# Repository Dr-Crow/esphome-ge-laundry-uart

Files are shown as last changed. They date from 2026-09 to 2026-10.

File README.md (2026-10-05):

# ESPHome GE Laundry UART

Local Home Assistant control and monitoring for compatible GE appliances through ESPHome and the appliance's GEA serial bus.

> [!WARNING]
> The appliance uses an 8P8C modular connector that looks like Ethernet, but it is **not Ethernet**. Do not connect it to network equipment.

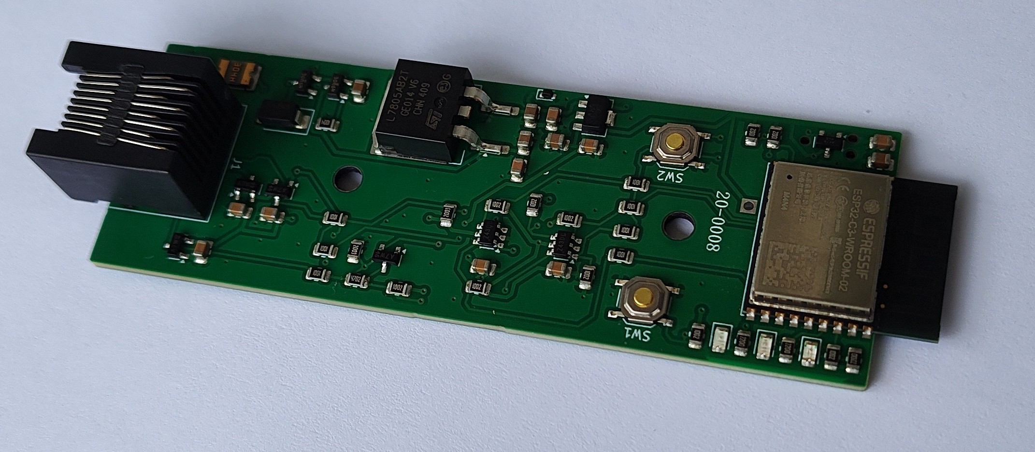
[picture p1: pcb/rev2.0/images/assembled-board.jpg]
Assembled Rev 2-era adapter


The project began as an effort to integrate a GE washer and dryer with Home Assistant. An ESP32 powered by the appliance communication port reports information such as remaining time and cycle completion through ESPHome. Early work involved researching the GEA2 and GEA3 protocols and the U+ Connect module; later, [GE Appliances](https://github.com/geappliances) and [FirstBuild](https://firstbuild.com/inventions/home-assistant-adapter/) published additional hardware and protocol information. The maintained ESPHome implementation now lives in [mguaylam/esphome-gea](https://github.com/mguaylam/esphome-gea), while this repository provides compatible hardware, reference configurations, manufacturing files, and enclosures.

## Getting started

### I already have a board

Follow the [firmware setup guide](firmware/README.md) to choose a GEA2 or GEA3 configuration, flash the board, connect it to Home Assistant, and check the status LEDs. The [Rev 2 enclosure](case/rev2/README.md) includes ready-to-print files.

### I want to review a new board

The selected development focus is the socketed C3/C6 Rev3C with both appliance inputs, automatic priority and rated protection. This integration includes all seven editable board revisions, eight firmware profiles, native validation and the [illustrated Rev3C ordering guide](pcb/rev3c/ORDERING.md). Start with the [current comparison and validation](docs/revision-comparison/README.md), [exact source handoff](docs/revision-comparison/HANDOFF.md) and [finish registry](docs/revision-comparison/FINISH-PLAN.md).

Fresh pinned KiCad 9.0.9 ERC/DRC and intended-rule checks pass for all seven revisions. The [Rev3C stencil correction](pcb/rev3c/STENCIL-REVIEW.md) removes unintended drill-marker openings. Native/CAM agreement is separate from supplier process, appliance power and physical qualification. The corrected Rev3C trio has refreshed October 5 quotes of $134.64 for five or $168.92 for ten assembled carriers, before shipping, tax and XIAO modules; Rev2.2's old $78.07 quote is historical.

Older boards and the complete change history are listed in the [PCB revision index](pcb/README.md). Hardware contributors should also read the [contribution guide](CONTRIBUTING.md).

For the proposed USB-C revisions, see the [board and enclosure comparison](docs/revision-comparison/README.md), including assembled-board estimates and views from several angles. The [project handoff](docs/revision-comparison/HANDOFF.md) records the development branches and remaining work.

## Related projects

- [GE Appliances organization](https://github.com/geappliances)
- [FirstBuild Home Assistant adapter](https://firstbuild.com/inventions/home-assistant-adapter/)
- [puddly/casserole](https://github.com/puddly/casserole)
- [GEMakers/green-bean](https://github.com/GEMakers/green-bean)
- [doitaljosh/gea-interface-board](https://github.com/doitaljosh/gea-interface-board)
- [doitaljosh/ge-appliances-re](https://github.com/doitaljosh/ge-appliances-re)
- [doitaljosh/geabus-documentation](https://github.com/doitaljosh/geabus-documentation)
- [simbaja/gehome](https://github.com/simbaja/gehome)
- [GE Appliances Home Assistant adapter](https://github.com/geappliances/home-assistant-adapter)
- [GE Appliances Home Assistant examples](https://github.com/geappliances/home-assistant-examples)
- [GE Appliances Home Assistant bridge](https://github.com/geappliances/home-assistant-bridge)

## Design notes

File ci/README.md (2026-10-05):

# Native validation and release gates

This integrated review covers all seven actual board folders (`rev1.0`, `rev2.0`,
`rev2.1`, `rev2.2`, `rev3a`, `rev3b`, `rev3c`) and all eight standalone firmware
profiles. It combines genuine final component histories in a new integration;
it does not reconstruct the omitted original integration commit or its ancestry.
The CI implementation builds on universal candidate
`0d3358af4e732a6e6f5e895d5942ebd1647c79e2`.

```sh
python3 -m unittest discover -s ci -p 'test_*.py'
python3 ci/validate.py inventory
python3 ci/validate.py inventory --revision firmware
python3 ci/validate.py hardware
python3 ci/validate.py manufacturing
python3 ci/validate.py rules
python3 ci/validate.py release
python3 ci/validate.py firmware
```

Use genuine KiCad **9.0.9**, its official pinned libraries and ESPHome
**2026.9.1**. CircleCI pins executable/container versions and registry manifest
digests. Reports and logs go to `ci-artifacts/` and remain available when checks
fail. No command flashes hardware, places orders or publishes a release.

## What each check establishes

- Inventory requires every actual revision directory in the manifest. It records
  native CAD, available factory-file hashes and the complete local source closure
  even when supplier assembly inputs are absent. Every declared firmware profile
  must exist, be unique and have a complete local YAML/include closure; private
  secrets are excluded. A regression also requires every standalone YAML profile
  to be declared; included package files are dependencies, not build targets.
- One canonical checkout-relative design identity includes native CAD/rules,
  project tables, child schematics, local symbol/footprint libraries and every
  referenced local STEP/WRL model. Native, CAM, placement and release checks bind
  to this same closure. Required dependencies must exist; edits or deletions
  invalidate previous evidence. Equal basenames in different folders remain
  distinct. Stock references and official library/model commits are pinned
  separately, without substituting arbitrary system files into source hashes.
- Hardware uses an isolated dependency copy so native project migration cannot
  rewrite committed source. ERC/DRC include all severities; DRC includes all-track
  errors and schematic parity. Every nonzero exit, including violation exit 5,
  fails. Missing tools/reports and infrastructure errors fail too. After both
  strict checks pass, the same isolated copy produces `review/schematic.pdf`
  (all sheets), `review/board-top.svg` (F.Cu, F.SilkS, Edge.Cuts) and
  `review/board-bottom-mirrored.svg` (B.Cu, B.SilkS, Edge.Cuts, mirrored).
  `review-exports.json` binds every fresh file's SHA-256 and byte count to the
  complete current source identity and the actual pinned native version. A
  nonzero export, missing/empty file, malformed SVG or wrong-kind/incomplete
  output fails as a review-export infrastructure/output problem even when
  ERC/DRC pass. Reruns remove older review outputs first. These are native 2D
  review views; they do not approve populated 3D geometry, mechanics or release.
  The flags follow the official [KiCad 9 CLI reference](https://docs.kicad.org/9.0/en/cli/cli.html).
- Manufacturing first requires the declared `fabrication_plot` policy to be
  exactly `{"drillshape": 0}` and the native board setting to be 0. Drill markers
  can create positive stencil apertures even when CAM perfectly matches source.
  The native regression regenerates source-matched Rev3C CAM with drillshape 1,
  confirms its unintended 0.35 mm circular paste apertures and successful parity,
  then requires the fabrication guard to reject it.
- Gerber/drill/job content must match native regeneration, removing only creation
  timestamps. CAM identity remains separate from missing supplier assembly data.
  BOM references, values, footprints and purchasing fields must match native
  schematic metadata. CPL coordinates, rotations and sides must match native
  placements or the specific committed, hash-matched centroid policy.
- Manufacturing also checks every supplier-BOM R/C/L reference against the
  independently reviewed primary catalog facts in `passive-catalog.json`.
  Nominal values, declared footprint package identities and available exact MPNs
  must agree; explicitly declared capacitor voltage/dielectric must match in both
  BOM fields/value text and native schematic fields/value text. Unknown passive
  codes fail and need an independently sourced catalog update. Regressions reject
  the legacy 220k/C17539 (200k) and 4K7/C17713 (47k) conflicts even when BOM and
  source agree. All five declared supplier BOMs are covered; the two legacy boards
  without current supplier BOMs retain their existing missing-input failures.
  The report binds the catalog hash. This check does not establish supplier stock,
  land-pattern compatibility, DC bias, transient or thermal qualification.
  Semiconductor and module identities remain outside this bounded passive check.
- The current centroid policies cover Rev2.1's legacy pad-bounds convention,
  Rev3A/Rev3B's typed manufacturer/module body datums and Rev3C's typed nominal
  J1 manufacturer body datum. Complete source closure, documentary hashes,
  native part/footprint identity, anchor, rotation, side and local/export geometry
  must match. Stale, missing, unknown or substituted evidence fails. Angles have
  no override. These are geometric conventions, not supplier process approval.
- Rules audit exactly the declared native net names, their explicit memberships
  and intended clearances. Exact sheet-leading slashes matter. Native KiCad 9
  patterns and Rev1's retained explicit legacy class `nets` are both supported;
  automatic/default class selection is not treated as explicit assignment.
  Rev3B/C's unused inherited USB patterns are retained in source; they are not
  claimed as live audited nets. Native DRC and this bounded audit remain separate.
- Firmware requires both `esphome config` and `esphome compile` for each profile,
  using synthetic credentials in a temporary copy. Results bind profile/include
  hashes. A compile requires a fresh binary; config-only, missing dependencies and
  network/tool failures stay red. The exact local ESPHome environment is
  unavailable. Hosted job 47 completed fresh config and compilation for all
  **eight profiles** at published source `2d5a42c`; the
  [hosted receipt](validation/hosted-2d5a42c/REVIEW.json) binds all 22 declared
  input hashes and records 24 factory/OTA/ELF outputs. Test credentials were
  synthetic; no device was flashed or functionally qualified.
- Release requires separate power, source and physical qualification evidence
  for every board: **all 21 gates remain explicitly blocked**. Passed evidence
  must be committed at HEAD, hash-matched, bound to the complete current source
  closure and match external pins. A native/CAM/firmware pass cannot waive gates.

## Explicit unresolved inputs and qualification

Rev1.0 and Rev2.0 now have restored editable historical CAD and current review CAM.
Their original archives remain separately declared as `historical_archive`.
Rev1's original supplier BOM/CPL are absent; Rev2's historical supplier tables and
rotations do not establish a current qualified assembly package. Their inventory
and assembly checks remain red while independently source-matched CAM can pass.
No purchasing data, original archive/source pairing or supplier orientation
approval is invented.

Legacy supply/protection/supervisor and exact module/buck/regulator identities,
supplier library pose/rotation, purchasing identities and physical qualification
remain open. Current Rev2.1/Rev2.2 source and factory files are the reviewed cleaned
packages; historical copies remain separate. Corrected native source does not
close the known Rev2.1 supervisor risk or establish appliance compatibility.

Rev3A/B/C retain the reviewed rated-switch circuits and current source packages.
Exact RJ45 suffix and other purchasing identities, whole-chain transient and
thermal behavior, loaded startup, source capacity, supplier process, antenna/RF,
assembly and enclosure qualification remain open. Rev3C has no default shared
C3/C6 case CAD and no completed physical qualification.

## Verification boundaries

The prior [validator/workflow receipt](validation/VALIDATOR-WORKFLOW-REVIEW.json)
is frozen evidence for the universal four-board/two-profile candidate's bytes and
its October 4 CircleCI schema validation. It does not certify this extended driver,
manifest or its fresh hosted execution. The integrated local review is recorded
separately after the exact final files are checked. CircleCI accepted the current
configuration through its schema validator on October 4; the
[schema receipt](validation/INTEGRATED-CIRCLECI-SCHEMA.json) binds the CLI and
configuration hashes. Hosted native, intended-rule, validator-test and firmware jobs succeeded on
`2d5a42c`. Inventory/manufacturing correctly fail on the two legacy supplier
packages, and all 21 release gates remain blocked. The
[hosted receipt](validation/hosted-2d5a42c/REVIEW.json) separates these results
from physical qualification and the earlier local review.

Do not turn failures green by ignoring native exit codes, lowering rules,
omitting intended coverage, inventing assembly data or removing gates. Add a real
source dependency or tool version deliberately and regenerate affected evidence.
Official references: [KiCad containers](https://www.kicad.org/download/docker/)
and [CircleCI CLI](https://circleci.com/docs/guides/toolkit/circleci-cli/).

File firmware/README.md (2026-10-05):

# Firmware profiles and board service

Choose the profile family for the actual board. [Shared profiles](shared-rev3c/README.md) cover socketed Rev3C C3/C6 and the compatible soldered Rev3B C3 interface; [classic Rev1 profiles](rev1-classic/README.md) cover its distinct ESP32 wiring. The two root reference configurations cover Rev2.x and the compatible Rev3A C3 interface. The [per-board coverage review](BOARD-COVERAGE.md) proves these mappings separately from compilation. All eight profiles compiled in hosted jobs [69 at11826a7](https://circleci.com/gh/Dr-Crow/esphome-ge-laundry-uart/69) and [81 at8744a29](https://circleci.com/gh/Dr-Crow/esphome-ge-laundry-uart/81). The committed detailed binary-hash receipt remains bound to earlier2d5a42c; it is not relabeled as a later build. Runtime/appliance behavior remains untested.

## Rev2.x reference setup

These examples use the maintained [ESPHome GEA component](https://github.com/mguaylam/esphome-gea) and are software references for the historical Rev 2.x interface. They do not establish board power or appliance qualification.

[Back to the project overview](../README.md) · [PCB Rev 2.2 reference](../pcb/rev2.2/README.md) · [Revision history](../pcb/README.md)

## Choose a configuration

| Configuration | Connection | Typical use |
| --- | --- | --- |
| [`gea2.yaml`](gea2.yaml) | GPIO5 TX and GPIO10 RX, inverted, 19,200 baud | Rev 2.x reference for GEA2 appliances. |
| [`gea3.yaml`](gea3.yaml) | GPIO21 TX and GPIO20 RX, non-inverted, 230,400 baud | Rev 2.x reference for GEA3 appliances. |

The appliance model determines whether it uses GEA2 or GEA3. Establish that protocol and its electrical interface for the exact appliance before selecting a profile. Do not connect an unqualified board to an appliance to try configurations.

## Prepare ESPHome

If ESPHome is not installed yet, start with the official [ESPHome installation guide](https://esphome.io/install/) and [getting-started guide](https://esphome.io/install/getting-started/).

1. Copy the matching YAML file into your ESPHome configuration directory.
2. Change the `name` and `upper_name` substitutions near the top of the file.
3. Add these values to the `secrets.yaml` file in the same directory:

```yaml
wifi_ssid: "..."
wifi_password: "..."
esp_home_ota_pw: "..."
```

You can use the ESPHome Device Builder or the command line. The examples are starting points, so appliance-specific entities may need to be added or changed.

## Reproduce the reference build

The reference profiles pin ESP-IDF **5.5.5** and the GEA component to commit
`283ff2b0dfe90a6d14a5417a23176d433be8a5b3`. CI uses ESPHome **2026.9.1** and
runs actual compilation for both profiles. To run those checks locally with the
same ESPHome version, use `python3 ci/validate.py firmware` from the repository
root. The driver uses temporary dummy credentials and never flashes a device.

These build checks establish software compilation only. Match the board and
appliance configuration and complete physical qualification before use.

## First flash

Rev 2.x boards do not have USB. Programming uses a **3.3 V logic** USB-to-UART adapter connected to the unpopulated J2 holes or J3 Tag-Connect pads. Keep the UART adapter's VCC/power lead disconnected; do not apply 5 V logic to RX/TX or the control pins.

J2 pin 1 and J3 pin 2 are the board's **+3V3 rail on the regulator output**, not approved programming-power inputs. Do not feed either contact from the UART adapter or an external 3.3 V supply. Driving a regulator output while its input is absent can reverse-feed the regulator and other board rails.

| J2 pin | Board signal | Connect to |
| --- | --- | --- |
| 1, square pad | +3V3 regulator output rail | Leave disconnected; UART adapter VCC stays disconnected |
| 2 | Ground | Adapter ground, once a reviewed board-power arrangement exists |
| 3 | Boot | Ground only while entering the bootloader |
| 4 | Board RX / GPIO20 | Adapter TX, 3.3 V logic |
| 5 | Board TX / GPIO21 | Adapter RX, 3.3 V logic |
| 6 | Enable | Optional reset control |

TX/RX in this table means the adapter/ESP perspective: the native Rev 2.x netlist places J2.4 on U2 IO20/RXD and J2.5 on U2 IO21/TXD. Historical net names and printed labels can use a different perspective; confirm the exact schematic and revision before wiring.

Use only a **single reviewed board-input supply and power/reset procedure** matched to that exact schematic, revision and fitted regulator/protection parts. No approved supply voltage range, source, current limit or bench procedure is established by this guide. Do not combine appliance power with a programmer supply, and do not connect to an appliance before electrical and physical qualification.

This corrects the output-rail power advice in the historical guide at public-main commit `bc0d524` and the original Rev 2-era instructions. It changes documentation only; the circuit and its open qualification gates remain unchanged.

After that power arrangement and the serial logic/interface have been reviewed:

1. Connect J2 Boot to Ground.
2. With Boot held low, follow the reviewed board-input power/reset procedure for this exact revision to enter the serial bootloader. Keep UART adapter VCC disconnected and leave the +3V3 service contacts disconnected from external power.
3. In ESPHome Device Builder, choose **Install** and select the serial adapter. With the command line, run:

   ```console
   esphome run your-config.yaml --device /dev/cu.your-usb-serial-device
   ```

4. When the upload finishes, disconnect Boot from Ground and restart using the same reviewed power/reset procedure.

Later updates can be installed over Wi-Fi from ESPHome Device Builder. From the command line, run the same `esphome run` command and choose the network device when prompted.

## Before connecting to an appliance

Complete electrical/source, startup/current, regulator/protection/thermal, serial-level and connector/enclosure qualification for the exact board and appliance first. The native checks and firmware builds do not supply that evidence. After qualification, disconnect the programming adapter before connecting the board to the appliance service port. This connector is not Ethernet.

With the supplied configurations, the green LED follows Wi-Fi connection and the yellow LED follows the GEA component's `is_bus_connected()` state, checked once per second. Yellow is a connected-state indicator, not a per-message activity indicator. The red LED is initialized off at boot and has no ongoing status assignment in these examples.

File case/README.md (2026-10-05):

# Enclosures

Enclosure files are grouped by the PCB family they were designed to fit.

[Back to the project overview](../README.md)

| Enclosure | Intended hardware | Status |
| --- | --- | --- |
| [Rev 2 enclosure](rev2/README.md) | Rev 2.x board outline | Existing printable design; Rev 2.2 fit still requires a physical check. |
| [Shared Rev3C review prototype](rev3c/README.md) | Socketed C3/C6 Rev3C | Editable all-printed source recovered; current component envelopes, actuator calibration, printing and physical fit remain unqualified. |

The editable CAD source, printable files, and documentation images are kept separately. The final check is printing the enclosure and test-fitting an assembled board.

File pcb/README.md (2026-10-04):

# PCB revisions

This directory keeps every board revision in a separate package so source files, manufacturing files, and review files do not get mixed between revisions.

[Back to the project overview](../README.md) · [PCB ordering guide](ORDERING.md)

> [!IMPORTANT]
> Every revision needs its own source, electrical, assembly and physical qualification before a new build. Rev2.2 retains unresolved regulator/current and protection limits; it is not a released fallback. Older packages remain for review and project history.

## What the folders mean

- `design/` contains the editable KiCad project. A `.pretty` directory under `footprints/` is a KiCad footprint library: it defines the exact copper pads, drill holes, silkscreen, and component outline used on the board. A project `fp-lib-table` maps the library name used by the board to that local directory so footprints resolve from a clean clone. A `models/` directory, when present, contains optional 3D component shapes.
- `manufacturing/` contains files sent to a PCB assembler. Gerbers describe copper, holes, solder mask, and silkscreen; the BOM lists components; the CPL lists component positions and rotations.
- `validation/` contains files used to review the design, such as schematic PDFs, board views, drill maps, and ERC/DRC reports.
- `images/` contains photographs and explanatory renders used by documentation. Images are not manufacturing inputs.

## Revision index

| Revision | Status | Available material |
| --- | --- | --- |
| [Rev 3C](rev3c/README.md) | Selected socketed C3/C6 prototype; qualification open | Rated dual-input source, four firmware profiles, corrected stencils, factory trio, partial component previews and illustrated ordering guide. |
| [Rev 3B](rev3b/README.md) | Rated soldered-C3 alternative; qualification open | Native source, matched factory package, typed placement evidence and partial C3 previews; exact module stock remains a gate. |
| [Rev 3A](rev3a/README.md) | Rated integrated-C3 alternative; qualification open | Native source, matched factory package, reviewed USB shell slots/lands and placement evidence; assembler solder/retention review remains open. |
| [Rev 2.2](rev2.2/README.md) | Historical candidate; qualification open | Corrected KiCad source, matched factory package, and validation exports. |
| [Rev 2.1](rev2.1/README.md) | Historical; superseded; qualification open | Corrected KiCad source, source-bound supplier files, drill maps and explicit placement conventions. |
| [Rev 2.0](rev2.0/README.md) | Historical; qualification open | Restored editable source, regenerated current CAM and preserved original PCBA archive; current supplier BOM/CPL and rotations remain unqualified. |
| [Rev 1.0](rev1.0/README.md) | Historical; qualification open | Restored editable source, regenerated current CAM and preserved original Gerber archive; original purchasing/module/buck identity remains missing. |

> [!IMPORTANT]
> Historical RX/TX labels use an endpoint perspective; verify the exact ESP GPIO-to-adapter direction rather than inferring a hardware swap. The U1 supervisor has reported boot-loop issues on Rev2.1. Historical manufacturing packages are not qualified corrected sources.

Rev 2.2 addresses those known board-file problems but is not proven until assembled boards pass electrical, appliance, and enclosure testing. Keep the three matched files together for review; qualification and exact supplier process approval are still required before ordering.

All seven revisions have fresh full-severity native ERC/DRC and intended-rule checks with no findings. Source/CAM parity passes for all seven; complete source-bound BOM/CPL checks pass Rev2.1/2.2/3A/3B/3C. Rev1/Rev2's missing current supplier inputs remain explicit CI failures. All release gates remain open. See [validation](../docs/revision-comparison/VALIDATION.md) and the [finish plan](../docs/revision-comparison/FINISH-PLAN.md).

## Historical revisions

- Rev 0.1 had unconnected grounds discovered after ordering.
- Rev 0.2 corrected the grounds but needed a diode orientation bodge and resistor changes.
- Rev 0.3 added test points, an LED, a push button, and protection diodes; three boards were tested.
- Rev 1.0 added configurable resistors for inverted GEA2 serial signaling.
- Rev 2.0 introduced an assembly-oriented ESP32-C3 design.
- Rev 2.1 updated that design and migrated its source to KiCad 9.

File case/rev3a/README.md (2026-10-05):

# Rev3A enclosure review

The editable Rev3A enclosure and optional captive-button source remain preserved at [original source a5a9fac](https://github.com/Dr-Crow/esphome-ge-laundry-uart/tree/a5a9fac87cbcb59d337a1fb8d3084ad18867a3e6/case/rev3a). Their physical geometry is unchanged. The [current A/B source review](review/REV3AB-ENCLOSURE-SOURCE-REVIEW.md) binds their interfaces to rated-board checkpoint bf5c231, with exact recovery and geometry receipts. This companion is a review prototype, not a physically qualified case.

## Correct USB opening dimensions

J4 is at carrier (72, 36.325), opening toward +Y. The source cutter spans **X64.5–79.5, Y39–46 and Z2–6.4 mm**. Its outward-facing X/Z opening is **15 mm wide × 4.4 mm high**; **7 mm is the cutter depth through Y**. The closed lid does not enlarge that opening. The original guide's “15 × 7 mm cable window” conflated these axes; use the corrected facing dimensions here.

The selected connector is SHOU HAN TYPE-C 16PIN 2MD(073)/C2765186. Exact mating-axis Z above the assembled 1.6 mm PCB, shell seating and the chosen seated plug remain unresolved. The retained locally named STEP internally identifies a six-pin model, so its height is not exact sixteen-pin mating evidence. The [documentation-only source patch](review/rev3a-usb-documentation-only.patch) records the correction; no opening resize is adopted from that generic model.

## Current applicability and limits

The carrier is **88.7 × 40 × 1.6 mm**. Mounting holes, J1/J2/J4, WROOM, switches and LEDs retain the source-case anchors. Default base/lid STEP/STL readback passes under the recorded pinned CAD environment. Current STPS140Z, TPS1H200A and fuse package screens clear the roofs at nominal seating; those are dimensional screens, not thermal or complete populated-assembly approval.

J1's exact full suffix, body-seat/tail datum, solder protrusion and cable/latch sweep remain to be authenticated. A conditional 0.15 mm tail/floor conflict depends on the retained 3 mm tail datum being measured from PCB top; live drawing retrieval did not reverify that assumption, so no pocket resize is adopted. J4 solder delivery/inspection/retention, switch make/force/overtravel, printing/fatigue, light visibility and RF/thermal behavior remain open.

J2 uses a programmer with 3.3 V logic; **leave UART VCC disconnected** and use one reviewed input supply. The enclosure does not qualify simultaneous USB/appliance power. Match the actual populated board and all qualified dimensions before choosing or printing a production case. Orders and powered testing require their separate review.

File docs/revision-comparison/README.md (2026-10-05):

# Board and enclosure comparison

Latest October 5 pre-order analysis and committed fixes: [all-revision review](preorder-2026-10-05/README.md). The current Rev3 refinement uses STPS140Z input OR diodes across A/B/C and maximum-body socket/case screens. Fresh current-ST C quotes are $135.81/five or $171.20/ten; the older tables and galleries below retain their historical source boundaries.

[Project overview](../../README.md) · [Current validation](VALIDATION.md) · [Pricing](PRICING.md) · [Finish plan](FINISH-PLAN.md) · [Source handoff](HANDOFF.md) · [C3/C6 and Matter](C6-MATTER.md)

Updated October 4, 2026 after source restoration and fresh seven-revision native/CAM checks. The user selected the shared Rev3C design with two **40 V-rated TPS1H200A switches**, both GE power inputs and automatic PIN1 priority. Current selected source is `b87d3e8`, adding the reviewed stencil correction to restored `5542734`; its BOM/CPL remain placement-corrected `b53cfca`, while its Gerber ZIP is regenerated. The original electrical protection source is `7bb455f`. Selection does not establish a 40 V carrier rating, appliance compatibility or manufacturing readiness.

C3 is the first target, with C6 interface and firmware flexibility retained. Rev3A/B backports are digitally reviewed at 97/85 fitted references; Rev3A rated protection, exact connector lands and zero-warning schematic normalization are independently reviewed and staged; all seven revisions now have zero native findings. Current-main-based per-revision candidates are staged locally. Older revisions retain their distinct architectures and review gates. No revision has physical qualification, and older boards are not established safe fallbacks.

## Architecture and current role

| Revision | Processor and service | Power architecture | Current role |
| --- | --- | --- | --- |
| Rev1.0 | Generic 38-pin classic ESP32 interface; original nodemcu-32s target | PIN1 only; external buck through J1 | Restored historical CAD and two new classic profiles; exact purchased module and external supply unknown |
| Rev2.0 | ESP32-C3-WROOM-02; UART programmer | Manual dual-input selector, linear 5 V and 3V3 regulators | Restored source; legacy protection, regulator and physical gates remain |
| Rev2.1 / Rev2.2 | ESP32-C3-WROOM-02; UART programmer | Manual dual-input selector, linear regulators | Native cleanup passes; 60 / 59 fitted references; source-specific placement review remains |
| Rev3A | Integrated C3 and built-in antenna; carrier USB-C/recovery controls | Automatic dual input and buck; separate USB/appliance paths | Rated backport and zero-finding native checks complete;97 refs, exact current quote; source/process/physical gates open |
| Rev3B | Soldered XIAO C3; module USB-C/external antenna | Automatic dual input and buck | Rated protection passes native/manufacturing/intended-rule checks ; 85 fitted refs; soldered C3 sourcing/install and physical gates open |
| Selected Rev3C | Socketed pre-headered XIAO C3/C6; module USB/BOOT/RESET | Both GE inputs, automatic PIN1 priority, rated switches and buck | Selected development source; 83 fitted carrier references; four shared C3/C6 firmware builds |

Rev3B/C require one physical power source at a time because the module's side-header VBUS connects to USB VBUS. Disconnect appliance power before powered USB. Rev3A's separate isolation paths still require bench verification. UART programmer VCC remains disconnected. Selection of C6 does not remove these power-path limits.

## Historical pre-ST quote comparison

USD, complete PCB plus Economic top-side assembly, with all carriers assembled. The selected quote refreshed October 5 at 02:47 UTC uses the current stencil-corrected trio from integration `2d5a42c`, including the selected exact parts, RJ45 and female sockets. All 83 references/34 parts matched without shortages or substitutions; placement and stencil/process review remain open. Shipping, tax, separately purchased XIAO modules/headers, installation, programming, tests and cases are excluded.

| Matched Rev3C source | Fitted references | Five carriers | Ten carriers |
| --- | ---: | ---: | ---: |
| Historical pre-ST corrected trio, integration `2d5a42c` | 83 | **$134.64** | **$168.92** |
| Historical clamp-sourced baseline `ca1fdb1` | 80 | $130.39 | $160.37 |
| Difference from historical baseline | +3 | **$4.25** | **$8.55** |

The premium is about $0.85 per carrier. These are quote observations, not an order or delivered cost. Older architecture prices and module snapshots are clearly separated in [PRICING.md](PRICING.md). Current A includes its processor at $178.90/5 or $227.86/10; B remains stock-blocked. The selected source contains the illustrated `pcb/rev3c/ORDERING.md` and matching relative assets; use that guide only with its exact three-file package.

## Current source-bound C3/C6 package previews

These October 4 previews accompany source `5542734`; the later plot-only correction `b87d3e8` preserves their board/component geometry. Official Seeed C3 v1.3/C6 v1.0 PCB geometry and licensed generic packages replace the earlier module block. The bare C3/C6 SoC packages are dimension-checked5 ×5 ×0.85 mm nominal with reviewed pin 1 orientation. Complete manufacturer assembly CAD, button/regulator exact heights, header seating and physical case fit remain unverified. The earlier galleries below are retained historical views.

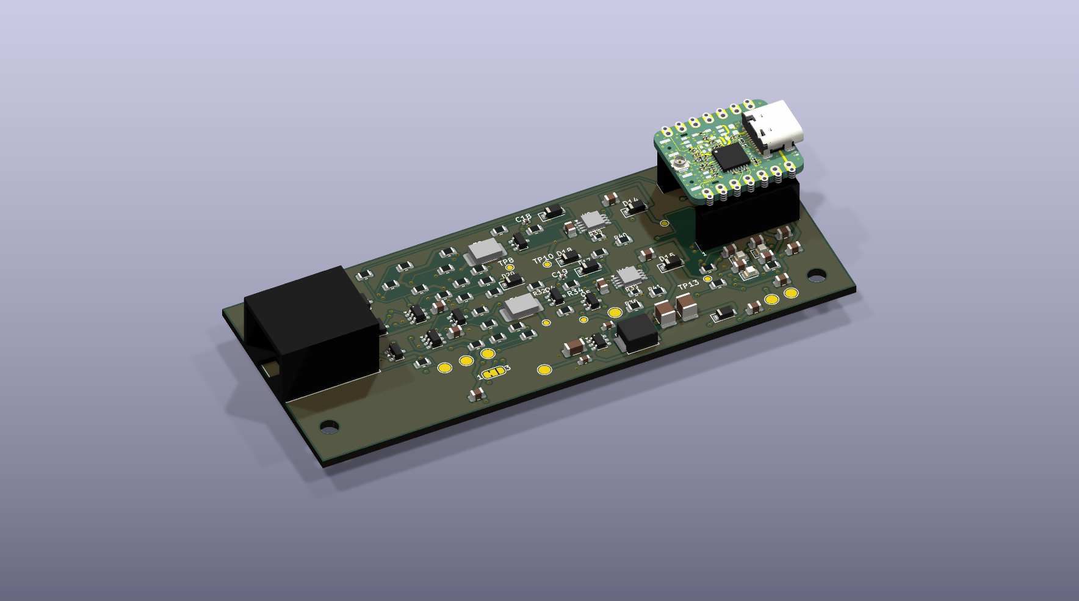
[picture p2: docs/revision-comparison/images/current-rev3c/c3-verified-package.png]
Current C3 partial package preview


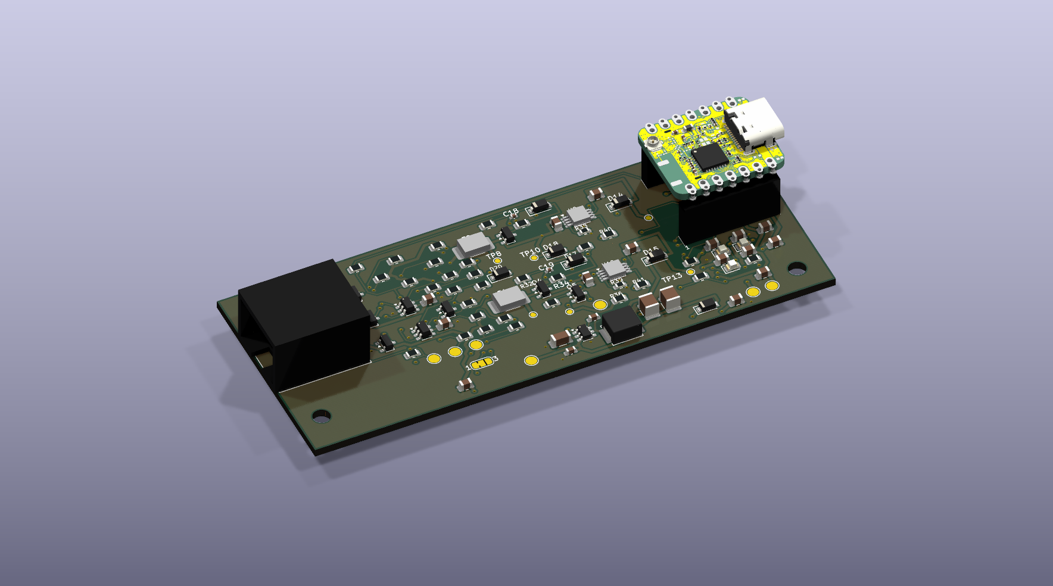
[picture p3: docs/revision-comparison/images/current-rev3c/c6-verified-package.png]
Current C6 partial package preview


The carrier PCB/schematic/manufacturing/firmware bytes are unchanged by these visual additions. Model source/provenance and its exact-source preservation receipts live in the selected candidate's `pcb/rev3c/MODEL-ACCURACY.md` and `validation/`. Module antenna/pigtail, exact buttons and mating geometry are not qualified by these views.

### Current alternative board previews

These are source-bound CAD previews of the reviewed alternatives, not manufactured boards. A preserves its integrated C3 architecture; B uses the partial native-registered C3 v1.3 model with unmeasured solder seating. Actual package/process/case/RF/thermal fit remains unqualified.

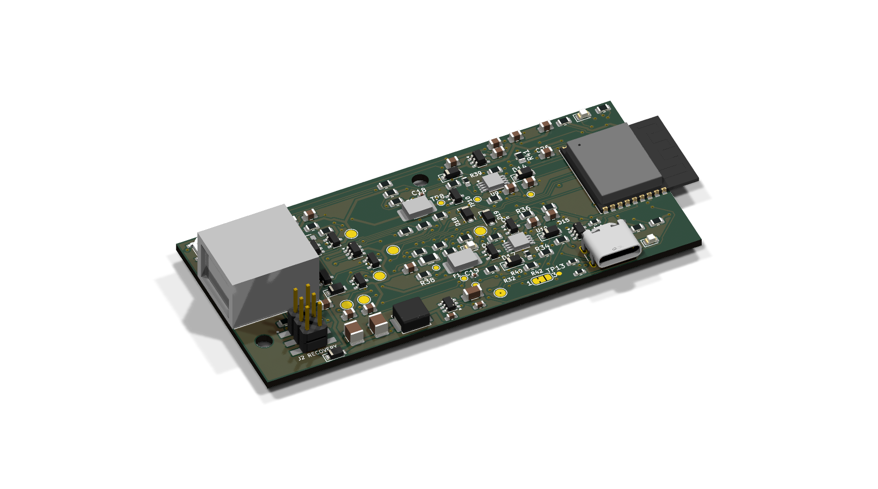
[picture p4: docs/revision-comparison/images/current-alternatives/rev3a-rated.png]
Current rated Rev3A preview


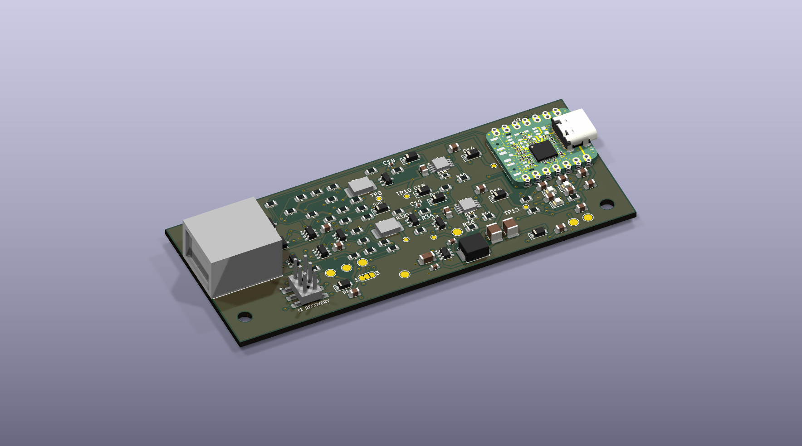
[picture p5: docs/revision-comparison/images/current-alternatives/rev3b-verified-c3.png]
Current rated Rev3B partial C3 preview


## How to read the historical images

These are historical CAD previews, not photographs of manufactured boards or views of the selected source. They show
the populated-board layout and case geometry from several angles. Common
parts use KiCad package models; the RJ45 body and XIAO module use simplified
clearance models. The XIAO shield outline is approximate, and the antenna
cable and flat antenna are omitted. Rev2.2's fuse bodies use an 1812-package
stand-in whose exact height is unverified. Colors are illustrative.

These galleries are the published October 2 source views. New cleanup packages
carry their own matched exports; do not pair old galleries with changed factory
files. The images help compare layouts but do not establish connector fit, socket
retention, thermal performance or RF reception. Rev2.2 and Rev3A show base
and lid separately. Rev3B/C include assembly previews and exploded views;
the exploded lid offset is for presentation.

### Rev2.2 and the existing Rev2 case

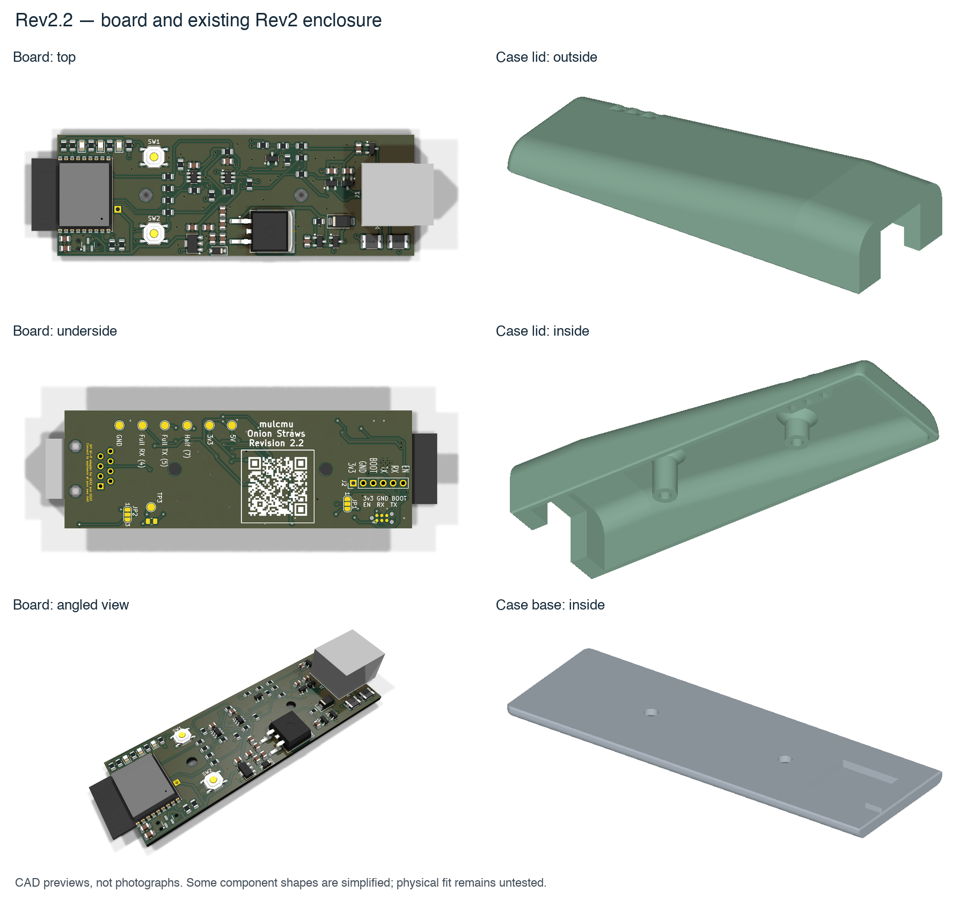
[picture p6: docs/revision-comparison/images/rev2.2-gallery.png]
Rev2.2 board and Rev2 case, multiple views


Board: [top](images/rev2.2/board-top.png) · [bottom](images/rev2.2/board-bottom.png) · [angled](images/rev2.2/board-oblique.png) · [side](images/rev2.2/board-side.png).

Case: [base inside](images/rev2.2/case-base-inside.png) · [base side](images/rev2.2/case-base-side.png) · [lid outside](images/rev2.2/case-lid-outside.png) · [lid inside](images/rev2.2/case-lid-inside.png).

Source: [Rev2.2 PCB](https://github.com/Dr-Crow/esphome-ge-laundry-uart/tree/bc0d52495bd97ed1504bd0ca0775e47feb01a648/pcb/rev2.2) · [Rev2 case](https://github.com/Dr-Crow/esphome-ge-laundry-uart/tree/bc0d52495bd97ed1504bd0ca0775e47feb01a648/case/rev2).

### Rev3A

Built-in antenna, separate USB-C connector, BOOT/RESET buttons and recovery
header. The gallery shows the standard tool-access lid; a separate optional
finger-button lid is available in the source branch.

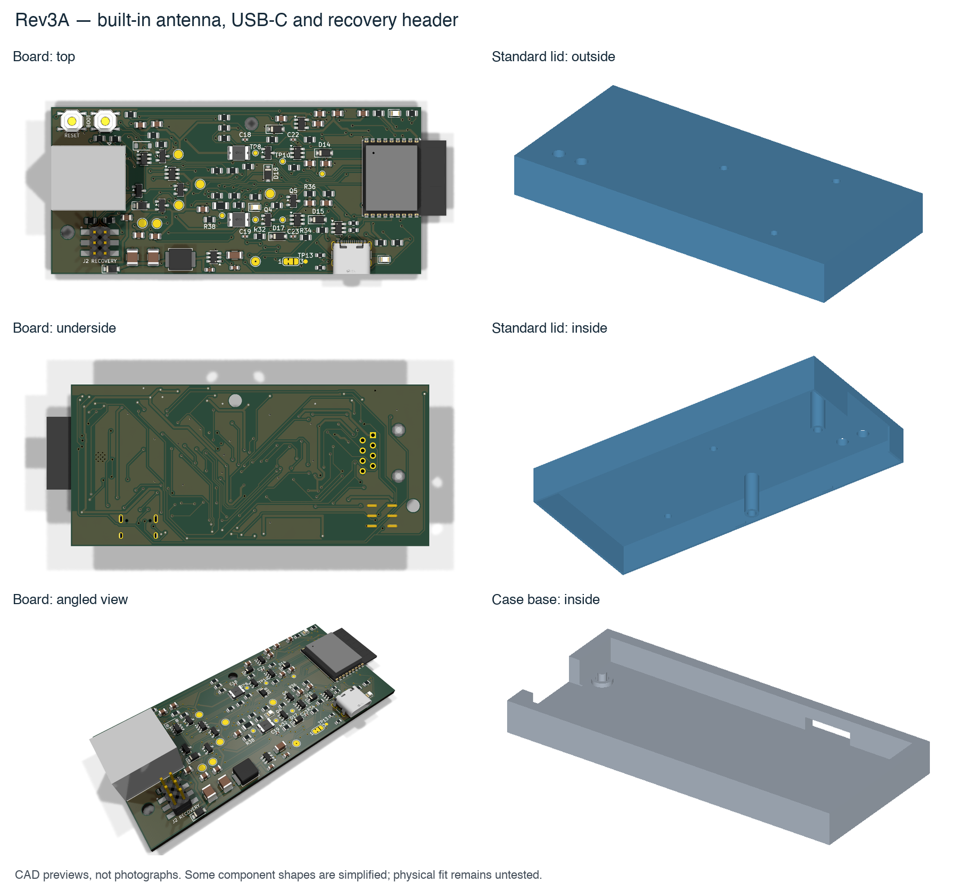
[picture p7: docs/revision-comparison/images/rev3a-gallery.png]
Rev3A board and standard case, multiple views


Board: [top](images/rev3a/board-top.png) · [bottom](images/rev3a/board-bottom.png) · [angled](images/rev3a/board-oblique.png) · [side](images/rev3a/board-side.png).

Case: [base inside](images/rev3a/case-base-inside.png) · [base side](images/rev3a/case-base-side.png) · [lid outside](images/rev3a/case-lid-outside.png) · [lid inside](images/rev3a/case-lid-inside.png).

Source: [Rev3A PCB](https://github.com/Dr-Crow/esphome-ge-laundry-uart/tree/a5a9fac87cbcb59d337a1fb8d3084ad18867a3e6/pcb/rev3a) · [Rev3A case and optional button lid](https://github.com/Dr-Crow/esphome-ge-laundry-uart/tree/a5a9fac87cbcb59d337a1fb8d3084ad18867a3e6/case/rev3a).

### Rev3B

XIAO soldered to the carrier. Its module is lower than Rev3C's removable
version. BOOT and RESET are on the XIAO itself; J2 remains inside the case.

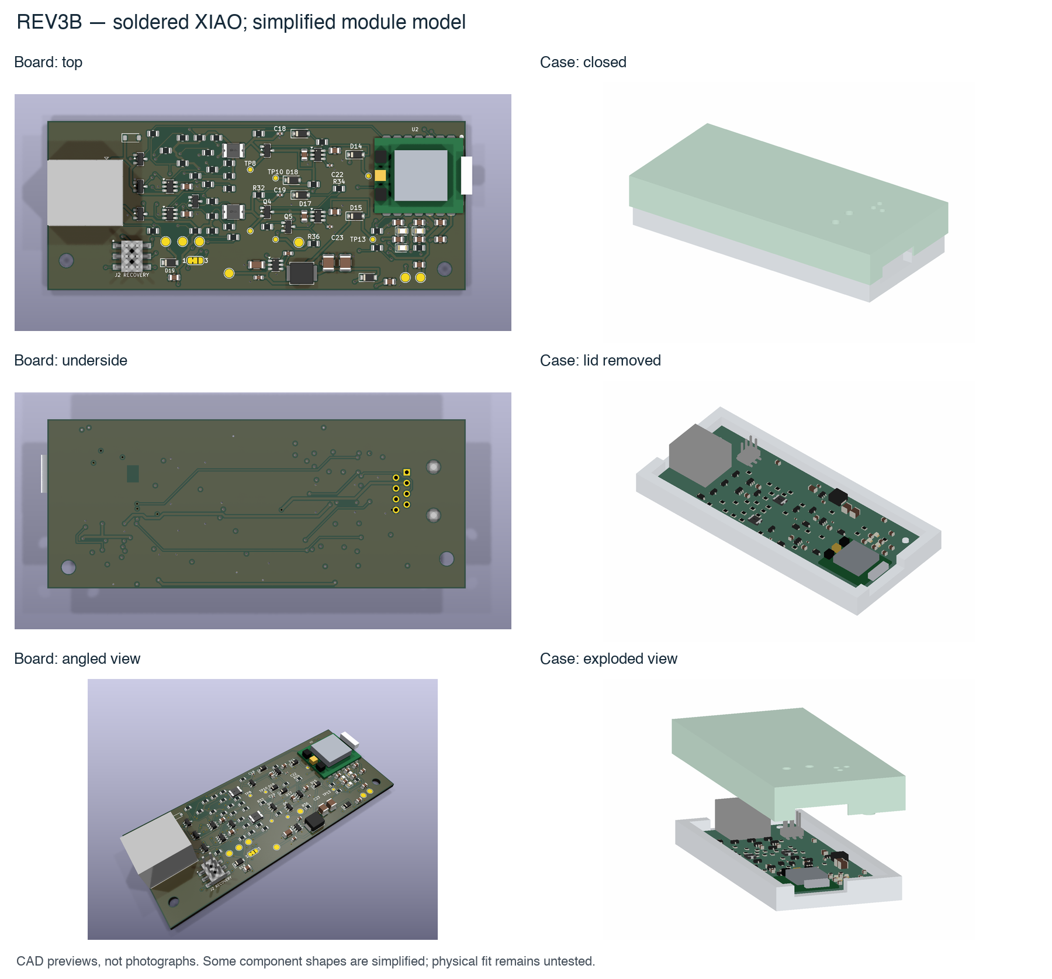
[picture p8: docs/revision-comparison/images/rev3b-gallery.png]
Rev3B board and case, multiple views


Board: [top](images/rev3b/board-top.png) · [bottom](images/rev3b/board-bottom.png) · [angled](images/rev3b/board-oblique.png) · [side](images/rev3b/board-side.png).

Case: [closed](images/rev3b/case-closed.png) · [side](images/rev3b/case-side.png) · [lid removed](images/rev3b/case-open.png) · [exploded](images/rev3b/case-exploded.png).

Source: [Rev3B PCB](https://github.com/Dr-Crow/esphome-ge-laundry-uart/tree/c5db989810663caa18226a091bfb105ad26fb00e/pcb/rev3b) · [Rev3B case](https://github.com/Dr-Crow/esphome-ge-laundry-uart/tree/c5db989810663caa18226a091bfb105ad26fb00e/case/rev3b).

### Public C3-only Rev3C baseline and legacy case

The pre-headered XIAO plugs into factory-installed female sockets. This
requires a taller case but permits replacing the module without soldering.
The case shown below is **C3-only legacy**, not a default shared C3/C6 enclosure.
The separately explored five-piece common enclosure remains an unqualified concept;
its exact final CAD is unavailable and must be restored before source and fit review. C6 buttons, antenna access,
module retention and physical fit require their own checks.

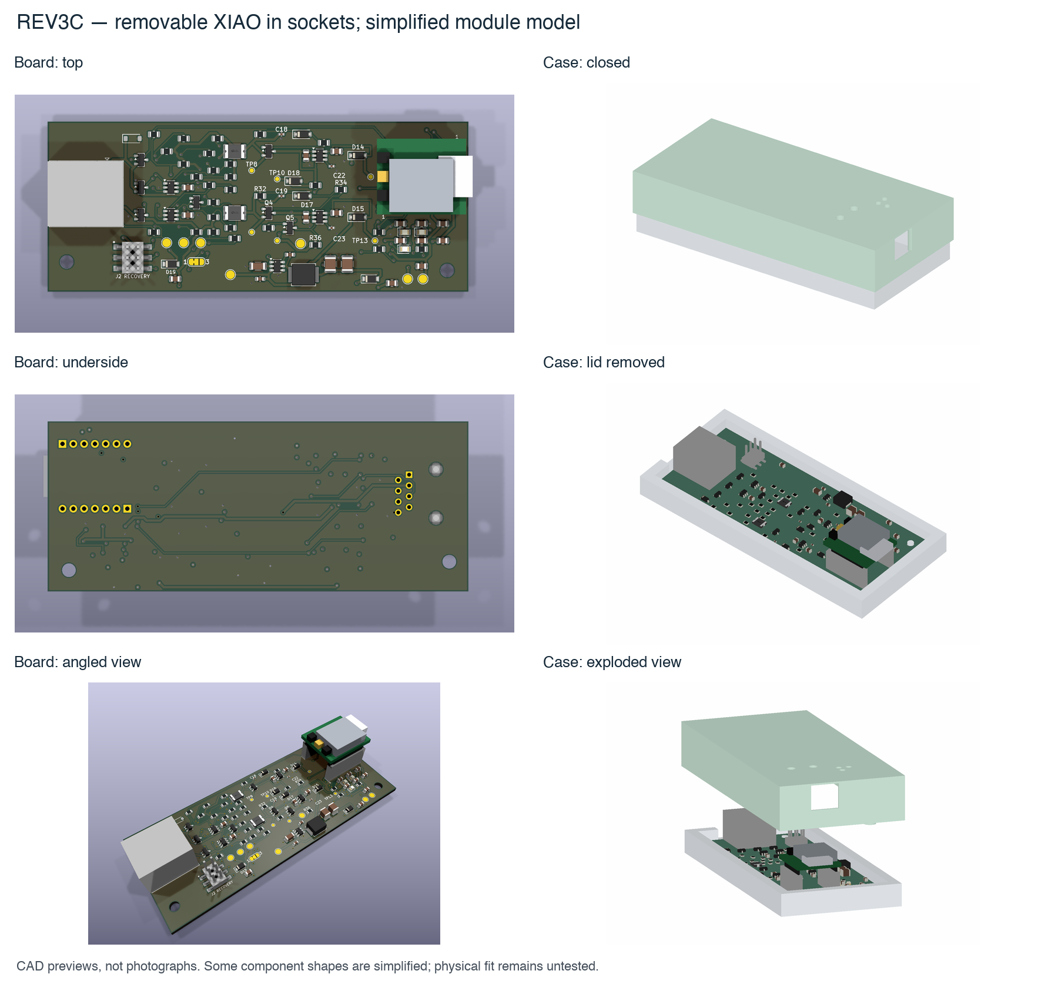
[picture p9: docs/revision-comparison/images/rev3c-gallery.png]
Rev3C board and case, multiple views


Board: [top](images/rev3c/board-top.png) · [bottom](images/rev3c/board-bottom.png) · [angled](images/rev3c/board-oblique.png) · [side](images/rev3c/board-side.png).

Case: [closed](images/rev3c/case-closed.png) · [side](images/rev3c/case-side.png) · [lid removed](images/rev3c/case-open.png) · [exploded](images/rev3c/case-exploded.png).

Source: [Rev3C PCB](https://github.com/Dr-Crow/esphome-ge-laundry-uart/tree/38d94d3dc7c41692e3c41710ec33b9f6e0c38b3e/pcb/rev3c) · [Rev3C case](https://github.com/Dr-Crow/esphome-ge-laundry-uart/tree/38d94d3dc7c41692e3c41710ec33b9f6e0c38b3e/case/rev3c).

## Package scope

This branch updates comparison and finish-plan documentation only. Its historical galleries are retained with their original public-source links. Current native results and exact unpublished heads are in [VALIDATION.md](VALIDATION.md) and [HANDOFF.md](HANDOFF.md); the remaining work is tracked in [FINISH-PLAN.md](FINISH-PLAN.md).

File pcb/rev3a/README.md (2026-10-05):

# Revision 3A PCB

D14/D15 now use the reviewed 1 A STPS140Z input OR diode; numbered nets and board routing are retained. [Current part-repair evidence](validation/INPUT-DIODE-REPAIR.md) distinguishes this new source from earlier validation and quote snapshots. Exact new-source checks and supplier matching remain required.

The current branch backports the selected rated protection circuit and adds the
recommended CHIP_EN capacitor to the integrated Rev3A architecture. See
[RATED-PROTECTION.md](RATED-PROTECTION.md) and
[POWER-QUALIFICATION.md](POWER-QUALIFICATION.md). **Native source checks and refreshed exports are paired in the
[current source manifest](validation/rated-protection-manifest.json); electrical,
supplier/process and physical qualification gates remain open.**

Revision 3A is an unqualified prototype ESP32-C3 adapter for the low-voltage
GEA serial bus used by compatible GE appliances. Its J1 8P8C connector is not
Ethernet. It retains the ESP32-C3-WROOM-02 from Revision 2.x and adds native
USB-C, automatic appliance-power selection, a switching 5 V supply, a stronger
3.3 V rail, separate RESET and BOOT controls, and a permanent recovery header.

> [!WARNING]
> No assembled Rev3A board has completed electrical or appliance testing. Do
> not connect an unqualified board to an appliance. Follow the complete
> [bench bring-up procedure](#prototype-bring-up) and [release gates](#release-and-appliance-connection-gates).

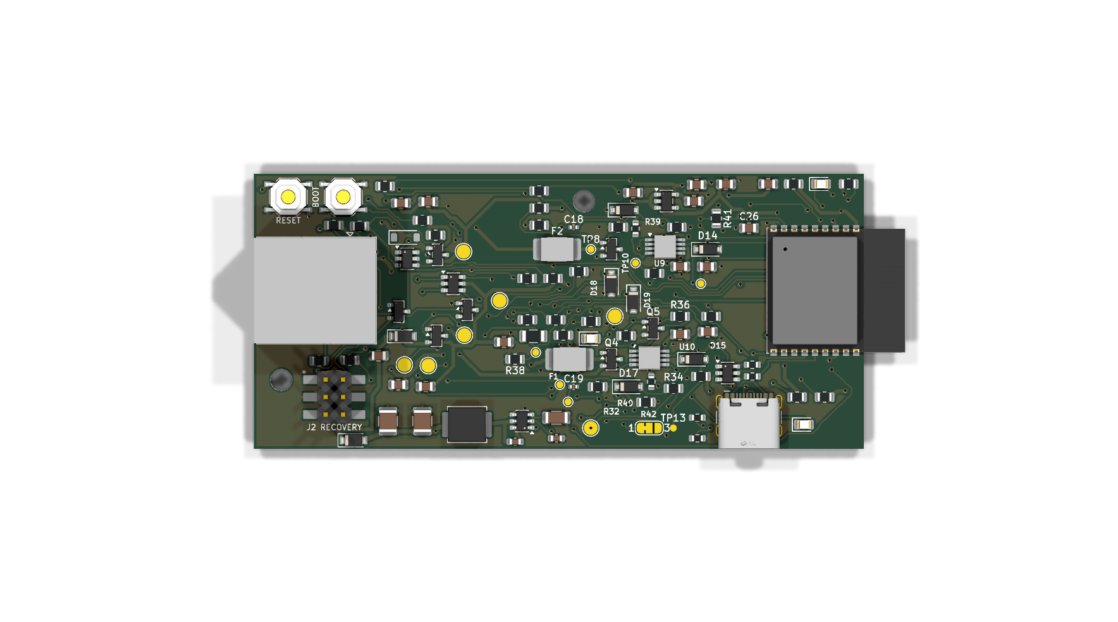
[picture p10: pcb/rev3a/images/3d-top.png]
Revision 3A populated-board render


## Navigation

- [What changed](#what-changed-from-revision-22)
- [Board map and normal use](#board-map-and-normal-use)
- [Power architecture and design rationale](#power-architecture-and-design-rationale)
- [Engineering and manufacturing status](#engineering-and-manufacturing-status)
- [Prototype bring-up](#prototype-bring-up)
- [Release and appliance-connection gates](#release-and-appliance-connection-gates)
- [Package map](#package-map)

## What changed from Revision 2.2

| Area | Revision 2.2 | Revision 3A |
| --- | --- | --- |
| ESP32 | ESP32-C3-WROOM-02 | Same module and built-in antenna |
| Programming | External programming connection | USB-C native USB plus J2 recovery header |
| Appliance power | Manual JP2 selection of pin 1 / pin 3 | Automatic pin 1 / pin 3 selection with pin-1 priority |
| 5 V supply | L7805 linear regulator | AP63205 switching regulator |
| 3.3 V supply | AP2205, 200 mA | AP2112K, up to 600 mA |
| USB and appliance power | Not intended for simultaneous use | Diode-isolated paths, pending prototype verification |
| Board | 88.7 x 30.1 mm, two layers | 88.7 x 40.0 mm, four layers |

## Board map and normal use

The appliance connector is on the left, USB-C is along the lower edge, and the
ESP32 antenna overhangs the right edge. Keep at least 15 mm beyond that edge
clear of metal, wiring, fasteners, and enclosure ribs.

| Marking | Function | Normal use |
| --- | --- | --- |
| `J1` | Appliance 8P8C connector | Power and GEA serial bus only after qualification |
| `J4` | USB-C | Normal flashing, logging, and bench power |
| `J2 RECOVERY` | 2-by-3 recovery header | Backup UART flashing with 3.3 V logic and enclosure open |
| `SW1 RESET` | Reset button | Restart the ESP32-C3 |
| `SW2 BOOT` | Boot-mode button | Hold during reset for ROM downloader |
| `D4` green | Wi-Fi status | Firmware-controlled Wi-Fi-connected indication |
| `D5` red | Diagnostic | User-controlled diagnostic indication |
| `D6` yellow | GEA status | Firmware-controlled appliance-bus indication |

### Normal flashing

Leave J1 disconnected for initial bench work. Connect J4 with a USB-C data
cable and flash over native USB. If automatic download mode does not start,
hold `SW2 BOOT`, tap and release `SW1 RESET`, then release BOOT after the
downloader starts.

### Recovery flashing

J2 is a backup for an unavailable USB data path. Use only a 3.3 V logic
USB-to-UART adapter and female Dupont leads: never use RS-232 or 5 V logic.
Leave adapter VCC and J2 pin 1 disconnected; never inject the regulator-output
`+3V3` rail. Power the board from one reviewed input after its qualification
procedure.
The matching enclosure keeps J2 inside the case; remove the lid before attaching
leads and disconnect them before closing the enclosure or connecting J1.

## Power architecture and design rationale

No user jumper is required. Each appliance input has its own resettable fuse,
CJ3407 PMOS reverse-current blocking stage, and TPS1H200A controlled high-side switch.
The switched outputs feed `V_INPUT` through Schottky diodes, while a transistor
network gives pin 1 priority when both inputs are present. USB-C VBUS is fused
and diode-isolated before joining the 5 V rail:

```text
J1 pin 1 -> fuse -> reverse-current block -> load switch -> diode --+
                                                                    +-> V_INPUT
J1 pin 3 -> fuse -> reverse-current block -> load switch -> diode --+
```

`V_INPUT` then feeds the buck regulator, and USB joins the same `+5V` rail
through its own diode:

```text
V_INPUT -> AP63205 -> BUCK_5V -> D11 --+
                                       +-> +5V
USB-C VBUS -> fuse -> D10 -------------+
```

`+5V` is a nominal name, not a guaranteed level. Whichever source is active,
the rail sits below that source by the forward drop of its isolation diode
(`D11` for the appliance/AP63205 path, `D10` for USB), and that drop depends on
load current and temperature. No specific voltage range is claimed here; it
has not been measured.

Q3/Q4 and the CJ3407 stages are intended to limit reverse current and source-
to-source backfeed. They are not claimed to protect against a physically
reversed connector supply. All source combinations and handoffs require
current-limited bench supplies and an independently checked J1 breakout.

The FirstBuild schematic labels its downstream `V_INPUT` rail as 4.3–15 V.
That is neither a measured Rev3A appliance-input range nor a design guarantee;
the AP63205 cannot regulate 5 V from a 4.3 V input. Minimum appliance voltage,
path drop, regulator headroom, and transient environment must be measured.

### Transient protection

D18 and D19 are populated unidirectional SUNMATE SMF16A TVS parts (`C399290`)
from `PIN1_PROTECTED` and `PIN3_PROTECTED` to ground. Both are upstream of the
switch current limits. The reviewed protection backport uses 33 V Littelfuse
PPTCs, corrected PMOS source/drain connections, source-referenced nominal 12 V
MCC gate clamps, and 40 V TPS1H200A switches. It retains the original source
priority and all downstream regulators.

The SMF16A 26 V clamp is specified for one stated pulse/current/temperature
condition. It does not establish an appliance transient envelope or a 40 V
rating for the carrier. PMOS differential voltage, low-current/hot gate stress,
PPTC fault voltage, converter limits and transient energy remain separate gates.
Validate both protected nodes under reviewed fixtures and conditions; no
physical transient tests have run. See the complete
[protection limits](RATED-PROTECTION.md#source-referenced-gate-and-whole-chain-bounds).

### USB, regulators, and layout rationale

The AP63205 replaces the Rev2 linear 5 V stage to reduce heat and improve
efficiency. AP2112K-3.3 replaces the 200 mA AP2205 for more Wi-Fi peak-current
headroom. Regulator temperature, startup, and rail stability remain hardware
tests.

USB-C uses the ESP32-C3 native USB interface with USBLC6-2SC6 ESD protection.
R38 (220 kohm to ground) discharges `USB_VBUS`; no controlled-impedance claim
is made. The four-layer stack was chosen because a two-layer trial fragmented
the ground return and left USB without a defensible continuous reference:

| Layer | Function |
| --- | --- |
| `F.Cu` | Components, local power, and signal routing |
| `In1.Cu` | Ground reference with documented retry-control slot and via antipads |
| `In2.Cu` | Ground plane with local power/control routing |
| `B.Cu` | Signal routing and short USB/feedback transitions |

The D18 branch uses two standard through-vias and a short `In2.Cu` trace.
Native USB retains its original signal routing. Actual reference-plane refill and
return-path changes are documented in the current protection review and require
physical qualification. All fitted components are top-side; new routed vias use
0.30/0.40 mm drills and the ESP32 thermal pad uses a
0.30 mm minimum plated drill. There are no blind/buried or filled vias,
controlled-depth drilling, via-in-pad requirements, or bottom-side placements.

## Engineering and manufacturing status

- The current schematic has zero KiCad 9.0.9 ERC errors or warnings. The
  [schematic-only ERC cleanup](validation/erc-normalization/README.md) moves eight
  USB symbols and attached markers onto the unchanged 25 mil connection grid,
  and explicitly wires the unchanged U4 VCC pins to +5V. All 301 current pin
  memberships remain identical. The earlier namespace recovery removed 44
  symbol-mismatch warnings. Existing rated-protection reports/manifests and
  package schematic PDF still describe the pre-cleanup snapshot pending refresh.
- Full native all-severity/all-track/parity DRC has zero errors, warnings and
  unconnected items. Exact frozen embedded footprint recovery clears five library
  mismatch warnings without pad, model, graphic, placement or attribute changes.
- Matched native BOM has 97 fitted references, 49 exact-value/full-footprint rows
  and 42 purchasing tuples. The supplier CPL applies explicit J1/U2 body-centroid
  transforms; actual supplier zero, rotation and assembly-process acceptance remain open.
- Original global rules, Power 0.25 mm and Switching 0.30 mm remain. The TI
  0.20 mm exception applies only to adjacent pads within the same U9 or U10
  footprint. All tracks and vias retain their normal rules.
- The earlier [clearance repair](validation/CLEARANCE-REPAIR.md) describes the
  frozen `d1769b25` base. Its 53 ERC/five DRC warning counts and 93-part package
  are historical evidence, not current backport counts or exports.

Native checks establish digital source consistency. Loaded nominal 5 V margin,
current/inrush/retry, integrated LDO temperature, EN/reset-adapter behavior,
source/transient coordination, manufacturing process, physical fit and appliance
qualification remain open. The new source does not inherit the September quote
or a manufacturing approval.

## Prototype bring-up

This is a bench test plan, not permission to connect untested hardware. Do not
connect a GE appliance until the unpowered checks, USB checks, all eight
steady-state source combinations, and both dynamic handoff directions pass with
current-limited bench sources.

### Equipment and record

Use one current-limited supply or two isolated channels, a multimeter, an
oscilloscope, a USB-C data cable and ESPHome/`esptool`, magnification, and an
independently checked J1 breakout fixture. Use insulated probes and remove power
before changing connections. Never inject a surge or reversed supply without a
reviewed fixture and test plan.

Record board identifier, PCB revision, assembly supplier/lot, verified J1
fixture pin map, supply channels/current limits, target appliance, firmware
image/commit, inspector, and date.

### Visual and unpowered checks

1. Compare connector orientation, polarized markings, and DNP items with the
   schematic and assembly drawing.
2. Confirm D18/D19 are SMF16A in the documented orientations, R38 is 220 kohm, and no
   part was silently substituted.
3. Inspect for bridges, tombstones, bent connector pins, and antenna debris.
4. With every source disconnected, measure resistance from `+3V3`, `+5V`,
   `V_INPUT`, `USB_VBUS`, `PIN1_PROTECTED`, and `PIN3_PROTECTED` to ground.
5. Stop for a hard short or a result materially different from other boards.

### USB-only test

With J1 disconnected, measure `USB_VBUS`, `+5V`, and `+3V3`; confirm no USB
voltage/current reaches J1 pins 1 or 3. Confirm enumeration, flashing, reset,
and at least ten repeated reconnect/download cycles. Run sustained logging with
Wi-Fi traffic and record disconnects, resets, host warnings, current, and rail
voltage. After USB removal, verify `USB_VBUS` falls below 0.8 V within one
second. This is the prototype R38 acceptance target, not a USB certification.

### Recovery flashing through J2

Viewed from the top with `J2 RECOVERY` below the header:

| Pin | Position | Signal | Connection |
| ---: | --- | --- | --- |
| 1 | Upper left | `+3V3` | Regulator-output rail: leave disconnected; do not inject power |
| 2 | Middle left | `GND` | Adapter ground |
| 3 | Upper right | GPIO9 / `BOOT` | Hold low during download reset |
| 4 | Lower right | GPIO20 / UART0 RXD | Adapter TX |
| 5 | Middle right | GPIO21 / UART0 TXD | Adapter RX |
| 6 | Lower left | `EN` | Pull low briefly to reset |

Connect ground and crossed 3.3 V logic UART signals. Leave adapter VCC/J2 pin 1
disconnected and never inject `+3V3`. Power from one reviewed input after its
qualified power procedure. Hold BOOT low, pull EN low long enough for C26 to
discharge and satisfy the reset-low timing, then release EN. Keep BOOT held
through the delayed EN rise until the downloader starts. Actual adapter
pulse/sink behavior must pass the [reset qualification](POWER-QUALIFICATION.md).
Disconnect all leads before closing the enclosure or connecting J1.

### Appliance-input tests and eight-state matrix

Use the measured target-appliance voltage, start with a low current limit, and
increase only while observing current, rails, and temperature. Apply power
through J1 so the resettable fuse remains in circuit. Test pin 1 only and pin 3
only, recording `PIN*_FUSED`, `PIN*_PROTECTED`, `PIN*_SW_OUT`, `V_INPUT`, `+5V`,
and `+3V3`; the inactive path must remain unpowered.

With two isolated channels and common fixture ground, start pin 3 then apply pin
1: pin 1 must take priority without pin-3 reverse-current spike. Remove pin 1:
pin 3 must take over without unsafe rail excursion, reset, or reverse current.
Repeat each transition at least ten times while monitoring both source currents.
Do not deliberately reverse or over-voltage an input during first bring-up.

| Test | Pin 1 | Pin 3 | USB | Expected behavior |
| --- | --- | --- | --- | --- |
| 1 | absent | absent | absent | Board remains off |
| 2 | present | absent | absent | Pin 1 powers `V_INPUT` |
| 3 | absent | present | absent | Pin 3 powers `V_INPUT` |
| 4 | present | present | absent | Pin 1 priority; pin 3 isolated |
| 5 | absent | absent | present | USB powers only the board |
| 6 | present | absent | present | Pin 1 and USB coexist without backfeed |
| 7 | absent | present | present | Pin 3 and USB coexist without backfeed |
| 8 | present | present | present | Pin 1 priority; pin 3 and USB isolated |

For rows 6–8, monitor `USB_VBUS` and host current. Remove USB with appliance
power present and verify VBUS decay below 0.8 V in one second; reconnect without
host-directed excursion. Remove appliance power with USB present and confirm
stability.

### D18, stop conditions, and results

Verify D18 stand-off exceeds every valid steady-state condition. Capture
`PIN1_PROTECTED` and `V_INPUT` at application, removal, and handoff; record peak,
pulse duration, ringing, and D18 temperature. Stop if peaks approach stand-off
or clamp regions or the part warms during valid operation.

Remove power immediately for unexpected current limiting, collapsed or excessive
rails, inactive-input drive, appliance voltage on USB VBUS, USB over-current,
repeated resets, rapid heating, discoloration, smoke, or smell. Record results
for unpowered checks, USB/recovery, each source state and handoff, VBUS decay,
D18 transients, rail/temperature stability, enclosed Wi-Fi, appliance-only,
and appliance-plus-USB tests. A second person must review the recorded
measurements before the board is connected to an appliance.

| Item | Measurement or observation | Reviewed | Notes |
| --- | --- | --- | --- |
| Unpowered checks |  |  |  |
| USB-only power and repeated flashing |  |  |  |
| J2 recovery flashing |  |  |  |
| Pin 1 only |  |  |  |
| Pin 3 only |  |  |  |
| Pin 3 to pin 1 handoff |  |  |  |
| Pin 1 removal / pin 3 takeover |  |  |  |
| USB plus appliance sources |  |  |  |
| USB VBUS decay and no-backfeed |  |  |  |
| D18 transient observations |  |  |  |
| Rail stability and temperature |  |  |  |
| Enclosed Wi-Fi performance |  |  |  |
| Appliance-only test |  |  |  |
| Appliance plus USB test |  |  |  |

## Release and appliance-connection gates

Before ordering more than a small prototype batch or connecting an appliance:

1. Complete independent schematic, layout, BOM, and mechanical reviews.
2. Review fabricator board, drill, part-selection, and placement previews.
3. Measure actual appliance supply range and AP63205 headroom.
4. Pass all eight matrix states and both dynamic handoffs without dropout,
   cross-feed, or unsafe heating on at least two boards.
5. Pass USB VBUS decay and appliance-to-USB no-backfeed tests.
6. Qualify both SMF16A paths, source-referenced CJ3407 gate clamps, PPTC/TPS/converter
   coordination, current/inrush/retry, both loaded nominal 5 V paths, integrated
   AP2112K thermal behavior and EN/reset programming against measured conditions.
   See [the architecture-specific gates](POWER-QUALIFICATION.md).
7. Retain the repaired intended clearances, review the TP12/process margin and
   finished via annuli with the fabricator, and recheck the matched exports after
   any further source change.
8. Pass USB enumeration/flashing, sustained logging, Wi-Fi load, enclosure fit,
   connector access, and antenna-performance tests on at least two boards.

Keep USB disconnected for the first appliance-only test; test appliance plus USB
only after appliance-only operation passes. Until every physical gate passes,
Rev3A remains prototype hardware.

## Package map

- [`design/`](design/) — editable KiCad source, local footprints, and 3D models
- [`manufacturing/`](manufacturing/) — matched Gerber, BOM, and placement files
- [`validation/`](validation/) — review artifacts, checks, and qualification gates
- [`images/`](images/) — moved layer views and populated-board renders
- [Historical Rev3A enclosure guide](https://github.com/Dr-Crow/esphome-ge-laundry-uart/blob/a5a9fac87cbcb59d337a1fb8d3084ad18867a3e6/case/rev3a/README.md) — pinned historical source; enclosure CAD is outside this upstream board package. Revised protection parts, approximate models and component heights require separate fit review.

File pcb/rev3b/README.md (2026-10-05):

# PCB Rev 3B review candidate

D14/D15 now use the reviewed 1 A STPS140Z input OR diode; numbered nets and board routing are retained. [Current part-repair evidence](validation/INPUT-DIODE-REPAIR.md) distinguishes this new source from earlier validation and quote snapshots. Exact new-source checks and supplier matching remain required.

Rev 3B is a routed design under review with a bounded rated-protection backport. It passes KiCad 9's PCB and schematic checks, and manufacturing files are available for review and quoting. It is not ready to order. The [PCB revision index](../README.md) distinguishes this prototype from the retained historical designs; none is an appliance-qualified fallback.

[Back to the PCB revision index](../README.md) · [Historical ordering guide](../ORDERING.md)

## What Rev 3B is

Rev 3B uses a Seeed XIAO ESP32-C3 module with built-in USB-C, BOOT/RESET buttons, and an external antenna. It follows the approach of the [FirstBuild GE appliance adapter](https://github.com/geappliances/home-assistant-adapter). Rev 3A instead uses an ESP32-C3-WROOM-02 module and a separate USB connector on the carrier.

The antenna comes with the XIAO module; factory installation still needs confirmation. The carrier footprint follows Seeed's official 22-pad drawing.

The [KiCad 9 project](design/GEA-Adapter-Rev3B.kicad_pro), [schematic source](design/GEA-Adapter-Rev3B.kicad_sch), and [PCB source](design/GEA-Adapter-Rev3B.kicad_pcb) are available for design review. The provisional PCB uses four copper layers and measures 99 x 40 mm, with USB-C extending about 1 mm beyond the edge. This is 10.3 mm longer than Rev 3A's PCB; the extra space accommodates the XIAO, a deliberate functional-block layout, and mounting supports at opposite board ends.

The current rated-protection KiCad 9.0.9 audit reports zero configured PCB errors, warnings, excluded findings, unconnected items or schematic-to-board mismatches with all severities and all track errors requested. The schematic check also reports zero errors, warnings and excluded findings. The [rated-protection review](RATED-PROTECTION.md), [gate-clamp review](GATE-PROTECTION.md), [B-specific loaded-power gates](POWER-QUALIFICATION.md) and [frozen implementation proof](validation/rated-protection-proof.json) and [current metadata proof](validation/delay-pin-type-proof.json) record the exact backport and refreshed exports. The [earlier source audit](validation/SOURCE-REVIEW.md) describes frozen pre-backport B. The board uses ordinary 0.8 mm vias with 0.4 mm drills, keeps vias off surface-mount solder pads, and reserves the first inner layer for ground. Passing these checks does not establish electrical, thermal or appliance compatibility on assembled hardware.

The J2 model now matches the supplier drawing's pin arrangement and seating orientation. The XIAO preview now uses the licensed official C3 v1.3 PCB-derived partial model with a dimension-checked nominal SoC; the RJ45 remains a clearance envelope. [Model accuracy and datum notes](MODEL-ACCURACY.md) record the unchanged soldered-carrier placement, unmeasured nominal seating height and omitted geometry. Physical seating, enclosure fit, power-input limits and prototype testing remain to be checked. These files are not a fabrication release.

## Board views

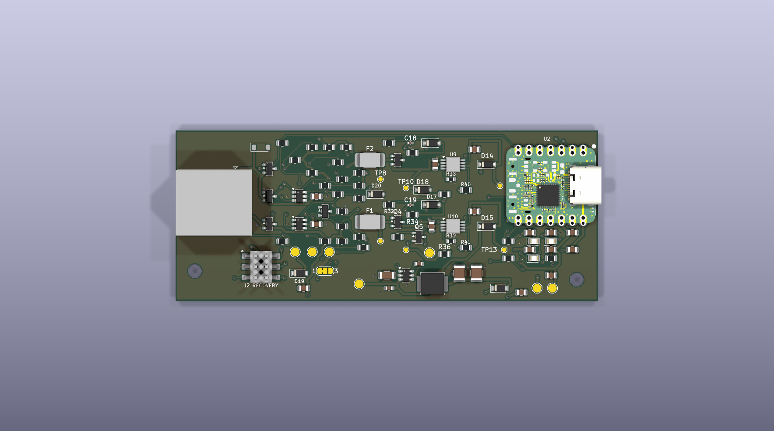
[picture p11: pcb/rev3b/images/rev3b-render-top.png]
Rev 3B routed board, top view


[Top](images/rev3b-render-top.png) · [Bottom](images/rev3b-render-bottom.png) · [Angled view](images/rev3b-render-oblique.png)

Copper layers: [top](images/rev3b-copper-f-cu.svg) · [inner ground](images/rev3b-copper-in1-cu.svg) · [inner routing](images/rev3b-copper-in2-cu.svg) · [bottom](images/rev3b-copper-b-cu.svg). All copper plots use the top-side viewing direction so layers can be compared; the bottom 3D view looks from underneath.

## One power source at a time

Rev 3B is not appliance-qualified. The supported appliance voltage range, startup and transient behavior, and loaded module power rails still need verification on a controlled bench prototype. Do not connect this unqualified board to an appliance.

Rev 3B retains a candidate circuit intended to automatically select between GE appliance pin 1 and pin 3 power without a solder-selector change. Correct operation, polarity protection, transient coordination and loaded startup from either wiring remain unverified; the [source review](validation/SOURCE-REVIEW.md#electrical-release-gates) explains the separate gates. Both original appliance inputs and the automatic selection circuitry remain present. The current candidate uses exact TPS1H200A switches, source-referenced MCC clamps, 33 V Littelfuse PPTCs and a matching PIN3 TVS. These component choices do not create a 40 V appliance rating; both loaded nominal-5 V paths remain unqualified. Only one external supply may be physically connected to the board at a time: USB, appliance power, or a regulated 5 V supply on `J2`. There is no simultaneous-source protection circuit, and appliance power energizes the same rail as USB VBUS — connecting both at once can back-feed a computer through the USB cable. Rev 3B also does not support battery operation.

## Module power pins

On the XIAO ESP32-C3 module:

- Pad 14 (`5V`) is an input/output pin.
- Pad 12 (`3V3`) is output only from the module's onboard regulator. Never drive or inject power into it.
- Pad 21 (`VBAT`) is unused on this board.

## Connection and recovery

| Interface | Purpose | Appliance | USB | Notes |
| --- | --- | --- | --- | --- |
| USB-C | Native flashing and USB logging | Unplugged | Connected | Hold BOOT while connecting, release when the bootloader port appears. |
| Appliance service port | Normal operation and Wi-Fi diagnostics | Connected | Unplugged | Use the GPIO mapping below and a revision-matched firmware configuration. Loaded startup remains a qualification gate. |
| `J2` | Backup programming when USB access is impractical | Unplugged | Unplugged | Candidate auxiliary-power input; use only a reviewed bench procedure, as described below. |

`J2` is a permanent, factory-populated, SMD 2x3 header. Its design-candidate pinout, not yet confirmed on assembled hardware:

| J2 pin | Signal |
| --- | --- |
| 1 | Regulated 5 V in, through an isolation diode |
| 2 | Ground |
| 3 | Boot (GPIO9) |
| 4 | Module RX (GPIO20) |
| 5 | Module TX (GPIO21) |
| 6 | Enable |

Use a **3.3 V logic** USB-to-UART adapter with **VCC disconnected**: adapter TX connects to J2 pin 4, adapter RX to pin 5, and adapter GND to pin 2. J2 pin 1 is this revision's auxiliary 5 V input through D19; this source identification is not approval to inject power or an established operating range. It differs from the regulator-output pin on Rev 2.1/2.2. Never inject 3.3 V into the XIAO's output rail. A reviewed bench procedure must identify one suitably rated external supply, with appliance RJ45 and powered USB disconnected. Hold BOOT low while asserting and releasing EN, then release BOOT to enter UART download mode; timing and adapter behavior require bench verification. J2 cannot recover a damaged processor or regulator.

The board also has two mounting points and three status LEDs on GPIO2, GPIO3, and GPIO4, alongside the module's onboard BOOT and RESET buttons.

## GE bus connections

| Bus | TX | RX |
| --- | --- | --- |
| GEA2 | GPIO5 | GPIO10 |
| GEA3 | GPIO21 | GPIO20 |

Use the existing shared [C3 GEA2](../../firmware/shared-rev3c/c3-gea2.yaml) or [C3 GEA3](../../firmware/shared-rev3c/c3-gea3.yaml) profile with `seeed_xiao_esp32c3`, default JP1 1–2 and a device-specific name. Their UART and LED maps match this soldered C3 source independently of Rev3C. [The coverage review](../../firmware/BOARD-COVERAGE.md) records that proof; compilation does not establish Rev3B runtime qualification. No C6 profile is supported by this soldered-C3 carrier.

## Case and ordering status

Enclosure CAD is a separate companion review and is omitted from this focused hardware candidate. Historical B case designs require verification against the new protection-component heights and the actual soldered C3 module. Shared C3/C6 Rev3C cases do not establish Rev3B fit. Antenna placement, cable access, button access, magnet retention and physical fit remain untested.

Rev 3B is not orderable. Earlier revisions retain their own electrical and assembly gates and do not establish a safe fallback. The historical ordering guide describes supplier workflow; use only this revision's matched files for a review quote, and do not infer its settings or price from Rev3C.

The following files are available for design review and assembler quotes, not as a ready-to-order release:

- [Gerber and drill ZIP](manufacturing/GERBER-GEA-Adapter-Rev3B.zip)
- [Bill of materials](manufacturing/BOM-GEA-Adapter-Rev3B.csv): 85 populated parts, including the RJ45 connector, recovery header and XIAO module.
- [Component positions](manufacturing/CPL-GEA-Adapter-Rev3B.csv): JLCPCB Designator/Mid X/Mid Y/Rotation/Layer columns for the same 85 parts, all on the top side; rotations reproduce native KiCad9.0.9 positions; J1/U2 use explicit reviewed nominal body datums, as documented in the [placement review](validation/PLACEMENT-DATUM-REVIEW.md).
- [Schematic PDF](validation/schematic.pdf)

The assembled-board quote and module availability are still pending. No per-board price has been established.

## Sources

- [Seeed XIAO ESP32-C3 getting started guide](https://wiki.seeedstudio.com/XIAO_ESP32C3_Getting_Started/)
- [GE Appliances home-assistant-adapter getting-started guide](https://github.com/geappliances/home-assistant-adapter/blob/main/doc/getting-started.md)
- [XIAO module footprint source](design/footprints/SOURCE.md) and [3D clearance model notes](design/models/README.md)

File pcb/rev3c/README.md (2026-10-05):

# Selected Rev3C prototype: shared XIAO C3/C6 carrier

D14/D15 now use the reviewed 1 A STPS140Z input OR diode; numbered nets and board routing are retained. [Current part-repair evidence](validation/INPUT-DIODE-REPAIR.md) distinguishes this new source from earlier validation and quote snapshots. Exact new-source checks and supplier matching remain required.

The selected development design uses two **TPS1H200A 40 V-rated switches**, 33 V resettable input fuses, and coordinated review of both GE power branches. It preserves PIN1 and PIN3 inputs, automatic PIN1 priority, the AP63205 buck and all C3/C6 side-header functions. C3 is the first implementation focus; C6 firmware and mechanical flexibility remain. Selection does not qualify the appliance supply, surge energy, loaded startup, thermal behavior or enclosure.

The switch change adds voltage margin against the conditional 26 V SMF16A clamp example that exceeds the former TPS22810’s 20 V absolute input limit. It does not give the entire carrier a 40 V rating or prove that a GE appliance produces that pulse. Read the [rated-input review](RATED-SWITCH-OPTION.md) and [qualification gates](POWER-QUALIFICATION.md).

[PCB revision index](../README.md) · [Gate repair](GATE-PROTECTION.md) · [Power qualification](POWER-QUALIFICATION.md) · [Antenna review](ANTENNA-REVIEW.md) · [Shared firmware](../../firmware/shared-rev3c/README.md)

## Preserved hardware

- Original 99 × 40 mm outline, four copper layers and 1.6 mm board thickness
- Mounting datums at (4.5, 33) and (94, 35) mm
- Factory-populated `J5`/`J6` HCTL PM254-1-07-Z-8.5 female 1×7 sockets and all 14 side-header functions
- GEA2/GEA3 interfaces, LEDs, pull-ups and `JP1`'s default 1–2 bridge
- Both original input branches, corrected reverse-FET/gate networks, selected rated load switches, diode isolation, common AP63205 buck and automatic PIN1 priority

The shared-source omissions are `J2` and `D19`; neither GE power input is removed. The local C6 antenna change adds an all-layer copper exclusion at x77.0–80.9, y11.8–19.2 mm and minimal reroutes of `GEA2_RX`, `GEA2_MCU_TX` and `BOOT_SEL`. The selected rated-switch design preserves the original selection and conversion topology. See the [antenna review](ANTENNA-REVIEW.md) for geometry and limits.

The [KiCad project](design/GEA-Adapter-Rev3C.kicad_pro), [schematic](design/GEA-Adapter-Rev3C.kicad_sch) and [PCB](design/GEA-Adapter-Rev3C.kicad_pcb) are editable review sources. Restoration starts from public Rev3C commit `38d94d3dc7c41692e3c41710ec33b9f6e0c38b3e` and recovered shared schematic blob `2799d9e3f023144f684d708297805eed4f355355`.

## Module and firmware selection

The side-header functions match the [XIAO ESP32-C3](https://wiki.seeedstudio.com/XIAO_ESP32C3_Getting_Started/) and [XIAO ESP32-C6](https://wiki.seeedstudio.com/xiao_esp32c6_getting_started/) references. The module is supplied separately from the assembled carrier. Use a module with all 14 header pins installed, and verify its actual revision, header mating depth and retention before use. This interface review does not establish compatibility with other XIAO models.

The [four shared firmware profiles](../../firmware/shared-rev3c/README.md) cover C3/C6 and GEA2/GEA3. Their GPIO numbers differ by module; the recovered eight YAML sources are unchanged. Keep `JP1` at 1–2 for these GEA2 profiles. The alternate 2–3 position changes TX and reaches C3 BOOT; the corresponding C6 D9 pin is GPIO20, not C6 BOOT.

Insert or remove the module only with all power disconnected. Seat all 14 pins without reversal or row offset; the sockets are unkeyed. Match the module USB connector to the carrier's right edge and orientation mark. Recovery uses the module's own BOOT/RESET buttons and native USB. There is no populated carrier recovery header or auxiliary 5 V recovery input.

## Power and qualification

PIN1 and PIN3 from one appliance are two internally selected input branches. Disconnect the appliance cable before attaching powered USB, and remove USB before appliance use. Both reviewed modules connect side-header VBUS directly to USB receptacle VBUS; carrier diodes do not isolate a connected USB host. Keep UART VCC disconnected. Use module 3V3 only as its output. Do not attach a battery within the reviewed load budget.

The corrected reverse-FET/source-referenced gate networks remain. The rated switches address the old switch/clamp rating mismatch in a bounded positive-pulse comparison, and PIN3 gains its matching TVS. Whole-chain transient/energy/differential limits, source current, current-limit/retry effects, thermal behavior and both modules' nominal5 V loaded startup remain open in [POWER-QUALIFICATION.md](POWER-QUALIFICATION.md). Automatic priority detects PIN1 presence rather than useful output power. No universal appliance compatibility is established.

## Review package and cost

Native KiCad 9.0.9 full-severity [ERC](validation/native-kicad-9.0.9-erc.json) and all-track/[parity DRC](validation/native-kicad-9.0.9-drc.json) report 0 violations,0 unconnected items and0 parity differences. The current [rated-switch proof](validation/rated-switch-proof.json) verifies 100 schematic/PCB items,233 pin nets,205 unchanged nonreplacement pin nets, original core functions/outline/mounts/sockets/firmware and0.0 mm² filled copper in the antenna exclusion on all four layers. The historical restoration/gate proofs describe their frozen checkpoints, not the current rated design's full delta.

The regenerated [BOM](manufacturing/BOM-GEA-Adapter-Rev3C.csv) and [CPL](manufacturing/CPL-GEA-Adapter-Rev3C.csv) each contain 83 matching fitted references,80−C22/C23+R38/R39/R40/R41/D20. The module is supplied separately; DNI D8 stays excluded. The native [Gerber/drill ZIP](manufacturing/GERBER-GEA-Adapter-Rev3C.zip) contains 14 members. The [stencil review](STENCIL-REVIEW.md) removes unintended drill-marker openings while preserving existing SMT apertures; D8's two remaining paste apertures need assembler review. [Schematic](validation/schematic.pdf), [PTH](validation/pth-drill-map.pdf) and [NPTH](validation/npth-drill-map.pdf) review PDFs are refreshed.

Current copper views: [front](images/rev3c-copper-f-cu.svg), [inner ground](images/rev3c-copper-in1-cu.svg), [inner routing](images/rev3c-copper-in2-cu.svg), [bottom](images/rev3c-copper-b-cu.svg). Current native partial previews: [C3 top](images/rev3c-render-top.png), [bottom](images/rev3c-render-bottom.png), [C3 oblique](images/rev3c-render-oblique.png), [C6 alternative](images/rev3c-render-c6-oblique.png). The [component model accuracy checkpoint](MODEL-ACCURACY.md) explains the revision-specific official PCB-derived C3/C6 geometry, generic USB/package substitutions, omitted module parts, drawing-based RJ45/socket detail and provisional installed height. Complete manufacturer assembly CAD was not verified; shield/buttons/antenna/male headers are omitted; a separately registered nominal U.FL reference is included and switch/PPTC maximum envelopes remain. Actual pixels were inspected. The [electrical preservation receipt](validation/component-model-electrical-preservation.json) proves that this model lane leaves all electrical source, manufacturing files and firmware unchanged.

Complete exact-part JLCPCB quotes refreshed on October 5, 2026 against the current stencil-corrected trio are **$134.64 for five assembled carriers** and **$168.92 for ten**, before shipping, tax and separately supplied XIAO modules. The source-corrected 80-part baseline was $130.39/$160.37 under the same settings, making the selected design about **$0.85 more per carrier**. All 83 references, including RJ45 and sockets, matched; these are price/availability checks rather than placement or manufacturing approval.

Use the illustrated [JLCPCB quote and ordering guide](ORDERING.md) for the matching Gerber/BOM/CPL trio, exact file hashes, observed settings and review steps. Never mix the selected 83-reference files with the historical baseline. D16/D17 use reviewed MCC BZT52C12-TP/C668891; R40/R41 use the exact 100 kΩ resistor under stocked C149504. The [clamp comparison](RATED-SWITCH-OPTION.md#reviewed-gate-clamp-sourcing-correction) retains MCC’s impedance, temperature and transient limits. BOM/CPL bytes remain the reviewed files; the current Gerber ZIP has the stencil correction and its fresh [supplier quote receipt](validation/JLCPCB-QUOTE-2026-10-05.json) binds all three hashes. Supplier placement/stencil/process approval remains open.

The selected switches add approximately 86 mV of illustrative path loss at 364 mA and change startup/current-fault behavior. Neither the quote nor a native pass closes the loaded 5 V, current, thermal or transient gates. No order or physical test has been performed.

## Enclosure

The [editable shared enclosure review prototype](../../case/rev3c/README.md) is recovered, with one common base and separate C3/C6 lids. It is not a qualified default: its historical electronic proxies need the current component envelopes, and actual socket height, actuator calibration, printing, retention, USB/RJ45 access, antenna cables and RF remain untested. The original C3-specific case does not qualify C6 fit. Follow the [prototype qualification plan](PROTOTYPE-QUALIFICATION.md) before assembly or powered testing.

The [placement-datum review](validation/PLACEMENT-DATUM-REVIEW.md) corrects J1’s CPL body centre without changing CAD, BOM or rotation. Earlier quote hashes remain historical; actual supplier-library pose/process approval is still required.

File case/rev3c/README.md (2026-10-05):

# Shared Rev3C enclosure review prototype

The editable all-printed enclosure source has been recovered. It has one common base, separate C3 and C6 lids, integral printed BOOT/RESET mechanisms, three light guides, and internal or external antenna variants. **It is a review prototype, not a qualified default enclosure for the selected carrier.**

[Enclosure index](../README.md) · [Selected carrier](../../pcb/rev3c/README.md) · [Prototype qualification plan](../../pcb/rev3c/PROTOTYPE-QUALIFICATION.md)

The [independent mechanical finding matrix](review/recovered-enclosure-review.md) and [compact check receipt](review/provenance-counts.json) record actual source/STEP/STL inspection, current-board datums and unresolved fit assumptions. [Detailed export checks](review/inspection-receipt.json) and the [current datum comparison](review/current-datum-comparison.json) preserve the individual measurements and hashes.

## Current analytical derivative

[Parametric review source](analytical/README.md) now registers current component screens and samples installed stacks from11.0 to11.65 mm. It offers separately reviewed longer-leaf and local guide-relief candidates, with explicit per-button controls and five-piece review exports. Correct-lid nominal screens pass; original fixed reaches and wrong-lid prevention fail their stated checks. Actual switch, plug, print, optical, thermal and RF qualification stays open.

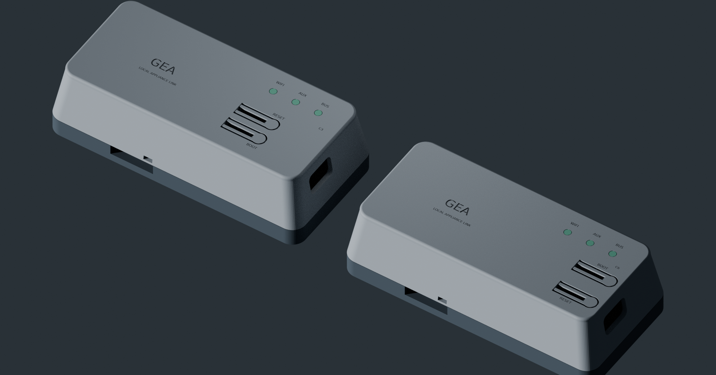
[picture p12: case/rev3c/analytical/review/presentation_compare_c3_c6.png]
Actual C3/C6 prototype geometry


These are fresh source-derived presentation renders, with recorded geometry/tool hashes and illustrative materials. The following original-recovery evidence remains historical; its uncorrected proxy and regeneration limitations are preserved rather than relabeled as a current result.

## Recovered source

The [build123d source](prototype/enclosure.py), [interface datums](prototype/interface_baseline.py), [electronic proxies](prototype/component_envelopes.py), [pinned dependencies](prototype/requirements.txt) and [license](prototype/LICENSE) are copied without changes from `GE-enclosure-CAD-and-review.zip`. [Source provenance](prototype/SOURCE-PROVENANCE.json) records the archive and individual file hashes. STEP and STL exports are geometry outputs; the Python files are the editable parametric source.

The separate `GE-tapered-enclosure-review-2026-10-02.zip` contains the older spring/cassette design. It is preserved as historical material and is not the recommended starting point. The existing [Rev2 Fusion archive](../rev2/README.md) belongs to another board family. Historical C3-only cases do not establish shared C3/C6 fit.

The recovered source was reviewed against carrier commit `11826a7f6ba1ed19131ddba46e4d62b06196a8c6`. Its original mounting, socket, LED and module XY datums remain useful. Its electronic proxies still include removed J2 and omit the selected rated-switch/fuse/PIN3-TVS changes. They must be reconciled with the current populated board before new collision results can be used. Module/header seating and button height remain provisional.

There is also a concrete difference between the provisional height models: the case uses 8.65 mm maximum socket height plus 3.0 mm male spacer, while the current board preview assumes 8.5 + 2.5 mm. Comparing those assumptions increases the nominal released actuator gap from 0.25 to 0.90 mm, beyond the C3/C6 stop travels of 0.40/0.36 mm. This is a source-assumption mismatch, not a measured physical failure; actual seated dimensions must determine the reaches.

The C3 lid must not be installed over C6. One C3 contact is approximately 0.19 mm from the C6 U.FL datum and the other falls inside its ceramic antenna projection. Module swaps require the correct labeled lid and antenna configuration.

## What must be checked next

- Measure each actual module, installed header/socket stack, USB shell and plug, BOOT/RESET switches and safe actuator travel. The C6 fixed-height mechanism can under-travel or over-travel across its conditional switch-height tolerance; do not press it against an installed module before calibration.
- Register current component bodies and solder tails, check base/support clearances and cable access, then generate and inspect source-matched meshes and slicer previews. The original archive's nominal collision counts do not qualify the selected 40 V-switch board.
- Print the button and closure coupons without electronics. Verify release, return, accessible latch release, repeated-use wear and creep in the chosen printer/material/profile before an enclosure assembly trial.
- Verify light-guide fit, retention, brightness and leakage. `WIFI` means green D4 Wi-Fi connected; `AUX` means red D5 manually controlled and off at startup; `BUS` means yellow D6 GEA bus connected, not packet activity or a power-good indicator.
- Check the C3 FPC and both U.FL cable routes, C6 ceramic-antenna clearance, external bulkhead nut/strain relief and remote-antenna cable slack. Actual RF and metal-appliance proximity need separate qualification.

Both appliance power inputs enter through the same J1 8P8C connector; no second power opening is needed. Leave room to unplug that cable before powered USB recovery. Keep the two module-specific lids visibly identified, and preserve BOOT-held/RESET-pressed recovery access.

## Regeneration boundary

The original source pins build123d 0.11.1 and trimesh 5.1.0. `enclosure.py` writes its own adjacent `exports` folder and uses the DejaVu Sans font path declared in the source. Run it only in a working copy after installing the pinned tools and reviewing the parameters. The recovered STEP/STL validation helpers and historical exports remain in the original archive. The delivered printed-case archive omits `exports/summary.json`, and its rendering manifests reference additional electronics, cutaway and supplier meshes; regenerate or legitimately obtain those inputs before claiming a reproducible complete render.

A fresh read-only inspection found all 15 delivered printed-case STEP/STL pairs valid, closed and positive-volume, with close volume agreement; that is export integrity, not source regeneration or current-board fit. Installed build123d 0.10.0 differs from the pinned version and trimesh is absent. Neither regeneration nor physical printing is claimed by this recovery.

Disconnect all power before inserting/removing the module or assessing mechanical fit. Disconnect the appliance cable before powered USB; UART VCC stays disconnected. The complete proposed review sequence is in [PROTOTYPE-QUALIFICATION.md](../../pcb/rev3c/PROTOTYPE-QUALIFICATION.md).

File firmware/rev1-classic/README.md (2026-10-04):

# Rev1 classic ESP32 firmware candidates

These two isolated profiles follow the recovered Rev1 UART wiring and the original `nodemcu-32s` target. They preserve the existing Rev2.x and shared Rev3C profiles. Compilation is a software check; these remain unqualified hardware/profile candidates.

| Profile | UART TX / RX from ESP perspective | Electrical encoding |
| --- | --- | --- |
| [GEA2](gea2.yaml) | GPIO18 / GPIO19, U3 pads 30 / 31 | Inverted, 19,200 baud |
| [GEA3](gea3.yaml) | GPIO17 / GPIO16, U3 pads 28 / 27 | Non-inverted, 230,400 baud |

The profiles pin ESP-IDF 5.5.5 and the GEA component at commit `283ff2b0dfe90a6d14a5417a23176d433be8a5b3`, with ESPHome minimum 2026.9.1. Their common services and protocol behavior derive from the modern shared Rev3C packages. Appliance entities/address examples still require appliance-specific review.

## Exact source identity and GPIO limits

Recovered Rev1 hardware source is commit `87984047ee029efb83bf9947dc21818fd18e39b3`. U3 is custom symbol `onionStraws:ESP32`, value ESP32, footprint `Library:DIP-38_900_ELL`, symbol UUID `4b8c3e21-2d12-4f69-bdf2-b8db31da1d87`. This establishes a generic 38-pin classic ESP32 development-board interface; the exact purchased module, silicon, flash size and physical pin compatibility are unknown. `nodemcu-32s` is the original firmware build target, not identification of an installed device.

Native netlist and board pin-membership review establishes one carrier LED: U3.15/GPIO13 → R19 220 Ω → D6 anode, with D6 cathode at GND. It is active high. The generic D6 LED source does not establish its color. This candidate uses that single LED as a Wi-Fi indicator with 4% maximum PWM duty and an off startup state. GPIO14 is SW1's input and is left unconfigured. No C3 red/green/yellow LED pins or module-specific LEDs are assumed.

These GPIO mappings do not match the C3/C6 revisions. Current legacy C3 profiles use GEA2 TX5/RX10 and GEA3 TX21/RX20; they do not match Rev1. Do not treat these classic ESP32 candidates as replacements for those profiles.

## Power and physical gates

Rev1 takes GE power only on RJ45 J2.1 through F1 and Q1/Q2, then needs an external buck through J1. The source does not establish the actual buck module, source envelope/current allowance, protection coordination, loaded startup, thermal behavior, purchased development-board power path, or physical/case compatibility. The module's 3V3 output supplies carrier logic. Check those independently before any device/appliance use.

Use one reviewed supply. Keep any UART programmer VCC disconnected; do not inject carrier/module 3V3 or combine appliance/buck power with USB/programmer power. The actual development-board USB/5VIN relationship needs review. This change includes no flashing, device connection or approved physical commissioning procedure.

## Validation

Validation uses ESPHome 2026.9.1 `config` and real `compile` commands for both profiles with ESP-IDF 5.5.5. A separate temporary source receives only synthetic `secrets.yaml` values; no real credentials are read. Full results, exact source hashes and actual binary hashes are recorded in [BUILD-REPORT.md](validation/BUILD-REPORT.md) and [build evidence](validation/build-evidence.json). Local generated binaries are under the ignored `validation/artifacts` directory. A config-only result or dependency failure is not reported as a compile pass.

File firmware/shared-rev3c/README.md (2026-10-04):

# Shared Rev3C firmware

These unchanged recovered profiles support the common XIAO ESP32-C3/C6 side-header functions on the restored dual appliance-input Rev3C review candidate. Restoring PIN1/PIN3 and automatic PIN1 priority does not qualify power circuitry or an appliance model. Read [power qualification](../../pcb/rev3c/POWER-QUALIFICATION.md) before connecting hardware.

| Profile | Module | Protocol | Module TX / RX GPIO |
| --- | --- | --- | --- |
| [c3-gea2.yaml](c3-gea2.yaml) | XIAO ESP32-C3 | GEA2, inverted, 19,200 baud | 5 / 10 |
| [c3-gea3.yaml](c3-gea3.yaml) | XIAO ESP32-C3 | GEA3, non-inverted, 230,400 baud | 21 / 20 |
| [c6-gea2.yaml](c6-gea2.yaml) | XIAO ESP32-C6 | GEA2, inverted, 19,200 baud | 21 / 18 |
| [c6-gea3.yaml](c6-gea3.yaml) | XIAO ESP32-C6 | GEA3, non-inverted, 230,400 baud | 16 / 17 |

## Pinned sources and build evidence

Use ESPHome **2026.9.1** with ESP-IDF **5.5.5**. GEA is pinned to commit `283ff2b0dfe90a6d14a5417a23176d433be8a5b3`. The four profiles and four package YAML files remain unchanged during dual-input restoration. All four configurations and real factory/OTA/ELF builds were already checked with these pinned tools, using dummy secrets and no network or appliance connection; this restoration does not require rebuilding unchanged sources.

Copy a profile and its `packages` directory together, then supply `wifi_ssid`, `wifi_password` and `esp_home_ota_pw` in your own ignored `secrets.yaml`. Build success verifies firmware generation, not GPIO electrical behavior, power headroom, bus acceptance or hardware qualification.

Choose protocol, destinations and ERDs for the exact appliance. GEA2 destination `0x24` and Door/Cycle Complete entities are examples, not a verified refrigerator profile. GEA3 uses destination `0xC0`. These are ESPHome Wi-Fi profiles; Matter/Thread is not implemented.

## Carrier mapping and JP1

GEA2 TX/RX use D3/D10; keep `JP1`'s default 1–2 bridge for these profiles. Alternate 2–3 changes TX and reaches C3 BOOT. C6 D9 is GPIO20, not C6 BOOT. GEA3 TX/RX use D6/D7. Shared schematic names refer to appliance direction: `GEA3_RX` is module TX, while `GEA3_TX` is module RX.

- **D4 green:** Wi-Fi connected, C3 GPIO3 / C6 GPIO1
- **D5 red:** manual light, off at startup, C3 GPIO2 / C6 GPIO0
- **D6 yellow:** GEA component bus-connected state, C3 GPIO4 / C6 GPIO2

Yellow indicates connection rather than blinking for each packet. C3 GPIO2 is a strapping pin; its carrier pull-up matters before application startup. Existing pulls and all 14 socket functions remain part of the recovered interface.

## RF selection and service

C6 GPIO3 low enables RF. GPIO14 low selects ceramic/internal; `c6_external_antenna: true` selects external. Attach the correct external antenna before enabling that option. The [local antenna exclusion](../../pcb/rev3c/ANTENNA-REVIEW.md) addresses copper overlap; RF with the socketed module, antenna and final case remains unqualified.

Use each module's BOOT/RESET buttons and native USB for recovery. The shared carrier omits J2/D19. C3/C6 buttons and U.FL connectors require different case geometry; the historical C3-specific case is not a default shared enclosure. Mating height, retention, USB/button access and RF need physical checks.

Disconnect the appliance cable before powered USB, and remove USB before appliance use. Both reviewed modules tie side-header VBUS directly to USB VBUS; carrier diodes do not isolate a USB host. Use module 3V3 only as its output. Do not attach a battery or drive underside power pads within the reviewed budget. PIN1/PIN3 from one appliance are internally selected inputs, not permission for simultaneous appliance/USB sources.

`logger.baud_rate: 0` suppresses application UART logs. Both chips can still emit ROM boot messages on D6 before application setup, reaching existing GEA3 TX even with a GEA2 profile selected. No appliance corruption or field failure is established by this finding. Hardware TX containment is a separately reviewed option and is not implemented here; these sources do not promise silence during reset, download or brownout.

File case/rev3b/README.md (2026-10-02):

# Rev3B printable enclosure candidate

Editable `build123d` source and generated base/lid files for the current
Rev3B carrier PCB (99 x 40 x 1.6 mm, four layers). This is a simple,
nonmagnetic default candidate; it is not a physical-fit, electrical, thermal,
or RF qualification.

## Files and variants

* `enclosure.py` — parametric source.
* `check_geometry.py` — STL/STEP, manifold, dimensional, component-envelope,
  LED-aperture, support, magnet-pocket, and external-bulkhead checks.
* Default: [`base STL`](exports/rev3b_base.stl), [`base STEP`](exports/rev3b_base.step),
  [`lid STL`](exports/rev3b_lid.stl), [`lid STEP`](exports/rev3b_lid.step).
* Internal antenna: [`base STL`](exports/rev3b_base_ant-internal.stl),
  [`lid STL`](exports/rev3b_lid_ant-internal.stl), with matching `.step` files.
* External bulkhead: [`base STL`](exports/rev3b_base_ant-external.stl),
  [`lid STL`](exports/rev3b_lid_ant-external.stl), with matching `.step` files.
* Captive magnets: [`base STL`](exports/rev3b_base_magnets.stl),
  [`lid STL`](exports/rev3b_lid_magnets.stl), with matching `.step` files.
* [`images/rev3b-cad-preview.png`](images/rev3b-cad-preview.png) — native STL
  geometry preview; transparency is for inspection only.

Generate with a build123d 0.11.1 environment:

```sh
python enclosure.py
python enclosure.py --antenna internal
python enclosure.py --antenna external
python enclosure.py --magnets
python check_geometry.py
```

The checked-in exports were generated and `check_geometry.py` completed with
`All checks passed.` The external variant is optional and does not change the
default/internal case.

## Mechanical candidate

The frozen-board transforms are taken from the current Rev3B PCB. H1=(4.5,33.0) and
H2=(94.0,35.0) have one locating support each. The board sits 1.25 mm above
the 2.4 mm floor. Annular lid retainers overlap the board surface around H1/H2
to provide hold-down, while the posts locate through the 3.2 mm drills. J1 and USB-C have generous service windows at opposite ends;
J2 is internal and requires lid removal. Three 2.5 mm LED apertures are at
the extracted D4/D5/D6 positions. Two conservative lid tool apertures are
centered on the BOOT0/RST0 centers from the official Seeed v1.3 project; tool
fit, actuator force, and return must still be checked on hardware.

The lid has two 3.5 mm tool holes above the module's BOOT and RESET buttons.
Their alignment follows Seeed's module layout; the geometry checks include
these positions to catch accidental movement of either opening.

The conservative J1 and XIAO model envelopes are project clearance solids,
not manufacturer CAD. The base includes a conservative 3.0 mm under-board
RJ45-tail relief with a 0.6 mm floor skin because the local evidence does not
specify assembled tail length. Cable plug/latch sweep, USB strain relief,
RJ45 mating, lid retention, and populated-board seating remain physical checks.

## Antenna options

### Internal FPC (`--antenna internal`)

Adds a shallow 40 x 20 mm placement ring on the lid underside, away from the
three LED apertures. It is sized from the candidate Seeed FPC drawing
(M01-0601770R0A), but the identity of the antenna bundled with SKU 113991054
is not confirmed. The ring supplies guidance only; adhesive supplies
retention. FPC bend, metal clearance, coax routing, and closed-case RF
performance are untested.

### External bulkhead (`--antenna external`)

This option is deliberately tied to the named **TE/Linx
CSB-RGFB-102-UFFR** cable assembly, not to an arbitrary SMA/RP-SMA part. Its
primary drawing is the [Toradex-hosted TE/Linx datasheet](https://docs.toradex.com/114003-datasheet-pigtail-antenna-cable-ufl-to-rp-sma-100-mm.pdf),
page 3. The case provides:

* a Ø6.5 mm bulkhead opening;
* a local reinforced seat held to the drawing's 1.5 mm maximum panel
  thickness;
* the drawing's 6.0 mm flat/key datum recorded as a part-specific datum, but
  not guessed as a keyed PCB-oriented cutout;
* a mechanical wall load path for the RP-SMA nut, separate from the U.FL.

The part is an RP-SMA **jack with male pin** to U.FL/MHF1-type female socket,
on 102 mm RG-178 cable, with a 10 mm minimum inside bend radius. Verify the
actual purchased part, nut/washer stack, panel seating, cable bend, and
antenna clearance before printing a production case. No RF or physical-fit
guarantee is made.

## Optional captive magnets (`--magnets`)

The default is nonmagnetic. The optional case widens the perimeter and adds
two fully enclosed pockets for placeholder 4 x 2 mm disc magnets. Pockets are
isolated from the PCB cavity by asserted solid clearances and have printed
skins above and below. Pause **before the first layer that closes the pocket
roof**, at the source constant `MAGNET_PAUSE_Z` (currently 5.2 mm); adapt it to
the slicer's actual layer boundary and printer pause behavior. Magnet material,
polarity, holding force,
RF interaction, and appliance-temperature behavior were not tested.

## Prototype gate and safety

Print base and lid separately and test on an unpowered, populated board.
Check RJ45/USB insertion and latch/strain-relief clearance, BOOT/RESET reach
and release, LED visibility, J2 lead access with the lid removed, board seating,
antenna bend/retention/RF behavior, and magnet captivity if selected. Do not
connect USB, appliance power, and J2 5 V at the same time; the case provides
no electrical interlock.

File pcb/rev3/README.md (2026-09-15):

# Revision 3A PCB

New to the board? Start with the illustrated [Revision 3A board guide](BOARD_GUIDE.md).
Reviewers should use the self-contained [review package](review/README.md) and its
[release-readiness checklist](review/REVIEW_CHECKLIST.md).

## Automatic power front end

Revision 3A is a no-jumper design. The proposed front end gives each appliance input an independent fuse, reverse-protection stage, and controlled switch:

```text
J1 pin 1 (VDC)  -> F2 -> CJ3407 reverse-protection PMOS -> TPS22810DBVR ->+
J1 pin 3 (ALT)  -> F1 -> CJ3407 reverse-protection PMOS -> TPS22810DBVR ->+-> V_INPUT
                                                                            |
                                                                            +-> AP63205 input
```

Each TPS22810 uses CT = 0.022 uF, a local 1 uF input capacitor, a 0.1 uF output
capacitor, and a small 100 pF/5.1 k/51 ohm PMOS gate network derived from the
published FirstBuild design. An MMBT3904 transistor and two resistors give pin 1
priority when both inputs are present. MBR0540 diodes are intended to combine the two switched
outputs without feeding one appliance pin from the other. USB power remains on its
separate F3/D10 path, and the existing buck-side D11 isolation is retained. There is
no JP2 or user-selectable power control.

Pin-1 priority, reverse protection, and source isolation are design objectives, not
qualified safety properties. Verify them with current-limited supplies in all eight
source combinations before connecting an appliance.

The AP63205 remains the prototype regulator. A measured 4.3 V source cannot produce a
regulated 5 V output; source headroom and the reverse-protection/load-switch drops are
physical release gates, not software assumptions.

### Eight-state design expectation — unverified until bring-up

| VDC (pin 1) | ALT_PWR (pin 3) | USB VBUS | Selected appliance path | V_INPUT / board behavior |
| --- | --- | --- | --- | --- |
| absent | absent | absent | none | unpowered |
| present | absent | absent | pin 1 | V_INPUT from pin 1 |
| absent | present | absent | pin 3 | V_INPUT from pin 3 |
| present | present | absent | pin 1 priority | pin 3 isolated |
| absent | absent | present | USB | USB path only |
| present | absent | present | pin 1 + USB isolation | no appliance-to-USB backfeed |
| absent | present | present | pin 3 + USB isolation | no appliance-to-USB backfeed |
| present | present | present | pin 1 priority + USB isolation | both isolated; test current sharing |

The schematic includes diagnostic pads at the fused, reverse-protected, and switched
output of each appliance input, plus V_INPUT, USB VBUS, +5V and +3V3. J2 is a
permanently populated top-side 2-by-3, 2.54 mm recovery header carrying +3V3, GND,
BOOT, ESP UART TX/RX, and EN. It provides a simple backup flashing path with an
ordinary 3.3 V USB-to-UART adapter and female Dupont leads if the USB connector or
USB data path is unavailable. J3 remains in the schematic only as a DNP alternate
for a future Tag-Connect variant; it is not placed or populated on Rev3A.
SW1 is connected to `EN` and labelled `RESET`; SW2 is connected to GPIO9 and labelled
`BOOT`. Hold BOOT, tap RESET, release RESET, then release BOOT to enter the ESP32-C3
ROM downloader. J2 uses a surface-mount male header so it keeps the board underside
flat and avoids a case-floor relief. It is less mechanically rugged than a
through-hole header, so connect and remove leads with the board supported.
JP1 is unrelated to power:
it is the inherited signal-mapping solder selector. Its manufactured copper defaults
to pads 1-2 for FirstBuild-compatible mapping; changing it is an engineering rework
that requires cutting that bridge and joining pads 2-3. Validate all eight power states
with current-limited supplies before any appliance connection.

### Buttons and indicators

- `SW1 RESET` resets the ESP32-C3. `SW2 BOOT` is only needed to force the ROM
  downloader when automatic USB flashing cannot start. Before the reset/boot cleanup,
  both switches acted on boot-strapping pins and the board had no dedicated reset
  button.
- The green LED is the Wi-Fi-connected indicator.
- The yellow LED is the GEA-bus-connected indicator.
- The red LED is currently exposed to ESPHome/Home Assistant as a user-controlled
  diagnostic light. It is reserved for a future fault pattern rather than adding a
  fourth LED or silently changing an existing entity's behavior.

USB-C is the normal programming and logging interface. J2 is the backup interface;
its installed 0.1-inch pins accept common female Dupont leads, so no pogo fixture or
Tag-Connect cable is required. Open the enclosure before using it. Use 3.3 V UART
logic only, cross adapter TX/RX, and never drive J2 power while the board is already
powered from USB or the appliance. See
[BRINGUP.md](BRINGUP.md#recovery-flashing-when-usb-is-unavailable) for the exact pin
map and sequence.

Status: digitally complete for review and quoting, but not electrically qualified. Do not order or connect this board to an appliance until the vendor previews and prototype gates below pass.

Revision 3A keeps the ESP32-C3-WROOM-02 module used by Revision 2. The module includes its Wi-Fi antenna. The board adds easier USB-C programming and replaces the older power regulators with parts better suited to appliance power and Wi-Fi current peaks.

## What changes from Revision 2.2

| Area | Revision 2.2 | Revision 3A |
| --- | --- | --- |
| ESP32 | ESP32-C3-WROOM-02 | Same module and built-in antenna |
| Programming | External programming connection | USB-C using the ESP32-C3's built-in USB interface |
| Appliance-to-5 V power | L7805 linear regulator | AP63205 switching regulator for less heat and a wider input range |
| 3.3 V power | AP2205, rated for 200 mA | AP2112K, rated for up to 600 mA |
| USB/appliance power sharing | Not supported | Each source passes through a blocking diode before the 5 V rails join |
| Reset monitor | U1 footprint left empty | Removed from the design |
| Board | 88.7 mm by 30.1 mm, two layers | 88.7 mm by 40.0 mm, four layers |

The blocking diodes are one-way valves for electricity. They let either the appliance or USB power the board while preventing appliance power from being pushed back into the computer's USB port. That behavior still needs to be measured on prototypes in every source combination.
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

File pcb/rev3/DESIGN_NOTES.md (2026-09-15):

# Revision 3A design notes

This file records the decisions that materially affect safety, cost, or whether the board can be assembled. Candidate part numbers are not approvals to order.

## Power path

### Rev3A automatic front end

The proposed Rev3A power architecture removes the manual JP2 selector and the shared
Q1/Q2/D12/D13 gate network. F1 and F2 remain independent per-input fuses. Each fused
input uses a FirstBuild-derived P-channel reverse-protection stage followed by its own
TPS22810DBVR load switch. Rev 3A uses the currently available CJ3407 instead of the
scarce DMP3030SN reference part. Each channel has a 0.022 uF timing capacitor, 1 uF
input capacitor, 0.1 uF output capacitor, and a 100 pF/5.1 k/51 ohm PMOS gate network.
An MMBT3904 with external 10 k resistors makes J1 pin 1 the priority source when both
appliance inputs are valid. This replaces the inconsistent and end-of-life pre-biased
transistor choices found in the reference files with common parts whose values are
explicit in the schematic. MBR0540 output isolation is intended to keep the secondary
source from back-powering the selected path. The common isolated V_INPUT feeds the existing
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

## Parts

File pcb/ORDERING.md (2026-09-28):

# Order a Rev 3A board

You do not need KiCad to order the board. This guide uses JLCPCB, but another PCB assembly company can use the same files.

[Back to the project overview](../README.md) · [PCB revision index](README.md)

> [!NOTE]
> Rev 3A has not yet been tested as an assembled board. Order the minimum quantity
> first. If you want to wait for tested hardware, check the
> [Rev 3A status](rev3a/README.md) before ordering.

## Download these three files

- [Gerber ZIP](rev3a/manufacturing/GERBER-GEA-Adapter-Rev3A.zip): the board itself
- [BOM](rev3a/manufacturing/BOM-GEA-Adapter-Rev3A.csv): the parts list
- [CPL](rev3a/manufacturing/CPL-GEA-Adapter-Rev3A.csv): where the parts go

Keep these three Rev 3A files together. Do not use a BOM or CPL from another revision.

## Place the order

1. Open the JLCPCB PCB quote page and upload the Gerber ZIP.
2. The site should detect a 4-layer board about 88.7 mm by 40.0 mm. Use the standard 1.6 mm board thickness.
3. Choose five PCBs and enable PCB assembly for all five boards.
4. Select economic, top-side assembly.
5. Upload the Rev 3A BOM and CPL when prompted.
6. Review the board and component-placement previews. Resolve any missing, unselected, or obviously misplaced parts before continuing.

## Current price estimate

A JLCPCB quote checked on September 19, 2026 was **$149.96 before shipping and
tax for five fully assembled boards**, or about **$29.99 per board**. Treat this
as a dated estimate because component stock, assembly classifications, and pricing
change.

## Before paying

Before continuing, check that:

- The board is about 88.7 mm by 40.0 mm and has four layers.
- Assembly is enabled for all five boards on the top side.
- The component-placement preview looks aligned with the board.
- The parts list has no unresolved or unselected items.

The [Rev 3A manufacturing page](rev3a/manufacturing/README.md) describes the
expected package and current quote if you need to compare them with the order
screen.

## When the boards arrive

1. Check for bent connectors, loose parts, or visible solder bridges.
2. Complete the [Rev 3A bring-up procedure](rev3a/README.md#prototype-bring-up)
   using current-limited bench power.
3. Follow the [firmware setup guide](../firmware/README.md) to flash the board
   through USB-C.
4. Do not connect it to a real appliance until the unpowered, USB-only, recovery,
   and current-limited source/isolation checks in the bring-up procedure pass.
   Then perform the controlled appliance-only qualification before testing with
   USB connected.

If you do not have the tools to perform the power and backfeed checks, wait until
the first Rev 3A batch has been tested and the results are posted.

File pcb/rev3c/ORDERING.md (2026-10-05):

# Rev3C JLCPCB quote and ordering guide

## Start with a quote and review

**Current matched source:** `bf5c2318b4c9ee775c19f7b9327cd1a8fea02d27` selects STPS140Z (`C155662`) for D14/D15 and the maximum-body socket courtyards. Fresh complete five/ten quotes below match its exact three manufacturing files. Copper, drills, outline and CPL are retained; exact-source native KiCad 9.0.9, intended rules, 38 validator tests and eight firmware builds pass. Supplier new-part pose, joint/process and all electrical/physical release gates remain open. See the [bounded repair](validation/INPUT-DIODE-REPAIR.md), [courtyard proof](validation/SOCKET-COURTYARD-REVIEW.md) and [current quote receipt](validation/JLCPCB-ST-QUOTE-2026-10-05.json).

The selected 83-reference Rev3C prototype has complete JLCPCB quotes of **$135.81 for 5 assembled carriers** and **$171.20 for 10**, refreshed October 5, 2026 at 17:53/17:55 UTC. All 83 references and 34 unique codes matched exactly, with no shortage warnings, omissions or substitutions. Shipping, taxes, separately purchased factory-preheadered XIAO modules, programming, functional testing and a case are excluded. Stock is not reserved. This design remains **unqualified for manufacture or appliance connection** until the release gates below are closed.

Both GE power inputs, automatic PIN1 priority, the buck and C3/C6 interfaces remain. No extra USB circuitry was added. Disconnect the appliance before powered USB.

The current Gerber ZIP includes the October 4 [stencil correction](STENCIL-REVIEW.md): drill-center graphics are disabled so they cannot create unintended paste openings at drilled holes. The CPL and copper/drill geometry are unchanged. The fresh ST-parts quote used this corrected ZIP and current BOM/CPL; every byte count and SHA-256 below was verified before upload. Actual stencil/process approval remains open. Earlier settings/placement illustrations remain historical examples.

The earlier pre-ST, 83-reference quote was $134.64/five and $168.92/ten. The ST diode repair adds **$1.17/five or $2.28/ten**, about **$0.23 per carrier**, under the same observed settings. For historical architecture comparison, the 80-reference `ca1fdb1` baseline was $130.39/five and $160.37/ten with original switches/fuses retained. That October 3 snapshot is preserved below; it is not a new simultaneous quote or the selected design.

## Keep the selected three files together

Download [Gerber ZIP](manufacturing/GERBER-GEA-Adapter-Rev3C.zip), [BOM](manufacturing/BOM-GEA-Adapter-Rev3C.csv) and [CPL](manufacturing/CPL-GEA-Adapter-Rev3C.csv) from this same revision. These relative links select the 83-reference package described below.

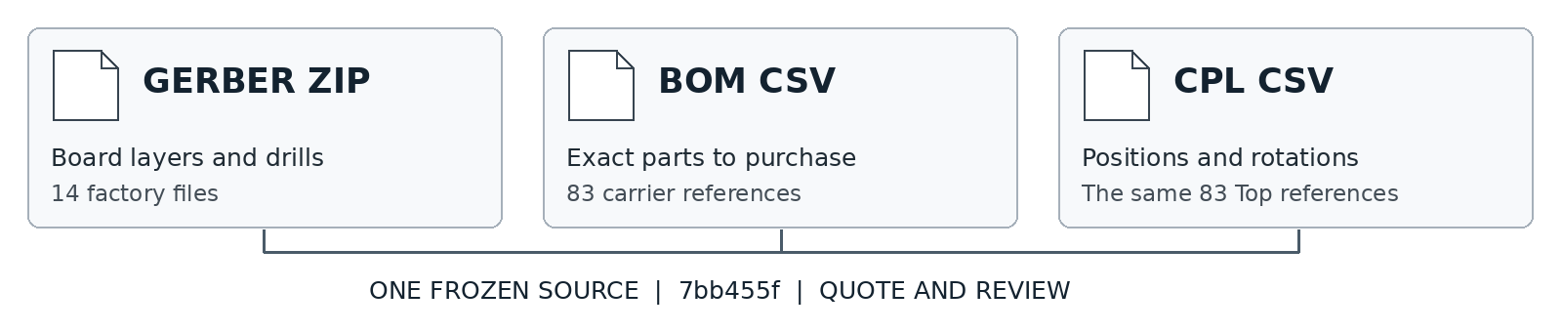
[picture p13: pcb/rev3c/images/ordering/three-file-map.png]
Three files from one frozen source


The download links above select the current paired review files, matched in the fresh quote at **bf5c231**. The earlier integration **2d5a42c** and stencil **b87d3e8** remain provenance. J1's CPL X/Y use a documented nominal body datum, with native rotation retained. See the [placement review](validation/PLACEMENT-DATUM-REVIEW.md). Familiar filenames alone do not identify the version.

The October3 quote/screenshot snapshot was source **7bb455fbc85c748f3125ed091a54375de69fbbcc**, frozen package `rev3c-rated-option-7bb455f`, with its older pin-1-anchor CPL. Its frozen CPL was 3157 bytes, SHA256 `aedf3c96a88d4ced3028111d3d5cf2d13d135eaa57dc472c9e84bd6f84a9221b`. The corrected `b53cfca` package was uploaded and re-quoted at 04:16 UTC on October 4: all 83 codes matched/stocked for 5/10, totals unchanged at $134.64/$168.91. Actual 2D/3D library alignment remained unverified because the supplier preview still showed generic placeholders. Refresh stock and approve real placement/process before ordering.

| File | What JLCPCB uses it for | Bytes | SHA-256 |
| --- | --- | ---: | --- |
| GERBER-GEA-Adapter-Rev3C.zip | Copper, solder mask, silkscreen, outline and drills; 14-member native factory package | 215452 | 73d319df01ec65f1b8ba60b49da10fd3a226887d75be6d6e6170832a2cdf3c13 |
| BOM-GEA-Adapter-Rev3C.csv | 83 carrier reference designators and their exact selected parts | 4766 | 371f9a2f167241fb0967e6645af5c34ef91c2314a433388caf1102c7699cc97c |
| CPL-GEA-Adapter-Rev3C.csv |83 refs; J1 nominal body datum, native angles and Top layer | 3156 | a1f17d5e6018b582694428e374c18ecc110410482ab69022347bd8cf62ea37b2 |

The 80-part baseline uses a different matched trio from source **ca1fdb1261af8b32a1bf353d37f40439ead5c3b0**, package `rev3c-dual-input-ca1fdb1`. Use its own 80-reference BOM and CPL together with its own Gerber ZIP. Do not mix the packages.

| Baseline file | Bytes | SHA-256 |
| --- | ---: | --- |
| GERBER-GEA-Adapter-Rev3C.zip | 202906 | b6e92d609202072d2e2e1e891b856ad3f1f08da8147d9e17ffe5fa91d5bebcd0 |
| BOM-GEA-Adapter-Rev3C.csv | 4536 | c2f91bfdc9b2297b04b02ac2eb1e700dd9519a01de9157bca032e91208f62bf8 |
| CPL-GEA-Adapter-Rev3C.csv | 3039 | bf1676c4ed4d19dc245e8b2ab7b3205ea761c75928785bf963c37041701db1e2 |

## Quote steps

1. Open the official [JLCPCB quote page](https://cart.jlcpcb.com/quote). Choose Standard PCB/PCBA and upload only the matching Gerber ZIP with **Add gerber file**. Check the parsed board in Gerber Viewer: 4 layers and 99 × 40 mm. A displayed 40 × 99 mm detection is the same rectangle; verify outline, layer order and drills against native plots.

2. Reproduce the observed comparison settings: **FR-4 TG135, 4 layers, Single PCB, one design, 1.6 mm, green solder mask, white silkscreen, LeadFree HASL, 1 oz outer and 1 oz inner copper**. Choose PCB quantity **5 or 10**. The native export job reports 35 µm on all layers; that metadata has not established a mandatory electrical stackup. The supplier's 0.5 oz inner default was explicitly changed to 1 oz. If comparing 0.5 oz inner copper, label it as a separate option pending an evaluated design variant. LeadFree HASL is the observed quote assumption; the CAD source did not specify a finish. [Official copper guidance](https://jlcpcb.com/help/article/jlcpcb-copper-weight)

   Other observed settings: plugged vias, unspecified via-plating method, minimum via hole/diameter selection 0.3 mm/(0.4/0.45 mm), regular ±0.2 mm outline tolerance, Remove Mark and Flying Probe Fully Test. No gold fingers, castellations, press-fit, edge plating, blind slots, UL marking, backdrill or humidity card. Layer sequence and stackup were not custom-specified. [Actual PCB settings screenshot](images/ordering/five-board-pcb-settings.jpg)

3. Enable **PCB Assembly**, then choose **Economic, Top Side**, with assembled quantity equal to PCB quantity. Use **By Customer (Self-Service)** part selection. The successful quote includes J1 RJ45 and J5/J6 female module sockets. XIAO C3/C6 modules and their male headers are separate purchases. [Actual assembly settings screenshot](images/ordering/five-board-assembly-settings.jpg), [published assembly capabilities](https://jlcpcb.com/capabilities/pcb-assembly-capabilities)

4. Continue to Bill of Materials. Upload the matching **BOM** and **CPL**, verify both filenames, then click **Process BOM & CPL**. Check every reference, exact JLC part code/MPN, package, value/rating and stock. The end state must be **83 detected / 83 confirmed for the current selected package**, or **80 detected / 80 confirmed for baseline ca1fdb1**. Both quantities were independently checked against each source's frozen BOM. Duplicate-match advisories can leave matching rows initially unchecked; confirm exact matches before selecting them. Resolve any shortage explicitly. Do not silently substitute or choose **Do not place** to make the quote appear complete. [BOM format](https://jlcpcb.com/help/article/bill-of-materials-for-pcb-assembly), [CPL format](https://jlcpcb.com/help/article/pick-place-file-for-pcb-assembly)

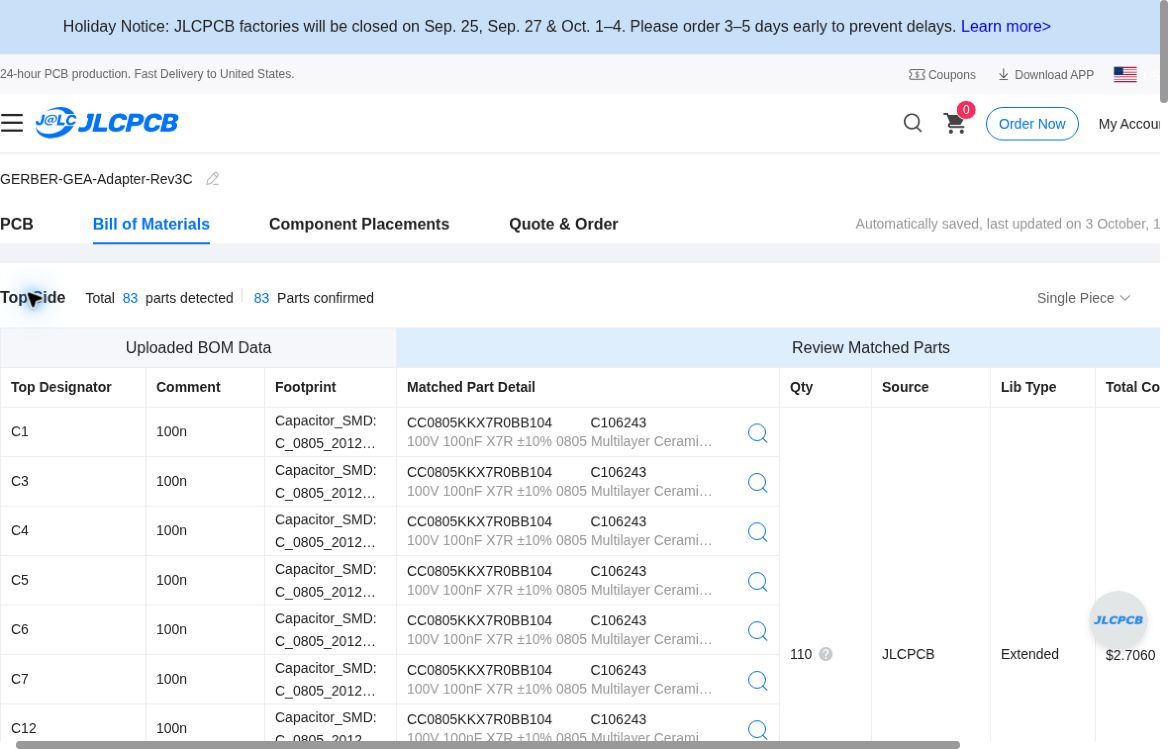
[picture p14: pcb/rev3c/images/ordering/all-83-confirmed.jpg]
Actual supplier state with all 83 references confirmed


5. Review **Component Placements** against native plots, CPL and package datasheets. Check board orientation, X/Y origin and units, Top layer, rotations, pin 1, diode/zener polarity, IC orientation, RJ45 and socket through-hole placement, and the TI exposed-pad/stencil requirements. The observed cloud preview remained “Generating PCB...” with reference placeholders; it did not provide usable 3D models. Passing to the pricing tab is not placement approval. Supplier graphics/placeholders do not establish physical fit. Native plot/CPL parity and physical assembly approval are separate checks. [Observed placement preview](images/ordering/placement-preview.jpg), [assembly review responsibilities](https://jlcpcb.com/help/article/terms-and-conditions-of-jlcpcb-assembly-service)

   Genuine KiCad 9.0.9 native ERC/DRC report zero findings; CAD/CAM parity has passed; the separately typed body-datum export requires current validation and actual supplier-library pose review. Those results do not establish electrical, functional or thermal qualification.

6. Open **Quote & Order** and record the complete PCB + PCBA total. Stop here for quote review. The supplier counts **34 unique component groups for the current selected package**, versus **33 for baseline ca1fdb1**. The placed reference counts remain **83 and 80 per board**, respectively. These quotes include exact parts with no omissions or substitutions.

## Current complete quote totals - October 5, 2026

| USD | 5 assembled carriers | 10 assembled carriers |
| --- | ---: | ---: |
| PCB | 29.81 | 36.07 |
| Economic PCBA | 106.00 | 135.13 |
| PCB + PCBA total | **135.81** | **171.20** |
| Per carrier, rounded | 27.16 | 17.12 |
| Components, included in PCBA | 35.36 | 61.00 |
| Extended-part fee, included in PCBA | 52.53 | 52.53 |

| Historical October 3 matched-source comparison, USD | 5 assembled carriers | 10 assembled carriers |
| --- | ---: | ---: |
| 80-reference baseline ca1fdb1 | **130.39** | **160.37** |
| 83-reference selected 7bb455f | **134.64** | **168.91** |
| Higher-rated option batch premium | **4.25** | **8.54** |

The baseline PCB subtotals are the same $29.81 / $36.07; its Economic PCBA subtotals are $100.58 / $124.30. All 80 exact reference/code matches were independently verified at both quantities. Original baseline and selected input-protection qualification limits remain open.

Extended-part fees are separate from component purchase cost. PCBA also includes setup, stencil, SMT assembly, hand-soldering, manual assembly and nitrogen reflow. No fixture fee/warning appeared in the final quote; engineering review may still add process charges. Prices and stock can change.

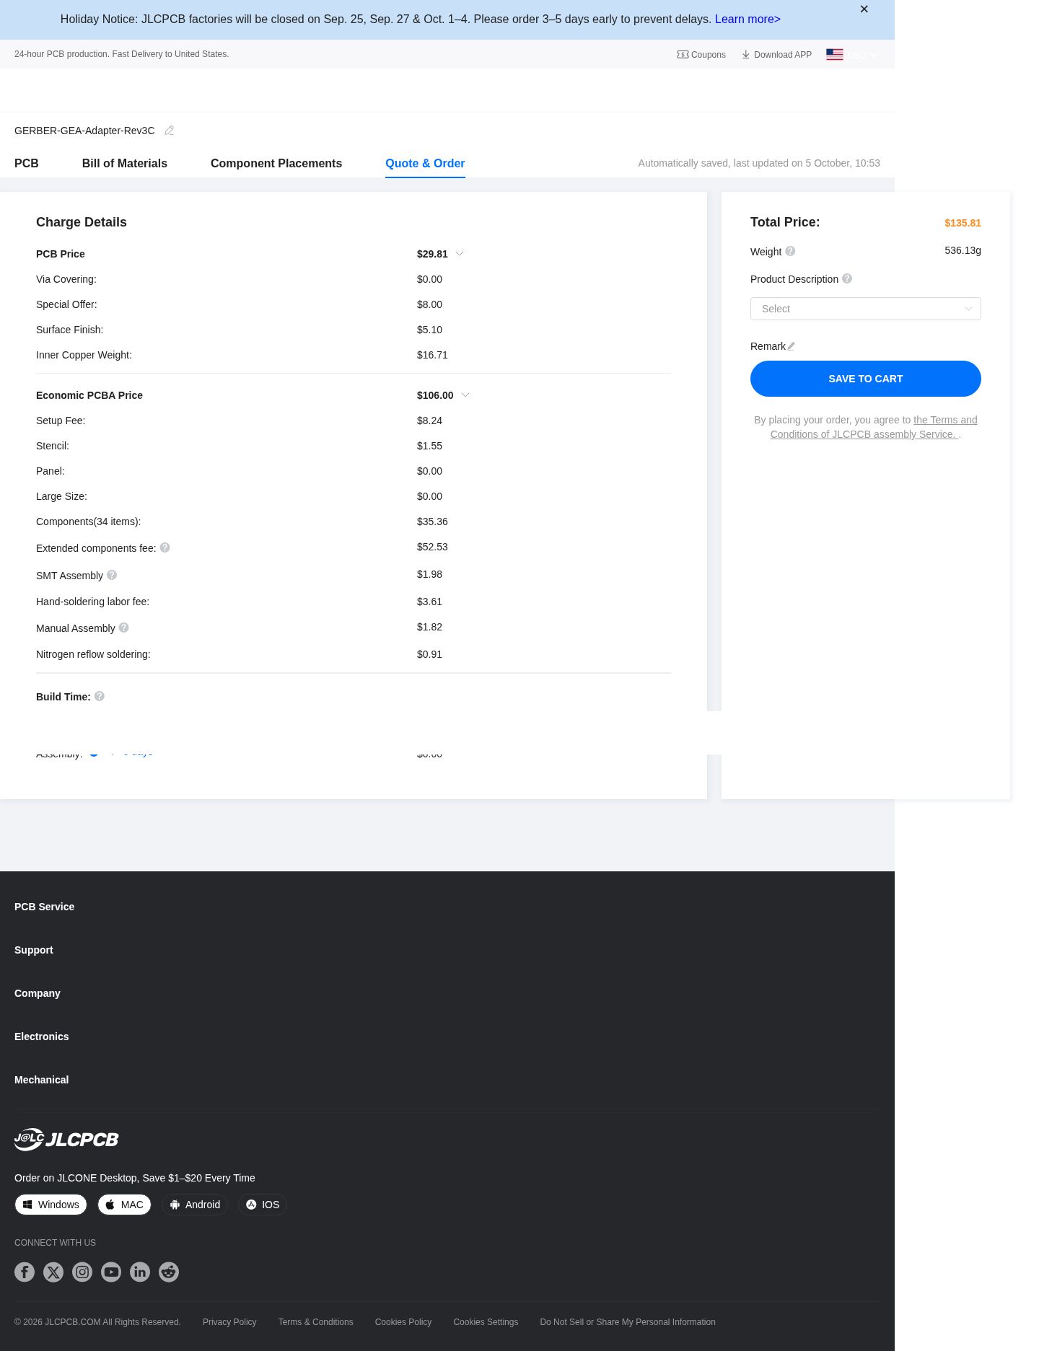
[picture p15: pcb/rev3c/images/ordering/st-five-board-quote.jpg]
Fresh complete five-carrier STPS140Z quote


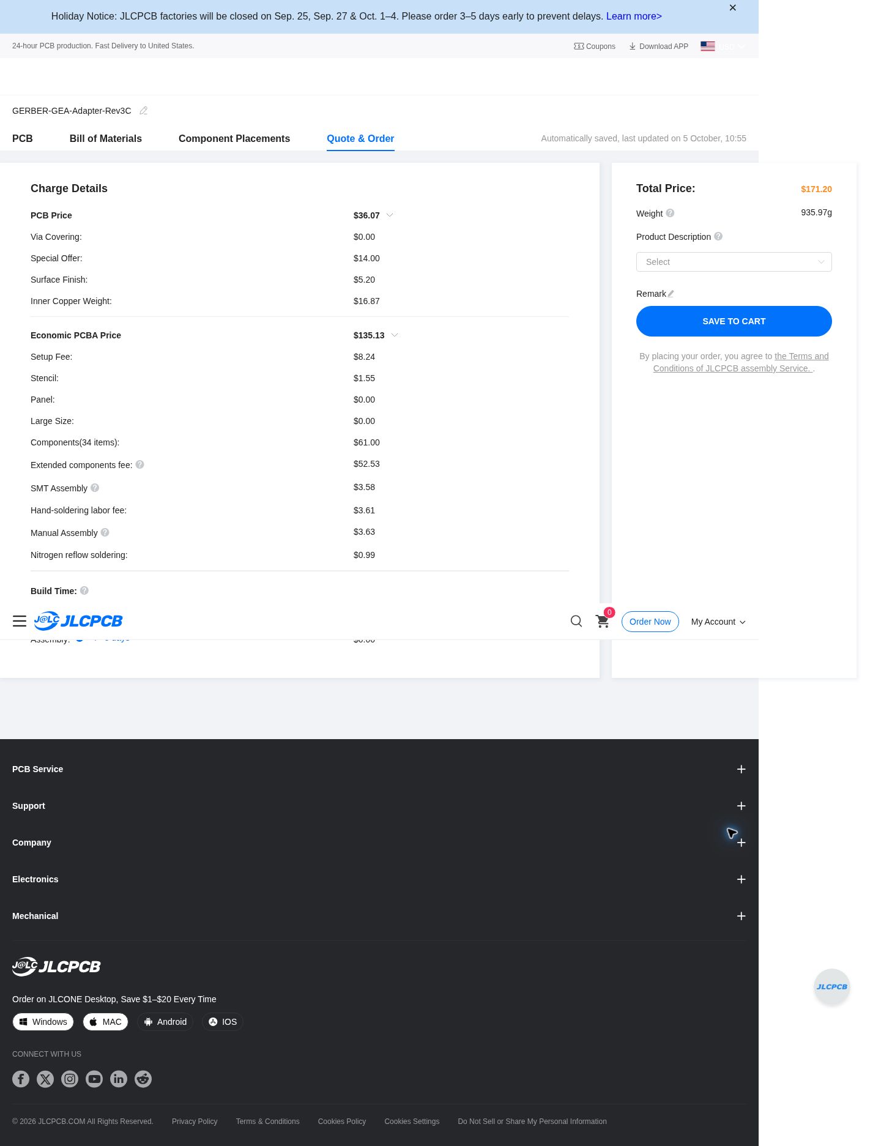
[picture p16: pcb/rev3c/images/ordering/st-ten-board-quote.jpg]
Fresh complete ten-carrier STPS140Z quote


### Historical pre-ST and baseline screenshots

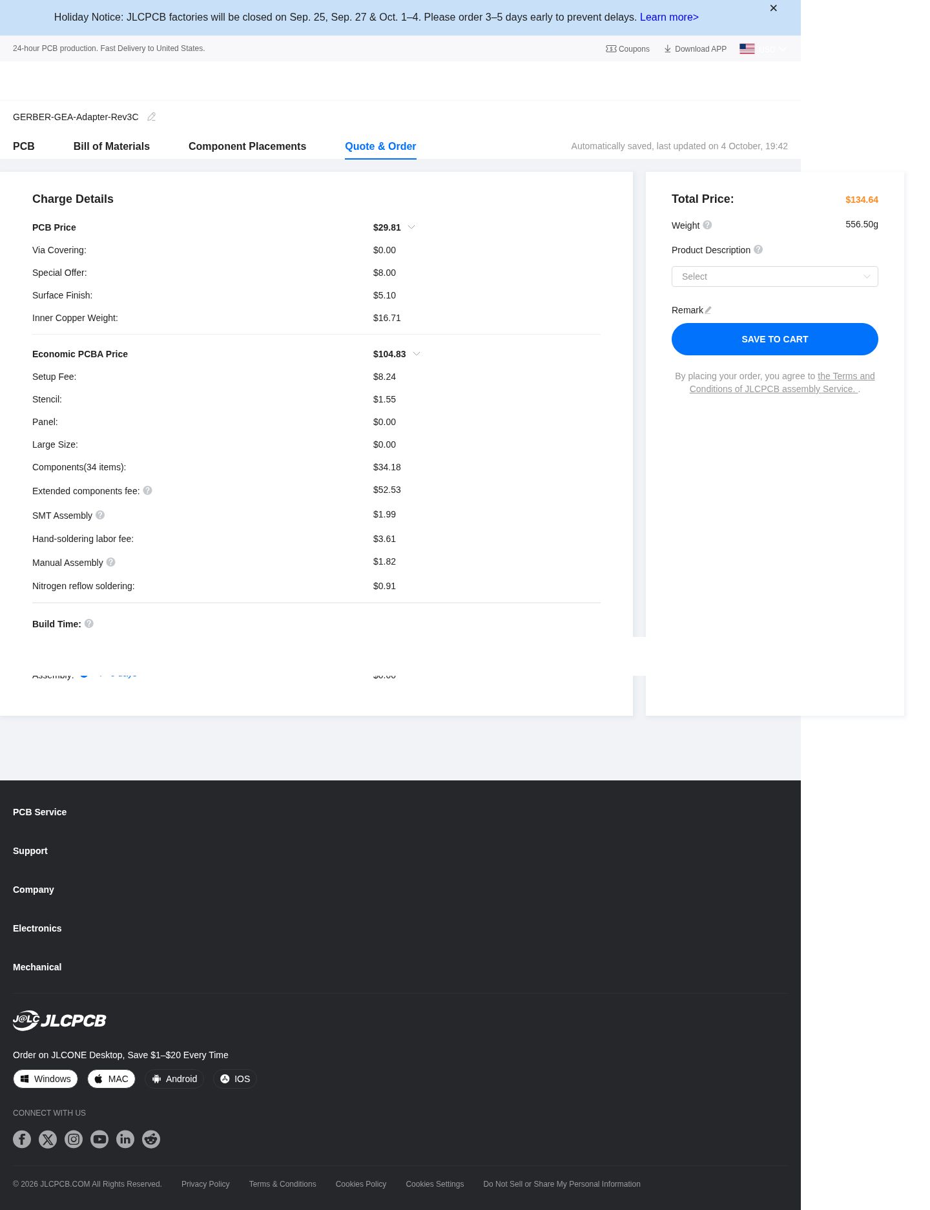
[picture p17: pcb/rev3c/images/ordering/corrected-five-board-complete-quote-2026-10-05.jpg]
Historical pre-ST complete five-carrier quote


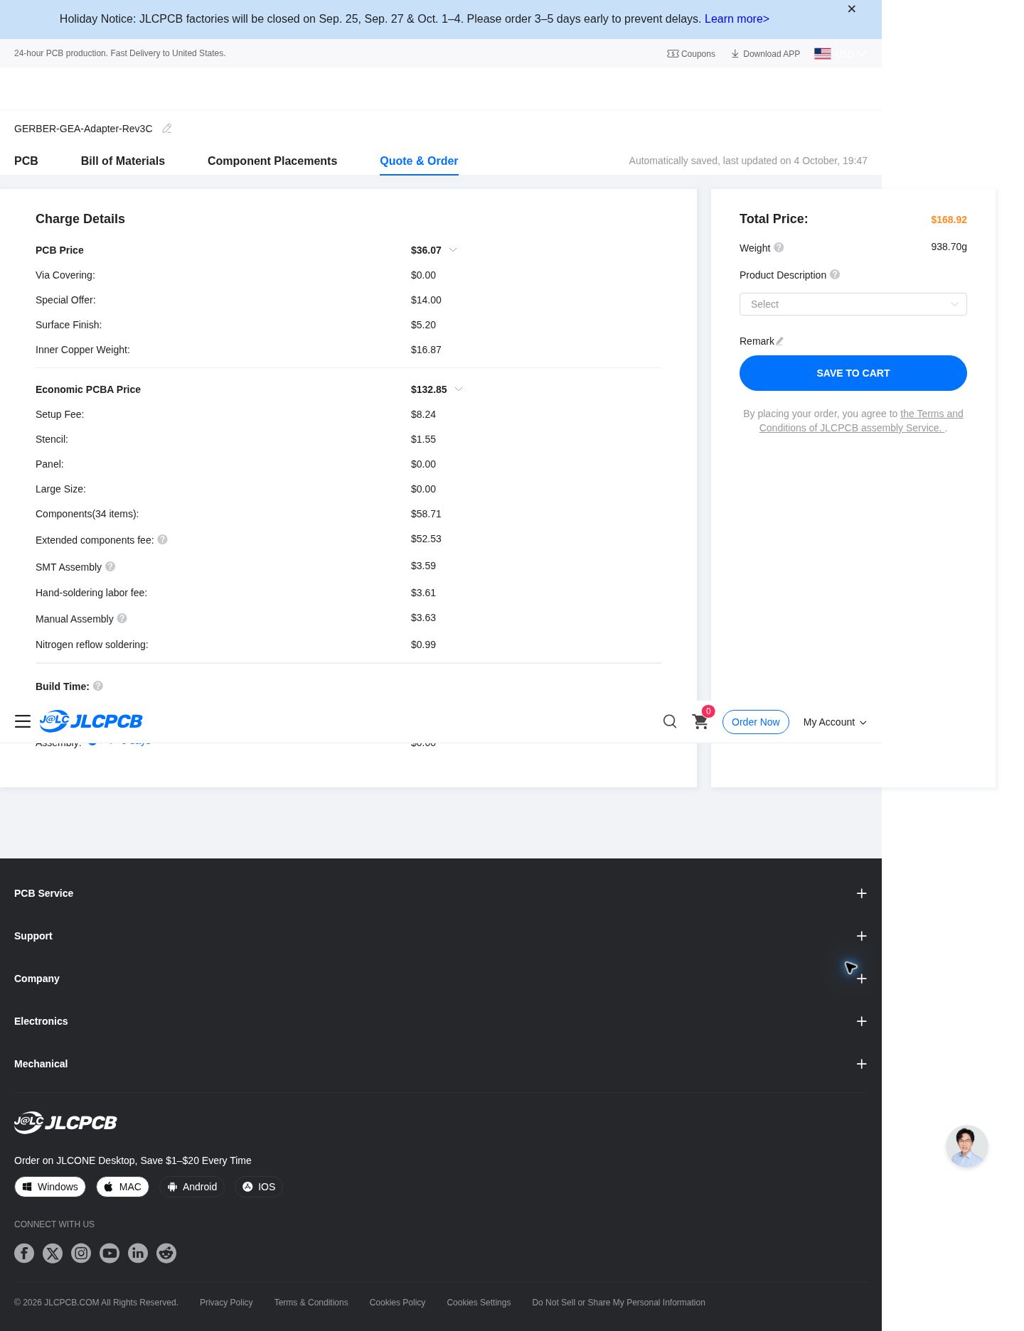
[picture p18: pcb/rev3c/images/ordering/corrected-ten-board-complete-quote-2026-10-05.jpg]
Historical pre-ST complete ten-carrier quote


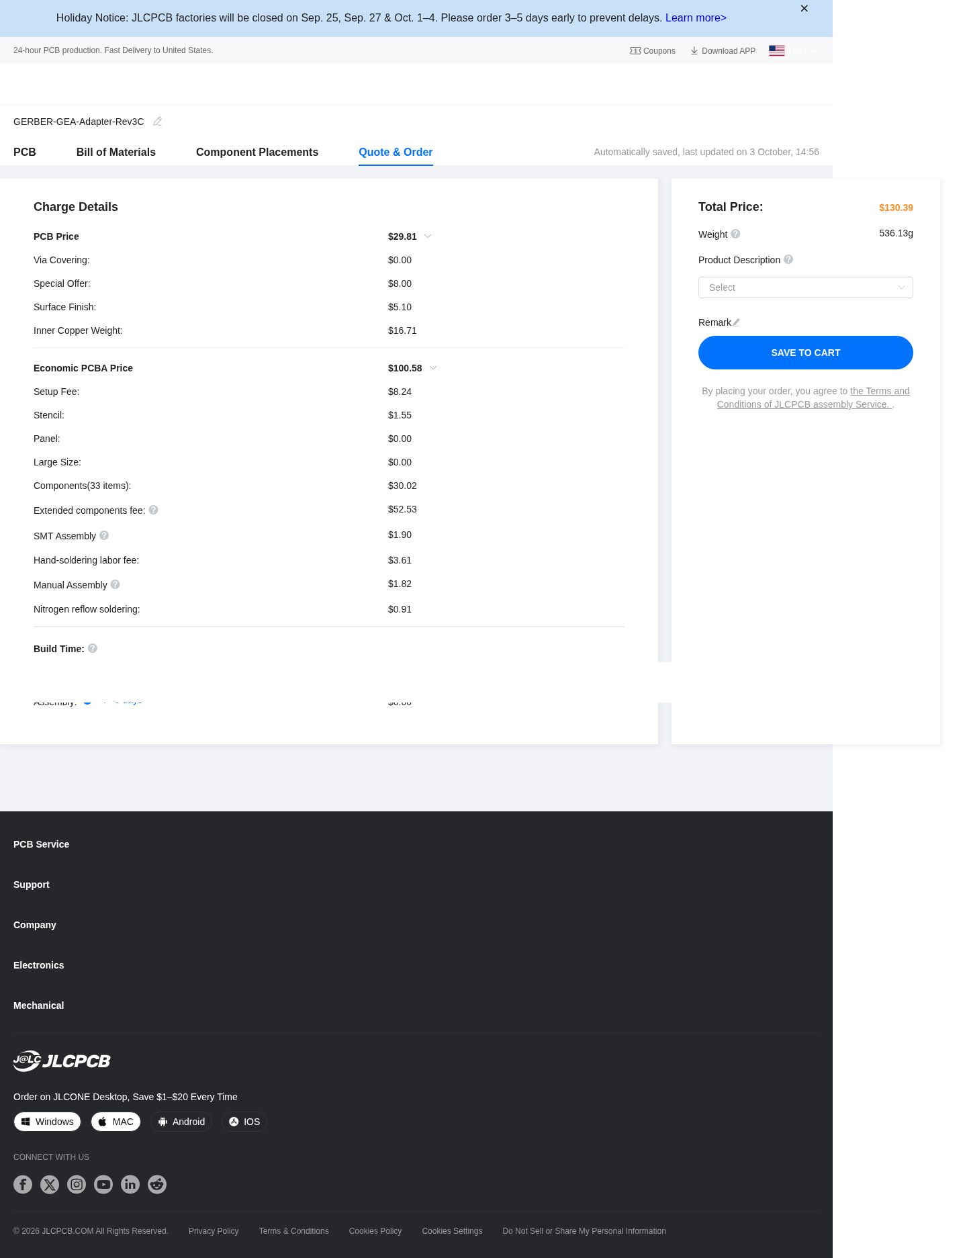
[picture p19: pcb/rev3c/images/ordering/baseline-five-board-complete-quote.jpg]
Actual complete five-carrier baseline quote


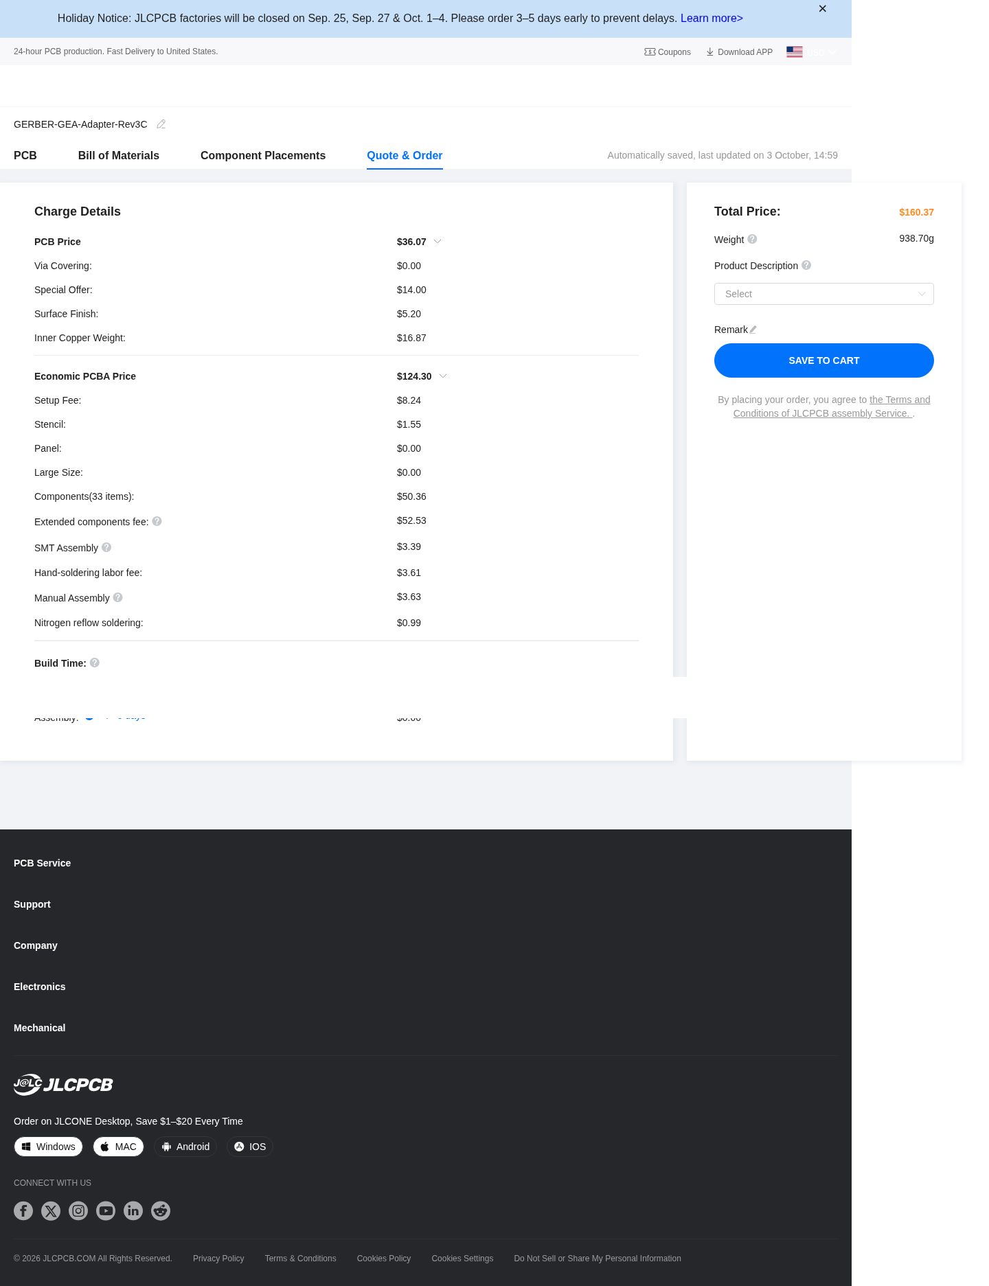
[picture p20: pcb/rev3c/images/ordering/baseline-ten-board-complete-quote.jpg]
Actual complete ten-carrier baseline quote


## Release before ordering

The observed quote defaults had **Confirm Production file = No** and **Confirm Parts Placement = No**. They are quote defaults, not recommended production sign-offs. Flying-probe PCB testing is not an assembled-board power-on or functional test. Review any required production/placement confirmation, stencil/process changes and added fees before approval.

Before ordering, close the engineering gates: actual appliance source/current/transient envelope; both input paths and priority/startup/retry behavior; voltage loss and thermal/energy bounds; PMOS differential and gate-clamp behavior; TI package/stencil process; actual module seating, USB/button access, enclosure and RF qualification. A successful quote or 40 V switch rating does not establish appliance compatibility or a 40 V board rating.

After source qualification, complete exact-part and supplier production/placement review. Refresh stock and prices, verify the final quantity and total including shipping and tax, delivery method, payment and visible cancellation/refund terms. The later **Save to Cart → item review → Secure Checkout → shipping/payment** flow was not exercised for this source. [Official PCBA ordering guide](https://jlcpcb.com/help/article/how-do-i-place-a-pcba-order)

Screenshots are unchanged captures of the official JLCPCB cloud quote sessions, inspected for account/address/payment details. They contain no entered address or payment data. The current ST-parts cost screenshots and receipt are from October 5 at 17:53/17:55 UTC and match bf5c231. The prior 02:47 screenshots are clearly historical pre-ST snapshots. Earlier settings/placement illustrations and baseline quotes remain historical October 3 captures. Stock was not reserved. The quoted build estimates are PCB 3 days plus assembly 4–5 days for five carriers, and PCB 3–4 days plus assembly 4–5 days for ten. The displayed build estimates are not delivery promises; the observed banner listed an October 1–4 factory closure. No landed shipping total has been verified.

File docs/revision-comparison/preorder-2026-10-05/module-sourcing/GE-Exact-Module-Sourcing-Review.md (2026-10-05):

# GE module sourcing and compatibility review

Reviewed **5 October 2026, 12:58–13:18 UTC**, against checkout **11826a7f6ba1ed19131ddba46e4d62b06196a8c6**. This is a public sourcing and source-CAD review. No purchasing, reservation, consignment, supplier-session change, BOM substitution, redesign or physical test was performed.

**Rev3B has an external exact-SKU sourcing route:** Seeed and DigiKey list bare XIAO ESP32C3 **113991054**. This does not clear JLCPCB's module shortage, confirm the supplied PCB revision, or qualify the soldered assembly. The distinct **101991467 tape/reel** SKU is a promising review candidate. Preheadered C3, C6 and S3 modules are not proven replacements for Rev3B's soldered 22-pad module.

## Source identity by revision

| GE revision | Actual module interface | Exact sourcing identity | Qualification boundary |
|---|---|---|---|
| Rev1.0 | U3, generic classic ESP32 development board; 38 PTH positions, two 19-pin rows at **2.54 mm pitch / 22.86 mm row spacing** | No manufacturer, MPN or purchased module revision established | Keep identity unresolved. A classic ESP32 firmware target does not identify a physical devboard. |
| Rev2.0 / 2.1 / 2.2 / 3 A | U2, ESP32-C3-WROOM-02; **18 edge contacts + ground pad 19**; carrier includes ground-pad vias and separate paste apertures | **ESP32-C3-WROOM-02-N4 / C2934560**; Rev2.0 purchasing code is also preserved in Description | Exact N4 procurement is preferable to changing chip/module family. |
| Rev3B | U2, **XIAO ESP32-C3 v1.3**, custom **22-contact SMD** land pattern; EN and ground underneath are wired | **Seeed113991054 / C18212168** | Require bare, header-free module, correct revision/contact layout and approved assembly process. |
| Rev3C | J5/J6, two HCTL PM254-1-07-Z-8.5 female sockets; **all 14 side pins** | Separately installed XIAO C3 **113991054** or C6 **113991254** | Modules and male headers are excluded from carrier quotes. Installed height, header engagement, USB/buttons and RF remain physical checks. |

All numbered carrier contacts, coordinates, functions and nets are in [carrier-module-pads.csv](carrier-module-pads.csv). The WROOM footprint contains 40 KiCad pad primitives because ground-pad vias and nine unnumbered paste apertures share the physical package; it has 19 numbered electrical contacts, not 40 module pins.

## Public availability, separated by inventory owner

Prices are USD per unit unless specified. These are inspected public observations, not allocation or fulfillment commitments. Crawl age is preserved because opening a page does not guarantee fresh inventory.

| Part / inventory owner | Public observation | Evidence age | Source |
|---|---|---|---|
| C3 **113991054**, Seeed | In stock, **$4.90**, count not exposed | Today | [Manufacturer](https://www.seeedstudio.com/Seeed-XIAO-ESP32C3-p-5431.html) |
| C3 **113991054**, DigiKey US | **9,888**, **$5.25**; headers not installed; U.FL antenna included | Today | [Exact manufacturer number](https://www.digikey.com/en/products/detail/seeed-technology-co-ltd/113991054/16652880) |
| C3 **C18212168**, LCSC | **Out of Stock** on canonical page; older 42–64-unit views conflict | Today; conflicting views 2–4 weeks old | [LCSC](https://www.lcsc.com/product-detail/C18212168.html) |
| C3 **C18212168**, JLCPCB | Exact Extended/SMT catalog listing; present orderable quantity unverified in public text | Last month | [JLC catalog](https://jlcpcb.com/partdetail/SEEED_DEVELOPMENTLTD-113991054/C18212168) |
| C3 **101991467**, Seeed tape/reel | In stock, **$4.49**, **10+ $4.20**, count not exposed | Today | [Manufacturer](https://www.seeedstudio.com/Seeed-Studio-XIAO-ESP32C3-Tape-Reel-p-6471.html) |
| C3 **102010633**, Seeed pre-soldered | In stock, **$5.90**, count not exposed | Today | [Manufacturer](https://www.seeedstudio.com/Seeed-Studio-XIAO-ESP32C3-Pre-Soldered-p-6331.html) |
| WROOM **N4**, Espressif | Exact manufacturer listing and distributor links; manufacturer stock not published | Today | [Manufacturer](https://www.espressif.com/en/products/modules/esp32-c3) |
| WROOM **C2934560**, LCSC | **4,369**, **$3.3224**;10-unit tier **$2.9217** | Today | [LCSC](https://www.lcsc.com/product-detail/C2934560.html) |
| WROOM **N4**, DigiKey US / Mouser US | **5,185 / 8,238**, **$3.38 / $3.64** |3 / 4 days old | [DigiKey](https://www.digikey.com/en/products/detail/espressif-systems/ESP32-C3-WROOM-02-N4/14553036), [Mouser](https://www.mouser.com/en/ProductDetail/Espressif-Systems/ESP32-C3-WROOM-02-N4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) |
| WROOM **C2934560**, JLCPCB | Exact listing; current public quantity unverified. Cached 6,055 stock / 5,167 available is historical | Yesterday listing; counts 3 weeks old | [JLC catalog](https://jlcpcb.com/partdetail/ESP32-C3-WROOM-02-N4/C2934560) |
| C6 **113991254**, Seeed / DigiKey US | Seeed In stock **$5.20**; DigiKey **229 at $5.38**, headers not installed; external antenna not included | Today | [Seeed](https://www.seeedstudio.com/Seeed-Studio-XIAO-ESP32C6-p-5884.html), [DigiKey](https://www.digikey.com/en/products/detail/seeed-technology-co-ltd/113991254/24613066) |

Seeed itself [names DigiKey, Mouser and Arrow as distributors](https://www.seeedstudio.com/blog/distribution-service/). Espressif's module page provides DigiKey/Mouser purchasing links. Loose-board inventory cannot be transferred into a JLC assembly quote by assumption. Complete A/C quote evidence and B's previous shortage remain separate supplier observations. This pass did not refresh an authenticated quote.

Full stock/cache conflicts, packaging and price limits: [availability evidence](public-stock/module-availability-2026-10-05.json). **113991355 is unidentified**; it must not be treated as a verified C3 preheader SKU. Seeed's [packaging PCN](https://files.seeedstudio.com/wiki/Seeeduino-XIAO/res/PCN-XIAO_Series_Packaging_Upgrade.pdf) independently identifies preheadered C3 as 102010633 and C6 as 102010636.

## Screened alternatives

“Exact sourcing” means the same manufacturer identity from another seller, with lot/assembly checks still required. “Proven drop-in” would require the complete electrical, physical and firmware replacement case. No different module SKU is assigned that full classification here.

| Candidate | Target | Classification | Evidence and remaining difference |
|---|---|---|---|
| Bare **113991054** from Seeed/DigiKey | Rev3B | **Exact sourcing**, conditional on v1.3 lot | Same SKU; current official C3 SMD library matches all 22 carrier-library pads. Store SKU alone does not specify supplied hardware revision, reflow history or shipment format. |
| **101991467**, C3 tape/reel | Rev3B | **Review candidate** | Manufacturer's [20 September2026 datasheet](https://files.seeedstudio.com/Bazaar/product_pdf/101991467.pdf) describes a single-sided SMD C3 with no through-hole headers. Different SKU: verify all 22 contacts/lot revision, antenna bundle, feeder/reflow data and assembly-library eligibility. |
| **102010633**, C3 preheadered | Rev3B / Rev3C | **Redesign or different assembly approach for B; header-fit review for C** | Installed pins prevent the intended flat soldered22-pad seating. C's two sockets are the appropriate interface concept, but pin length/section, mating depth and installed height need measurement/drawings. |
| Earlier C3 v1.0/1.1/1.2 under base SKU | Rev3B | **Review candidate** | Current vendor revision history records charger, SoC and crystal/component changes. v1.2 mechanical drawing supports nominal side/header and underside locations; it does not certify every earlier revision or actual supplied lot. |
| **113991254**, XIAO C6 | Rev3B / Rev3C | **Redesign/requalification for B; as-designed module option for C** |24 SMD contacts; different hidden battery/BOOT pads and side GPIOs. C already has separate C6 firmware and consumes only14 side contacts. Its module buttons/USB provide the download controls. |
| **113991114**, XIAO S3; Sense/Plus variants | Rev3B / Rev3C | **Redesign/requalification** | S3 has25 SMD contacts, different GPIOs/boot pin, memory, power and firmware target. Sense/Plus add contacts/components; no reviewed GE S3 profile. Shared XIAO outline is insufficient. |
| **ESP32-C3-WROOM-02-H4** | Rev2.x /3 A | **Review candidate; package/pin compatibility established** | Same 19-pin definition, 18×20×3.2 mm package and 4 MB flash in manufacturer's common datasheet; ambient rating changes 85→105 °C. No complete assembled-system substitution test performed. |
| **ESP32-C3-WROOM-02-N8** | Rev2.x /3 A | **Review candidate; package/pin compatibility established** | Same package/pins; 4→8 MB flash requires firmware/partition and sourcing review. |
| **ESP32-C3-WROOM-02U-N4** | Rev2.x /3 A | **Review candidate with RF/mechanical changes** | Same pin functions but18×14.3×3.2 mm body; U.FL-compatible external antenna connector replaces PCB antenna. Cable, antenna/connector clearance and appropriate land-pattern placement need review. Antenna is not supplied by default. |
| **ESP32-C3-MINI-1-N4X / MINI-1U-N4X**, bare C3 SoC, generic C3 devboard | Any current interface | **Redesign** | Different lands/pin numbering and body. MINI-1 uses 53 numbered lands and 13.2×16.6×2.4 mm body; the U version is shorter. No XIAO regulator, USB connector or buttons on bare radio modules. |
| Official **ESP32-DevKitC V4**, WROOM version | Rev1 | **Redesign / incompatible physical rows** | [Official drawing](https://dl.espressif.com/dl/schematics/esp32_devkitc_v4_dimensions.pdf) gives25.40 mm header rows versus source 22.86 mm. WROVER versions also reserve GPIO16/17 used by Rev1. No exact Rev1 devboard replacement established. |

WROOM variant facts come from the [Espressif common datasheet v1.7](https://www.espressif.com/sites/default/files/documentation/esp32-c3-wroom-02_datasheet_en.pdf), §§1.2,3,10,11. MINI facts: [manufacturer datasheet](https://documentation.espressif.com/esp32-c3-mini-1_datasheet_en.html). DevKitC variants: [official guide](https://docs.espressif.com/projects/esp-dev-kits/en/latest/esp32/esp32-devkitc/user_guide.html).

## All XIAO side pins and hidden contacts

Numbers below are **module SMD-library pad numbers**, not MCU package pins. Source: Seeed's [official footprint/symbol collection](https://github.com/Seeed-Studio/OSHW-XIAO-Series/tree/main/Seeed%20Studio%20XIAO%20Series%20Library), plus current [C3](https://files.seeedstudio.com/wiki/XIAO_WiFi/Resources/XIAO_ESP32C3_v1.3_SCH_260116.pdf), [C6](https://files.seeedstudio.com/wiki/SeeedStudio-XIAO-ESP32C6/XIAO_ESP32_C6_v1.0_SCH_260114.pdf) and [S3](https://wiki.seeedstudio.com/xiao_esp32s3_getting_started/) manufacturer documentation. Underneath-pad numbering is variant-specific.

| Pad / label | C3 GPIO | C6 GPIO | S3 GPIO | GE side-interface function |
|---|---:|---:|---:|---|
|1 D0|2|0|1|Red/debug LED|
|2 D1|3|1|2|Green LED|
|3 D2|4|2|3|Yellow LED|
|4 D3|5|21|4|GEA2 MCU TX|
|5 D4|6|22|5|Unused side pin|
|6 D5|7|23|6|Unused side pin|
|7 D6|21|16|43|GEA3 MCU TX, carrier net GEA3_RX|
|8 D7|20|17|44|GEA3 MCU RX, carrier net GEA3_TX|
|9 D8|8|19|7|Carrier BOOT_SEL|
|10 D9|9 /BOOT|20|8|Carrier BOOT; actual BOOT only on C3|
|11 D10|10|18|9|GEA2 MCU RX|
|12 3V3_OUT|Regulator output|Regulator output|Regulator output|Carrier3.3 V rail|
|13 GND|Ground|Ground|Ground|Ground|
|14 VBUS|USB VBUS /5 V|USB VBUS /5 V|USB VBUS /5 V|Carrier5 V rail|

| Hidden pad number | C3 22-pad | C6 24-pad | S3 25-pad |
|---|---|---|---|
|15|D3/GPIO5/MTDI|GPIO5/MTDI|GPIO41/MTDI|
|16|D5/GPIO7/MTDO|GPIO7/MTDO|GPIO40/MTDO|
|17|EN|EN|EN|
|18|GND|GND|GND|
|19|D2/GPIO4/MTMS|GPIO4/MTMS|GPIO42/MTMS|
|20|D4/GPIO6/MTCK|GPIO6/MTCK|GPIO39/MTCK|
|21|VBAT|GPIO9/BOOT|USB DN|
|22|GND|3V3_OUT|USB DP|
|23|Absent|VBAT|VBAT|
|24|Absent|GND|GND|
|25|Absent|Absent|PAD; electrical meaning must be checked against exact source/variant|

Rev3B wires underside pad 17 to EN and pads 18/22 to GND; underside pads 15/16/19/20/21 are unconnected carrier lands. **Pad numbers do not establish geometric overlap:** C6's battery lands 23/24 are at different positions from C3's 21/22. Same-number comparison found 14 exact C6 pad geometries, 8 different and 2 extra; S3 found 20 same, 2 different and 3 extra. This is geometry evidence, not proof of compatible net function.

Rev3B's local C3 library and the current vendor C3 library match **all 22** normalized number/type/shape/position/size/layer definitions. Side SMD land centers span16.165 mm with 2.54 mm pitch. The actual module's male-header holes use 15.24 mm row spacing; Rev3C sockets are also 15.24 mm apart. These are different mating interfaces. The [v1.2 underside drawing](https://files.seeedstudio.com/wiki/Seeed-Studio-XIAO-ESP32/XIAO_ESP32C3_v1.2_Dimensioning.zip) also shows unnumbered 2.794 mm ground/thermal copper. It is not an invented 23rd contact in Rev3B's official 22-pad footprint; inspect the actual underside and process clearances.

Detailed coordinate/size differences: [land-pattern-comparison.json](land-pattern-comparison.json). Manufacturer module contacts and carrier placement: [module-pad-evidence.json](module-pad-evidence.json).

## WROOM contacts, physical features and firmware

WROOM-02 N4, H4 and N8 share these pin functions: **1=3V3,2=EN,3=IO4,4=IO5,5=IO6,6=IO7,7=IO8,8=IO9,9=GND,10=IO10,11=IO20/RXD,12=IO21/TXD,13=IO18/USB DN,14=IO19/USB DP,15=IO3,16=IO2,17=IO1,18=IO0,19=GND exposed pad**. There is no onboard USB socket, regulator, charger, header or pushbutton; the carrier supplies these functions. Supply is 3.0–3.6 V, not 5 V. The 19-pad interface differs completely from a XIAO module, despite the shared C3 processor.

| Feature | XIAO C3 v1.3 | XIAO C6 v1.0 | XIAO S3 base | WROOM-02-N4 |
|---|---|---|---|---|
|Nominal body|21×17.8 mm|21×17.8 mm|21×17.8 mm|18×20×3.2 mm|
|Flash / PSRAM|4 MB / none|4 MB / none|8 MB / 8 MB|4 MB / none|
|USB /buttons|Onboard USB-C, native Serial/JTAG; EN andGPIO9 boot|Onboard USB-C, native Serial/JTAG; EN andGPIO9 boot|Onboard USB-C; EN andGPIO0 boot|Chip USB pins only; external EN/boot controls|
|RF /U.FL|External antenna required; module U.FL, retail antenna included|Onboard ceramic antenna or U.FL; RF switch GPIO3 low enables, GPIO14 selects antenna|External U.FL antenna; Sense adds camera/mic/SD, Plus differs further|PCB antenna;02U instead uses external connector|
|Power conversion|5 V VBUS input, TLV75733 LDO; underside battery/charger circuitry|5 V VBUS input, SGM6029 buck; distinct battery/charger circuitry|5 V VBUS / battery circuitry; load and regulator differ|Carrier-regulated3.3 V input|
|Headers|Base SKU bare;102010633 installed;101991467 tape/reel|Base113991254 bare;102010636 installed|Base113991114 bare;102010634 installed|No14-pin XIAO headers|

Both reviewed XIAO C3/C6 tie side VBUS to USB VBUS; using a different purchase package does not add isolation. The module 3V3 pin is treated as an output in the reviewed GE design. Module-store sleep-current figures do not qualify appliance startup or Wi-Fi burst current.

Firmware evidence was inspected rather than rebuilt in this sourcing pass. Rev2.x reference configurations target C3 and use GEA2 GPIO5/10 and GEA3 GPIO21/20. Rev3C has distinct C3 and C6 profiles: C6 uses GEA2 GPIO21/18 and GEA3 GPIO16/17, plus GPIO3/GPIO14 RF-switch control. These profiles demonstrate deliberate GPIO/target differences; they do not authorize loading a C6 image onto a soldered C3 carrier. Rev1 uses its separate classic ESP32 profile family. There is no reviewed S3 profile. Fresh integration build status belongs to the separate firmware audit; stored build receipts are historical evidence.

## Decision and remaining checks

1. Preserve **113991054/C18212168** for Rev3B; investigate bare exact-SKU availability and supplier acceptance without silently changing the BOM. Require actual v1.3 lot identity, underside/photo or drawing confirmation, moisture/reflow handling, packaging/orientation and accepted 22-pad process before production.
2. **101991467 tape/reel** is the best screened alternate SKU for an assembly review. It has manufacturer identity and header-free SMD packaging evidence, but not a proven lot-specific substitution or JLC part-code match.
3. Preserve **ESP32-C3-WROOM-02-N4/C2934560** for Rev2.x/3 A. H4/N8/02U are review options with explicit differences, not emergency purchasing substitutions.
4. For Rev3C, purchase the chosen C3/C6 separately and verify all 14 male pins against both sockets, engagement, installed Z, button/USB access and antenna/enclosure clearance. Carrier quotes exclude this cost and labor.
5. Keep **Rev1 devboard identity open**. The named official DevKitC V4 fails the source row spacing check. A generic38-pin seller listing or classic firmware build cannot close it.

These checks supplement the existing board/appliance electrical, thermal and RF qualification gates; none is closed by public stock or native CAD checks.

## Verification record

- [input-hashes.json](input-hashes.json):54 byte-hashed source/BOM/firmware/reference files, bound to 11826a7.
- [primary-source download manifest](primary-sources/download-manifest.json): public URLs, exact byte counts, SHA-256 and UTC retrieval times. Current C3 archive hash **477bc61cec652eaeefa887cb1f97abb1514e8a61ea9659240b88be7213c3b6ff**; current C6 archive hash **cea2ed66da575e4a1dd6c7a9acd60583ed4a9adbf6b1d2952851c1e4199c05fc**.
- `extract_module_evidence.py` (original analytical helper; recorded data/formulas below): reproducible read-only extraction. Parsed all seven carrier revisions, official C3/C6 boards and three manufacturer SMD patterns; checked all 22 C3 land definitions.
- Official DevKitC dimensions, C3 package drawing and v1.2 DXF were rendered and visually inspected. The 25.40 mm versus 22.86 mm Rev1 mismatch is a drawing/CAD measurement, not a guessed retail-board size.
- Web evidence records inspection and reported crawl age separately. No stock was reserved and no current authenticated JLC quantities, landed prices or assembly acceptance were claimed.

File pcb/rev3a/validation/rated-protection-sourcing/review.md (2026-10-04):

# Rev3A rated-protection sourcing review

Generated 2026-10-04T01:54:29.310021+00:00; live public-page observations 2026-10-04 01:43–01:49 UTC. USD.

All eight exact current selections are publicly in stock in JLC. This is a selected-part sourcing check, not a complete supplier quote. The frozen A baseline has 93 fitted parts; the final source has97 fitted references,49 exact-value/full-footprint BOM groups and42 purchasing tuples. The dated observations below retain their original phase/hash; final paired BOM/CPL validation is recorded in the current manifest.

| Exact part | Current references / quantity | Original exact-code quantity + newly added sites | Package / current CAD land | JLC class; stock / orderable; MOQ | JLC USD each at 1+ | LCSC stock; MOQ / multiple; first-tier USD |
|---|---|---|---|---|---|---|
| Texas Instruments TPS1H200AQDGNRQ1 / **C2653785** | U10, U9 / 2 | 0 original + 0 added; 2 replaced sites | EMSOP-8-EP (TI DGN/HVSSOP-8 with exposed pad); OnionStraws:TPS1H200A_DGN0008K_TI_RevE | [Extended](https://jlcpcb.com/partdetail/TexasInstruments-TPS1H200AQDGNRQ1/C2653785); 12,171 / 11,985; 1 | $0.8243 | [12,171](https://www.lcsc.com/product-detail/C2653785.html); 1 / 1; $0.8335 at 1+ |
| Littelfuse 1812L075/33DR / **C151170** | F1, F2 / 2 | 0 original + 0 added; 2 replaced sites | 1812; OnionStraws:Fuse_Littelfuse_1812L_Recommended | [Extended](https://jlcpcb.com/partdetail/Littelfuse-1812L07533DR/C151170); 8,862 / 8,678; 1 | $0.1873 | [8,860](https://www.lcsc.com/product-detail/C151170.html); 5 / 5; $0.1892 at 5+ |
| MCC BZT52C12-TP / **C668891** | D16, D17 / 2 | 0 original + 0 added; 2 replaced sites | SOD-123; nominal 12 V zener; Diode_SMD:D_SOD-123 | [Extended](https://jlcpcb.com/partdetail/698950-BZT52C12TP/C668891); 48,100 / 46,946; 1 | $0.0277 | [45,980](https://www.lcsc.com/product-detail/C668891.html); 20 / 20; $0.0280 at 20+ |
| UNI-ROYAL 0603WAF3301T5E / **C22978** | R39, R40 / 2 | 0 original + 0 added; 2 replaced sites | 0603; 3.3 kΩ ±1%, 100 mW, 75 V; Resistor_SMD:R_0603_1608Metric | [Basic](https://jlcpcb.com/partdetail/23705-0603WAF3301T5E/C22978); 5,690,740 / 5,225,644; 1 | $0.0026 | [3,942,500](https://www.lcsc.com/product-detail/C22978.html); 100 / 100; $0.0026 at 100+ |
| UNI-ROYAL 0805W8F1003T5E / **C149504** | R41, R42 / 2 | 0 original + 2 added; 0 replaced sites | 0805; 100 kΩ ±1%, 125 mW, 150 V; Resistor_SMD:R_0805_2012Metric | [Basic](https://jlcpcb.com/partdetail/160838-0805W8F1003T5E/C149504); 4,203,263 / 3,812,618; 1 | $0.0059 | [2,762,200](https://www.lcsc.com/product-detail/C149504.html); 100 / 100; $0.0060 at 100+ |
| SUNMATE Elec SMF16A / **C399290** | D18, D19 / 2 | 1 original + 1 added; 0 replaced sites | SOD-123FL; 16 V standoff, 26 V clamp TVS; Diode_SMD:D_SOD-123F | [Extended](https://jlcpcb.com/partdetail/SUNMATEElec-SMF16A/C399290); 4,831 / 4,831; 1 | $0.0363 | [4,820](https://www.lcsc.com/product-detail/TVS_SUNMATE-Elec-SMF16A_C399290.html); 20 / 20; $0.0345 at 20+ |
| YAGEO CC0805KKX7R9BB105 / **C91185** | C2, C20, C21, C26 / 4 | 3 original + 1 added; 0 replaced sites | 0805; 1 µF ±10%, 50 V, X7R; Capacitor_SMD:C_0805_2012Metric | [Extended](https://jlcpcb.com/partdetail/YAGEO-CC0805KKX7R9BB105/C91185); 839,350 / 812,481; 1 | $0.0327 | [789,120](https://www.lcsc.com/product-detail/C91185.html); 20 / 20; $0.0330 at 20+ |
| UNI-ROYAL 0805W8F510JT5E / **C17738** | R33, R34 / 2 | 2 original + 0 added; 0 replaced sites | 0805; 51 Ω ±1%, 125 mW, 150 V; Resistor_SMD:R_0805_2012Metric | [Basic](https://jlcpcb.com/partdetail/18426-0805W8F510JT5E/C17738); 855,155 / 742,352; 1 | $0.0030 | [433,000](https://www.lcsc.com/product-detail/C17738.html); 100 / 100; $0.0030 at 100+ |

Against frozen A commit `d1769b25c206fe86f60e37c415d4a60da7bb8334`: U9/U10 replace TPS22810DBVR/C205990; F1/F2 replace MF-MSMF075/24-2/C208467; D16/D17 replace MBR0540-TP/C78744 (D14/D15 retain it); R39/R40 replace removed C22/C23 22 nF CT capacitors. Those replacements do not increase fitted count. R41/R42, D19 and C26 add four fitted parts. D18 already used C399290; C2/C20/C21 already used C91185; R33/R34 remain C17738.

The twelve new or changed placements total **$2.1646 per board** using the displayed JLC 1+ component prices. All eighteen placements covered by these eight codes total **$2.3050 per board** by the same arithmetic. The twelve-placement amount excludes 85 other fitted placements; the eighteen-placement amount excludes 79. Both omit order quantity breaks/attrition, assembly/setup/extended-part fees, PCB, stencil/process, shipping and tax. Neither is a purchase or assembly quote.

[Nexperia BZT52-C12X/C550251](https://www.lcsc.com/product-detail/Zener-Diodes_Nexperia-BZT52-C12X_C550251.html) still displays “Out of Stock.” It was the superseded reviewed Rev3C zener candidate, not a fitted frozen-A original or gate series resistor. No backport part retains it. The explicitly reviewed MCC C668891 choice addresses that old stock blocker.

The SMF16A supplier package label is SOD-123FL; CAD uses Diode_SMD:D_SOD-123F. This naming distinction is preserved and does not establish pad equivalence by itself. TI’s EMSOP-8-EP catalog name corresponds to its DGN/HVSSOP exposed-pad part; A uses the specific reviewed manufacturer land. Supplier footprint labels do not approve solder coverage, stencil, polarity/orientation or thermal geometry.

JLC stock and “Available Order Qty” are distinct and recorded separately. Public JLC MOQ is 1 for every reviewed code; purchase multiples were not displayed. LCSC minimums/multiples are separate distributor constraints. The LCSC SMF16A price includes the displayed 5% promotion ($0.0345 at 20+, crossed-out $0.0363). Full price tiers, timestamps, exact source quantities and draft schematic SHA-256 are in [part-review.json](part-review.json). Stock/prices fluctuate and are unreserved. No login, quote/order, supplier substitution or repository edit was performed.

A complete supplier quote must cover the final paired 97-placement A exports, all remaining part availability, assembly group/fee handling and final process/shipping/tax. This review makes no assembled-board-total, electrical qualification or physical-test claim.

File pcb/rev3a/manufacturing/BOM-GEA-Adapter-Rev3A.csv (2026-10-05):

Comment | Designator | Footprint | LCSC Part # | Manufacturer | MPN | Voltage | Tolerance | Dielectric | Rated Current | Hold Current | Forward Current | Reverse Voltage | Saturation Current | Input Range | Output Current | Quantity
1u | C2 | Capacitor_SMD:C_0805_2012Metric | C91185 | Yageo | CC0805KKX7R9BB105 |  |  |  |  |  |  |  |  |  |  | 1
100n | C5 | LegacyBoard:C5_C_0805_2012Metric | C106243 | Yageo | CC0805KKX7R0BB104 |  |  |  |  |  |  |  |  |  |  | 1
10u 50V X7R | C9 | Capacitor_SMD:C_1206_3216Metric | C303950 | FH | 1206B106K500NT | 50V |  | X7R |  |  |  |  |  |  |  | 1
100n 50V X7R | C10 | Capacitor_SMD:C_0603_1608Metric | C286510 | FH | 0603B104M500NT | 50V |  | X7R |  |  |  |  |  |  |  | 1
100n 50V X8L | C15 | Capacitor_SMD:C_0603_1608Metric | C161181 | Murata | GCM188L81H104KA57D | 50V |  | X8L |  |  |  |  |  |  |  | 1
100n | C1 | Capacitor_SMD:C_0805_2012Metric | C106243 | Yageo | CC0805KKX7R0BB104 |  |  |  |  |  |  |  |  |  |  | 1
100n | C3 | Capacitor_SMD:C_0805_2012Metric | C106243 | Yageo | CC0805KKX7R0BB104 |  |  |  |  |  |  |  |  |  |  | 1
100n | C4 | Capacitor_SMD:C_0805_2012Metric | C106243 | Yageo | CC0805KKX7R0BB104 |  |  |  |  |  |  |  |  |  |  | 1
100n | C6 | Capacitor_SMD:C_0805_2012Metric | C106243 | Yageo | CC0805KKX7R0BB104 |  |  |  |  |  |  |  |  |  |  | 1
100n | C7 | Capacitor_SMD:C_0805_2012Metric | C106243 | Yageo | CC0805KKX7R0BB104 |  |  |  |  |  |  |  |  |  |  | 1
100n | C12 | Capacitor_SMD:C_0805_2012Metric | C106243 | Yageo | CC0805KKX7R0BB104 |  |  |  |  |  |  |  |  |  |  | 1
100n | C14 | Capacitor_SMD:C_0805_2012Metric | C106243 | Yageo | CC0805KKX7R0BB104 |  |  |  |  |  |  |  |  |  |  | 1
10u 25V X5R | C11 | Capacitor_SMD:C_0805_2012Metric | C15850 | Samsung | CL21A106KAYNNNE |  |  |  |  |  |  |  |  |  |  | 1
10u 25V X5R | C13 | Capacitor_SMD:C_0805_2012Metric | C15850 | Samsung | CL21A106KAYNNNE |  |  |  |  |  |  |  |  |  |  | 1
22u 25V X7R | C16 | Capacitor_SMD:C_1210_3225Metric | C309062 | Samsung Electro-Mechanics | CL32B226KAJNNNE | 25V | 10% | X7R |  |  |  |  |  |  |  | 1
22u 25V X7R | C17 | Capacitor_SMD:C_1210_3225Metric | C309062 | Samsung Electro-Mechanics | CL32B226KAJNNNE | 25V | 10% | X7R |  |  |  |  |  |  |  | 1
100pF | C18 | Capacitor_SMD:C_0402_1005Metric | C1546 | FH | 0402CG101J500NT |  |  |  |  |  |  |  |  |  |  | 1
100pF | C19 | Capacitor_SMD:C_0402_1005Metric | C1546 | FH | 0402CG101J500NT |  |  |  |  |  |  |  |  |  |  | 1
1u 50V X7R | C20 | Capacitor_SMD:C_0805_2012Metric | C91185 | Yageo | CC0805KKX7R9BB105 |  |  |  |  |  |  |  |  |  |  | 1
1u 50V X7R | C21 | Capacitor_SMD:C_0805_2012Metric | C91185 | Yageo | CC0805KKX7R9BB105 |  |  |  |  |  |  |  |  |  |  | 1
1u 50V X7R | C26 | Capacitor_SMD:C_0805_2012Metric | C91185 | Yageo | CC0805KKX7R9BB105 |  |  |  |  |  |  |  |  |  |  | 1
100nF | C24 | Capacitor_SMD:C_0805_2012Metric | C106243 | Yageo | CC0805KKX7R0BB104 |  |  |  |  |  |  |  |  |  |  | 1
100nF | C25 | Capacitor_SMD:C_0805_2012Metric | C106243 | Yageo | CC0805KKX7R0BB104 |  |  |  |  |  |  |  |  |  |  | 1
BAV99 | D2 | LegacyBoard:D2_SOT-23 | C2500 | Nexperia | BAV99,215 |  |  |  |  |  |  |  |  |  |  | 1
GRN | D4 | LED_SMD:LED_0805_2012Metric | C2297 | Hubei KENTO Elec | KT-0805G |  |  |  |  |  |  |  |  |  |  | 1
RED | D5 | LED_SMD:LED_0805_2012Metric | C84256 | Foshan NationStar Optoelectronics | NCD0805R1 |  |  |  |  |  |  |  |  |  |  | 1
YLW | D6 | LED_SMD:LED_0805_2012Metric | C2296 | Hubei KENTO Elec | KT-0805Y |  |  |  |  |  |  |  |  |  |  | 1
BAV99 | D1 | Package_TO_SOT_SMD:SOT-23 | C2500 | Nexperia | BAV99,215 |  |  |  |  |  |  |  |  |  |  | 1
BAV99 | D3 | Package_TO_SOT_SMD:SOT-23 | C2500 | Nexperia | BAV99,215 |  |  |  |  |  |  |  |  |  |  | 1
BAV99 | D9 | Package_TO_SOT_SMD:SOT-23 | C2500 | Nexperia | BAV99,215 |  |  |  |  |  |  |  |  |  |  | 1
PMEG2010ER | D10 | Diode_SMD:Nexperia_CFP3_SOD-123W | C82288 | Nexperia | PMEG2010ER,115 |  |  |  |  |  | 1A | 20V |  |  |  | 1
PMEG2010ER | D11 | Diode_SMD:Nexperia_CFP3_SOD-123W | C82288 | Nexperia | PMEG2010ER,115 |  |  |  |  |  | 1A | 20V |  |  |  | 1
STPS140Z | D14 | Diode_SMD:D_SOD-123 | C155662 | STMicroelectronics | STPS140Z |  |  |  |  |  |  |  |  |  |  | 1
STPS140Z | D15 | Diode_SMD:D_SOD-123 | C155662 | STMicroelectronics | STPS140Z |  |  |  |  |  |  |  |  |  |  | 1
BZT52C12-TP | D16 | Diode_SMD:D_SOD-123 | C668891 | MCC | BZT52C12-TP |  |  |  |  |  |  |  |  |  |  | 1
BZT52C12-TP | D17 | Diode_SMD:D_SOD-123 | C668891 | MCC | BZT52C12-TP |  |  |  |  |  |  |  |  |  |  | 1
SMF16A | D18 | Diode_SMD:D_SOD-123F | C399290 | SUNMATE Elec | SMF16A |  |  |  |  |  |  |  |  |  |  | 1
SMF16A | D19 | Diode_SMD:D_SOD-123F | C399290 | SUNMATE Elec | SMF16A |  |  |  |  |  |  |  |  |  |  | 1
500mA | F3 | Fuse:Fuse_1206_3216Metric | C163512 | Littelfuse | 1206L050YR |  |  |  |  | 500mA |  |  |  |  |  | 1
1812L075/33DR | F1 | OnionStraws:Fuse_Littelfuse_1812L_Recommended | C151170 | Littelfuse | 1812L075/33DR |  |  |  |  |  |  |  |  |  |  | 1
1812L075/33DR | F2 | OnionStraws:Fuse_Littelfuse_1812L_Recommended | C151170 | Littelfuse | 1812L075/33DR |  |  |  |  |  |  |  |  |  |  | 1
8P8C | J1 | OnionStraws:RJ45_EVERCOM_5301-8P8C_Horizontal | C3097717 | EVERCOM | 5301-8P8C |  |  |  |  |  |  |  |  |  |  | 1
RECOVERY | J2 | OnionStraws:Recovery_Header_2x3_P2.54mm_Vertical | C42391552 | hanxia | HX PZ-2.54-02-03-S-PB3.2 |  |  |  |  |  |  |  |  |  |  | 1
USB_C_Receptacle_USB2.0_16P | J4 | OnionStraws:USB_C_SHOU_HAN_TYPE_C_16PIN_2MD_073_Reviewed | C2765186 | SHOU HAN | TYPE-C 16PIN 2MD(073) |  |  |  |  |  |  |  |  |  |  | 1
4.7uH | L1 | Inductor_SMD:L_Panasonic_PCC-M0530M | C412309 | Panasonic Industry | ETQP3M4R7KVP |  |  |  | 3.4A |  |  |  | 6.7A |  |  | 1
MMBT3904 | Q5 | Package_TO_SOT_SMD:SOT-23 | C20526 | Jiangsu Changjing | MMBT3904 |  |  |  |  |  |  |  |  |  |  | 1
CJ3407 | Q3 | Package_TO_SOT_SMD:SOT-23 | C15903 | Jiangsu Changjing | CJ3407 |  |  |  |  |  |  |  |  |  |  | 1
CJ3407 | Q4 | Package_TO_SOT_SMD:SOT-23 | C15903 | Jiangsu Changjing | CJ3407 |  |  |  |  |  |  |  |  |  |  | 1
4K7 | R22 | Resistor_SMD:R_0805_2012Metric | C17673 | UNI-ROYAL | 0805W8F4701T5E |  |  |  |  |  |  |  |  |  |  | 1
10K | R1 | Resistor_SMD:R_0805_2012Metric | C17414 | UNI-ROYAL | 0805W8F1002T5E |  |  |  |  |  |  |  |  |  |  | 1
10K | R2 | Resistor_SMD:R_0805_2012Metric | C17414 | UNI-ROYAL | 0805W8F1002T5E |  |  |  |  |  |  |  |  |  |  | 1
10K | R3 | Resistor_SMD:R_0805_2012Metric | C17414 | UNI-ROYAL | 0805W8F1002T5E |  |  |  |  |  |  |  |  |  |  | 1
10K | R5 | Resistor_SMD:R_0805_2012Metric | C17414 | UNI-ROYAL | 0805W8F1002T5E |  |  |  |  |  |  |  |  |  |  | 1
10K | R14 | Resistor_SMD:R_0805_2012Metric | C17414 | UNI-ROYAL | 0805W8F1002T5E |  |  |  |  |  |  |  |  |  |  | 1
10K | R15 | Resistor_SMD:R_0805_2012Metric | C17414 | UNI-ROYAL | 0805W8F1002T5E |  |  |  |  |  |  |  |  |  |  | 1
10K | R16 | Resistor_SMD:R_0805_2012Metric | C17414 | UNI-ROYAL | 0805W8F1002T5E |  |  |  |  |  |  |  |  |  |  | 1
10K | R17 | Resistor_SMD:R_0805_2012Metric | C17414 | UNI-ROYAL | 0805W8F1002T5E |  |  |  |  |  |  |  |  |  |  | 1
10K | R19 | Resistor_SMD:R_0805_2012Metric | C17414 | UNI-ROYAL | 0805W8F1002T5E |  |  |  |  |  |  |  |  |  |  | 1
10K | R20 | Resistor_SMD:R_0805_2012Metric | C17414 | UNI-ROYAL | 0805W8F1002T5E |  |  |  |  |  |  |  |  |  |  | 1
1K | R10 | Resistor_SMD:R_0805_2012Metric | C17513 | UNI-ROYAL | 0805W8F1001T5E |  |  |  |  |  |  |  |  |  |  | 1
1K | R11 | Resistor_SMD:R_0805_2012Metric | C17513 | UNI-ROYAL | 0805W8F1001T5E |  |  |  |  |  |  |  |  |  |  | 1
1K | R12 | Resistor_SMD:R_0805_2012Metric | C17513 | UNI-ROYAL | 0805W8F1001T5E |  |  |  |  |  |  |  |  |  |  | 1
1K | R13 | Resistor_SMD:R_0805_2012Metric | C17513 | UNI-ROYAL | 0805W8F1001T5E |  |  |  |  |  |  |  |  |  |  | 1
1K | R23 | Resistor_SMD:R_0805_2012Metric | C17513 | UNI-ROYAL | 0805W8F1001T5E |  |  |  |  |  |  |  |  |  |  | 1
1K | R24 | Resistor_SMD:R_0805_2012Metric | C17513 | UNI-ROYAL | 0805W8F1001T5E |  |  |  |  |  |  |  |  |  |  | 1
1K | R25 | Resistor_SMD:R_0805_2012Metric | C17513 | UNI-ROYAL | 0805W8F1001T5E |  |  |  |  |  |  |  |  |  |  | 1
220k | R18 | Resistor_SMD:R_0805_2012Metric | C104108 | RALEC | RTT052203FTP |  |  |  |  |  |  |  |  |  |  | 1
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

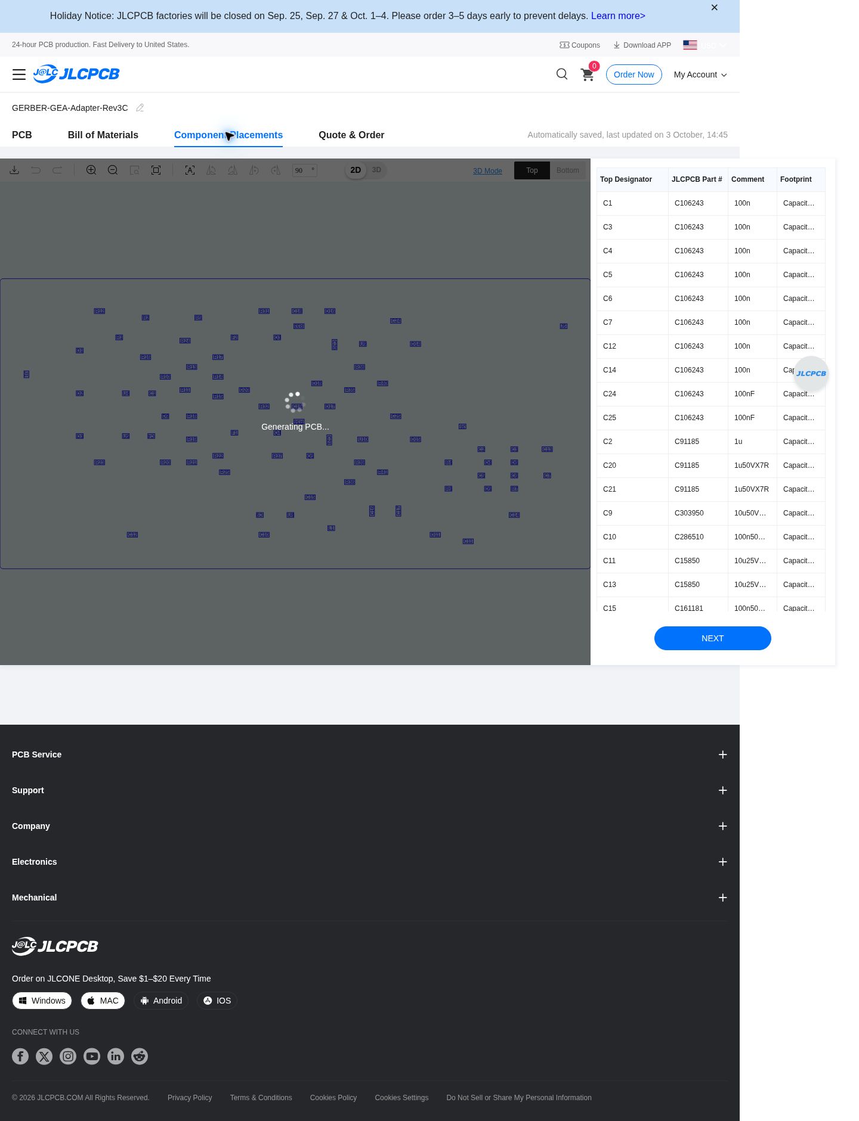
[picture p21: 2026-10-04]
pcb/rev3c/images/ordering/placement-preview.jpg

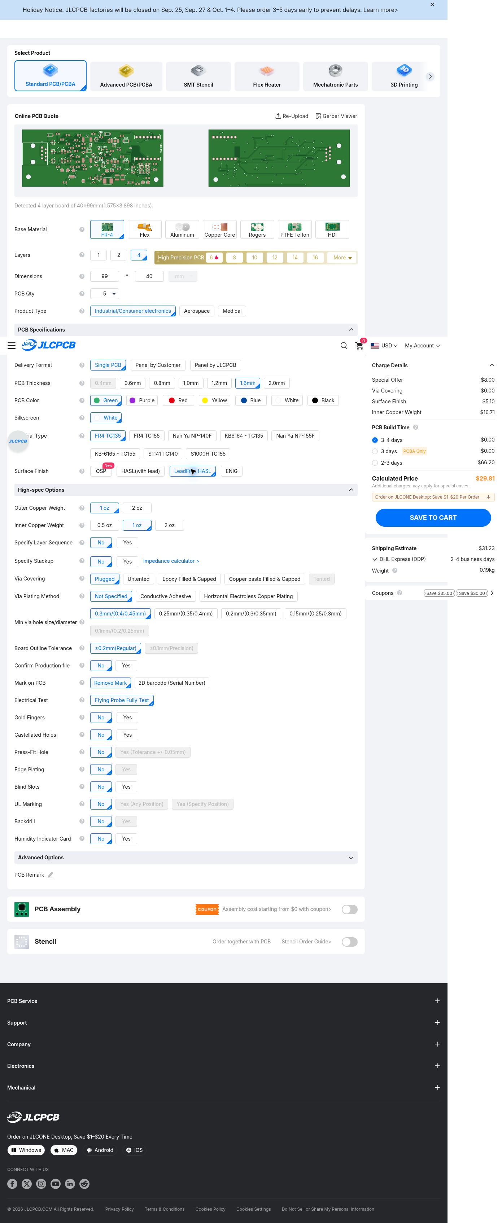
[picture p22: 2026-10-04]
pcb/rev3c/images/ordering/five-board-pcb-settings.jpg

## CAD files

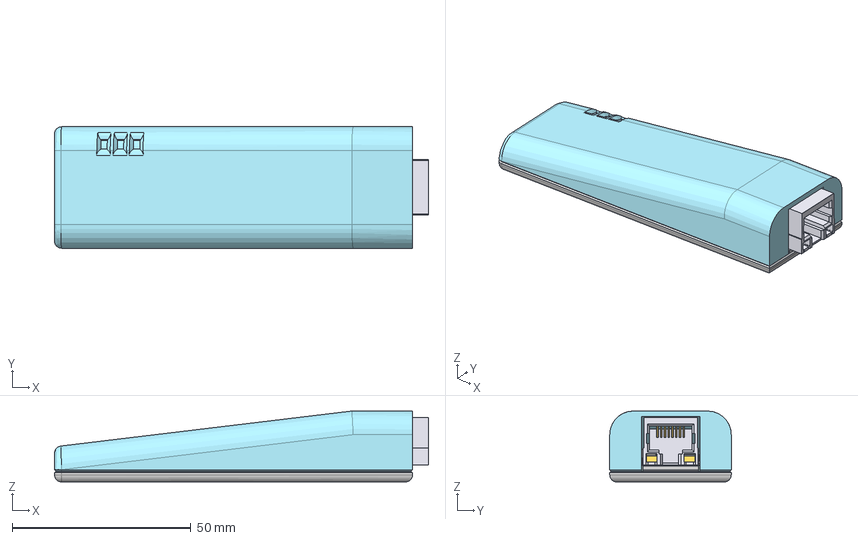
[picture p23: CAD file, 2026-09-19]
case/rev2/exports/v2-case.step
104.6 x 34.0 x 19.9 mm
C_0805_2012Metric_1 x 14
R_0805_2012Metric_1 x 24
SOT_23 x 7
LED_0805_2012Metric_1 x 3
SOT_23_6 x 2
ESP32-C3-WROOM-02_1
CQ assembly
D_SOD_523
CQ assembly_1
D_SMA_1
OnionStraws_PCB
Insulator
Insulator_2
LED_green_yellow
Insulator_3

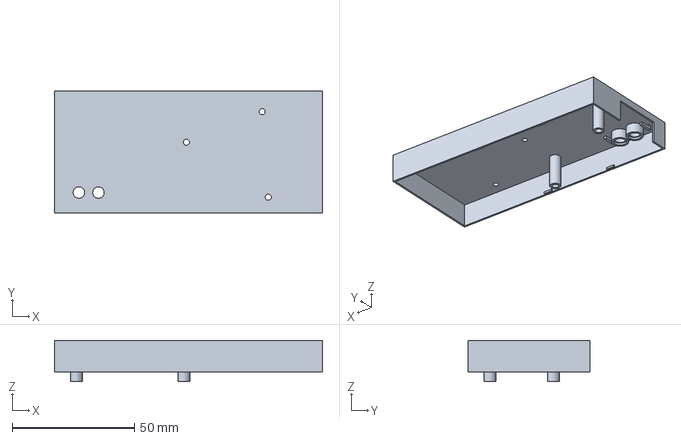
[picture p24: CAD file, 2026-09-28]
case/rev3a/rev3a_button_lid.step
109.7 x 50.0 x 16.8 mm

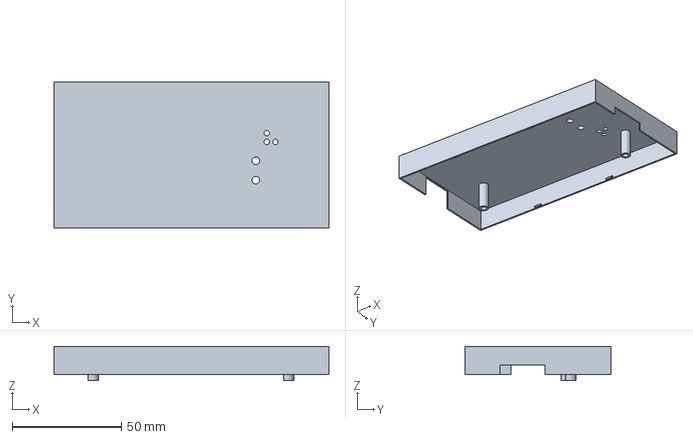
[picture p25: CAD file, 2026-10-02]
case/rev3b/exports/rev3b_lid_magnets.step
126.0 x 67.0 x 15.7 mm

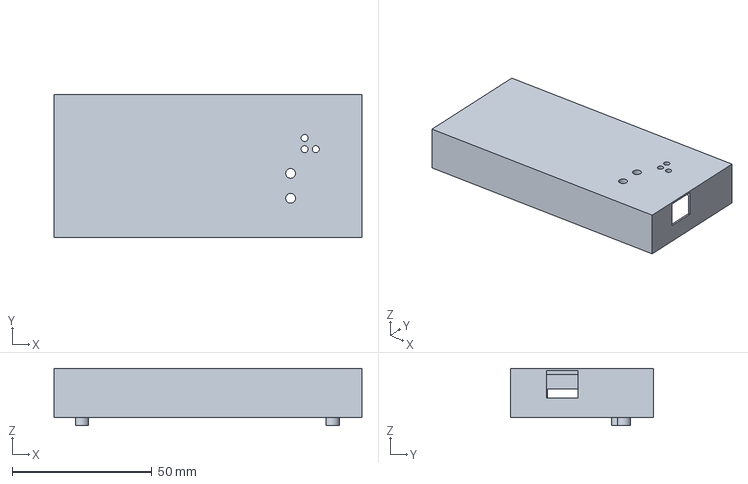
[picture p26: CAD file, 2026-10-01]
case/rev3c/exports/rev3c_lid.step
110.0 x 51.0 x 20.4 mm

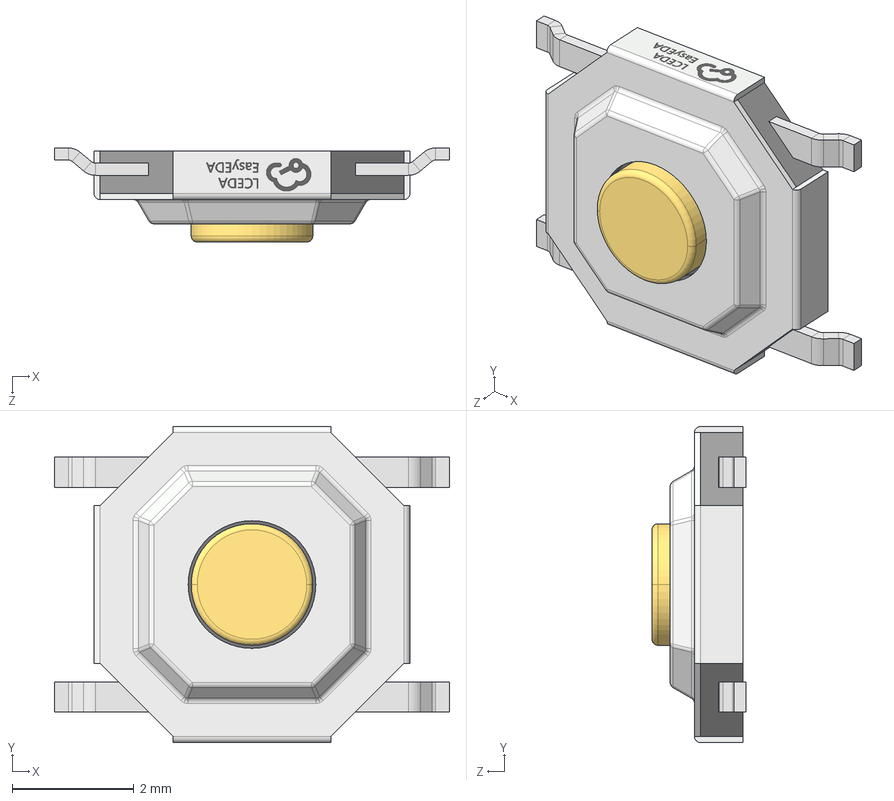
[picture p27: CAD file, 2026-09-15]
pcb/rev3a/design/models/SW1-SW2-XKB-TS-1187A-B-A-B.step
6.50 x 5.20 x 1.55 mm

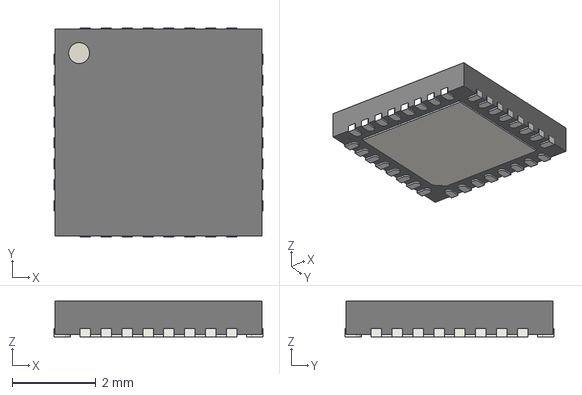
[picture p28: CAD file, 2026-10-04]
pcb/rev3b/design/models/xiao-packages/QFN-32-1EP_5x5mm_P0.5mm_EP3.7x3.7mm.step
5.00 x 5.00 x 0.85 mm

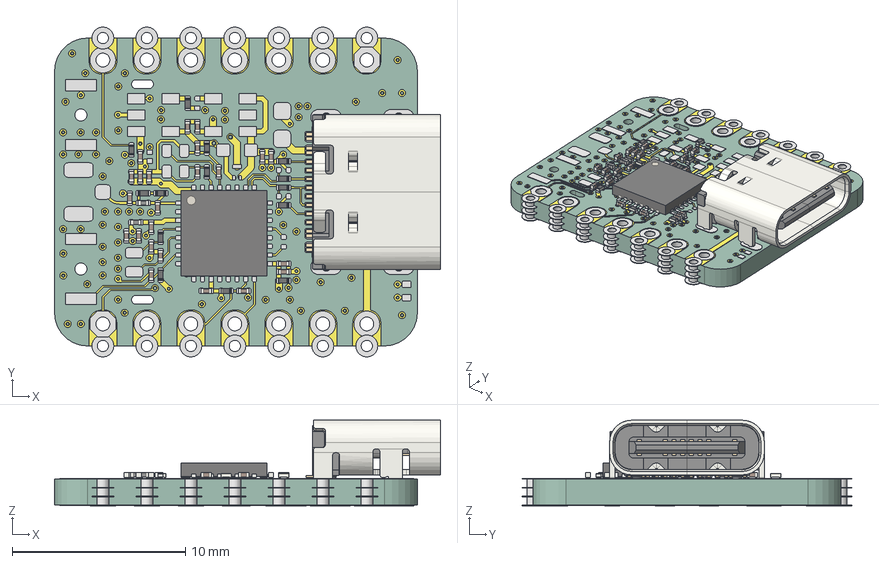
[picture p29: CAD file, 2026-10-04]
pcb/rev3b/design/models/XIAO_ESP32C3_v1.3_vendor_pcb_visual_reference.step
22.3 x 19.0 x 4.95 mm
C_0201_0603Metric x 23
R_0201_0603Metric x 14
L_0201_0603Metric x 2
QFN-32-1EP_5x5mm_P0.5mm_EP3.7x3.7mm
USB_C_Receptacle_GCT_USB4105-xx-A_16P_TopMnt_Horizontal
XIAO_ESP32C3_v1.3_vendor_pcb_visual_reference_copper
XIAO_ESP32C3_v1.3_vendor_pcb_visual_reference_pad
XIAO_ESP32C3_v1.3_vendor_pcb_visual_reference_via
XIAO_ESP32C3_v1.3_vendor_pcb_visual_reference_PCB

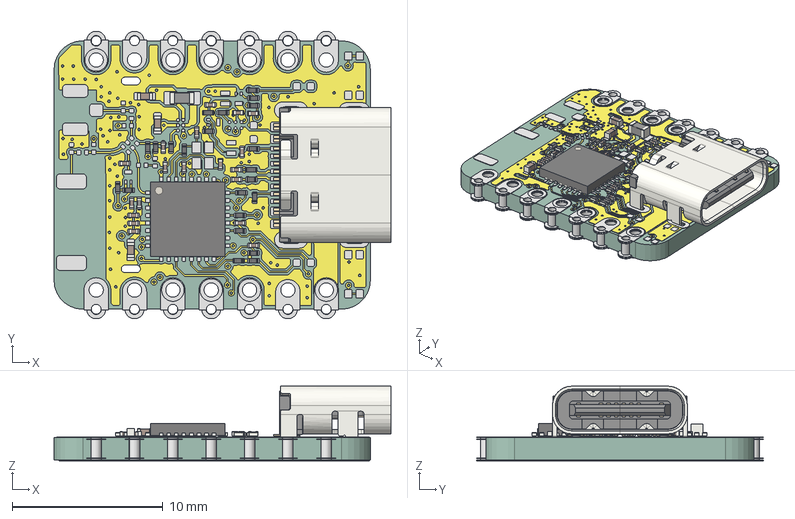
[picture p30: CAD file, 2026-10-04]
pcb/rev3c/design/models/XIAO_ESP32C6_v1.0_vendor_pcb_visual_reference.step
22.3 x 19.0 x 4.95 mm
C_0201_0603Metric x 18
C_0402_1005Metric x 3
R_0201_0603Metric x 22
L_0201_0603Metric
USB_C_Receptacle_GCT_USB4105-xx-A_16P_TopMnt_Horizontal
QFN-32-1EP_5x5mm_P0.5mm_EP3.7x3.7mm
L_0603_1608Metric
XIAO_ESP32C6_v1.0_vendor_pcb_visual_reference_copper
XIAO_ESP32C6_v1.0_vendor_pcb_visual_reference_pad
XIAO_ESP32C6_v1.0_vendor_pcb_visual_reference_via
XIAO_ESP32C6_v1.0_vendor_pcb_visual_reference_PCB

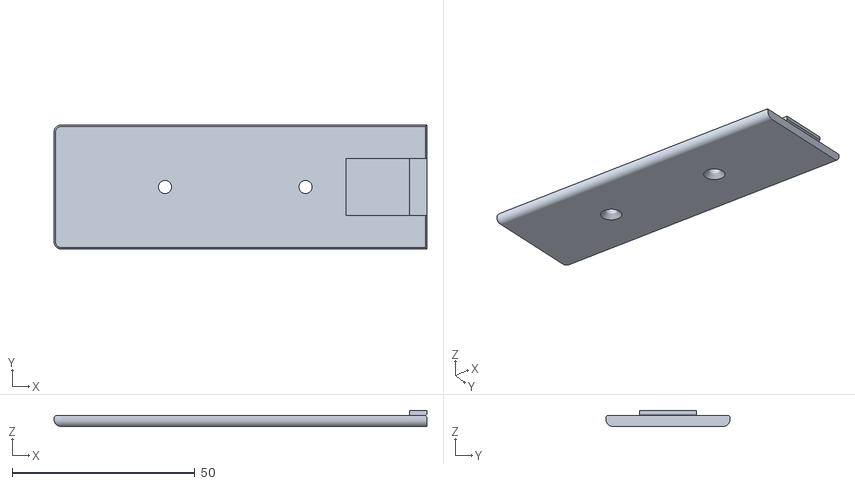
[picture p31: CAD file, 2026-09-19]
case/rev2/exports/v2-case-base.stl
102.2 x 34.0 x 4.40

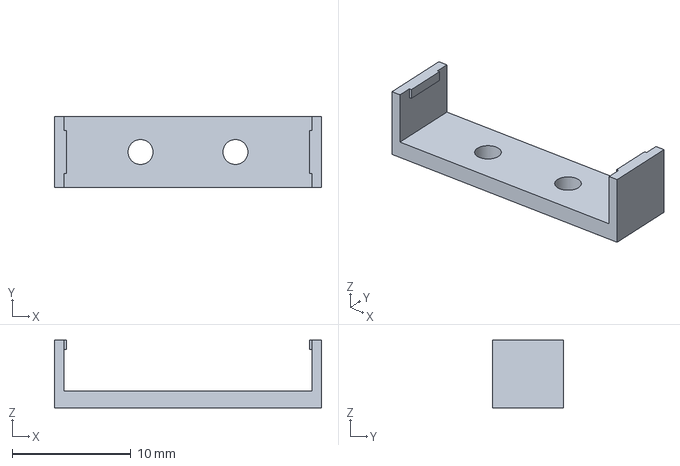
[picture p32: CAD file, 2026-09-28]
case/rev3a/rev3a_button_keeper.step
22.5 x 6.00 x 5.70 mm

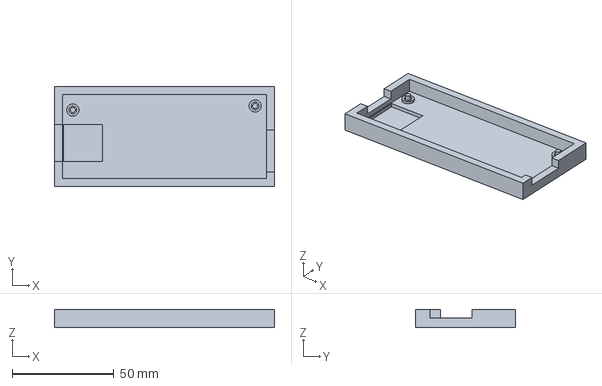
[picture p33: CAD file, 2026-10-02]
case/rev3b/exports/rev3b_base_ant-internal.step
108.0 x 49.0 x 9.00 mm

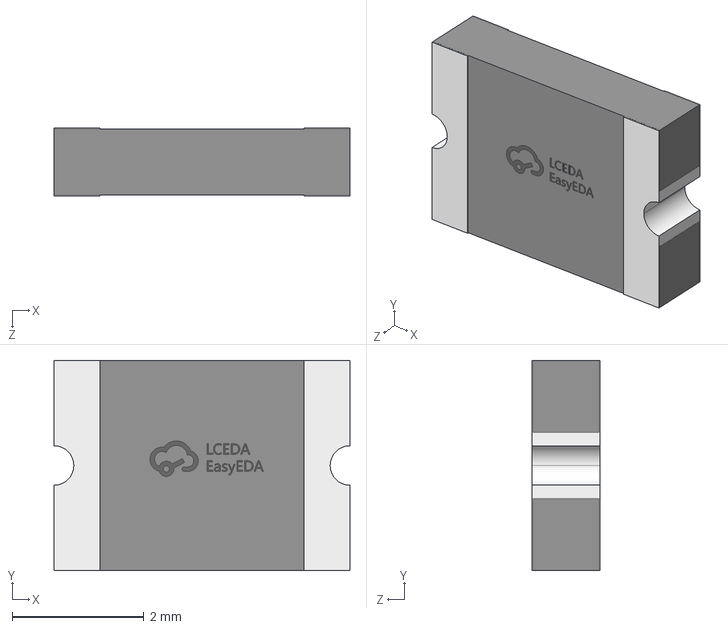
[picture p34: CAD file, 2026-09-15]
pcb/rev3a/design/models/F1-F2-Bourns-MF-MSMF075-24-2.step
4.50 x 3.20 x 1.04 mm

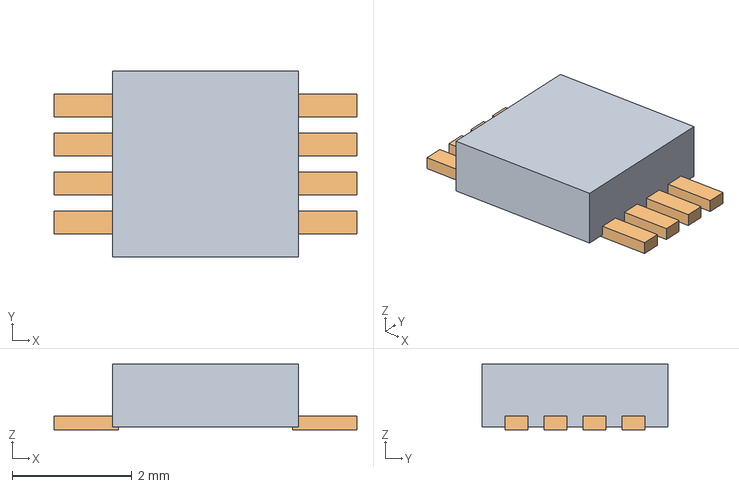
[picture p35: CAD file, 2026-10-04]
pcb/rev3b/design/models/TPS1H200A-DGN0008K-max-envelope.step
5.05 x 3.10 x 1.10 mm

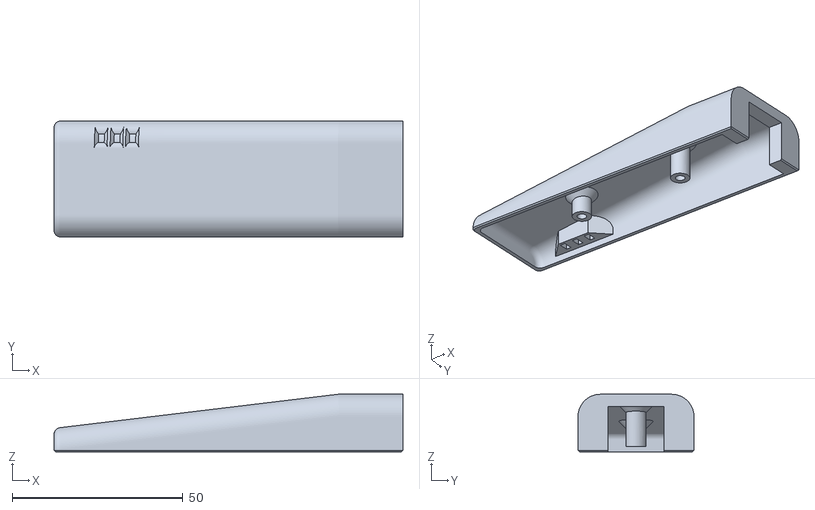
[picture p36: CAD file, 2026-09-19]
case/rev2/exports/v2-case-lid.stl
102.2 x 34.0 x 16.9

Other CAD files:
case/rev3c/exports/rev3c_lid_ant-internal.step
case/rev3a/rev3a_button_plunger.step
case/rev2/v2-case.f3z
case/rev3a/rev3a_base.step
case/rev3a/rev3a_base.stl
case/rev3a/rev3a_button_keeper.stl
case/rev3a/rev3a_button_lid.stl
case/rev3a/rev3a_button_plunger.stl
case/rev3a/rev3a_lid.step
case/rev3a/rev3a_lid.stl
case/rev3b/exports/rev3b_base.step
case/rev3b/exports/rev3b_base.stl
case/rev3b/exports/rev3b_base_ant-external.step
case/rev3b/exports/rev3b_base_ant-external.stl
case/rev3b/exports/rev3b_base_ant-internal.stl
case/rev3b/exports/rev3b_base_magnets.step
case/rev3b/exports/rev3b_base_magnets.stl
case/rev3b/exports/rev3b_lid.step
case/rev3b/exports/rev3b_lid.stl
case/rev3b/exports/rev3b_lid_ant-external.step
case/rev3b/exports/rev3b_lid_ant-external.stl
case/rev3b/exports/rev3b_lid_ant-internal.step
case/rev3b/exports/rev3b_lid_ant-internal.stl
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

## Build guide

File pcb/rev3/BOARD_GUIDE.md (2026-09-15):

# Revision 3A board guide

Revision 3A keeps the ESP32-C3-WROOM-02 module and its built-in Wi-Fi antenna,
then adds USB-C, automatic appliance-power selection, clearer controls, status
indicators, and a permanent recovery header.

> **Prototype status:** this design has not been electrically qualified. Do not
> connect it to an appliance until a small assembled batch passes the
> current-limited checks in [BRINGUP.md](BRINGUP.md).

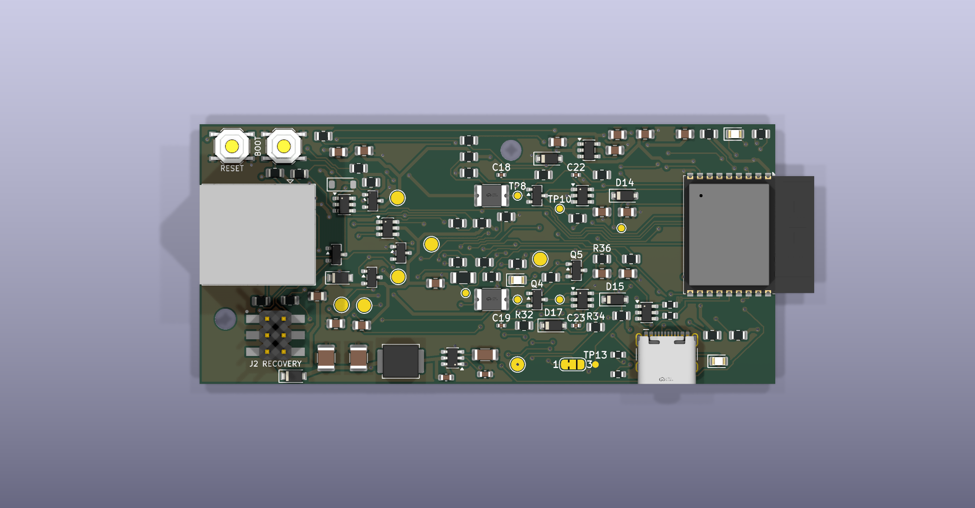
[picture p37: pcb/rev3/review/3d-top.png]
Revision 3A populated-board render


The render is oriented with the appliance connector on the left, the ESP32
antenna at the right edge, and USB-C along the lower edge.

## Controls, connectors, and indicators

| Marking | What it is | Normal use |
| --- | --- | --- |
| `J1` | Appliance 8P8C connector | Connects power and the GEA serial bus after prototype qualification. |
| `J4` | USB-C | Normal flashing, serial logging, and bench power. |
| `J2 RECOVERY` | 2-by-3, 2.54 mm header | Backup 3.3 V UART flashing if native USB is unavailable. Open the enclosure before use. |
| `SW1 RESET` | Reset button | Restarts the ESP32-C3; reachable through the matching lid service hole. |
| `SW2 BOOT` | Boot-mode button | Hold while resetting to force the ROM downloader; reachable through the matching lid service hole. |
| `D4` green | Wi-Fi indicator | Firmware-controlled indication that Wi-Fi is connected. |
| `D6` yellow | GEA-bus indicator | Firmware-controlled indication that the appliance bus is connected. |
| `D5` red | Diagnostic indicator | User-controlled diagnostic light; a fault pattern is reserved for future firmware. |
| `U2` | ESP32-C3-WROOM-02 | Runs ESPHome and includes the Wi-Fi radio and antenna. |

The ESP32 antenna projects beyond the right board edge. Keep at least 15 mm of
clear space beyond that edge; do not place metal, wiring bundles, or enclosure
hardware in that volume.

The printable lid has two small service holes above RESET and BOOT and three
separate viewing apertures above the green, red, and yellow LEDs. J2 remains
inside the enclosure because recovery leads should never remain attached during
normal appliance operation.

## How appliance power works

Different appliance harnesses can supply power on J1 pin 1 or pin 3. Rev3A does
not require a user jumper:

- each input has its own resettable fuse and reverse-polarity protection;
- the control circuit gives pin 1 priority when both inputs are present;
- blocking diodes are intended to prevent either appliance pin from feeding the
  other input;
- USB power is isolated from appliance power before the board's rails join.

Those are design objectives, not proven safety claims. Bring-up must measure all
eight pin-1, pin-3, and USB presence combinations before an appliance is used.

## Normal flashing

1. Leave J1 disconnected during initial bench work.
2. Connect J4 to a computer with a USB-C data cable.
3. Flash through the ESP32-C3 native USB interface.
4. If automatic download mode does not start, hold `SW2 BOOT`, tap and release
   `SW1 RESET`, then release `SW2 BOOT` after the downloader starts.

## Recovery flashing through J2

J2 is a backup for a damaged or unavailable USB data path. Use a **3.3 V logic**
USB-to-UART adapter and female Dupont leads. Never apply 5 V logic to J2, and
never drive J2 power while J1 or J4 already powers the board. The exact pin map
and recovery sequence are in
[BRINGUP.md](BRINGUP.md#recovery-flashing-when-usb-is-unavailable).

## Where to go next

- [README.md](README.md): architecture, changes from Revision 2.2, and release gates.
- [DESIGN_NOTES.md](DESIGN_NOTES.md): engineering decisions, tradeoffs, and unresolved risks.
- [BRINGUP.md](BRINGUP.md): bench equipment, test sequence, and result tables.
- [review/README.md](review/README.md): schematic, layer, assembly, 3D, ERC, DRC, and drill-review package.
- [production/README.md](production/README.md): Gerber, BOM, CPL, and quote-package details.
- [case/rev3a/README.md](../../case/rev3a/README.md): enclosure dimensions and connector clearances.

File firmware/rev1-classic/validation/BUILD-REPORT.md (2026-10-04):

# Rev1 classic ESP32 historical build results

Both candidates passed actual ESPHome `config` and `compile` commands on October 3, 2026. Factory, OTA and ELF artifacts were produced for each profile. No firmware was flashed and no device or appliance was connected.

| Profile | Config exit | Compile exit | Compile time | Target and framework |
| --- | ---: | ---: | ---: | --- |
| [GEA2](../gea2.yaml) | 0 | 0 | 86.707 s | nodemcu-32s / classic ESP32 / ESP-IDF 5.5.5 |
| [GEA3](../gea3.yaml) | 0 | 0 | 43.838 s | nodemcu-32s / classic ESP32 / ESP-IDF 5.5.5 |

Tool: ESPHome **2026.9.1** from the existing engineering virtual environment. The native build actually selected ESP32 and Xtensa toolchain `esp-14.2.0_20260121`. The fetched GEA checkout's HEAD was independently verified as **283ff2b0dfe90a6d14a5417a23176d433be8a5b3**; it had no tracked working-tree changes. Its `erd-definitions` submodule was `c0de08ce3d3a55d5d7b0c0ba0a10e2688f224e58`.

## Exact inputs and procedure

The isolated worktree starts at public main `bc0d52495bd97ed1504bd0ca0775e47feb01a648`. UART/LED mapping comes from recovered Rev1 hardware commit `87984047ee029efb83bf9947dc21818fd18e39b3`: schematic blob `884cae1950066274f54545e730efb9746e1474ba`, board blob `7202d06e51b573ea9181b7dff6960e35402ede7d`.

- GEA2: GPIO18 TX / GPIO19 RX, inverted, 19,200 baud.
- GEA3: GPIO17 TX / GPIO16 RX, non-inverted, 230,400 baud.
- Only carrier LED: GPIO13/U3.15 → R19 220 Ω → D6 anode, cathode at GND, active high. GPIO14/SW1 remains unconfigured.

Only these profiles/packages were copied to a new temporary directory, with synthetic Wi-Fi/OTA secret values supplied there. Both actual `config` and `compile` commands ran; no real credentials were read. All five YAML/package SHA-256 hashes, exact commands, exits, durations and raw/readable log hashes are in [build-evidence.json](build-evidence.json). Original stdout, normalized readable logs and the archived validation driver were kept under ignored `artifacts` during that earlier build; those files are not included in the restored package. CI owns future compile orchestration. Readable logs normalize terminal colors, line endings and trailing whitespace. Package cleanup did not change any build input: their hashes and the retained outputs were verified again without recompiling.

## Actual local artifacts

These ignored binaries were produced in the October 3 build and their recorded hashes are retained below. Their bytes and logs are not included in this restored source package and are not freshly verified. Fresh config/compile has not run; these records are not deployment or hardware-qualified images.

| Profile and artifact | Bytes | SHA-256 |
| --- | ---: | --- |
| GEA2 factory | 947232 | 3ef3b77c8717152f68e6e8ebce908d78963078b6689e2e436315b2fe73144bd2 |
| GEA2 OTA | 881696 | 0eed22a2d6a29cfd44f4bd40b2af83b2e37f8636c794822b5202ef92c2e4c46d |
| GEA2 ELF | 14146024 | a9518d8a34989105791ddadaf3107e97555e159858ace995089a2c41b87b8fd2 |
| GEA3 factory | 944400 | afb1a67ef4fc4feca71a405eb99d6fac77d683c9e4dce161181dd64503ce984f |
| GEA3 OTA | 878864 | 0c28d3fd67636da52d6c0fdd1c245e9cbc246e3bea7cf105110b0f1b3a8d6116 |
| GEA3 ELF | 14062720 | 32edfba2046450fc481c50b04ec2d28f0c989256ce201464156820253daa0b18 |

GEA2 reports 46,392 bytes RAM used (25.7%) and 881,587 bytes application flash (48.0%). GEA3 reports 46,104 bytes RAM (25.5%) and 878,747 bytes application flash (47.9%). Those percentages use the build target's partition/memory assumptions, not measurements of a purchased module.

## Warnings and remaining limits

These successful builds retain inherited warnings: GEA2 has eight printf-format diagnostics and one unused generated ERD lookup diagnostic; GEA3 has seven format diagnostics and the same unused-function diagnostic. In both profiles, six `%u` diagnostics pass `uint32_t` (`unsigned long`) and one `%d` passes `int32_t` (`long`); GEA2 adds one signed `%d` diagnostic in the text sensor. These are printf type-contract defects, even though the affected arguments retain the intended signedness.

The actual pinned Xtensa compiler reports 32-bit `int` and `long`, a four-byte word and 32-bit argument alignment; `int32_t`/`uint32_t` are `long`/`unsigned long`. Existing compiled-object inspection confirms one 32-bit poll-value load into an outgoing argument register. For these particular diagnostics, no width truncation, extra variadic-slot consumption or argument shift is evidenced. The warnings also cover two ERD decimal conversions and GEA2's text-sensor conversion. Correct runtime formatting was not established: target decimal conversions and logging were not exercised. The unused `erd_lookup` warning has no printf/ABI effect. The pinned component remains unchanged. Exact diagnostic source lines and compiler evidence are recorded in [build-evidence.json](build-evidence.json); complete raw/readable logs were originally local under ignored `artifacts/logs` and are not present in this source package.

Compilation does not identify an installed classic-ESP32 module, flash layout or pin-compatible product. These profiles do not match C3/C6 boards. Appliance-specific entities, actual source/current/protection and external-buck behavior, loaded startup, power/USB/UART isolation, thermal performance, module/case fit and appliance compatibility remain unqualified. Keep UART programmer VCC disconnected and use one reviewed supply. No order or remote publication occurred.

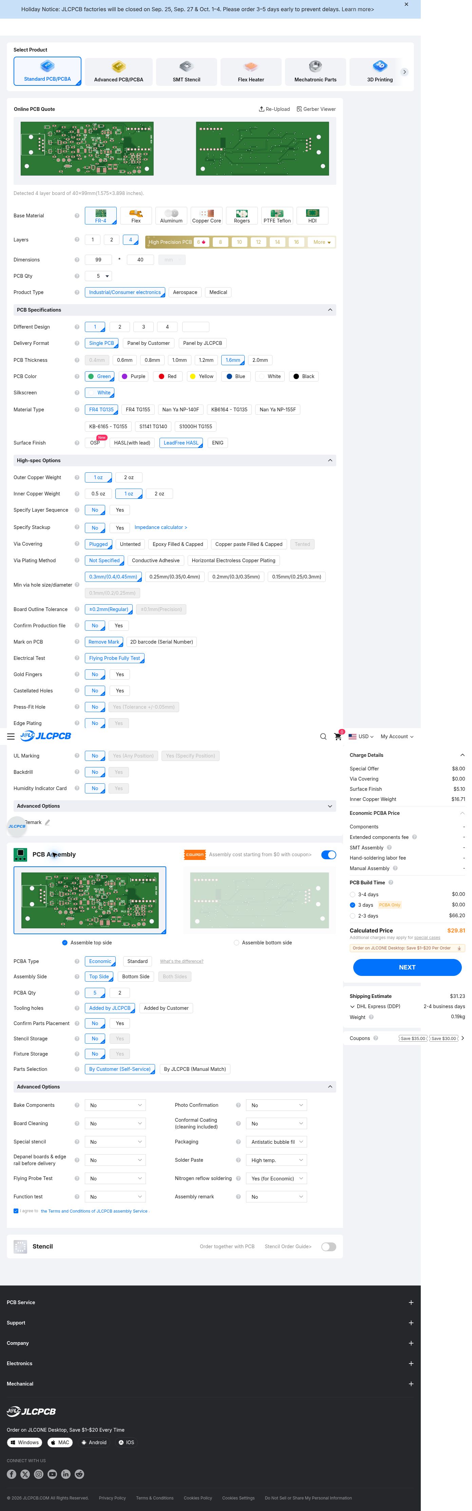
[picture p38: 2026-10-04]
pcb/rev3c/images/ordering/five-board-assembly-settings.jpg

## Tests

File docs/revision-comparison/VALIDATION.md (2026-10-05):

# Board validation and current decisions

Latest October5 pre-order analysis and committed fixes: [all-revision review](preorder-2026-10-05/README.md). Earlier checkpoint/quote/source boundaries below remain explicit.

## Current integration recheck

The new `integration/ge-restored-final-2026-10-04` branch combines the complete genuine final per-revision, firmware, CI and comparison histories. It includes the selected Rev3C stencil correction `b87d3e8`. It is a newly identified integration; the earlier `f85ba98` integration's omitted ancestor/tree remains unavailable.

Fresh local checks on October 4 after source restoration use the exact KiCad 9.0.9 image, official pinned libraries and matching Python/pcbnew runtime. All seven full-severity ERC/all-track DRC checks and all seven intended-rule audits pass with zero errors, warnings, open connections or schematic-parity issues. Source/CAM parity passes all seven. Full BOM/CPL manufacturing checks pass Rev2.1/2.2/3A/3B/3C; Rev1/Rev2's missing current supplier inputs stay explicit failures. Twenty-eight regression tests pass, including rejection of source-matched drill-marker stencils and deleted legacy Power-net memberships.

The current [CI review receipt](../../ci/validation/INTEGRATED-CI-REVIEW.json) binds all 380 CAD dependencies, current configuration/test hashes and eight profile/include inventories. CircleCI schema validation accepted the exact current configuration on October 4 using CLI 1.0.51932; its [separate receipt](../../ci/validation/INTEGRATED-CIRCLECI-SCHEMA.json) records the hashes. All 21 power/source/physical release gates remain blocked. Hosted jobs on published `2d5a42c` now pass native hardware, intended rules, validator tests and all eight real firmware config/compile checks. Inventory/manufacturing fail only for the two legacy supplier packages, and all 21 release gates stay blocked. The [hosted receipt](../../ci/validation/hosted-2d5a42c/REVIEW.json) and profile hash records distinguish actual execution from physical qualification. Older compilation and integration reports below retain their historical source boundaries; their binaries are not freshly verified.

Rev3C's [stencil review](../../pcb/rev3c/STENCIL-REVIEW.md) removes 26 unintended openings from each paste layer; existing SMT geometry and BOM/CPL are preserved. Rev2.1/2.2/3A/3B already use drillshape 0, and independent fresh native paste/CAM audits pass. Unplaced source-paste apertures remain for Rev2.2 U1 and Rev3A/3B/3C D8 and require assembler review. Rev3C’s October 5 quote now matches the corrected ZIP: USD 134.64 for five or 168.92 for ten assembled carriers; placement/stencil/process qualification remains open.

## Newly verified legacy sourcing blockers

Rev2.0 and Rev2.1 have three references whose purchasing codes conflict with their stated values: R18/R21 declare 220k but C17539 is 200k; R22 declares 4K7 but C17713 is 47k. Their intended electrical values require an explicit reviewed decision before ordering. Rev2.2 and current A/B/C use matching-value codes for these three references. The [catalog and numbered-net review](LEGACY-SOURCING.md) documents the conditional interface effects, stale historical BAV99 labels and recovered AP2205 identity. No resistor, symbol, footprint, population or connection is changed. Existing release gates stay blocked; source/BOM parity is separate from catalog correctness.

## Prior engineering checkpoints

[Comparison](README.md) · [Exact source heads](HANDOFF.md) · [Pricing](PRICING.md) · [Finish plan](FINISH-PLAN.md)

Updated October 4, 2026 at 06:58 UTC; strict seven-revision native checks and exact source-bound quote snapshots. The shared Rev3C design with two 40 V-rated TPS1H200A switches is selected. It retains both appliance PIN1/PIN3 inputs, automatic PIN1 priority, the AP63205 buck and C3/C6 header functions. The Rev3B rated-protection backport has passed independent digital review; Rev3A rated protection, exact connector lands and zero-warning schematic normalization are independently reviewed and staged; all seven revisions now have zero native findings. Older revisions remain separate. Selection and digital passes do not qualify a 40 V board, appliance operation, assembly, thermal behavior or enclosure.

## Current native checkpoints

Genuine KiCad **9.0.9**, full severities, expanded track reporting and schematic parity were used. Counts below are source-bound; each row's full local commit is recorded in [HANDOFF.md](HANDOFF.md). No physical test or manufacturing release is claimed.

| Revision / local checkpoint | ERC errors / warnings | DRC errors / warnings | Unconnected / parity | Scope and remaining limits |
| --- | ---: | ---: | ---: | --- |
| Rev1.0 `53a4b3d` | 0 / 0 | 0 / 0 | 0 / 0 | Explicit faithful VCC presentation; 166 physical tuples unchanged; native/current CAM passes; original BOM/CPL and actual module/buck identity missing |
| Rev2.0 `5c8afe4` | 0 / 0 | 0 / 0 | 0 / 0 | Canonical UART/LED and explicit VCC presentation; 186 physical tuples unchanged; current CAM passes; historical supplier rotations/part identity remain unqualified |
| Rev2.1 `3d98559` / source `fe69d276` | 0 / 0 | 0 / 0 | 0 / 0 | 60 refs; three source-bound pad-center conventions; source-specific legacy power/placement gates remain |
| Rev2.2 `b00c96f` / source `0ee8e021` | 0 / 0 | 0 / 0 | 0 / 0 | 59 refs; native cleanup/manufacturing passes; regulator/current/protection/thermal gates remain |
| Rated Rev3A `615863d` | 0 / 0 | 0 / 0 | 0 / 0 | 97 refs; body J1/J4/U2 datums, recommended J4 shell slots/lands, explicit EN capacitor; source/body-CPL/CAM and 14 pixel views independently reviewed |
| Rated Rev3B `ce2979b` | 0 / 0 | 0 / 0 | 0 / 0 | 85 refs; typed J1/U2 datums; native-registered partial C3 model; exact module stock/process and physical gates open |
| Selected Rev3C `5542734` / quote `b53cfca` | 0 / 0 | 0 / 0 | 0 / 0 | 83 refs; typed J1 datum; source-preserving C3/C6 module/SoC previews; complete current quotes; qualification open |

The combined source at `dbcfef6` passed fresh strict native checks for all seven revisions. Later documentation checkpoint `f85ba98` changes only the CI README and review summary; current native/firmware/manifest inputs remain byte-identical. No severity, rule, grid or exclusion waiver was used. All 25 validator tests pass. Five modern source-bound manufacturing checks pass; Rev1/Rev2 CAM also matches, while supplier BOM/CPL absence remains explicit red. Their intended-netclass audits remain red because no reviewed policy is declared. All 21 power/source/physical readiness gates remain blocked.

Rev3A's provenance remains separate: `d1769b2` repaired all 62 intended Power errors under unchanged 0.25 mm clearance with 53 ERC and 5 DRC warnings; rated freeze `d2bde08` reached 0 ERC errors/9 warnings and 0 DRC findings. Schematic-only normalization resolves those nine while preserving all 301 physical ref/pin/net/function/type tuples and 72 nets; meaningful native controls reject changed supply/UART memberships. USB endpoints use the existing 25 mil grid and VCC is connected explicitly with its datasheet name. No PCB or power topology is changed by that presentation cleanup.

A's reviewed J4 exact SHOU HAN C2765186 footprint now matches forward shell drills 0.60×1.40mm and lands 1.00×1.80mm. Top-mount seating is possible on 1.6 mm; the approximately 1 mm legs remain recessed and no shell paste apertures are defined. Assembler-approved solder delivery, inspection and retention remain gates. TP12 is 0.250201 mm from D5A, only 0.000201 mm above the Power rule; finished annulus/stencil and return-path/fill effects also need process/physical qualification. Direct native Gerber ZIP viewing hit OS error11 after a bounded retry; exact 14-member CAM reproduction and actual source schematic/copper/drill/3D pixels passed.

Current B/C placement uses separately typed nominal manufacturer/module-body points: J1(8.645,−16.995) mm on B/C; B U2(87.89,−12.90) mm. A J1 is (8.645,−17.000) mm; its U2 integrated module and J4 have source-specific proofs. Native rotations/sides and unrelated rows are retained; stale corner origins fail controls. These are documented conventions, not approval of supplier private library zero, actual body/pad/pin1 alignment or process. Supplier previews did not render; the J1 public library iframe was blocked by Chromium. No restriction bypass was used.

A's native 49-row BOM is serialized as 97 one-reference supplier rows with all fields/parts equivalent; exact reimport clears the unselected-parts warning. Current A quotes include its integrated C3; B's exact C3 module shortage prevents a full quote. Historical archives and earlier raw source proofs retain their explicit old hashes. Current native counts do not make legacy boards safe fallbacks.

## Historical source and engine boundaries

| Exact original source | ERC errors / warnings | DRC errors / warnings | Unconnected / parity | Classification |
| --- | ---: | ---: | ---: | --- |
| Rev1.0 `8798404` | 3 / 276 | 0 / 51 | 0 / 59 | Electrical pin membership matched; 59 parity findings were generated net-name metadata |
| Rev2.0 `af1f2c4` | 3 / 168 | 1 / 62 | 0 / 6 | Electrical membership matched by source UUID; reference aliases plus two absent DNP mechanical placeholders; one starved GND thermal |

Recovery of original bytes does not establish source-to-CAM geometry parity. Rev1's retained Gerber archive is the original Git blob, with no BOM/CPL inside. Rev2's original archive and standalone CPL differ by six genuine 180° semiconductor rotations; nine diode rotations differ from native placement in both. Possible supplier conventions were not approval evidence. Both final historical packages now have independent-review closeout and regenerated source-bound current CAM, kept separate from the preserved originals. Rev1's missing original BOM/CPL remains a procurement gate; Rev2's supplier rotations remain unqualified.

Earlier interface/electrical research used KiCad **9.0.2** netlist/geometry extraction. It was not a 9.0.9 ERC/DRC rerun. Six earlier 9.0.2 courtyard findings did not reproduce on the exact public 9.0.9 source; that does not erase the separate intended Power-routing findings repaired on Rev3A. Keep source, engine, libraries, severities and aggregation attached to each result; counts from different runs are not interchangeable.

Rev2's `FullRX5` and `FullTX4` labels use appliance/programmer perspective: `FullRX5 ← ESP GPIO21 TX`, `FullTX4 → ESP GPIO20 RX`. They are not intrinsically miswired or blanket “swapped UART labels.” Current Rev2.1/2.2 service documentation states the ESP perspective explicitly. Their C3 profiles do not match Rev1's classic ESP32 wiring.

## Power and service limits

The selected Rev3C's TPS1H200A switches add margin against the conditional SMF16A 26 V clamp example that exceeds TPS22810's 20 V absolute input rating. The design adds PIN3 TVS and source-referenced nominal 12 V gate clamps, retains reverse-PMOS/OR/priority/buck architecture and uses 33 V PPTCs. Its PMOS, buck, fuses, differentials and pulse energy have separate limits; **40 V switches do not make a 40 V carrier** or prove that GE supplies that pulse. Current limit/retry behavior, source current, low-input loaded startup and thermal bounds remain unqualified.

FirstBuild has two TPS22810 paths, transistor PIN1 priority, OR diodes and an AP2204K-5.0TRG1 linear regulator. Its D101 is reverse across the LDO, not a forward series output loss; no carrier input PTCs appear in its schematic/BOM. Our AP63205 buck adds L1/support parts and forward D11 loss. Neither net naming nor an ideal 5.000 V assumption establishes real module headroom. [Original FirstBuild schematic](https://github.com/geappliances/home-assistant-adapter/blob/4888a7df56e8ce6382ed91e4b95bd5020f1802f6/doc/schematic-v1.0.pdf).

Legacy Rev2.x keeps manual selection and linear regulation. Rev2.2's TECH PUBLIC U6 C19268131 is rated 200 mA; restored Rev2/Rev2.1 instead select C5205181 and retain an AP2205-3.3 value versus AP2204R-3.3 symbol/datasheet ambiguity. Their exact populated-part identity and supply capability require separate review. TVS/PMOS gate/capacitor coordination, zener/fuse/regulator thermal behavior and loaded startup remain gates. Rev1 has only its original PIN1 path and an unidentified external buck. Do not apply a shared-carrier rating or firmware profile to those architectures.

Use one reviewed supply, leave UART VCC disconnected and do not inject a module's 3V3 output. Rev3B/C require disconnecting appliance power before powered USB. Rev3A's separate USB/appliance isolation paths need bench checks. Actual appliance model, loaded voltage/current, transients, hot/cold startup, inrush, Wi-Fi peaks and recovery behavior remain unmeasured.

## Firmware and CI evidence

Eight historical local ESPHome **2026.9.1 config and compile** results use ESP-IDF **5.5.5** and pinned GEA `283ff2b0dfe90a6d14a5417a23176d433be8a5b3`, with factory/OTA/ELF hashes recorded. The earlier temporary output binaries are not included in the restored package; their recorded output hashes remain historical evidence and have not been freshly verified.

| Profile family | Real builds | Proven UART assignments, TX / RX |
| --- | ---: | --- |
| Legacy C3 GEA2 / GEA3 | 2 | GPIO5 / 10; GPIO21 / 20 |
| Shared XIAO C3/C6 × GEA2/GEA3 | 4 | C3: 5 / 10 and 21 / 20; C6: 21 / 18 and 16 / 17 |
| Rev1 classic ESP32 GEA2 / GEA3 | 2 | GPIO18 / 19 inverted 19,200; GPIO17 / 16 non-inverted 230,400 |

Classic candidate `dde0af3` configures only proved carrier LED GPIO13; its exact purchased 38-pin module remains unknown. GEA2 has eight format plus one unused-function warning; GEA3 has seven format plus one unused-function warning. They include ERD/text decimal conversions, not only logging. Xtensa `int`/`long` have matching 32-bit widths and signedness here, with no evidenced argument displacement/truncation; the printf type-contract defects remain and runtime formatting was not tested. No device was flashed, attached or functionally tested. Shared Matter/Thread appliance firmware is not implemented.

Universal CI candidate `0d3358a` has 25 meaningful boundary tests, canonical local dependency closure, separate native/source/manufacturing/firmware/intended-rule checks and source-bound release gates. Its standalone current-main manifest declares the two legacy profiles. Complete-source checkpoint `7df3567` declares all eight legacy/shared/classic profiles, verifies 356 CAD dependencies including 16 STEP assets and has independent review closeout. That prior combined checkpoint included all seven warning-free native sources, 380 local design dependencies/28 STEP assets, typed A/B/C body datums and current supplier serialization/model receipts. All 25 tests passed after integration; all eight real build inputs remain matched. The final CircleCI config including the validator-tests job passed the official CLI schema service at 05:31 UTC. That prior pre-restoration checkpoint had no hosted execution; the current hosted results are recorded above. Missing source, infrastructure failure and stale/untracked evidence remain failures.

## Mechanical and delivery boundary

Legacy case `5e01d79` passes native C3 geometry checks with unchanged CAD; current rated-component heights were not re-derived. It is C3-only, never the default shared enclosure. Exact five-piece common CAD is unavailable and needs restoration, source provenance, calibration, fit and actuator qualification. Module retention, vibration, USB/buttons, antenna/pigtail clearance and RF remain physical gates. Original galleries are historical. Current C3/C6 previews now use official Seeed PCB geometry, licensed package models, dimension-checked 5 ×5 mm SoC bodies/pin 1 poses and separately reviewed RJ45/socket drawings. Carrier electrical/CAM/firmware bytes were preserved by model-only changes. Complete revision-matched assembly models, button/U.FL identities, seating and case fit remain unresolved; detailed-looking partial models do not close those gates.

All current review heads are local and unpublished. No new order, PR, upstream publication, hosted run or physical qualification is included. [FINISH-PLAN.md](FINISH-PLAN.md) records what remains and what evidence can close it.

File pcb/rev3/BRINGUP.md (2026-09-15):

# Revision 3A prototype bring-up

This procedure is for the first assembled Revision 3A boards. It is a bench test
plan, not permission to connect an untested board to an appliance.

Status: drafted procedure for a future populated prototype. Do not assemble, order,
or connect an appliance until routing, schematic/PCB parity, ERC/DRC, footprint, and
vendor-preview gates pass.

Do not connect a GE appliance until the unpowered checks, USB checks, and all eight
power-source combinations pass with current-limited bench sources.

## Equipment

- current-limited bench supply, or two isolated channels for the dual-input tests;
- digital multimeter with resistance and DC-voltage modes;
- USB-C data cable and a computer with ESPHome or `esptool` installed;
- magnification and good lighting; and
- an approved RJ45 breakout fixture for applying power to J1 pins 1 and 3.

Use insulated probes. Remove power before changing connections. Do not apply power
directly to an after-fuse test pad when validating the complete input path; use the
J1 breakout so the corresponding fuse remains in circuit.

## Required labelled test pads

The release PCB should expose top-side pads for:

- `GND`;
- `PIN1_FUSED` and `PIN3_FUSED`;
- `PIN1_PROTECTED` and `PIN3_PROTECTED`;
- `PIN1_SW_OUT` and `PIN3_SW_OUT`;
- `V_INPUT`;
- `USB_VBUS`;
- `+5V`; and
- `+3V3`.

At minimum, the two fused inputs, `V_INPUT`, `USB_VBUS`, `+5V`, `+3V3`, and a
nearby ground pad are release requirements. The remaining pads make voltage-drop,
priority, and reverse-current failures much easier to isolate.

## Record the board

| Field | Result |
| --- | --- |
| Board identifier | |
| PCB revision | Revision 3A |
| ESP32 module marking | |
| Assembly supplier and lot | |
| RJ45 breakout fixture and revision | |
| Fixture pin map | |
| Supply channel identifiers and limits | |
| Target appliance model | |
| Firmware image and commit | |
| Inspector and date | |

## Visual and unpowered checks

1. Compare connector orientation, component markings, and do-not-install parts with
   the assembly drawing.
2. Look for solder bridges, missing or rotated diodes, tombstoned parts, and damage.
3. Confirm the ESP32 antenna area has no added metal or assembly debris.
4. With every source disconnected, record resistance from `+3V3`, `+5V`,
   `V_INPUT`, and `USB_VBUS` to `GND`, and between `PIN1_FUSED` and
   `PIN3_FUSED`.
5. Stop for a hard short or a reading materially different from the other boards in
   the batch.

Fixed resistance limits are intentionally deferred: capacitors and semiconductor
junctions make a single ohmic limit unreliable. Establish limits from reviewed
measurements on the first known-good boards.

## USB-only test

1. Leave J1 disconnected and attach USB-C through a current-monitored source where
   practical.
2. Measure `USB_VBUS`, `+5V`, and `+3V3` relative to `GND`.
3. Confirm no USB-derived voltage reaches J1 pins 1 or 3, `PIN1_FUSED`, or
   `PIN3_FUSED`.
4. Confirm the ESP32-C3 enumerates, flash the approved firmware, reset it, and repeat
   the enumeration and boot test.
5. Record idle and Wi-Fi-active current and rail voltage.

## Recovery flashing when USB is unavailable

J2 is the populated top-side 2-by-3 recovery header. Open the enclosure to reach it;
the case intentionally has no external service opening. Use a reputable USB-to-UART
adapter set for **3.3 V logic** and six female Dupont leads. Never use 5 V UART or
RS-232 signalling. USB-C remains the normal flashing and logging interface.

One suitable example is the
[Waveshare CP2102 USB-UART Board (USB-C)](https://www.waveshare.com/cp2102-usb-uart-board-type-c.htm).
Its installed header accepts the same female Dupont leads used at J2. Confirm the
adapter's voltage selection is 3.3 V before any connection.

Viewed from the top of the PCB with the `J2 RECOVERY` text below the header, the left
column is pins 1, 2, 6 and the right column is pins 3, 5, 4 from top to bottom:

| J2 pin | Board signal | Recovery connection |
| ---: | --- | --- |
| 1 | `+3V3` | Optional regulated 3.3 V input with every other power source disconnected |
| 2 | `GND` | USB-to-UART adapter ground |
| 3 | ESP32 GPIO9 / `BOOT` | Hold low while resetting to enter download mode |
| 4 | ESP32 GPIO21 / UART0 TX | USB-to-UART adapter RX |
| 5 | ESP32 GPIO20 / UART0 RX | USB-to-UART adapter TX |
| 6 | `EN` | Pull low briefly, then release, to reset |

R1 holds GPIO8 high for valid ESP32-C3 download mode. With appliance power and USB
disconnected, connect the adapter ground and crossed UART signals. Power the board
from one approved source; use J2 pin 1 only when supplying a current-limited,
regulated 3.3 V rail directly. Do not connect the adapter's power pin when USB-C or
J1 powers the board. For the normal button sequence, hold SW2 (`BOOT`),
tap and release SW1 (`RESET`), then release SW2 after the ROM downloader starts. A
lead can instead hold J2 pin 3 low while pulsing J2 pin 6 low. Flash with
`esptool` over the adapter's serial port. Stop if the 3.3 V rail, regulator, ESP32,
or UART header is physically damaged; a recovery connector cannot bypass those
failures.

## USB and Wi-Fi reliability

1. Repeat USB enumeration, flashing, reset, and reconnect at least ten times with
   appliance power absent.
2. Run sustained serial logging while the ESP32 transmits Wi-Fi traffic; record any
   USB disconnect, packet error, reset, or host warning.
3. Install the board in the intended enclosure with at least 15 mm of clear space
   beyond the overhanging antenna edge. Keep metal, wiring, fasteners, and enclosure
   ribs out of that volume.
4. Measure Wi-Fi throughput and usable range both away from the appliance and in the
   final mounting position next to the appliance chassis. Compare at least two boards.

Do not approve the four-layer USB/RF layout if USB errors appear under Wi-Fi load or
if the installed enclosure materially degrades range or connection stability.

Stop for unexpected current limiting, a host over-current warning, rapid heating,
or any voltage driven toward an appliance pin.

## Appliance-input bench tests

Set each isolated, current-limited channel to the measured supply voltage for the
target appliance family. Do not assume all GE appliances provide the same voltage.
Start with the lowest practical current limit and increase it only while monitoring
current, rail voltage, and temperature. Normal limits remain characterization data
until prototypes have been measured.

### Pin 1 only

1. Apply the bench source through the RJ45 fixture to J1 pin 1 and `GND`.
2. Leave J1 pin 3 and USB disconnected.
3. Measure `PIN1_FUSED`, `PIN1_PROTECTED`, `PIN1_SW_OUT`, `V_INPUT`, `+5V`,
   and `+3V3`.
4. Confirm the pin 3 path remains unpowered and the board boots normally.

### Pin 3 only

Repeat the procedure through J1 pin 3. Confirm the pin 1 path remains unpowered.

### Both appliance inputs

Use two isolated supply channels with a common ground at the fixture. Apply both
approved input voltages. A passing result requires measured pin-1 priority, no reverse
voltage or current into pin 3, stable board rails, and no unsafe temperature rise as
each input is removed in turn.

Do not deliberately reverse or over-voltage an input during first bring-up. Those
tests require a separately reviewed fixture and limit.

## Eight-state power matrix

“Present” means an approved current-limited source at the characterized input
voltage. Record startup, steady-state current, rail voltage, temperature, and any
backfeed for every row.

| Test | Pin 1 | Pin 3 | USB | Expected behavior | Result |
| --- | --- | --- | --- | --- | --- |
| 1 | absent | absent | absent | Board remains off | |
| 2 | present | absent | absent | Pin 1 powers `V_INPUT` | |
| 3 | absent | present | absent | Pin 3 powers `V_INPUT` | |
| 4 | present | present | absent | Pin 1 has priority; pin 3 is isolated | |
| 5 | absent | absent | present | USB powers only the board | |
| 6 | present | absent | present | Pin 1 and USB coexist without backfeed | |
| 7 | absent | present | present | Pin 3 and USB coexist without backfeed | |
| 8 | present | present | present | Pin 1 priority; pin 3 and USB remain isolated | |

For rows 6–8, measure `USB_VBUS` while appliance power is present. No
appliance-derived voltage may appear on USB VBUS. Measure both fused appliance inputs
while the other sources are present to detect unintended reverse current.

## Appliance-connection gate

Proceed to the first appliance only after:

- all eight matrix rows have recorded results;
- no unintended backfeed has been observed;
- `+5V` and `+3V3` remain stable under USB flashing and Wi-Fi load;
- USB enumeration and flashing are repeatable;
- the measured appliance voltage leaves sufficient AP63205 regulator headroom;
- component temperatures remain within reviewed limits; and
- a second person has reviewed the measurements.

Keep USB disconnected for the first appliance-only test. Connect USB while the
appliance is attached only after appliance-only operation passes.

## Stop conditions

Remove power immediately if a supply unexpectedly enters current limiting, a rail
collapses or rises above its intended value, either input is driven by another
source, appliance voltage appears on USB VBUS, USB reports over-current, the board
resets repeatedly, or any part becomes rapidly hot, discoloured, or produces smoke
or odor. Record and inspect a failure before trying it again.

## Results summary

| Item | Measurement or observation | Reviewed | Notes |
| --- | --- | --- | --- |
| Unpowered resistance checks | | | |
| USB-only power and current | | | |
| USB enumeration and flashing | | | |
| Pin 1 only | | | |
| Pin 3 only | | | |
| Both appliance inputs | | | |
| USB plus pin 1 | | | |
| USB plus pin 3 | | | |
| USB plus both inputs | | | |
| Reverse-current checks | | | |
| Rail stability under Wi-Fi load | | | |
| USB reliability under Wi-Fi traffic | | | |
| Enclosed Wi-Fi throughput and range | | | |
| Temperature observations | | | |
| Appliance-only test | | | |
| Appliance plus USB test | | | |

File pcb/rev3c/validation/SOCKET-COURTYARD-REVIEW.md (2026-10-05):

# Independent socket courtyard delta proof

Baseline: `acbcb6c5a138fedeb8e93d92838b12381bbce4b4`. Current PCB SHA-256: `6c76a83a6cb1af65f7e8a70d77ad9ddd5911f9ab3843b6ca2c365eea0115904b`.

PASS: exactly two design files differ. Their entire source is byte-for-byte identical after replacing only the six allowed start/end coordinate nodes in the J5/J6 embedded and library F.CrtYd rectangles.

PASS: 100 footprint placements, 239 pads, all drill/net fields, routes, vias, zones and filled copper are unchanged.

PASS: new rectangle is 18.98 × 3.15 mm, centred at (-7.62, 0), covering the supplied 18.48 × 2.65 mm maximum symmetric body plus 0.25 mm on every edge.

PASS: no J5/J6 overlap with another authored front courtyard; no outline interference. Outline is unchanged at (0,0)–(99,40) mm.

- J5: bbox [78.4, 3.7225, 97.38, 6.8725] mm; outline gap 1.620 mm, or 1.595 mm including half stroke. Closest authored courtyard is D14: 3.050 mm centreline / 3.000 mm including both half strokes.
- J6: bbox [78.4, 18.9625, 97.38, 22.1125] mm; outline gap 1.620 mm, or 1.595 mm including half stroke. Closest authored courtyard is C13: 0.907 mm centreline / 0.857 mm including both half strokes.

Native supplement: KiCad 9.0.2, all-track-errors + schematic-parity + severity-all + exit-code-violations. Baseline/current both exit 5 with exactly identical 93 library-configuration warnings. Both show zero unconnected items, zero schematic parity issues, and zero courtyard/other geometry violations. This does not replace hosted pinned KiCad 9.0.9.

Scope limits: supplied manufacturer dimensions are not independently reauthenticated here. Missing courtyards, physical body/mating/contact registration, seating, solder and physical qualification are not approved by this evidence. See JSON for exact hashes, group counts, missing-courtyard references and nearest courtyards.

The independent reviewer used source-node substitution, physical PCB tuple comparison and isolated native snapshots. The compact [JSON proof](socket-courtyard-independent-proof.json) preserves hashes, counts and nearest-courtyard evidence. Hosted pinned KiCad 9.0.9 must check the resulting commit.

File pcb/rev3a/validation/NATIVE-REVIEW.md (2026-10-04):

# Rev3A native source review, October 3, 2026

**The later intended-clearance routing repair now has zero errors.** Native KiCad 9.0.9 retains the same 53 ERC and 5 DRC warnings, with zero unconnected/parity under unchanged rules. No footprint, part identity, pin net, project/custom rule, firmware or case position changes. Via annuli, two new PIN3_EN control vias, and the TP12 physical-margin limit are documented in [CLEARANCE-REPAIR.md](CLEARANCE-REPAIR.md). Electrical/process/physical qualification remains open.

The earlier metadata-review stages below describe frozen `a94c46e7456edd8d267fc0e4bf7b64c01a580e7f` and its predecessors. At that stage no copper changed and62 intended routing findings remained. Historical reports/classification are retained, while the current [routing proof](native-kicad-9.0.9/clearance-repair-proof.json) and manifest bind the repaired source.

## Source and exact native results

Public starting head: `origin/design/rev3a-pr` at
`a5a9fac87cbcb59d337a1fb8d3084ad18867a3e6`. Native executable: KiCad **9.0.9**,
with symbols `ad36cd14bcd1b1cd0484f629ccdd3481366f74f3` and footprints
`2b941bf1d97862be429793b46fd52a5add09a2fc`, both official 9.0.9 libraries.
The [manifest](native-kicad-9.0.9/manifest.json) binds the exact source and assets.

| Stage | ERC errors/warnings | DRC errors/warnings | Unconnected/parity |
| --- | --- | --- | --- |
| Original configured source | 0 / 53 | 0 / 7 | 0 / 0 |
| Correct exact netclass patterns, original silk | 0 / 53 | 62 / 7 | 0 / 0 |
| Frozen a94 source, fabrication-layer silk cleanup | 0 / 53 | 62 / 5 | 0 / 0 |
| Current intended-clearance routing repair | 0 / 53 | 0 / 5 | 0 / 0 |

These DRC totals use `--severity-all --schematic-parity --all-track-errors`.
Without all-track-errors, the recorded intended/current clearance totals are
**57**, while original remains zero. Repeated standard-aggregation runs during
this metadata refresh yielded 56 and 57 errors on the identical source; the
all-track-errors result remains 62 and was the frozen stage's blocking clearance count. Current routing reports have zero errors. Exclusion counts are zero throughout. Existing ignored
rule categories remain as configured; this cleanup changes no severity and adds
no exclusion. `--exit-code-violations` returns 5 for warning-inclusive reports because
reviewed warnings remain; the present routing repair has zero error-level findings. A successful report-generation exit without that flag is not a
DRC pass.

Seventeen patterns missed exact slash-prefixed hierarchical nets, including the
PIN1/PIN3 rails, V_INPUT, USB labels and BUCK_BST. Corrections preserve every class
threshold and custom rule. The original configured pass therefore cannot stand
in for the intended Power check. Details: [NETCLASS-REVIEW.md](NETCLASS-REVIEW.md).
Earlier KiCad 9.0.2 review reported six courtyard findings. On this exact public
head, pinned 9.0.9 reports no courtyard violation; keep the earlier report's own
version/source/library context rather than declaring that historical evidence
wrong. No courtyard geometry was changed in this Rev3A cleanup.

## Clearance findings and warning status

Every one of the 62 expanded findings requests the existing **0.25 mm Power**
clearance. They are geometric rule conflicts, not 62 independently proven
field-failure mechanisms:

- 26 SMD pad/track conflicts. Examples: U10 pad 6 at (60.1375, 26.0500), GND
  route clearance 0.2298 mm; R32 pad 1 at (49.0875, 31.0000), PIN3_GATE_CLAMP
  route clearance 0.2368 mm; R34 beside V_INPUT, clearance 0.2037 mm.
- 22 track/via conflicts. Examples: PIN3_SW_OUT beside a D6-anode via at
  (63.6446, 32.5178), clearance 0.2051 mm; V_INPUT beside the PIN3_GATE via
  at (61.3726, 29.3539), clearance 0.2016 mm.
- Nine track/track conflicts. Examples: GEA2_TX beside V_INPUT near
  (57.5000, 35.9483), clearance 0.2281 mm; BOOT beside ALT_PWR on B.Cu,
  clearance 0.2194 mm.
- Five J1 through-hole-pad/track conflicts. Example: ALT_PWR beside J1 pad 8
  at (16.5100, 21.4450), clearance 0.2017 mm.

There are **zero zone conflicts, intrinsic same-footprint pad/pad conflicts or
cross-footprint pad/pad conflicts** in this reported set. The retained local
J4 locating-hole minimum of 0.18 mm applies to that footprint's hole clearance;
it is unrelated to these copper findings. No narrower applicable copper rule
was identified. [Full classification with UUIDs and locations](native-kicad-9.0.9/clearance-classification.json).

The four unprintable U2 antenna outline/marker graphics were moved from F.SilkS
onto F.Fab with their geometry preserved. This resolves the two board-edge silk
warnings. Five retained footprint/library differences remain at D2, C5, SW2,
TP13 and U2. ERC remains 44 embedded-symbol differences, eight USB off-grid
warnings and one +5V/hidden-VCC alias. They remain visible for review; this
cleanup adds no automatic waiver.

## Part and export consistency

The native schematic export has 112 listed components including an excluded
alternate J3; PCB has 111 footprints. There are exactly **93 fitted top-side
BOM/CPL references, 40 distinct purchasing parts and 44 value-specific BOM
rows**. Four formerly mixed-value groups are split by exact native Value; the
manufacturer part-number header now uses the native field name MPN. Reference
sets, LCSC identifiers, manufacturer/MPN, quantities and footprints are unchanged. All 93 CPL positions,
rotations and sides are unchanged; the final CPL is byte-identical to the public
source package.

The refreshed BOM also restores eight previously blank metadata cells from the
committed schematic: forward/reverse ratings of D10/D11; F3 hold current; L1
rated/saturation current; U6 output current; U8 input-range/output-current fields.
These are metadata reproduction, not new part selections or current design
ratings. Source-derived output-current fields do not establish available appliance
power or thermal capacity.

All four copper Gerbers, paste, mask, board outline, rear silk and both drill
payloads reproduce the old package after excluding creation timestamps. Only
front silk changes. The refreshed matched archive contains 14 files. The later metadata normalization
also aligns three saved plot settings with that existing archive: Protel filename
extensions enabled, no drill-center markers, and solder mask subtracted from
silkscreen. The enhanced manufacturing check reproduces all 13 Gerber/drill
payloads and job metadata while ignoring only creation timestamps. Archive bytes
and circuit geometry are unchanged. Schematic,
assembly, outline and drill-map PDFs, all four layer SVGs, and all four populated
native renders were refreshed from this source. Exact referenced stock STEP
models were fetched from official KiCad packages3D 9.0.9 commit
`a0244fe3442823dbb052ebc4820b4c2951e1742c`; their
[URL/hash receipt](native-kicad-9.0.9/stock-model-provenance.json) records the inputs.
Assembly/outline PDF page boxes are cropped around native vector content with
a 12-point margin for readable review; no geometry is transformed. The existing
assembly reference-label positions remain crowded and need review at high zoom.
Connector/enclosure envelope models remain geometric aids requiring real-part fit
qualification. The 3D pictures are not mechanical approval.

## Independent electrical gates

These remain design-review gates independently of CAD cleanliness:

1. **Transient/rating coordination.** Exact D18 SUNMATE SMF16A is connected from
   PIN1_PROTECTED to ground. Its author-published data specify 16 V standoff,
   17.8–19.7 V breakdown and 26 V clamp at 7.7 A under the stated 10/1000 us pulse
   conditions. [TPS22810](https://www.ti.com/lit/ds/symlink/tps22810.pdf) VIN is
   recommended only to 18 V and absolute maximum 20 V. The SMF16A clamp rating
   alone therefore does not establish protection of U9 at its allowable stress.
   Bound actual waveform, source impedance, overshoot and energy and resolve the
   coordination. This is not a claim that every appliance will produce that pulse.
2. **PMOS orientation and gate stress.** Native source maps Q3/Q4 source pin 2
   to the respective fused input and drain pin 3 to the protected rail. Review
   body-diode direction and reverse-current behavior in every powered/unpowered
   state. Ground-referenced D16/D17 are not by themselves proof that CJ3407 VGS
   remains within its ±20 V maximum; check gate/source waveforms and exact diode
   polarity. The [manufacturer CJ3407 drawing](https://www.jscj-elec.com/pdf/f3fb09e55afae446e8a8f8a35ab44e62.pdf)
   is the reference. No orientation or gate-network edit is made here.
3. **PIN3 path and source selection.** D18 is on PIN1 only; PIN3_PROTECTED/U10
   requires its own justified transient envelope. The existing diode-OR/buck path
   must also support the verified PIN3 supply: a nominal 5 V PIN3 source cannot be
   presumed to make regulated 5 V through a fixed-5 V AP63205 buck plus path drops.
   Preserve both original inputs and automatic behavior while choosing and
   independently reviewing any necessary design change.
4. **Available current and thermal margin.** Measure source current availability
   across appliance operating states, startup/inrush, Wi-Fi load, fuse derating,
   switch/diode drops and enclosed regulator temperature. Component headline
   ratings and a native ERC/DRC pass do not establish this system budget.
5. **Manufacturing and physical qualification.** First resolve intended clearances
   without lowering rules, complete independent pinout/polarity/land-pattern review,
   regenerate the package, then review fabricator previews. Only separately
   authorized current-limited bench qualification can test USB isolation, all eight
   dual-input/USB combinations, both handoff directions, enclosure/antenna behavior
   and eventual appliance compatibility. None of those hardware tests ran here.

No remote PR, publish, purchase, sign-in or appliance test was performed.

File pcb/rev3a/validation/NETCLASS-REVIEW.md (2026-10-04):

# Rev3A hierarchical netclass correction

Reviewed public source: `origin/design/rev3a-pr` at
`a5a9fac87cbcb59d337a1fb8d3084ad18867a3e6`.

Seventeen exact netclass patterns omitted the leading slash of the corresponding
hierarchical net. Each corrected pattern now exactly names an existing PCB net;
none assigns a class to a guessed or absent net. Class clearances, routed-width
settings, custom rules, severities and exclusions are unchanged.

Pinned native KiCad 9.0.9 and libraries reproduced the original configuration at
zero ERC errors / 53 warnings and zero DRC errors / seven warnings, with zero
unconnected or schematic-parity findings. That configured pass did not exercise
all intended Power checks. Correct patterns expose 57 Power clearance errors
under standard track aggregation, or 62 using `--all-track-errors`; both retain
seven warnings before the separate silkscreen cleanup. All errors request the
existing 0.25 mm Power clearance. No copper is changed here.

The [pattern list](native-kicad-9.0.9/pattern-corrections.json), original reports
and intended reports in [native-kicad-9.0.9/](native-kicad-9.0.9/) preserve the
actual evidence. Earlier KiCad 9.0.2 courtyard findings must retain their own
version/source/library context; this exact-head 9.0.9 run found no courtyard
violation. The older historical report is not reclassified as erroneous.
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

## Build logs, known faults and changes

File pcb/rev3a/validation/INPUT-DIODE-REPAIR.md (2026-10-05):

# Input OR diode rating repair

D14/D15 now select exact STMicroelectronics STPS140Z (`C155662`) instead of MCC MBR0540-TP. Each part is rated 1 A/40 V with 150 °C maximum junction, addressing the former 0.5 A nameplate versus approximately 606 mA programmed switch-limit mismatch. Both appliance input branches and automatic PIN1-presence priority are retained.

The two numbered terminals remain cathode 1/anode 2. Pad centers, sizes, drills, footprints, placements, routes and CPL are unchanged. The existing lands overlap the ST terminals but are not identical to the manufacturer's recommended lands; solder/paste and supplier placement acceptance remain open. The inherited MBR0540 graphical alias remains a generic K1/A2 Schottky drawing; exact instance fields and BOM determine the new part. No old simulation-model assignment is retained.

[ST primary datasheet](https://www.st.com/resource/en/datasheet/stps140z.pdf) gives 0.55 V maximum at 1 A/25 °C and 175 °C/W only with 50 mm² copper. This preserves the existing room-temperature loss screen and supplies no measured or guaranteed hot-board thermal rating. [Part and numerical-source proof](input-diode-part-repair.json) records exact fields, hashes and isolated netlist/BOM checks. Strict KiCad 9.0.9 and manufacturing checks must bind the new commit; historical reports are not a current pass.

PMEG2010ER downstream/USB diodes, CL/retry resistors, fuses, PMOS, regulator and module architectures are unchanged. OEM source/fault energy, startup/RF loads, actual copper/temperatures and physical qualification remain independent gates. No order or powered test has occurred.

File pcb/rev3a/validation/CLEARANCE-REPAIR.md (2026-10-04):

# Rev3A intended-clearance routing repair

This isolated candidate starts from frozen `a94c46e7456edd8d267fc0e4bf7b64c01a580e7f`. All 62 expanded routing conflicts are resolved under the original intended **Power 0.25 mm / Switching 0.30 mm** rules. Every assignment, global minimum, custom rule, severity and exclusion remains unchanged. This is a digital routing repair; electrical, fabricator-process and physical qualification remain open.

## Native result and preserved source

KiCad **9.0.9**, with the pinned official libraries, reports **0 ERC errors / 53 warnings** and **0 DRC errors / 5 warnings**, with all severities, all track errors and schematic parity included. There are zero unconnected, parity or excluded findings. Standard aggregation also has zero errors. All warning dictionaries match the frozen source exactly; a command using `--exit-code-violations` still returns nonzero because those warnings remain.

All 111 complete footprint subtrees, 315 pads, 71 PCB nets, outline, mounts and interface/case-critical placements are unchanged. Schematic, project, custom-rule, firmware and case files are byte-identical to the baseline. Both appliance inputs, original automatic PIN1 priority, original PMOS orientation/gate network, TPS22810 switches, PPTCs, AP63205 and USB/module/LED functions remain. No part value, manufacturer, MPN, LCSC identity or pin net changes.

The native BOM still reproduces **93 fitted references, 44 value-specific rows and 40 distinct purchasing tuples**. Native CPL conversion remains byte-identical. The unchanged schematic PDF, assembly drawings and part models retain their existing geometry. Current source/export hashes and UUID deltas are bound in the [routing proof](native-kicad-9.0.9/clearance-repair-proof.json) and [manifest](native-kicad-9.0.9/manifest.json).

## Bounded routing change

The original classification remains historical evidence: 26 pad/track, 22 via/track, nine track/track and five J1 PTH-pad/track entries. These are routing conflicts, not intrinsic package gaps or demonstrated appliance failures.

Local connected-node moves and a few short track segments open the left ALT_PWR/BOOT/USB corridor, PIN1 branch, central V_INPUT/GND corridor and PIN3 branch. Every existing track width and layer remains unchanged. PIN3_EN's former Q4 squeeze-route cannot accommodate the 0.20 mm trace with the intended 0.25 mm clearances. A short B.Cu control detour with two ordinary through-vias preserves the same enabled pins and automatic priority. Its two F.Cu connections and underlying ground-reference/return region were inspected in actual native copper pixels. No footprint moved.

Nine existing vias change from **0.80/0.40 mm to 0.68/0.40 mm**, giving **0.14 mm nominal annuli**: BOOT, LED2, GEA2_RX, GEA2_TX, two D6-A vias, V_INPUT, PIN3_GATE and USB_VBUS_FUSED. The JP1-A via changes to **0.72/0.40 mm**, giving **0.16 mm**. Drill diameters and positions of those ten vias are unchanged. Two new PIN3_EN vias use 0.68/0.40 mm. Their exact UUIDs, nets and coordinates are in the proof.

Native board minima remain 0.05 mm annulus, 0.40 mm via diameter, 0.30 mm drill, 0.20 mm track width, 0.20 mm global clearance and 0.25 mm hole clearance. The [current JLC rigid capability table](https://jlcpcb.com/capabilities/pcb-capabilities) separately gives a via diameter at least 0.10 mm larger than its hole, with 0.15 mm preferred; these diametral differences are 0.28/0.32 mm. The table's PTH component-pad category is more conservative and must not be substituted for its via-specific guidance. Nominal CAD annuli are not finished annuli. Drill registration, plating and etch tolerances, finished annular acceptance, and actual stack-up/process approval remain fabricator gates.

The TP12/D5-A corridor has a measured native clearance of **0.2502 mm**, only **0.2 µm** above its 0.25 mm rule. A stricter 0.26 mm diagnostic rule was used only in a separate measurement copy; the production rules are unchanged. That very small excess is a geometry pass, not a physical tolerance guarantee. The immediate GEA_FullRx neighbor has about 0.2002 mm clearance, so the additional 9.8 µm cannot come from that gap alone. A bounded 20 µm corridor shift introduced 19 conflicts; the refined 12 µm shift produced 0.1897 mm at R21-Pad1/USB_VBUS. A short back-layer bypass also encounters JP1-A, V_INPUT and BOOT. These probes rule out those simple moves, not every possible staggered reroute. The [exact diagnostic and local constraints](native-kicad-9.0.9/tp12-margin-review.json) retain the margin/process gate; no failed-trial change entered production.

## Exports and qualification limits

All four copper layers and the plated drill payload are regenerated. Unchanged paste, mask, silkscreen, outline, non-plated drill and job payloads are preserved after comparison with fresh native exports excluding only creation dates/checksums. The matching ZIP has 14 members. The plated map includes two additional 0.40 mm control vias; no blind/buried, filled-via or bottom-assembly process is added. BOM/CPL bytes are preserved after native reproduction checks.

Actual native outer/inner copper pixels, plated drill-map pixels and populated renders are inspected. These establish layout/export consistency. The original D18/TPS22810 stress mismatch, PMOS orientation/gate-stress review, PIN3 protection/headroom, source-current/thermal limits, USB isolation, enclosure and RF gates remain in [NATIVE-REVIEW.md](NATIVE-REVIEW.md#independent-electrical-gates). No manufacturing approval, appliance compatibility, order, remote publication or physical test follows from zero routing errors.

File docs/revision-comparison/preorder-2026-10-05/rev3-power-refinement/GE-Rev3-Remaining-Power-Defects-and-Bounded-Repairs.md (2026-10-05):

# GE Rev 3 remaining power defects and bounded repairs

5 October 2026 UTC. Read-only review of Rev3A, Rev3B and Rev3C at exact commit `77f4c8893db6c018640e25c55a3af624a3eb06b3`. The nine schematic, board and netlist byte hashes match the earlier completed power analysis. `source-bindings.json` binds this review directly to the fixed commit and records independently extracted part identities, numbered terminals and board lands. No source, order or physical assembly was changed. Historical Rev 1 and Rev 2 revisions are outside this review.

**Review at the fixed baseline:** the narrowly justified common component repair is D14/D15, presently MCC MBR0540-TP/C78744, to exact STMicroelectronics STPS140Z/C155662. This repairs the 0.5 A versus programmed 0.606 A nameplate coordination gap and raises the diode junction limit from 125°C to 150°C while retaining the existing 25°C forward-drop screening ceiling, both OR branches and automatic PIN1-presence priority. It does not establish a continuous hot-board rating, complete fault coordination or appliance compatibility. Keep D11 and each revision's module/regulator/USB architecture. A cheap SMA alternative is documented below, with separate A layout and case gates.

## What the source establishes

| Function | Rev3A | Rev3B | Rev3C |
|---|---|---|---|
| PIN1 branch | J1.1 VDC → F2 → Q3 → U9 → D14 | Independently identical numbered branch | Independently identical numbered branch |
| PIN3 branch | J1.3 ALT_PWR → F1 → Q4 → U10 → D15 | Independently identical numbered branch | Independently identical numbered branch |
| CL resistors | R39/R40, 3.3 kΩ | R38/R39, 3.3 kΩ | R38/R39, 3.3 kΩ |
| DELAY resistors | R41/R42, 100 kΩ to respective protected supply | R40/R41 | R40/R41 |
| Priority | Q5/R35/R36/R37, PIN1 presence inhibits PIN3 | Same function | Same function |
| Output | AP63205/D11 → AP2112K-3.3 U6 → WROOM U2 | AP63205/D11 → soldered XIAO C3 v 1.3 | AP63205/D11 → socket J6, C3 or C6 |
| USB/service | J4 → F3 → D10 OR to +5V | Module USB directly on +5V; J2/D19 recovery source | Module USB directly on J6.7/+5V |

Numbered terminals common to all three: Q3/Q4 drain 3=fused input, source 2=protected input, gate 1=gate bias. U9 VS8/IN1=PIN1_PROTECTED; U10 VS8=PIN3_PROTECTED and IN1=PIN3_EN; both OUT7 feed their branch diode anode 2. D14/D15 cathode 1=/V_INPUT; U8 VIN3/EN2=/V_INPUT, SW5 feeds L1 and FB1 senses /BUCK_5V. D11 anode 2=/BUCK_5V, cathode 1=+5V. U9/U10 CL4 and DELAY5 retain the revision-specific resistor references above. GND2/DIAG_EN6/exposed pad 9 are grounded; FAULT3 is unconnected. Q5 base 1=/PRIORITY_BASE, collector 3=/PIN3_EN, emitter 2=GND.

Rev3A D10 anode 2=/USB_VBUS_FUSED, cathode 1=+5V; F3.1=/USB_VBUS and F3.2=/USB_VBUS_FUSED. U6 VIN1/EN3=+5V, VOUT5=+3V3, GND2. Rev3B D19 is a PMEG2010ER recovery OR diode, while Rev3A D19 is a PIN3 SMF16A TVS. Rev3C has no corresponding recovery D19. These are not interchangeable references.

## Diode defect and realistic bounds

The current MCC-authored [MBR0540 sheet, Rev 3-4-12012020, p 1](https://www.megastar.com/content/pdfs/MBR0520-MBR0580%28SOD123%29.pdf) gives 0.5 A at ambient 50°C, operating junction 125°C, θJA244°C/W on its stated single-sided FR4 lands and VF0.55 V at 0.5 A/25°C. Its storage 150°C is not an operating 150°C allowance.

The earlier nominal carrier allowance is 20.626 mA on 3V3 plus 1.033 mA on 5V. Published RF operating-point proxies give 356.66 mA carrier output for C3 and 366.66 mA for A/WROOM. They are not all-process/temperature/startup maxima. A separate 500 mA chip provision plus carrier stress is 521.66 mA in the linear paths. C6's upstream current depends on conversion when regulating and approaches output current in dropout.

| D14/D15 case | Forward screen | MCC reference junction at 85°C local ambient | Interpretation |
|---|---:|---:|---|
| C3 low-input current proxy 356.66 mA |196.2 mW|132.9°C|Above 125°C reference ceiling; not a measured fault |
| A low-input current proxy 366.66 mA |201.7 mW|134.2°C|Same thermal gate, independently applied |
| C3 at 13.6 V, earlier assumed 85% carrier efficiency, input 162.56 mA |89.4 mW|106.8°C|Higher input reduces input-diode current while output current remains 356.66 mA |
| 521.66 mA provision stress |286.9 mW|155.0°C|Also exceeds 0.5 A nameplate; not asserted normal continuous demand |
| Partial CL upper 708.26 mA at 85°C |389.5 mW|180.0°C if continuous|Actual retry is pulsed; steady θJA must not be used to predict its pulse peak |

With the mixed-condition 0.55 V/244°C/W screen, the 85°C reference current ceiling is 298.1 mA. Equivalently,356.66/366.66 mA require local ambient no higher than 77.1/75.8°C on that thermal reference. These are conditional screening limits, not allowed appliance ambient claims. Hot/cold VF, reverse leakage, actual copper, neighboring heat and actual load duty must be measured.

A45 ms attempt at 708.26 mA and 0.55 V is 17.53 mJ diode forward energy. A5.5 A/8.3 ms half-sine surge entry does not qualify that repetitive waveform. The source must not present a larger current-rated diode as completed protection coordination.

## Bounded replacement and actual land compatibility

Exact [STPS140Z primary sheet, pp 1–2 and 5](https://www.st.com/resource/en/datasheet/stps140z.pdf): SOD123,1 A continuous at ambient 60°C,40 V reverse,150°C junction,0.55 V maximum at 1 A/25°C and 0.51 V at 1 A/100°C. θJA175°C/W requires 50 mm² of 35µm copper. Leakage maxima are 10µA at 5 V/25°C,40µA at 40 V/25°C and 5mA at 40 V/100°C. Thermal runaway remains an explicit condition. Use the 0.55 V table row, not the inconsistent 0.49 V front-page summary.

All three source D14/D15 lands are 0.90×1.20 mm, centers±1.65 mm, inner gap 2.40 mm, overall 4.20 mm, cathode 1 at negative localX. ST recommends 0.97×0.65 mm lands,2.51 mm inner gap and 4.45 mm overall. Therefore these are **compatible lead-overlap lands**, not identical manufacturer-recommended lands. The ST body/terminal drawing gives overall 3.55–3.95 mm, terminal width 0.55 mm typical and minimum lead length 0.25 mm. Existing pads cover localX1.20–2.10 mm andY±0.60 mm: at the maximum reach the outer lead ends at 1.975 mm and the minimum 0.25 mm contact extends inward to 1.725 mm, within the pad. Cathode marking and existing K1/A2 mapping must be retained. Manufacturer paste/joint acceptance remains separate.

At the 366.66 mA/0.55 V screen, ST's 50 mm² reference would give 35.3°C rise,120.3°C junction at 85°C. At 521.66 mA it would give 50.2°C rise,135.2°C junction. These calculations show useful *potential* thermal margin. The actual boards only have GND planes; none has a V_INPUT cathode pour. Do not assign 50 mm² diode heat spreading or 175°C/W merely because the board has four layers. Retaining the current pads with this part is a current/junction-rating repair; adding/qualifying same-net heat-spreading copper would be a further bounded layout repair.

Current [LCSC exact C155662 page](https://www.lcsc.com/product-detail/C155662.html) displayed 4,930 pieces, USD0.1463 each at 5+,0.1178 at 50+,0.1036 at 150+. Two cost approximatelyUSD0.293/board before assembly, shipping and tax. Stock/price are a retrieved catalog snapshot and need rechecking for an order. No purchase was made.

The cheaper [LRC LMBR140T1G primary RevC](https://www.lrc.cn/Upload/PDF/Product/SBD/LMBR140T1G.pdf) and [C81142 catalog](https://www.lcsc.com/product-detail/C81142.html) give 1 A/40 V/150°C,0.56 V at 1 A,θJA312°C/W,124,860 pieces andUSD0.0399 each 20+. Its nominal 366.66 mA screen rises 64.1°C, leaving only 0.9°C below 150°C at 85°C before leakage or adjacent heat. Reject it as a claimed hot-margin repair. The Diodes B140HW SOD123 option has a 250°C/W typical reference requiring 1 inch square 2oz copper, so it supplies no verified thermal advantage on these lands.

### Cheap SMA option for a later local layout candidate

Exact [Diodes B140-13-F primary DS13002 Rev 20-2, pp 2/4/5](https://www.diodes.com/datasheet/download/B120.pdf) is 1 A at terminal 130°C,40 V,150°C junction,0.50 V maximum at 1 A/25°C. Its 20°C/W figure is **junction to terminal**, measured with specified 5 mm² copper pads; it is not ambient resistance. Leakage limits at 40 V are 0.5mA/25°C and 10mA/100°C. Package maximum 5.59×2.92×2.40 mm; recommended lands 2.50×1.70 mm, centers 4.00 mm,6.50 mm overall. Cathode band must remainpad 1. Its 0.50 V screen improves the existing room-temperature input-drop screen by 50 mV.

At 704.01 mA, forward screen 0.352 W gives 7.04°C junction-over-terminal on that reference. A measured terminal no hotter than 130°C would therefore retain about 13°C junction margin in this mixed-condition calculation. At a 1 A capacity check, the same model gives 10°C rise above terminal. Actual hot forward/reverse losses and a thermal-runaway check remain required. Do not derive an 85°C ambient allowance from θJT.

[LCSC C15759](https://www.lcsc.com/product-detail/C15759.html) displayed 57,360 pieces and USD0.0877 each 5+,0.0699 at 50+,0.0611 at 150+, aboutUSD0.175/board at 5+. This is a cheap option, not an exact-price assembly quote.

A6.50×2.92 mm maximum mechanical/land envelope, plus 0.25 mm courtyard margin, was screened at the current centers. B/C D14=(73,8) and D15=(73,22.5) mm have no source footprint-courtyard overlap with a 7.0×3.42 mm candidate courtyard; B's actual XIAO footprint remains clear. Rev3A D14=(66,11) and D15=(64,27) conflict with nearby TPS/decoupling/USB courtyards when enlarged. Small blind offsets also collide. A needs a separately reviewed local placement/reroute. The 2.40 mm package-height/case screen is unverified for all three. Accordingly SMA is feasible for exploration in B/C but is not an automatic common substitution and does not yet meet the complete board/case-clearance gate.

## D11 and USB diodes are a separate output budget

All three D11, A's D10 and B's recovery D19 are exact [Nexperia PMEG2010ER,115, July 2023](https://assets.nexperia.com/documents/data-sheet/PMEG2010ER.pdf), CFP3/SOD123W:20 V,1 A,150°C junction, VFmax 0.34 V at 1 A/25°C; standard FR4 θJA220°C/W, or 130°C/W with 1cm² cathode copper. The 1 A/130°C ambient entry uses ceramic and a specified switching waveform, not these FR4 DC boards.5 V leakage is 60µA typical, not a maximum;20 V/25°C maximum is 1mA. Hot reverse leakage remains a gate.

| Output diode current scenario | Forward screen 0.34 V | Standard-FR4 reference junction at 85°C |
|---|---:|---:|
| C3+carrier 356.66 mA |121.3mW|111.7°C|
| A+carrier 366.66 mA |124.7mW|112.4°C|
| 500 mA+carrier 521.66 mA stress |177.4mW|124.0°C|
|1 A capacity screen |340mW|159.8°C|

The first three cases provide no demonstrated normal-current component defect requiring a D11/D10 replacement. Their 1 A label does not prove 1 A DC at 85°C on this layout. An input 606 mA limiter can feed over 1 A at 5 V after conversion from a higher input; U8's 2 A rating and fault/startup waveforms remain distinct. Do not use CL as D11's output ceiling. Replacing these parts with a 0.50/0.55 V40 V diode would consume 5 V/module headroom and is unjustified. A's D10 USB reverse isolation and B's D19 recovery-source isolation remain their original functions.

## Fuse and control choices

F1/F2 are exact [1812L075/33DR](https://www.littelfuse.com/assetdocs/resettable-ptcs-1812l-datasheet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):0.75 A room hold,1.5 A trip,33 V/20 A fault ratings,20°C post-reflow/trip resistance maximum 0.4Ω. Manufacturer reference hold is 0.47 A at 70°C and 0.36 A at 85°C. At low input, the C3 proxy 356.66 mA leaves only 3.34 mA before upstream bias; A366.66 mA already exceeds the 85°C reference. At 13.6 V the earlier C3 input proxy 162.56 mA leaves much more reference current budget. The fuse carries switch/bias current in addition to converter current. The switch's 5 mA supply test point is not an unconditional complete budget. No larger-fuse recommendation is justified before the OEM current/source-energy contract and required temperature are known.

A's F3 is exact 1206L050YR:0.5 A hold/20°C,0.31 A/70°C,0.25 A/85°C and 20°C R1max 0.7Ω. At 366.66 mA its room resistance screen is 257mV/94mW; the same load held continuously at 70/85°C exceeds the reference hold. USB service at intermittent load is not thereby a proven field failure. Increasing F3 materially changes upstream fault current and does not remove AP2112 heat or USB-current limits, so retain it pending the explicit service envelope. [Littelfuse primary 1206L sheet](https://www.mouser.com/datasheet/2/240/Littelfuse_PTC_1206L_Datasheet_pdf-2956361.pdf).

[TI TPS1H200A-Q1 RevE, pp 4–7/11/14](https://www.ti.com/lit/ds/symlink/tps1h200a-q1.pdf) explicitly supports IN tied to VS and 100kΩ DELAY-to-VS auto-retry. This is not an overvoltage-input defect. Logic thresholds are 1.8 V high/0.8 V low; UV restart 3.5–4.0 V and shutdown 3.0–3.4 V. The 0.8 V×2500/RCL formula gives 606.06 mA; partial±15%/R±1% gives 510.05–704.01 mA, or 507.01–708.26 mA with 85°C resistor drift. Accuracy requiresVS−OUT≥2.5 V. Retry on 35–45 ms/off 0.8–1.2 s; minimum unloaded charge budget 17.85mC excludes all startup demand. FAULT is unused.

Lowering CL to protect the present 0.5 A diode is not a harmless fix: below a 0.5 A setting TI's±20% regime applies, and a 4.99kΩ choice would have a partial minimum about 317mA, below the published low-input RF-plus-carrier proxies. Conversely the current partial 510mA minimum does not guarantee the 521.66mA linear provision stress. Leave CL and retry settings until startup/source data supports a setting; a larger diode is the bounded rating repair.

The priority circuit senses PIN1_PROTECTED voltage, not U9 output or useful power. An undervoltage, current-limited/retrying or weak PIN1 can inhibit healthy PIN3 while supplying insufficient power. That behavior is demonstrable from the net dependencies; exact crossover voltage and transients depend on Q5/R values/temperature. Changing it to fault-aware selection or a new UV supervisor is a new control/safety choice requiring user review. Preserve the existing automatic presence priority in this repair.

## Remaining defects and decisions

1. **Feasible component edit now:** exact D14/D15 STPS140Z in A/B/C, with K1/A2 retained, corresponding CAD/BOM metadata updated and assembled land approval. This closes the stated part-capacity/junction-rating gap only.
2. **Feasible further local thermal edit after review:** add same-net cathode heat spreading or explore B140 SMA in each revision independently. Current 175/312/220°C/W references do not prove mounted resistance. Case height, installed module envelope, clearances, routes, refill and native DRC must be checked on final CAD.
3. **Retain output diode/module architectures:** A AP2112 is 600mA but has a separate SOT25 thermal gate; at 4.7 V/365.626mA the earlier 0.512W/184°C/W screen is 94°C rise. C3's TLV module has a 500mA series fuse/diode path with unresolved fuse identity and its own LDO heat. C6's SGM6029C is a buck; its internal LMBR4010 diode and module heat remain separate. A larger carrier input diode cannot close these gates.
4. **OEM/bench gates:** establish each PIN1/PIN3 voltage tolerance, continuous/transient current allowance, source impedance and positive/negative fault waveforms. Measure minimum source/protected/V_INPUT/+5V/3V3, peak startup/RF currents, fuse/diode/LDO/buck temperature, and handoff/brownout behavior using the actual enclosure and module lot. Define both 3.3 V target and 3.0 V absolute operating-floor criteria; do not discard nominal 5/7.5/9/13.6 V support to force a pass.
5. **Safety decisions remain open:** The retained CJ3407 has a −30 V drain–source rating. In the exact selected Rev3A/B/C source, D18 cathode 1 is at PIN1_PROTECTED/Q3.source 2 and its anode 2 is GND; the second SMF16A is A D19 or B/C D20, cathode 1 at PIN3_PROTECTED/Q4.source 2 and anode 2 at GND. D13 is absent. Neither fused drain 3 node has a directly connected TVS. An intact unidirectional TVS forward-conducts if its protected source node goes negative, but that connection does not impose a documented negative voltage bound on the fused drain. The exact SUNMATE C399290 sheet publishes no maximum forward voltage/current condition, so a numerical negative clamp cannot be borrowed from another maker. If a protected source were momentarily at +26 V while its fused drain actually reached −13.6 V, VDS would be −39.6 V; this is an unbounded-node, unmeasured transient counterexample, not a demonstrated normal-source condition or a proven failure. Even the +26 V reference belongs to the specified 7.7 A,10/1000 µs,25°C positive-pulse test. Actual drain/source/gate waveforms, source impedance and clamp/current survival must establish the differential before selecting a higher-voltage PMOS. TVS remains upstream of switch CL; the PPTC trip curve alone does not coordinate TVS fault energy. Gate/bias resistors have distinct high-local-temperature limits. No full 40 V carrier rating follows. See PMOS-Transient-Example-Correction.md and pmos-tvs-placement-correction.json for the corrected numbered-node binding.
6. **USB qualification remains revision-specific:** A keeps its original two-diode OR. B/C raw module USB is tied to carrier+5V and must retain the existing disconnect-before-powered-USB operating instruction; a carrier diode change does not add host isolation. A fault-aware fallback, USB-source isolation or regulator/module redesign exceeds this bounded repair.

The accompanying `calculated-bounds.json` and `thermal-reference-screens.csv` expose the arithmetic and assumptions. The original evidence-generation recipe extracted the fixed commit without writing the repository. Source bindings and calculations are retained alongside this report. New PDF retrievals include exact LRC and ST bytes; PMEG/B140/B140HW direct-byte retrieval was blocked, so verified official web-PDF content is used without invented hashes. Prices are unauthenticated catalog observations, not assembly availability or supplier-lot qualification.

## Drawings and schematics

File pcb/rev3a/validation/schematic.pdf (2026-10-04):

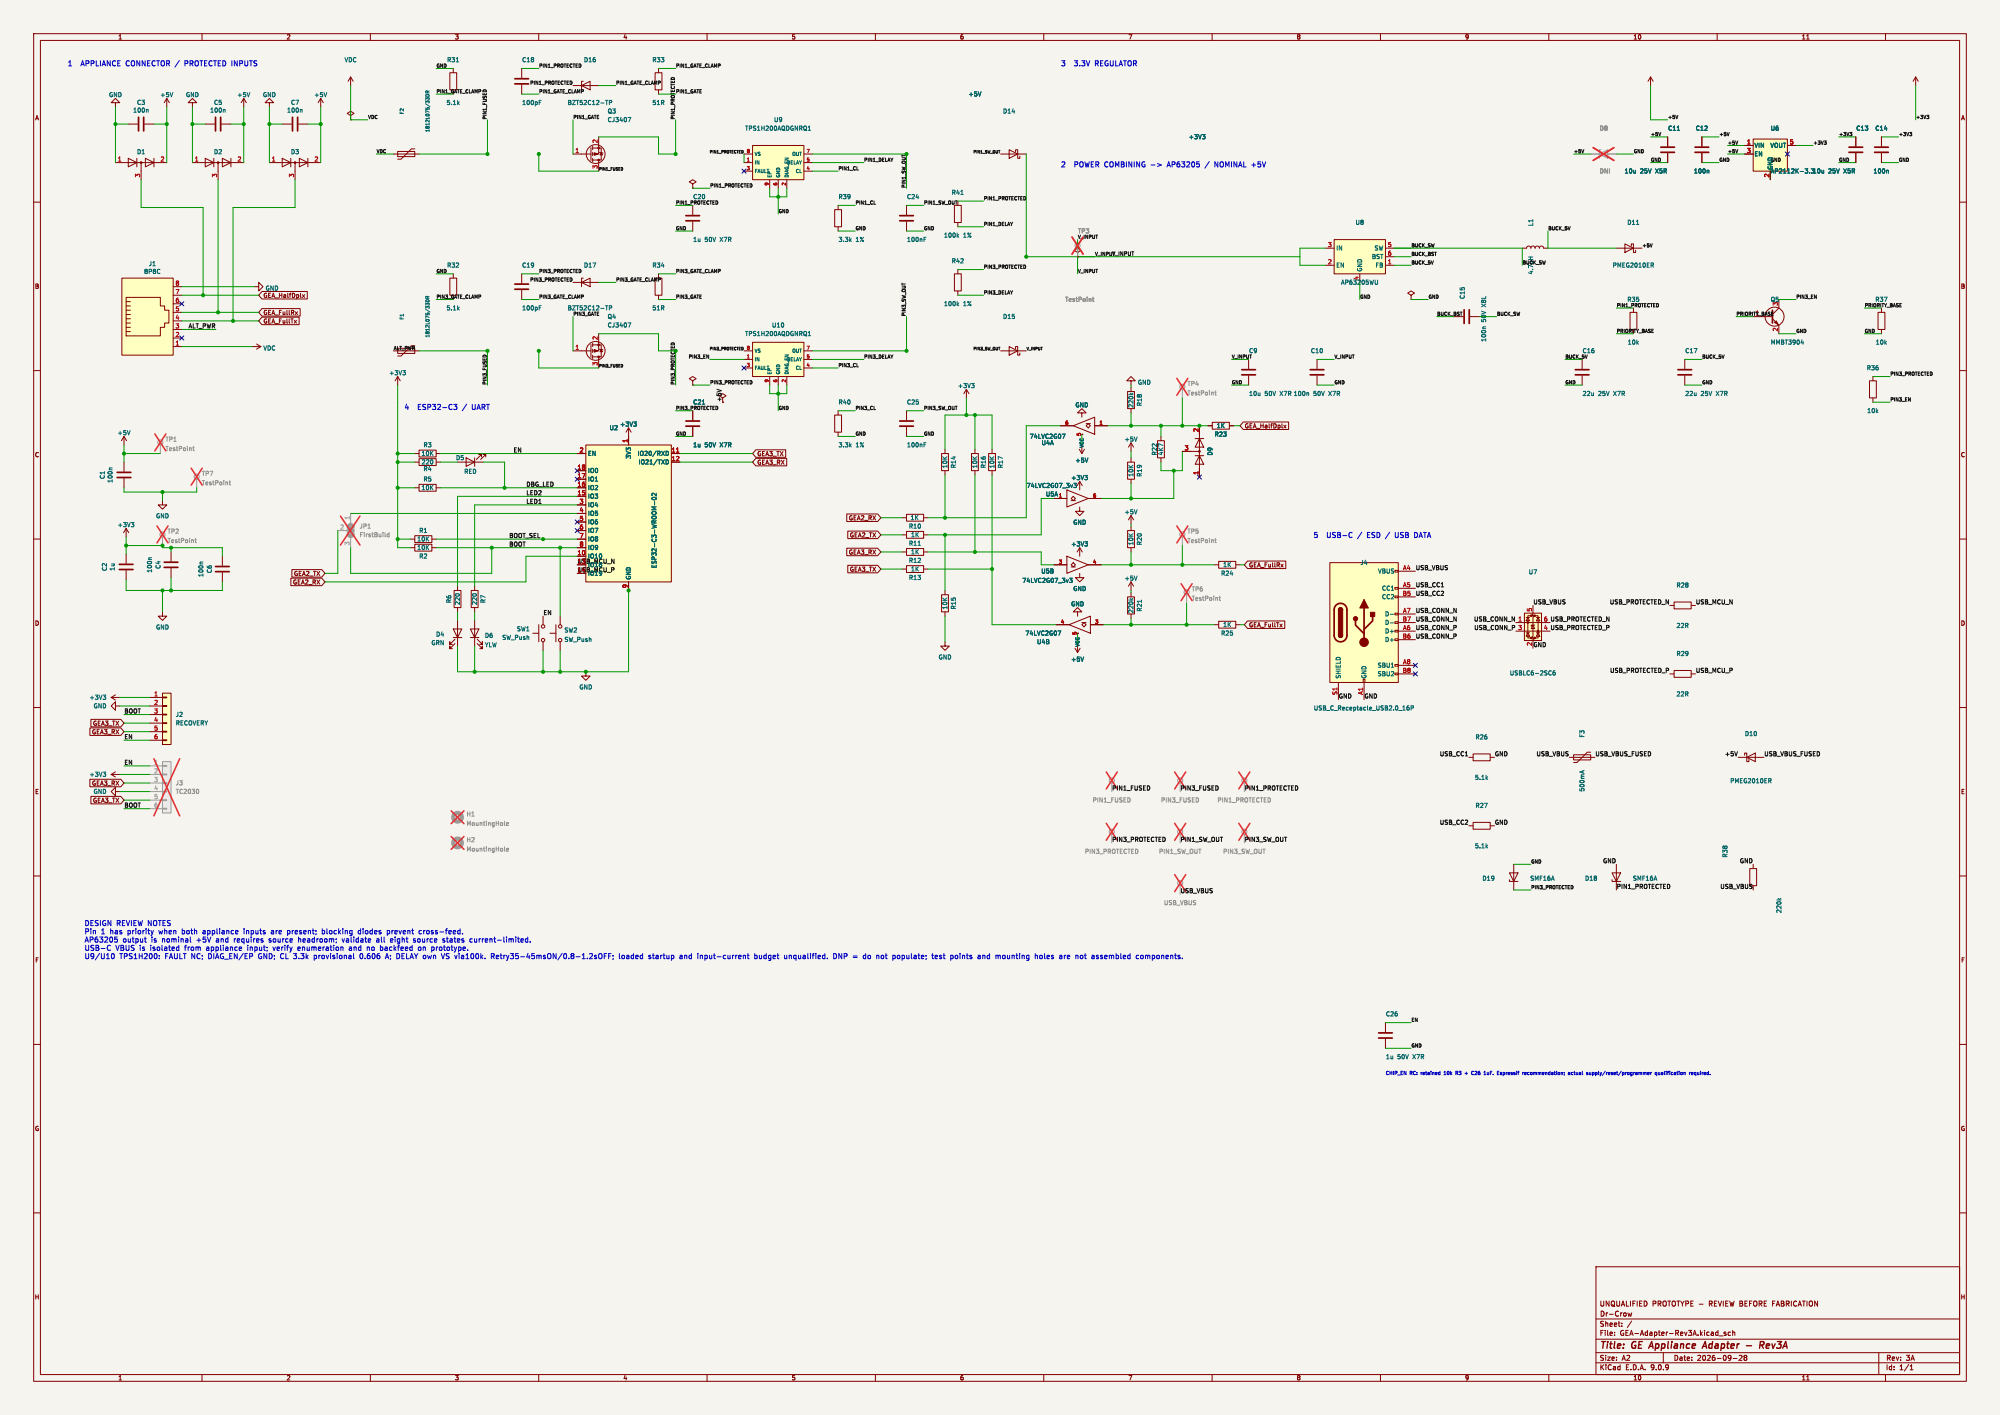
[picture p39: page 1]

PIN3_GATE_CLAMP 1 APPLIANCE CONNECTOR / PROTECTED INPUTS

2 OUT 7 DELAY 5 CL 4 U9 TPS1H200AQDGNRQ1 GND

File: GEA-Adapter-Rev3A.kicad_sch Sheet: / Dr-Crow

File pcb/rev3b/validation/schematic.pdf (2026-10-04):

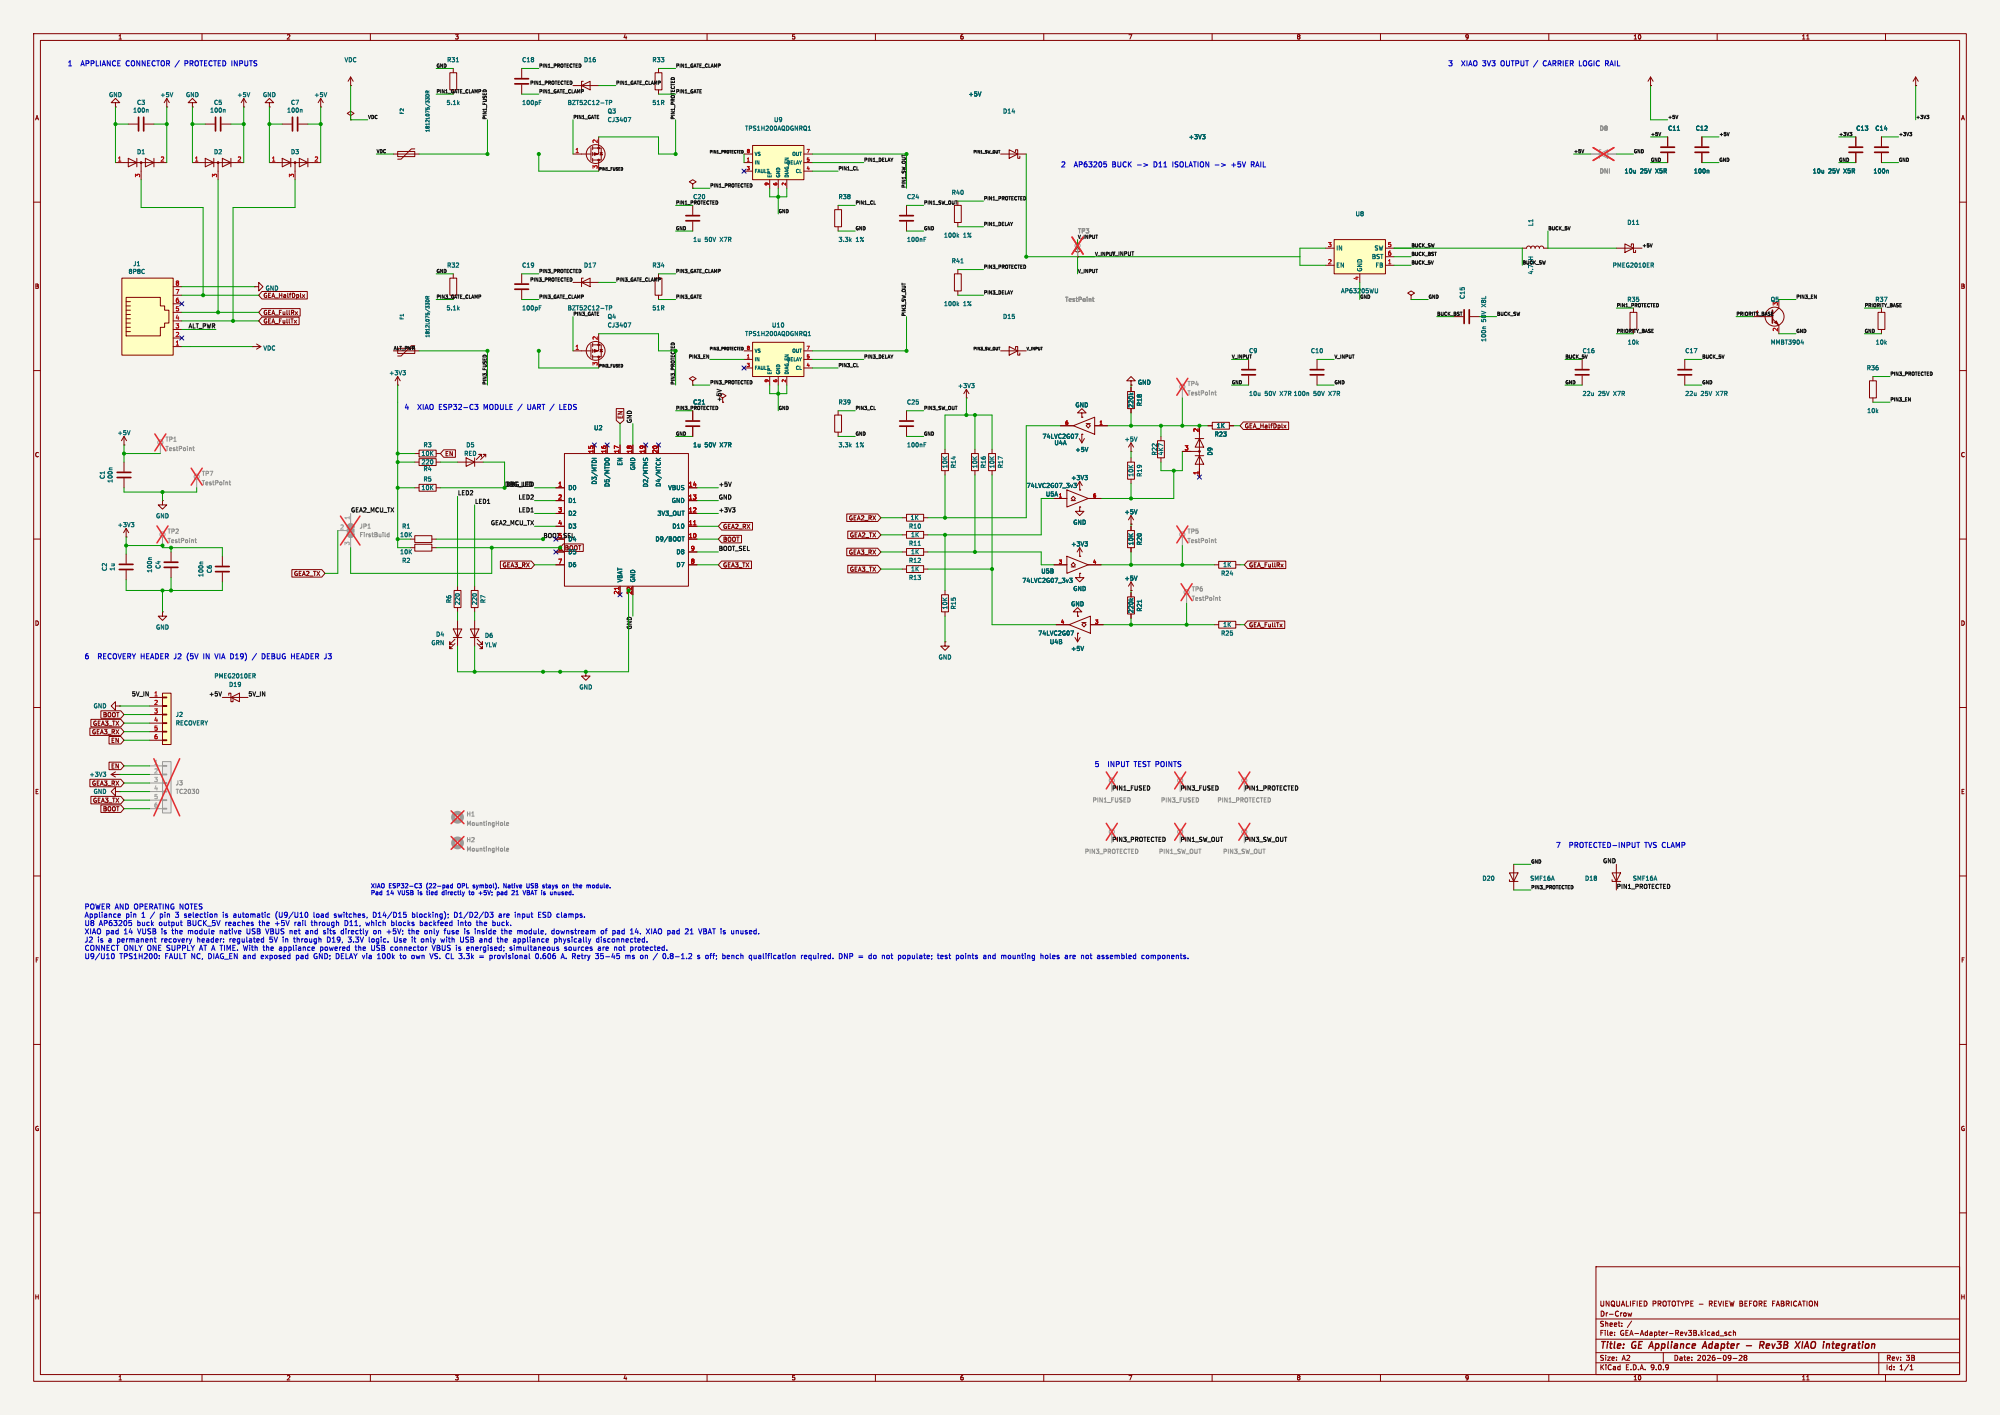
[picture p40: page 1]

1 APPLIANCE CONNECTOR / PROTECTED INPUTS

3 XIAO 3V3 OUTPUT / CARRIER LOGIC RAIL

2 OUT 7 DELAY 5 CL 4 U10 TPS1H200AQDGNRQ1 D17 BZT52C12-TP

6 RECOVERY HEADER J2 (5V IN VIA D19) / DEBUG HEADER J3

7 PROTECTED-INPUT TVS CLAMP

File: GEA-Adapter-Rev3B.kicad_sch Sheet: / Dr-Crow

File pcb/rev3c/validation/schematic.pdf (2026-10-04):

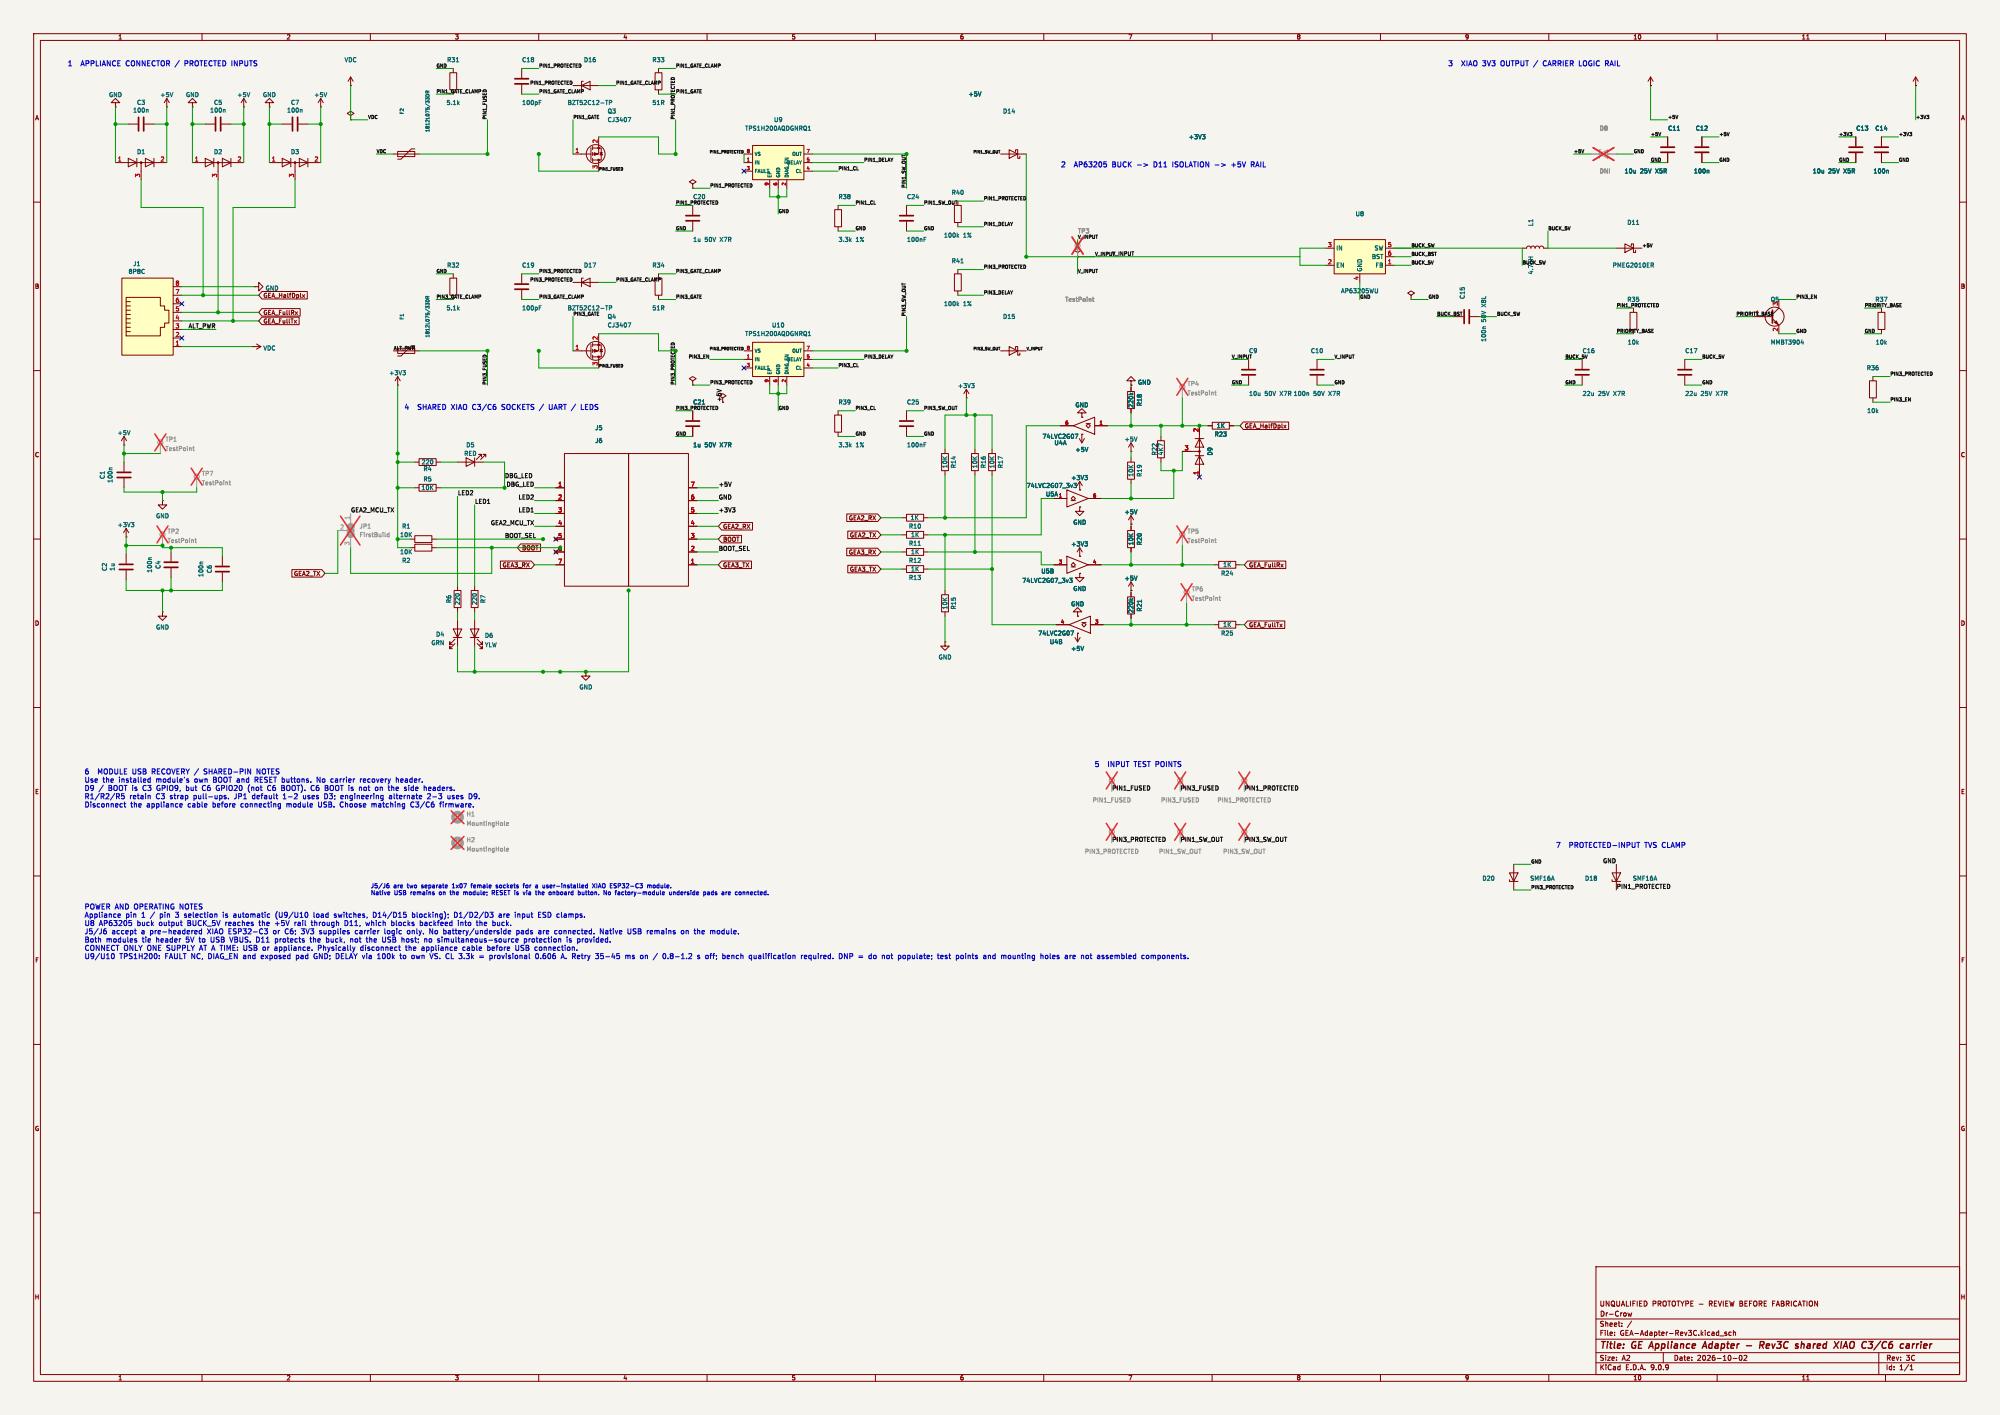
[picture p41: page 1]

1 APPLIANCE CONNECTOR / PROTECTED INPUTS

3 XIAO 3V3 OUTPUT / CARRIER LOGIC RAIL

4 SHARED XIAO C3/C6 SOCKETS / UART / LEDS

7 PROTECTED-INPUT TVS CLAMP

POWER AND OPERATING NOTES

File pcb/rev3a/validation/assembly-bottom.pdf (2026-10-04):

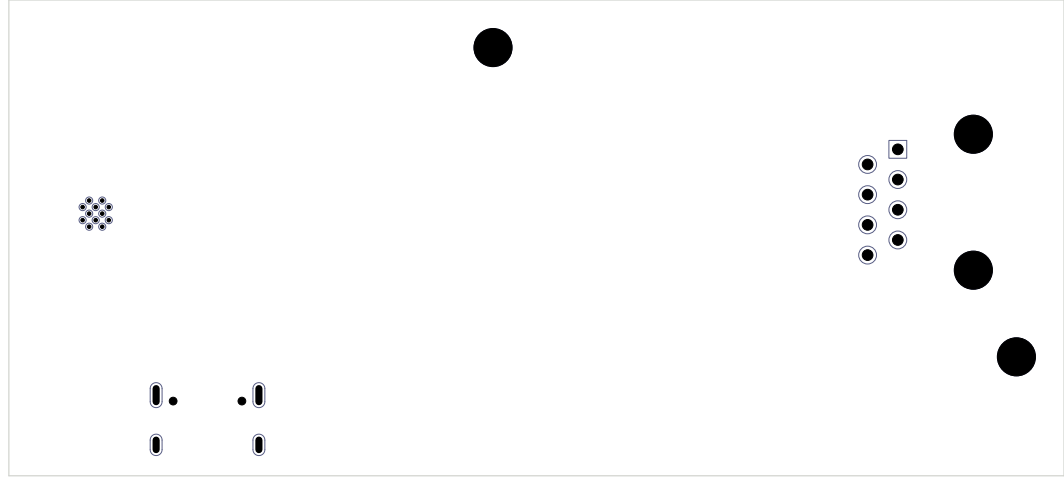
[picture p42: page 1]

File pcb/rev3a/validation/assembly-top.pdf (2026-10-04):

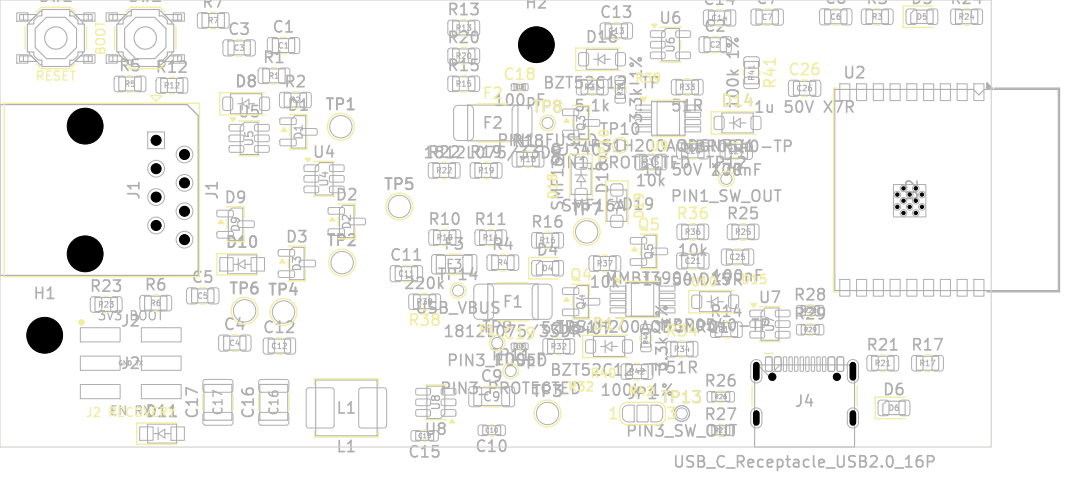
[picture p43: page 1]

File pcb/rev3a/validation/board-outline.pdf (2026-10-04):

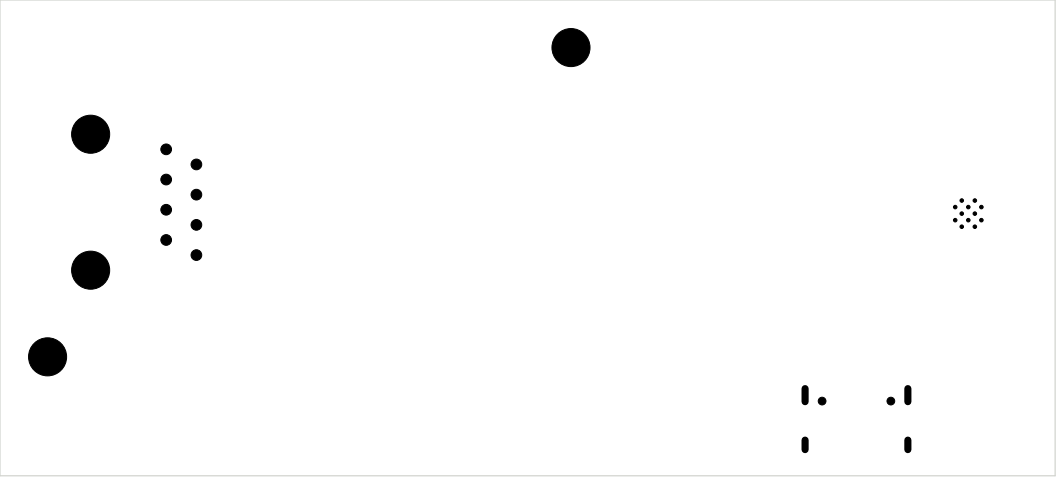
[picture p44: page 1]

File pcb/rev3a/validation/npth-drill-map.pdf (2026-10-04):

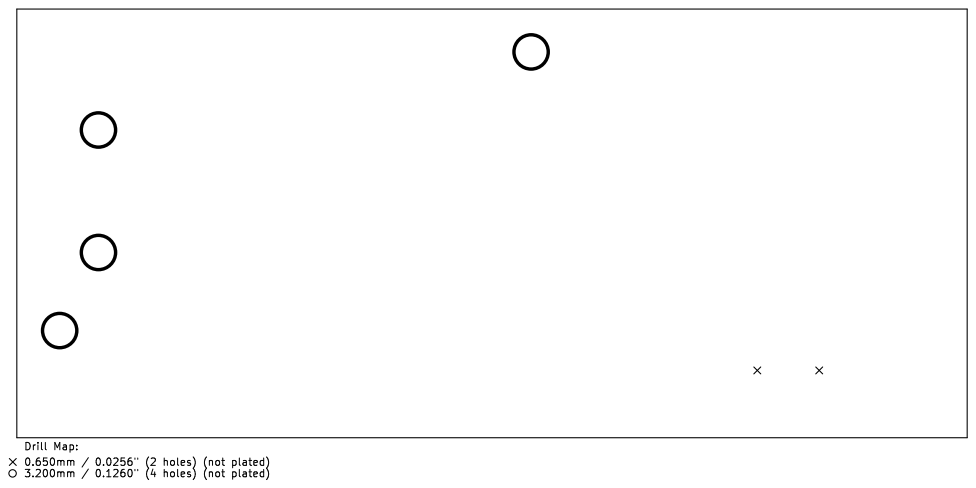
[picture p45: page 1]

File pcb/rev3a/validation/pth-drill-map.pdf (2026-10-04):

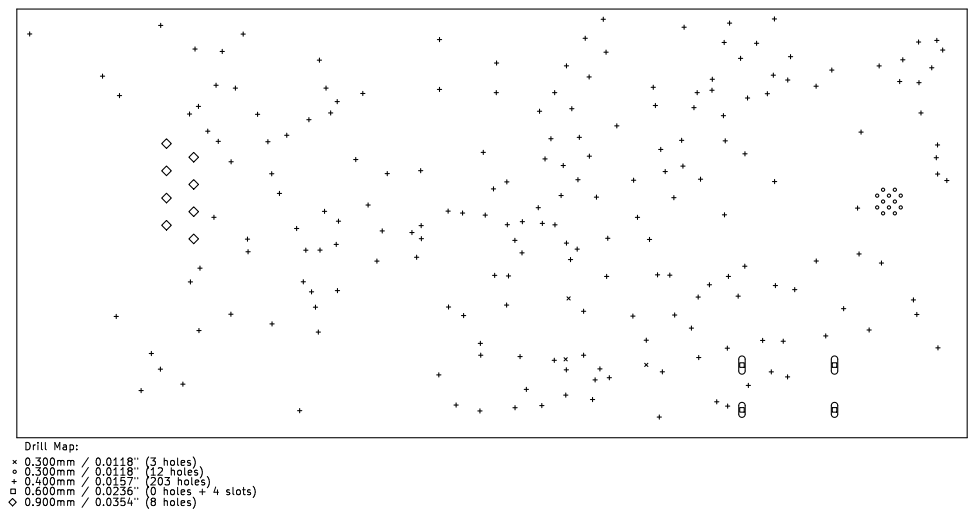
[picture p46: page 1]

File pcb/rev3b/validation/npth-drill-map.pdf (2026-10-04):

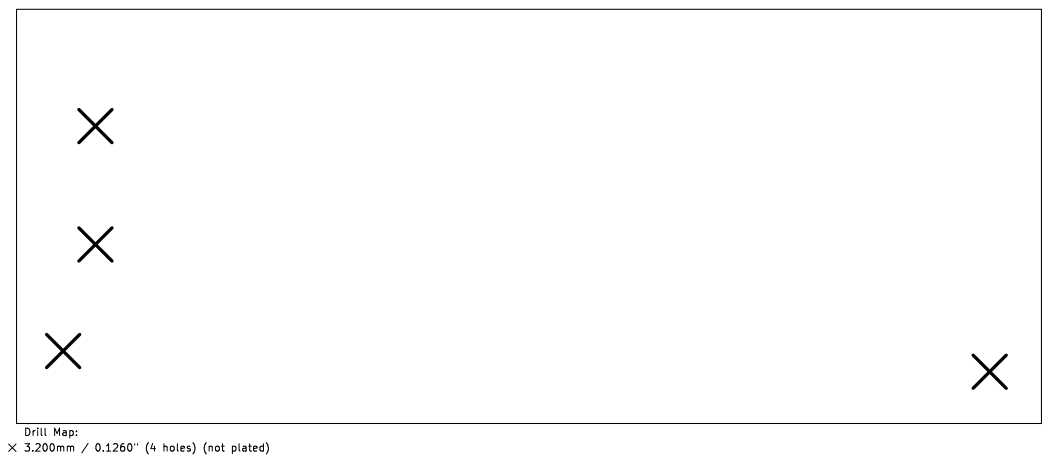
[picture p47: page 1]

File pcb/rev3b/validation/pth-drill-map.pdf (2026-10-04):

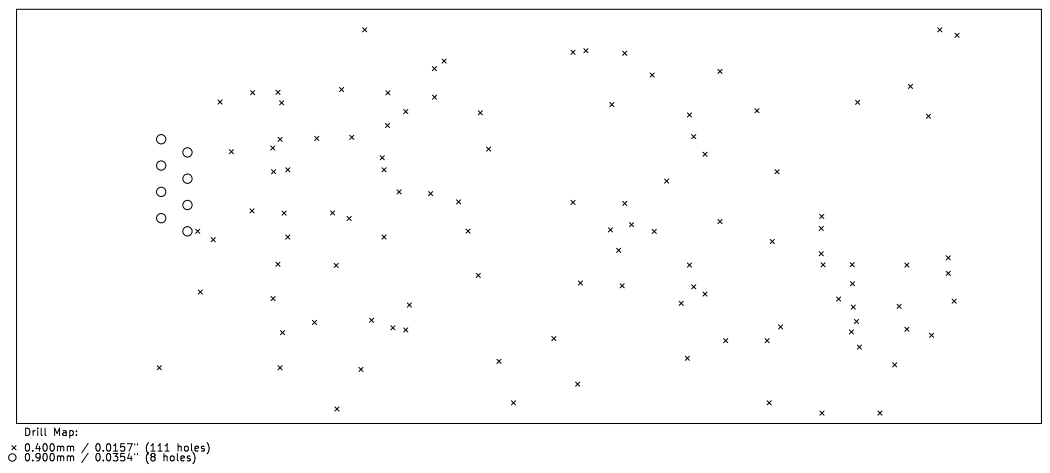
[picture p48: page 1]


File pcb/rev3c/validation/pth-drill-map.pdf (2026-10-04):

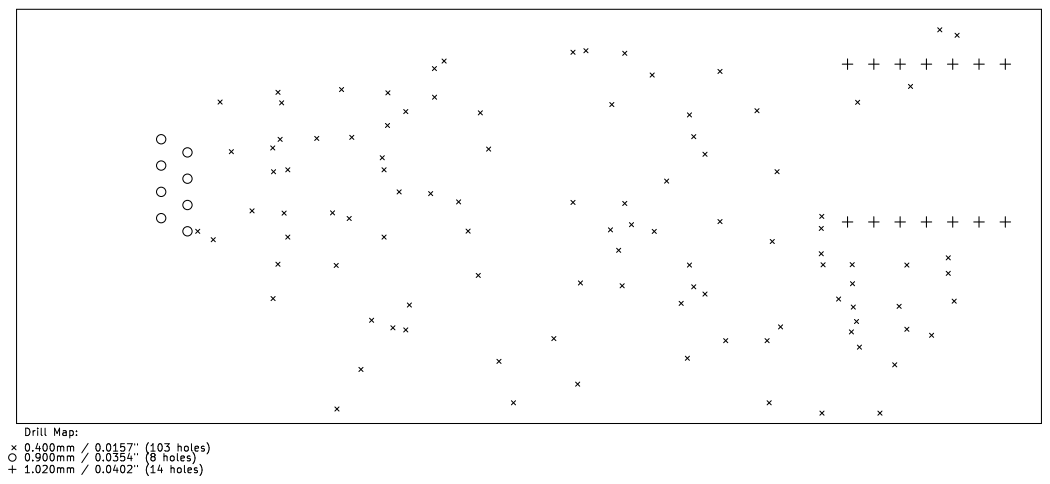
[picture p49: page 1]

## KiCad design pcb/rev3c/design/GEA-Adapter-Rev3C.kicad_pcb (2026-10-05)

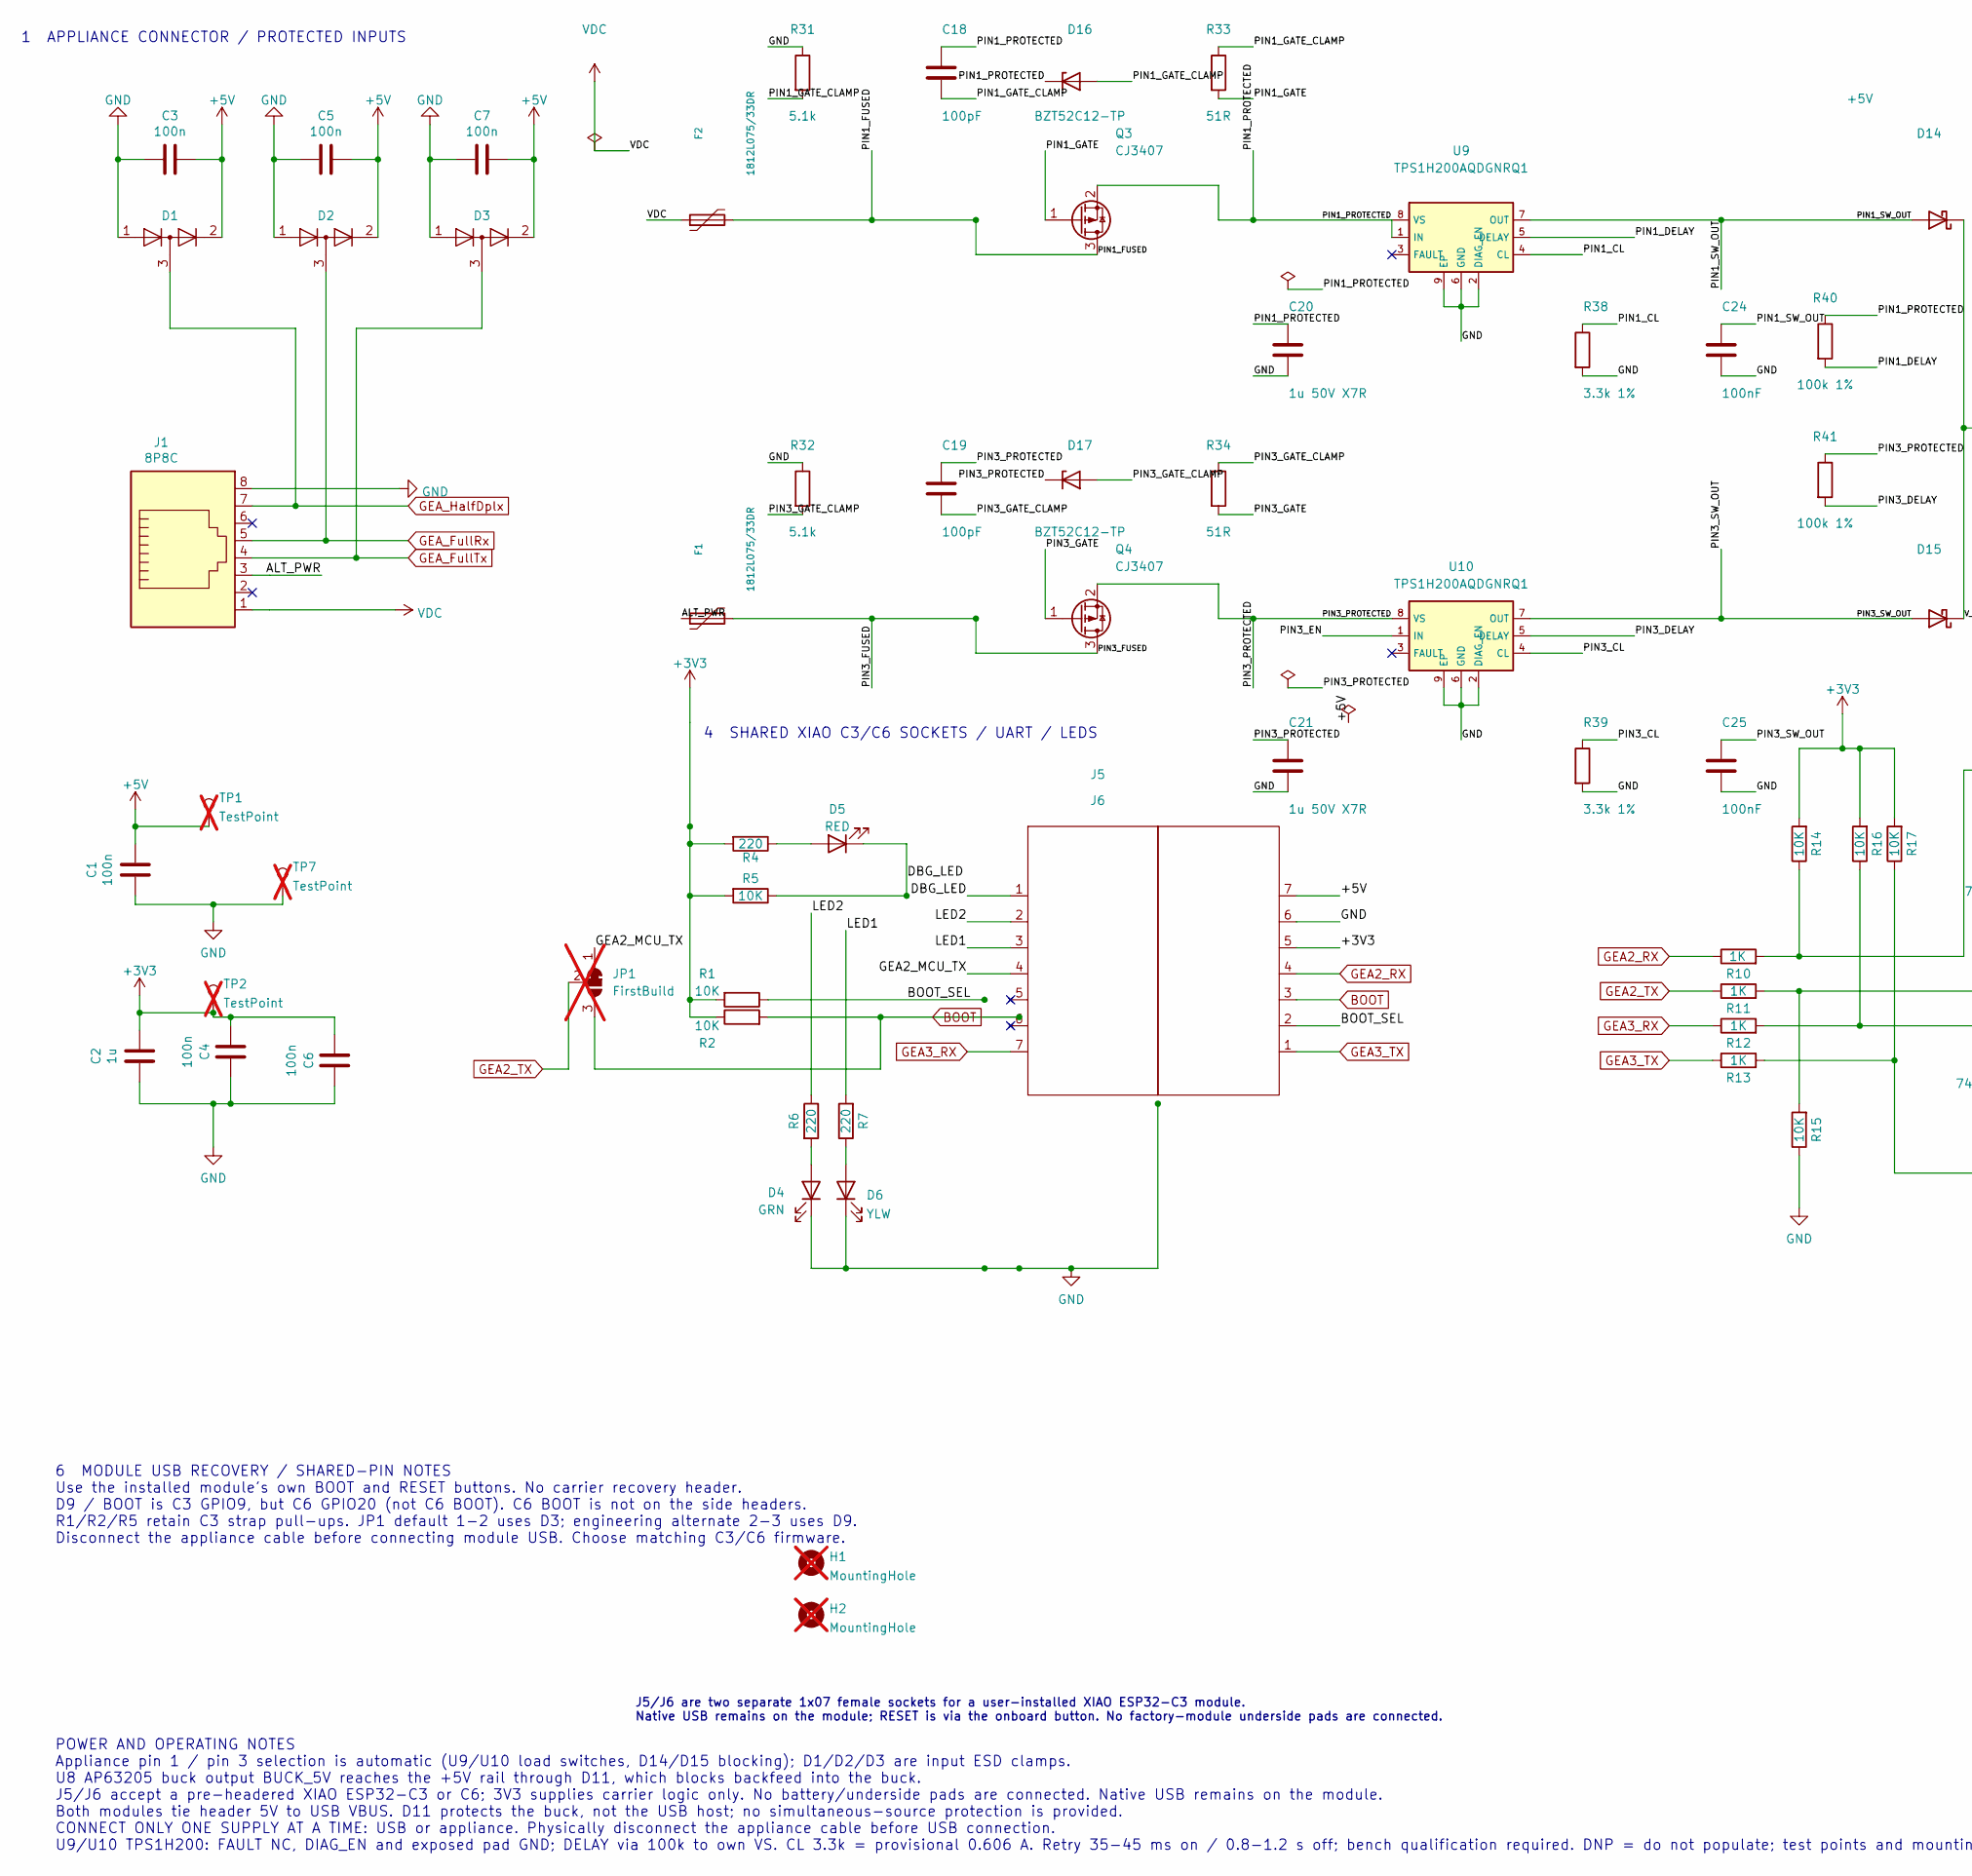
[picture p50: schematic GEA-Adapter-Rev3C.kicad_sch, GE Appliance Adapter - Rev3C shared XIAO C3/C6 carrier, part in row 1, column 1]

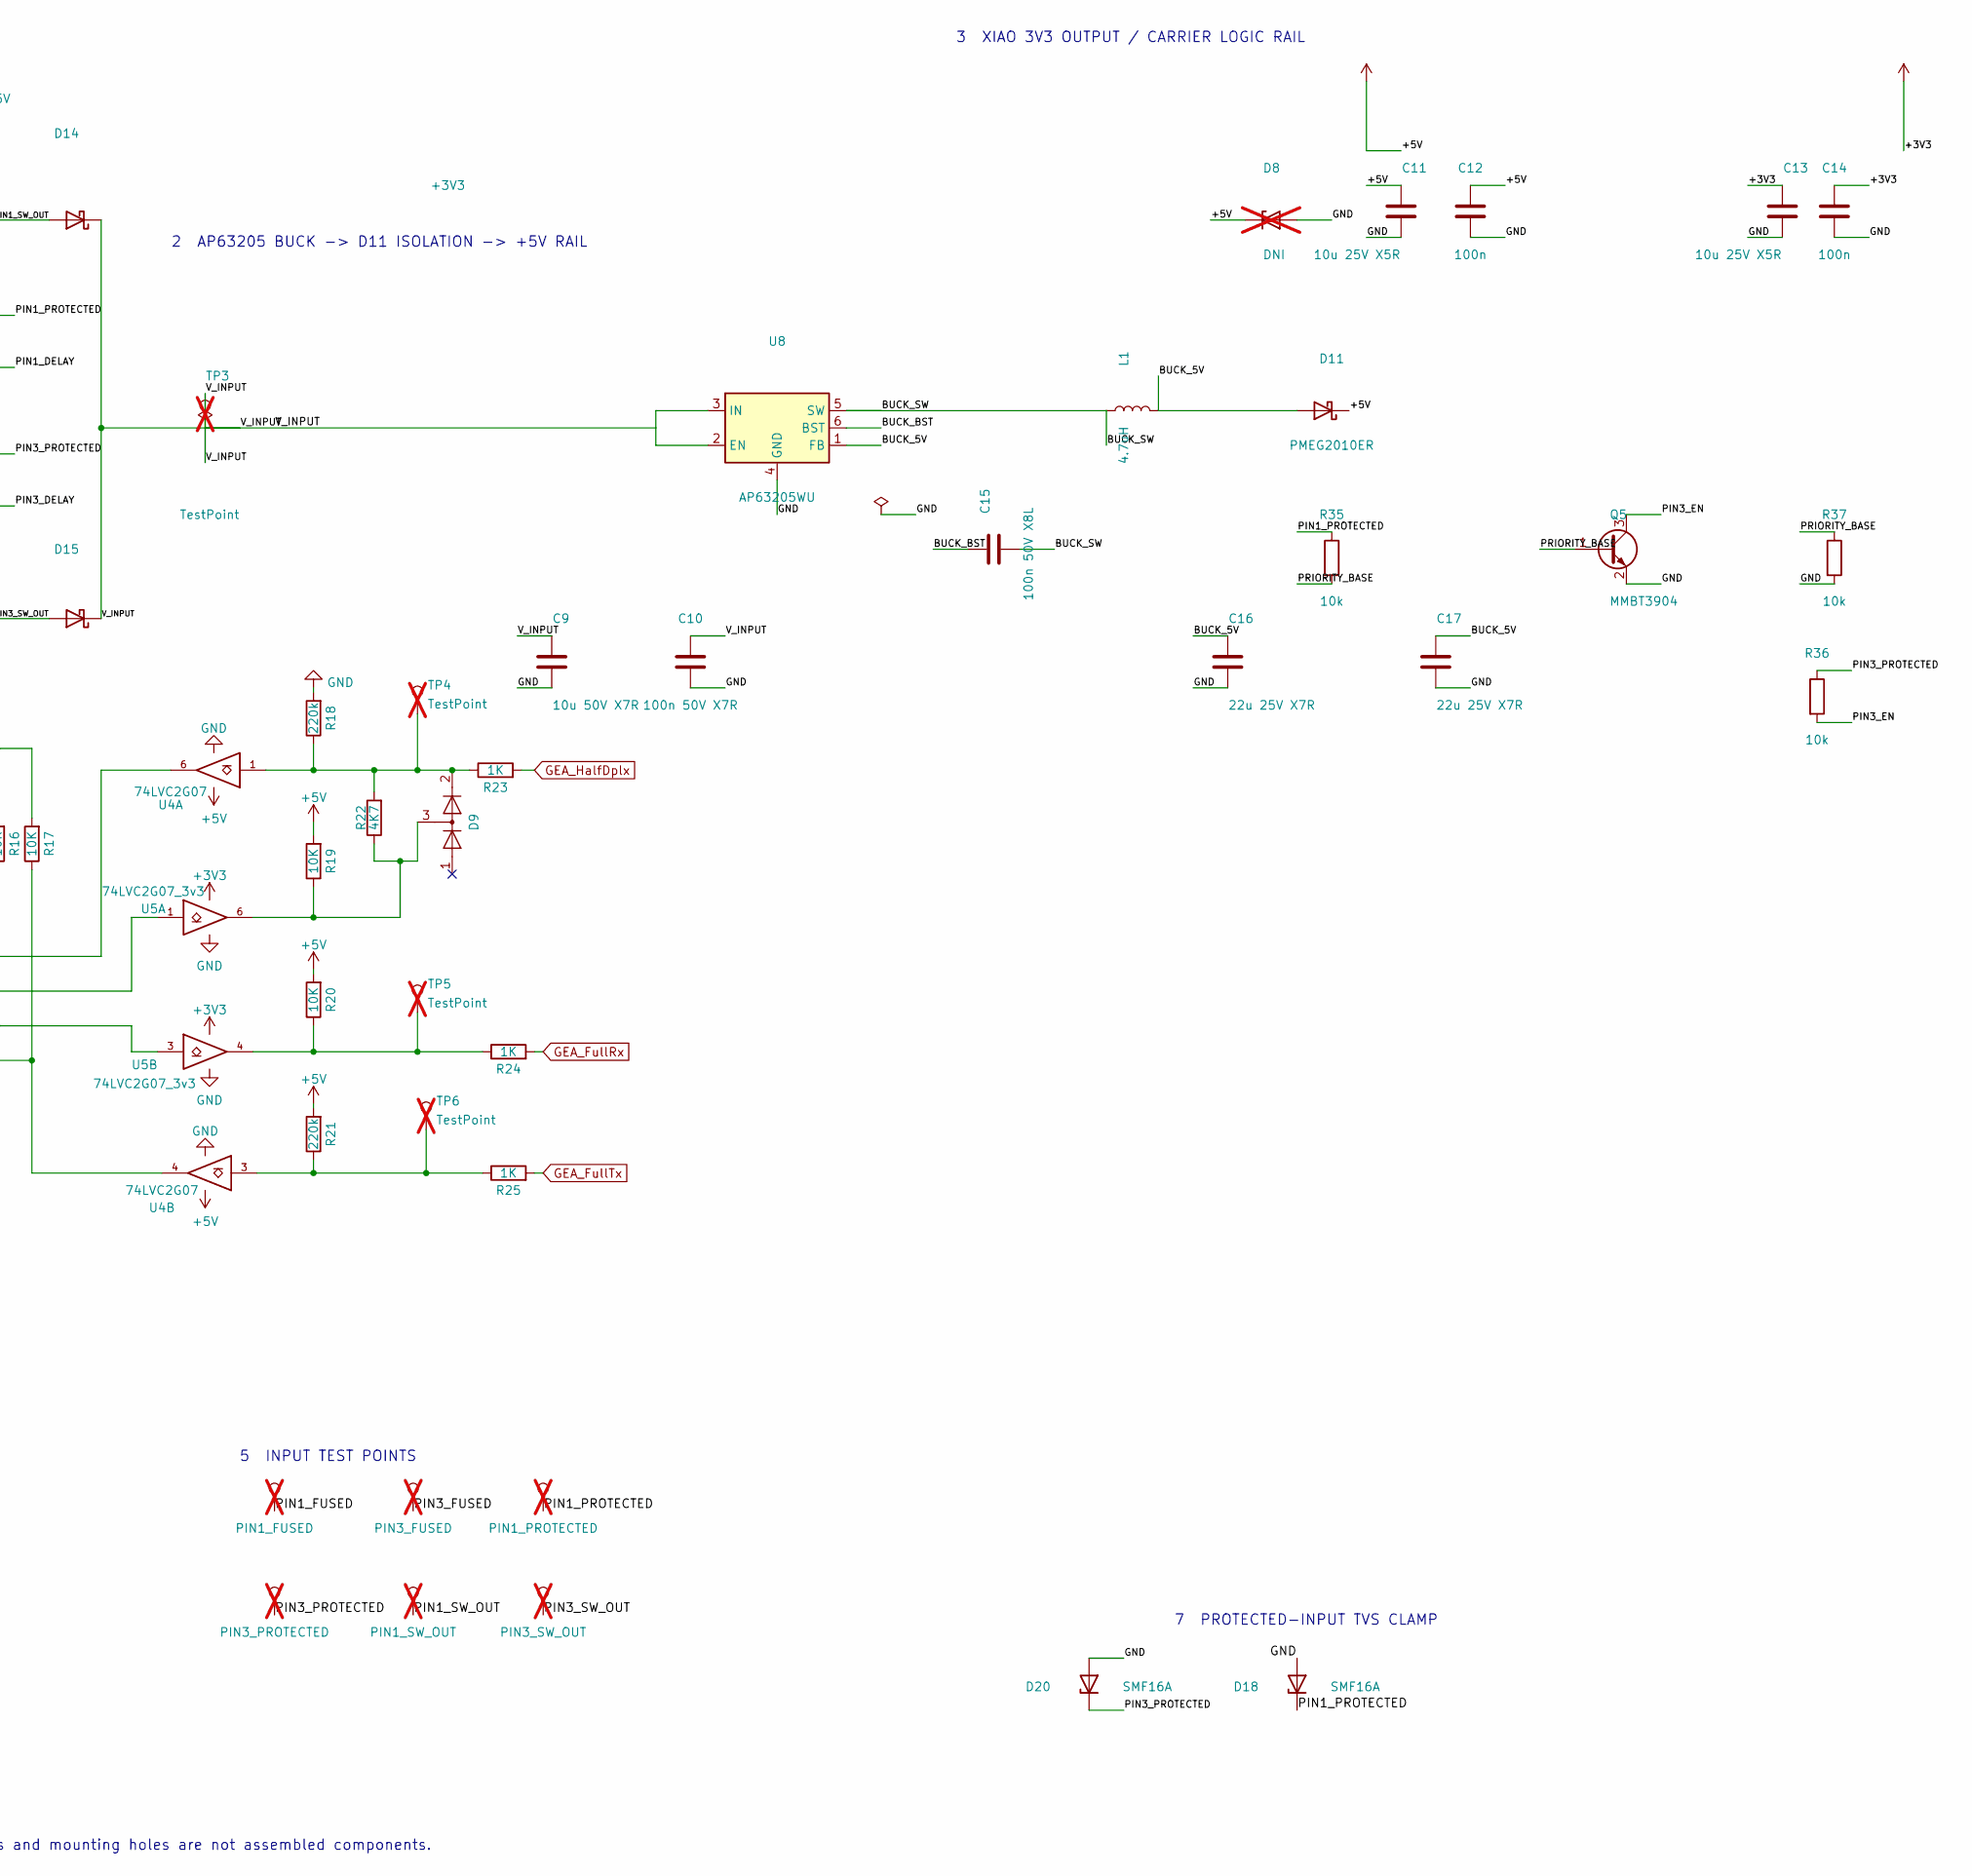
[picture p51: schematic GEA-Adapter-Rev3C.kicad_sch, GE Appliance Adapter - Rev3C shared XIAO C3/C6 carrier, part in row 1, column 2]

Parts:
C1, C3, C4, C5, C6, C7, C12, C14: 100n; C_0805_2012Metric; MPN CC0805KKX7R0BB104; LCSC C106243
C2: 1u; C_0805_2012Metric; MPN CC0805KKX7R9BB105; LCSC C91185
C9: 10u 50V X7R; C_1206_3216Metric; Voltage 50V; MPN 1206B106K500NT; LCSC C303950
C10: 100n 50V X7R; C_0603_1608Metric; Voltage 50V; MPN 0603B104M500NT; LCSC C286510
C11, C13: 10u 25V X5R; C_0805_2012Metric; MPN CL21A106KAYNNNE; LCSC C15850
C15: 100n 50V X8L; C_0603_1608Metric; Voltage 50V; MPN GCM188L81H104KA57D; LCSC C161181
C16, C17: 22u 25V X7R; C_1210_3225Metric; Voltage 25V; Tolerance 10%; MPN CL32B226KAJNNNE; LCSC C309062
C18, C19: 100pF; C_0402_1005Metric; MPN 0402CG101J500NT; LCSC C1546
C20, C21: 1u 50V X7R; C_0805_2012Metric; MPN CC0805KKX7R9BB105; LCSC C91185
C24, C25: 100nF; C_0805_2012Metric; MPN CC0805KKX7R0BB104; LCSC C106243
D1, D2, D3, D9: BAV99; SOT-23; MPN BAV99,215; LCSC C2500
D4: GRN; LED_0805_2012Metric; MPN KT-0805G; LCSC C2297
D5: RED; LED_0805_2012Metric; MPN NCD0805R1; LCSC C84256
D6: YLW; LED_0805_2012Metric; MPN KT-0805Y; LCSC C2296
D8: DNI; D_SOD-123; not fitted
D11: PMEG2010ER; Nexperia_CFP3_SOD-123W; MPN PMEG2010ER,115; LCSC C82288
D14, D15: STPS140Z; D_SOD-123; MPN STPS140Z; LCSC C155662
D16, D17: BZT52C12-TP; D_SOD-123; MPN BZT52C12-TP; LCSC C668891
D18, D20: SMF16A; D_SOD-123F; MPN SMF16A; LCSC C399290
F1, F2: 1812L075/33DR; Fuse_Littelfuse_1812L_Recommended; MPN 1812L075/33DR; LCSC C151170
H1, H2: MountingHole; MountingHole_3.2mm_M3_DIN965; not fitted
J1: 8P8C; RJ45_EVERCOM_5301-8P8C_Horizontal; MPN 5301-8P8C; LCSC C3097717
J5: Socket_XIAO_A; Socket_1x07_P2.54mm_HCTL_PM254; MPN PM254-1-07-Z-8.5; LCSC C2897370
J6: Socket_XIAO_B; Socket_1x07_P2.54mm_HCTL_PM254; MPN PM254-1-07-Z-8.5; LCSC C2897370
JP1: FirstBuild; SolderJumper-3_P1.3mm_Bridged12_RoundedPad1.0x1.5mm_NumberL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; not fitted
L1: 4.7uH; L_Panasonic_PCC-M0530M; MPN ETQP3M4R7KVP; LCSC C412309
Q3, Q4: CJ3407; SOT-23; MPN CJ3407; LCSC C15903
Q5: MMBT3904; SOT-23; MPN MMBT3904; LCSC C20526
R1, R2, R5, R14, R15, R16, R17, R19, R20: 10K; R_0805_2012Metric; MPN 0805W8F1002T5E; LCSC C17414
R4, R6, R7: 220; R_0805_2012Metric; MPN 0805W8F2200T5E; LCSC C17557
R10, R11, R12, R13, R23, R24, R25: 1K; R_0805_2012Metric; MPN 0805W8F1001T5E; LCSC C17513
R18, R21: 220k; R_0805_2012Metric; MPN RTT052203FTP; LCSC C104108
R22: 4K7; R_0805_2012Metric; MPN 0805W8F4701T5E; LCSC C17673
R31, R32: 5.1k; R_0805_2012Metric; MPN 0805W8F5101T5E; LCSC C27834
R33, R34: 51R; R_0805_2012Metric; MPN 0805W8F510JT5E; LCSC C17738
R35, R36, R37: 10k; R_0805_2012Metric; MPN 0805W8F1002T5E; LCSC C17414
R38, R39: 3.3k 1%; R_0603_1608Metric; MPN 0603WAF3301T5E; LCSC C22978
R40, R41: 100k 1%; R_0805_2012Metric; MPN 0805W8F1003T5E; LCSC C149504
TP1, TP2, TP3, TP4, TP5, TP6, TP7: TestPoint; TestPoint_Pad_D2.0mm; not fitted
TP8: PIN1_FUSED; TestPoint_Pad_D1.0mm; not fitted
TP9: PIN3_FUSED; TestPoint_Pad_D1.0mm; not fitted
TP10: PIN1_PROTECTED; TestPoint_Pad_D1.0mm; not fitted
TP11: PIN3_PROTECTED; TestPoint_Pad_D1.0mm; not fitted
TP12: PIN1_SW_OUT; TestPoint_Pad_D1.0mm; not fitted
TP13: PIN3_SW_OUT; TestPoint_Pad_D1.0mm; not fitted
U4: 74LVC2G07; SOT-23-6; MPN 74LVC2G07W6-7; LCSC C151607
U5: 74LVC2G07_3v3; SOT-23-6; MPN 74LVC2G07W6-7; LCSC C151607
U8: AP63205WU; TSOT-23-6; MPN AP63205WU-7; LCSC C2071056
U9, U10: TPS1H200AQDGNRQ1; TPS1H200A_DGN0008K_TI_RevE; MPN TPS1H200AQDGNRQ1; LCSC C2653785

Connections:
+3V3: C2.1, C4.2, C6.2, C13.1, C14.2, J6.5 (3V3_OUT), R1.2, R2.1, R4.2, R5.2, R14.2, R16.2, R17.2, TP2.1, U5.5 (+3V3)
+5V: C1.1, C3.1, C5.1, C7.1, C11.1, C12.2, D1.2 (A), D2.2 (A), D3.2 (A), D8.1 (K), D11.1 (K), J6.7 (VBUS), R19.2, R20.2, R21.2, TP1.1, U4.5 (VCC)
/ALT_PWR: F1.1, J1.3
/BOOT_SEL: J6.2 (BOOT_SEL), R1.1
/BUCK_5V: C16.1, C17.1, D11.2 (A), L1.2, U8.1 (FB)
/BUCK_BST: C15.1, U8.6 (BST)
/BUCK_SW: C15.2, L1.1, U8.5 (SW)
/DBG_LED: D5.1 (K), J5.1 (DBG_LED), R5.1
/GEA2_MCU_TX: J5.4 (GEA2_MCU_TX), JP1.1 (A)
/LED1: J5.3 (LED1), R7.2
/LED2: J5.2 (LED2), R6.1
/PIN1_CL: R38.1, U9.4 (CL)
/PIN1_DELAY: R40.2, U9.5 (DELAY)
/PIN1_FUSED: F2.2, Q3.3 (D), TP8.1
/PIN1_GATE: Q3.1 (G), R33.2
/PIN1_GATE_CLAMP: C18.2, D16.2 (A), R31.2, R33.1
/PIN1_PROTECTED: C18.1, C20.1, D16.1 (K), D18.1 (K), Q3.2 (S), R35.1, R40.1, TP10.1, U9.1 (IN), U9.8 (VS)
/PIN1_SW_OUT: C24.1, D14.2 (A), TP12.1, U9.7 (OUT)
/PIN3_CL: R39.1, U10.4 (CL)
/PIN3_DELAY: R41.2, U10.5 (DELAY)
/PIN3_EN: Q5.3 (C), R36.2, U10.1 (IN)
/PIN3_FUSED: F1.2, Q4.3 (D), TP9.1
/PIN3_GATE: Q4.1 (G), R34.2
/PIN3_GATE_CLAMP: C19.2, D17.2 (A), R32.2, R34.1
/PIN3_PROTECTED: C19.1, C21.1, D17.1 (K), D20.1 (K), Q4.2 (S), R36.1, R41.1, TP11.1, U10.8 (VS)
/PIN3_SW_OUT: C25.1, D15.2 (A), TP13.1, U10.7 (OUT)
/PRIORITY_BASE: Q5.1 (B), R35.2, R37.1
/V_INPUT: C9.1, C10.2, D14.1 (K), D15.1 (K), TP3.1, U8.2 (EN), U8.3 (IN)
BOOT: J6.3 (BOOT), JP1.3 (B), R2.2
GEA2_RX: J6.4 (GEA2_RX), R10.1
GEA2_TX: JP1.2 (C), R11.1
GEA3_RX: J5.7 (GEA3_RX), R12.1
GEA3_TX: J6.1 (GEA3_TX), R13.1
GEA_FullRx: D2.3 (K), J1.5, R24.2
GEA_FullTx: D3.3 (K), J1.4, R25.2
GEA_HalfDplx: D1.3 (K), J1.7, R23.2
GND: C1.2, C2.2, C3.2, C4.1, C5.2, C6.1, C7.2, C9.2, C10.1, C11.2, C12.1, C13.2, C14.1, C16.2, C17.2, C20.2, C21.2, C24.2, C25.2, D1.1 (K), D2.1 (K), D3.1 (K), D4.1 (K), D6.1 (K), D8.2 (A), D18.2 (A), D20.2 (A), J1.8, J6.6 (GND), Q5.2 (E), R15.1, R18.2, R31.1, R32.1, R37.2, R38.2, R39.2, TP7.1, U4.2 (GND), U5.2 (GND), U8.4 (GND), U9.2 (DIAG_EN), U9.6 (GND), U9.9 (EP), U10.2 (DIAG_EN), U10.6 (GND), U10.9 (EP)
unnamed: D4.2 (A), R6.2
unnamed: D5.2 (A), R4.1
unnamed: D6.2 (A), R7.1
unnamed: D9.3 (K), R19.1, R22.1, U5.6
unnamed: D9.2 (A), R18.1, R22.2, R23.1, TP4.1, U4.1
unnamed: R10.2, R14.1, U4.6
unnamed: R11.2, R15.2, U5.1
unnamed: R12.2, R16.1, U5.3
unnamed: R13.2, R17.1, U4.4
unnamed: R20.1, R24.1, TP5.1, U5.4
unnamed: R21.1, R25.1, TP6.1, U4.3
VDC: F2.1, J1.1

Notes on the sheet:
1 APPLIANCE CONNECTOR / PROTECTED INPUTS
2 AP63205 BUCK -> D11 ISOLATION -> +5V RAIL
3 XIAO 3V3 OUTPUT / CARRIER LOGIC RAIL
4 SHARED XIAO C3/C6 SOCKETS / UART / LEDS
6 MODULE USB RECOVERY / SHARED-PIN NOTES Use the installed module's own BOOT and RESET buttons. No carrier recovery header. D9 / BOOT is C3 GPIO9, but C6 GPIO20 (not C6 BOOT). C6 BOOT is not on the side headers. R1/R2/R5 retain C3 strap pull-ups. JP1 default 1-2 uses D3; engineering alternate 2-3 u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
7 PROTECTED-INPUT TVS CLAMP
5 INPUT TEST POINTS
POWER AND OPERATING NOTES Appliance pin 1 / pin 3 selection is automatic (U9/U10 load switches, D14/D15 blocking); D1/D2/D3 are input ESD clamps. U8 AP63205 buck output BUCK_5V reaches the +5V rail through D11, which blocks backfeed into the buck. J5/J6 accept a pre-headered XIAO ESP32-C3 or C6; 3V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
J5/J6 are two separate 1x07 female sockets for a user-installed XIAO ESP32-C3 module. Native USB remains on the module; RESET is via the onboard button. No factory-module underside pads are connected.

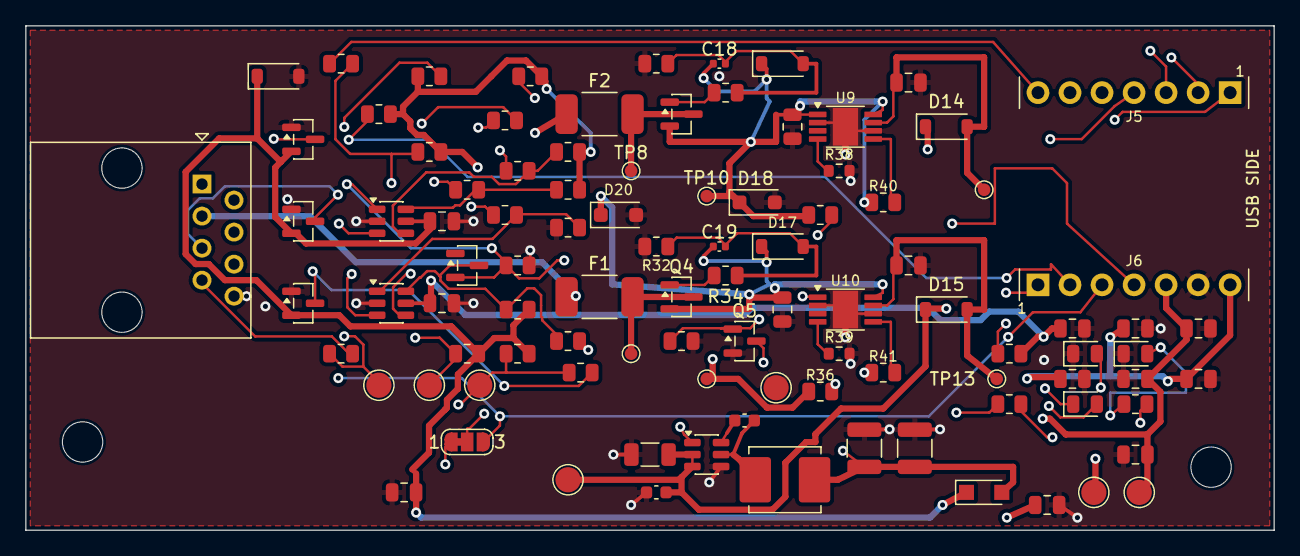
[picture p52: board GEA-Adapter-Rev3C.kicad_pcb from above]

Board: 4 copper layers, 99.0 x 40.0 mm, 100 parts (0 on the bottom side), 49 nets.

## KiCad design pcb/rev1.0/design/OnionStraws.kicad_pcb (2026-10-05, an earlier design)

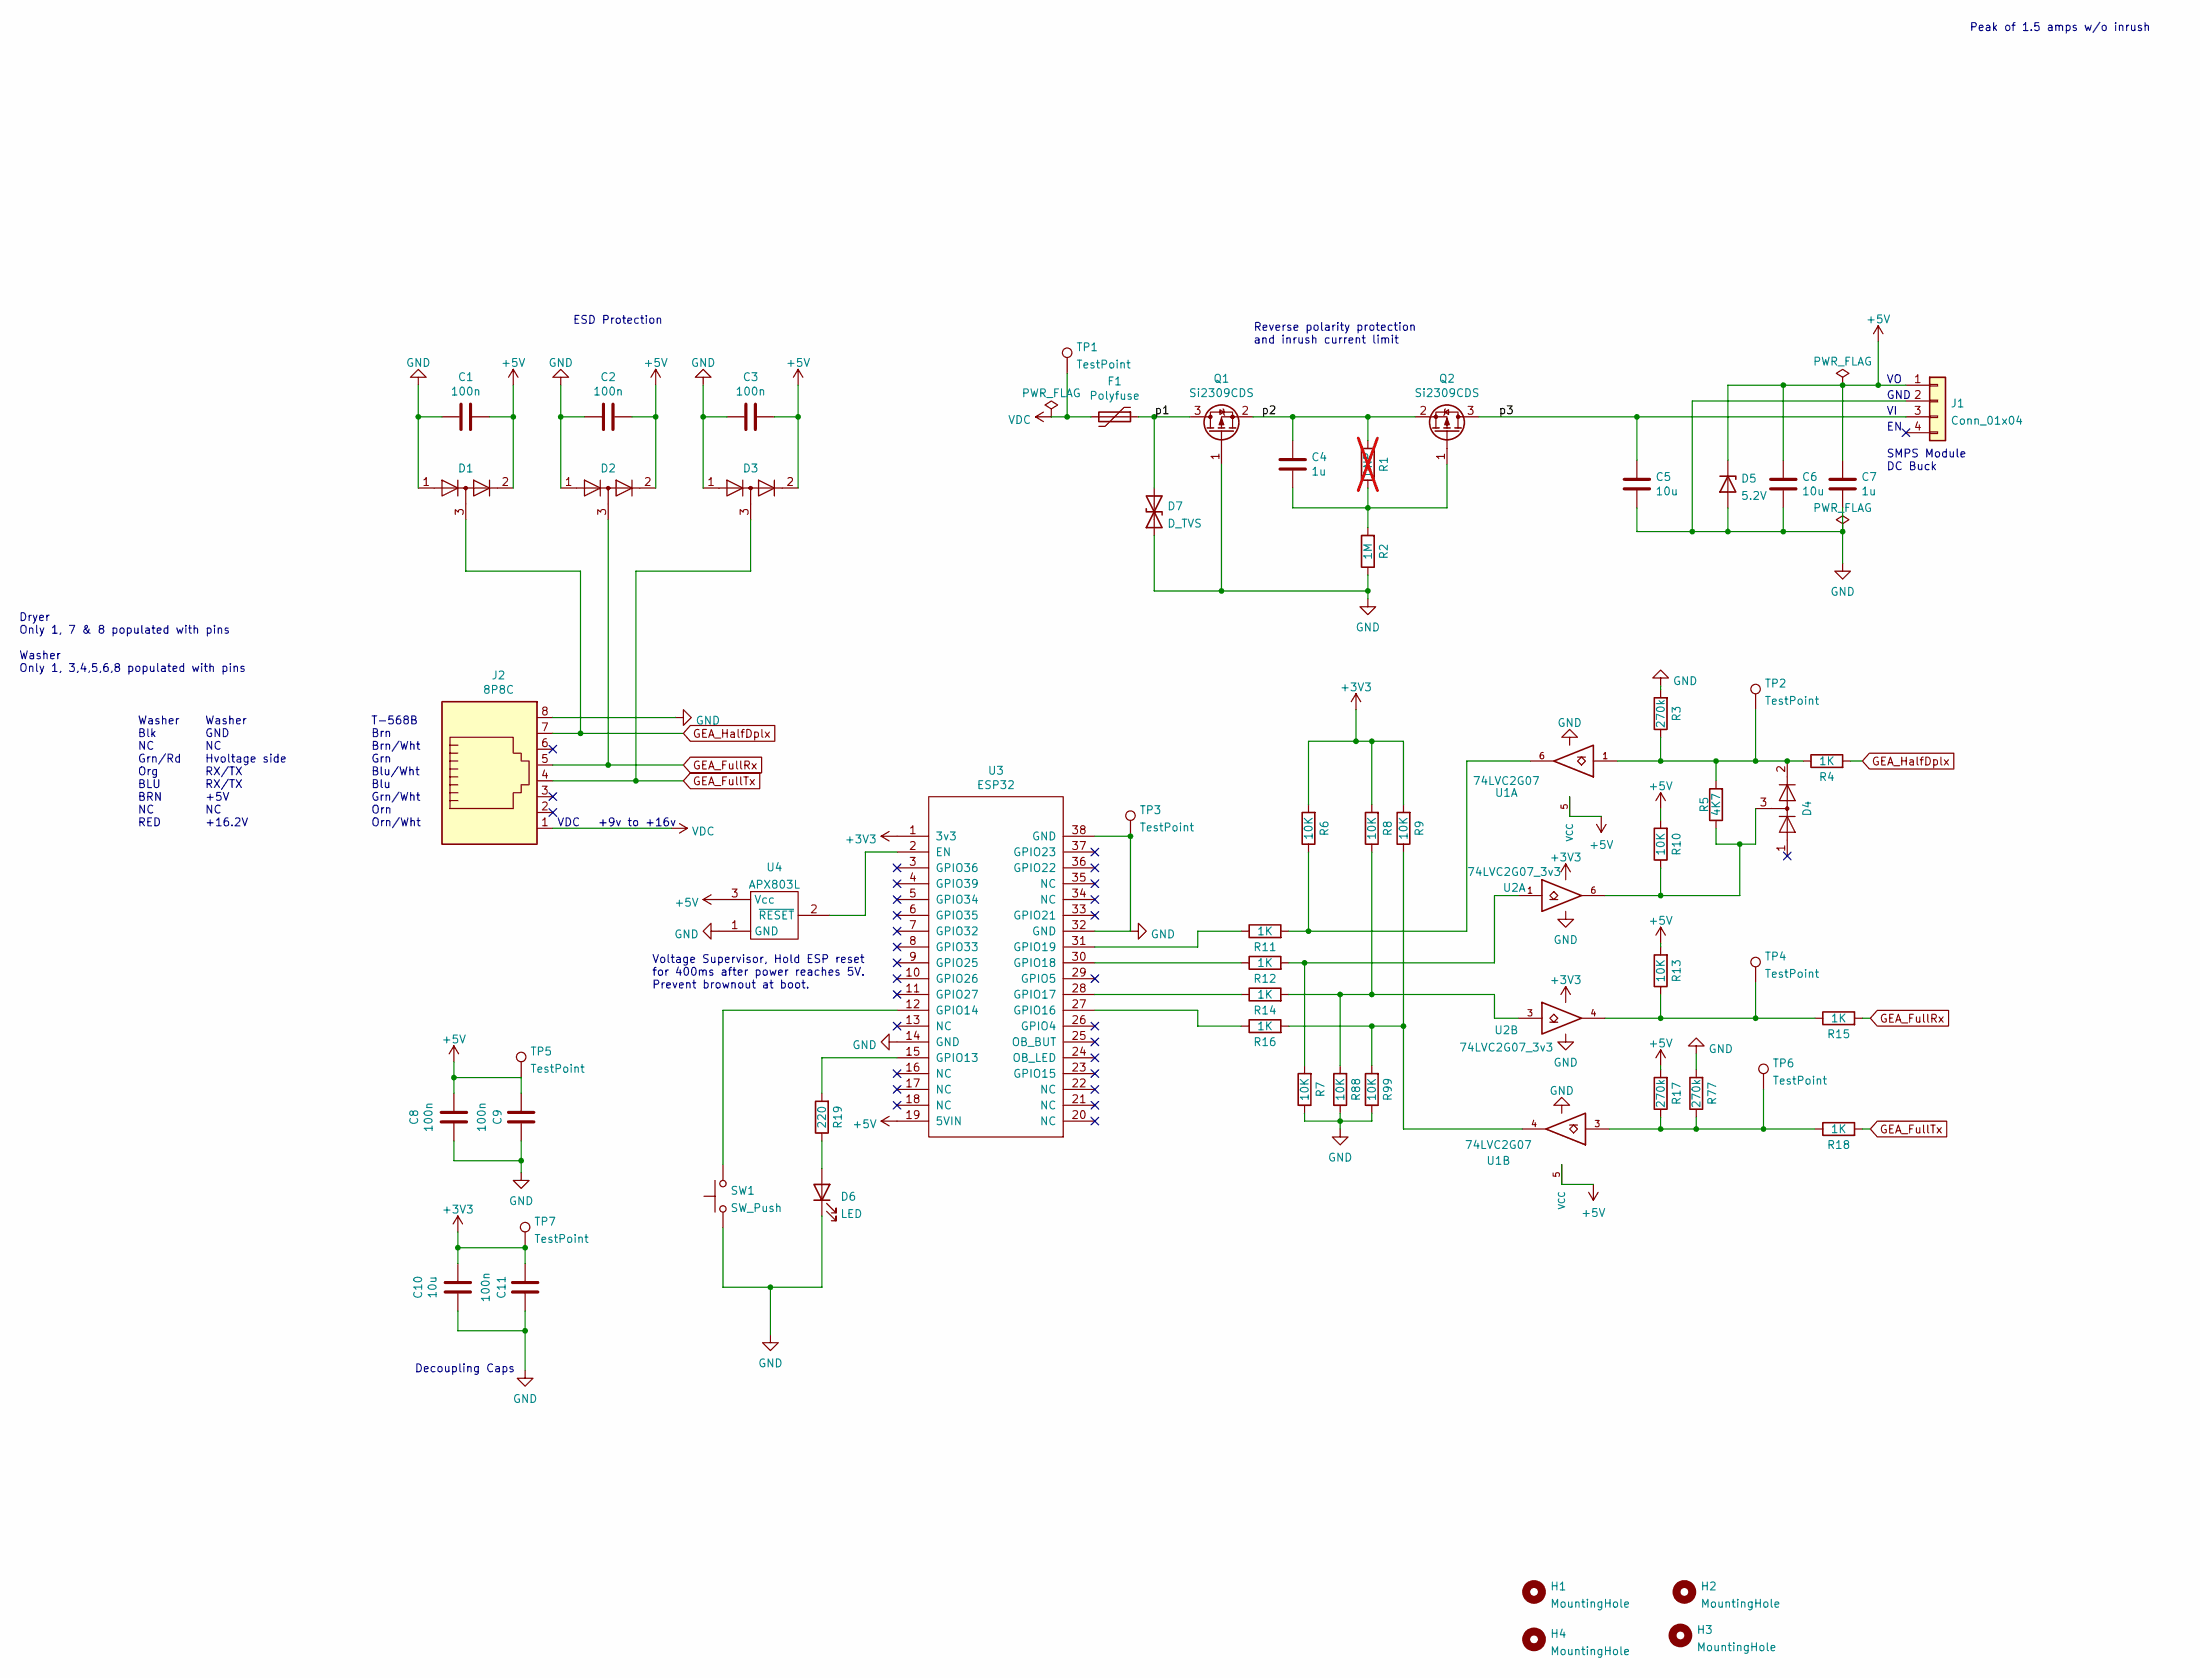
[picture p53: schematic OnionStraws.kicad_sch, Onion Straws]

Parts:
C1: 100n; C1_CP_EIA-1608-10_AVX-L
C2: 100n; C2_CP_EIA-1608-10_AVX-L
C3: 100n; C3_CP_EIA-1608-10_AVX-L
C4: 1u; C4_C_0805_2012Metric
C5: 10u; C5_C_0805_2012Metric
C6: 10u; C6_C_0805_2012Metric
C7: 1u; C7_C_0805_2012Metric
C8: 100n; C8_C_0805_2012Metric
C9: 100n; C9_C_0805_2012Metric
C10: 10u; C10_C_0805_2012Metric
C11: 100n; C11_C_0805_2012Metric
D1: BAV99; D1_SOT-23
D2: BAV99; D2_SOT-23
D3: BAV99; D3_SOT-23
D4: BAV99; D4_SOT-23
D5: 5.2V; D5_D_SOD-123
D6: LED; D6_LED_D5.0mm
D7: D_TVS; D7_D_SMA
F1: Polyfuse; F1_R_1210_3225Metric_Pad1.30x2.65mm_HandSolder
H1: MountingHole; H1_MountingHole_3.2mm_M3_DIN965
H2: MountingHole; H2_MountingHole_3.2mm_M3_DIN965
H3: MountingHole; H3_MountingHole_3.2mm_M3_DIN965
H4: MountingHole; H4_MountingHole_3.2mm_M3_DIN965
J1: Conn_01x04; J1_PinHeader_1x04_P2.54mm_Horizontal
J2: 8P8C; J2_RJ45_Amphenol_54602-x08_Horizontal
Q1: Si2309CDS; Q1_SOT-23
Q2: Si2309CDS; Q2_SOT-23
R1: DNP; R1_R_0805_2012Metric; not fitted
R2: 1M; R2_R_0805_2012Metric
R3: 270k; R3_R_0805_2012Metric
R4: 1K; R4_R_0805_2012Metric
R5: 4K7; R5_R_0805_2012Metric
R6: 10K; R6_R_0805_2012Metric
R7: 10K; R7_R_0805_2012Metric
R8: 10K; R8_R_0805_2012Metric
R9: 10K; R9_R_0805_2012Metric
R10: 10K; R10_R_0805_2012Metric
R11: 1K; R11_R_0805_2012Metric
R12: 1K; R12_R_0805_2012Metric
R13: 10K; R13_R_0805_2012Metric
R14: 1K; R14_R_0805_2012Metric
R15: 1K; R15_R_0805_2012Metric
R16: 1K; R16_R_0805_2012Metric
R17: 270k; R17_R_0805_2012Metric
R18: 1K; R18_R_0805_2012Metric
R19: 220; R19_R_0805_2012Metric
R77: 270k; R77_R_0805_2012Metric
R88: 10K; R88_R_0805_2012Metric
R99: 10K; R99_R_0805_2012Metric
SW1: SW_Push; SW1_SW_PUSH_6mm_H13mm
TP1: TestPoint; TP1_TestPoint_THTPad_D2.5mm_Drill1.2mm
TP2: TestPoint; TP2_TestPoint_THTPad_D2.5mm_Drill1.2mm
TP3: TestPoint; TP3_TestPoint_THTPad_D2.5mm_Drill1.2mm
TP4: TestPoint; TP4_TestPoint_THTPad_D2.5mm_Drill1.2mm
TP5: TestPoint; TP5_TestPoint_THTPad_D2.5mm_Drill1.2mm
TP6: TestPoint; TP6_TestPoint_THTPad_D2.5mm_Drill1.2mm
TP7: TestPoint; TP7_TestPoint_THTPad_D2.5mm_Drill1.2mm
U1: 74LVC2G07; U1_SOT-23-6
U2: 74LVC2G07_3v3; U2_SOT-23-6
U3: ESP32; U3_DIP-38_900_ELL
U4: APX803L; U4_SOT-23

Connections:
+3V3: C10.1, C11.2, R6.2, R8.2, R9.2, TP7.1, U2.5 (+3V3), U3.1 (3v3)
+5V: C1.1, C2.1, C3.1, C6.1, C7.1, C8.1, C9.2, D1.2 (A), D2.2 (A), D3.2 (A), D5.1 (K), J1.1, R10.2, R13.2, R17.2, TP5.1, U1.5 (VCC), U3.19 (5VIN), U4.3 (Vcc)
/p1: D7.2 (A2), F1.1, Q1.3 (D)
/p2: C4.1, Q1.2 (S), Q2.2 (S), R1.2
/p3: C5.1, J1.3, Q2.3 (D)
GEA_FullRx: D2.3 (K), J2.5, R15.2
GEA_FullTx: D3.3 (K), J2.4, R18.2
GEA_HalfDplx: D1.3 (K), J2.7, R4.2
GND: C1.2, C2.2, C3.2, C5.2, C6.2, C7.2, C8.2, C9.1, C10.2, C11.1, D1.1 (K), D2.1 (K), D3.1 (K), D5.2 (A), D6.1 (K), D7.1 (A1), J1.2, J2.8, Q1.1 (G), R2.1, R3.2, R7.1, R77.2, R88.1, R99.1, SW1.1, TP3.1, U1.2 (GND), U2.2 (GND), U3.14 (GND), U3.32 (GND), U3.38 (GND), U4.1 (GND)
unnamed: D4.2 (A), R3.1, R4.1, R5.2, TP2.1, U1.1
unnamed: D4.3 (K), R5.1, R10.1, U2.6
unnamed: D6.2 (A), R19.1
unnamed: C4.2, Q2.1 (G), R1.1, R2.2
unnamed: R6.1, R11.2, U1.6
unnamed: R7.2, R12.2, U2.1
unnamed: R13.1, R15.1, TP4.1, U2.4
unnamed: R8.1, R14.2, R88.2, U2.3
unnamed: R9.1, R16.2, R99.2, U1.4
unnamed: R17.1, R18.1, R77.1, TP6.1, U1.3
unnamed: U3.2 (EN), U4.2 (~RESET)
unnamed: R19.2, U3.15 (GPIO13)
unnamed: SW1.2, U3.12 (GPIO14)
unnamed: R16.1, U3.27 (GPIO16)
unnamed: R14.1, U3.28 (GPIO17)
unnamed: R12.1, U3.30 (GPIO18)
unnamed: R11.1, U3.31 (GPIO19)
VDC: F1.2, J2.1, TP1.1

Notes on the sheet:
Voltage Supervisor, Hold ESP reset for 400ms after power reaches 5V. Prevent brownout at boot.
Washer Blk NC Grn/Rd Org BLU BRN NC RED
Reverse polarity protection and inrush current limit
Dryer Only 1, 7 & 8 populated with pins Washer Only 1, 3,4,5,6,8 populated with pins
Washer GND NC Hvoltage side RX/TX RX/TX +5V NC +16.2V
Decoupling Caps
Peak of 1.5 amps w/o inrush
ESD Protection
T-568B Brn Brn/Wht Grn Blu/Wht Blu Grn/Wht Orn Orn/Wht
GND
SMPS Module DC Buck
VDC +9v to +16v

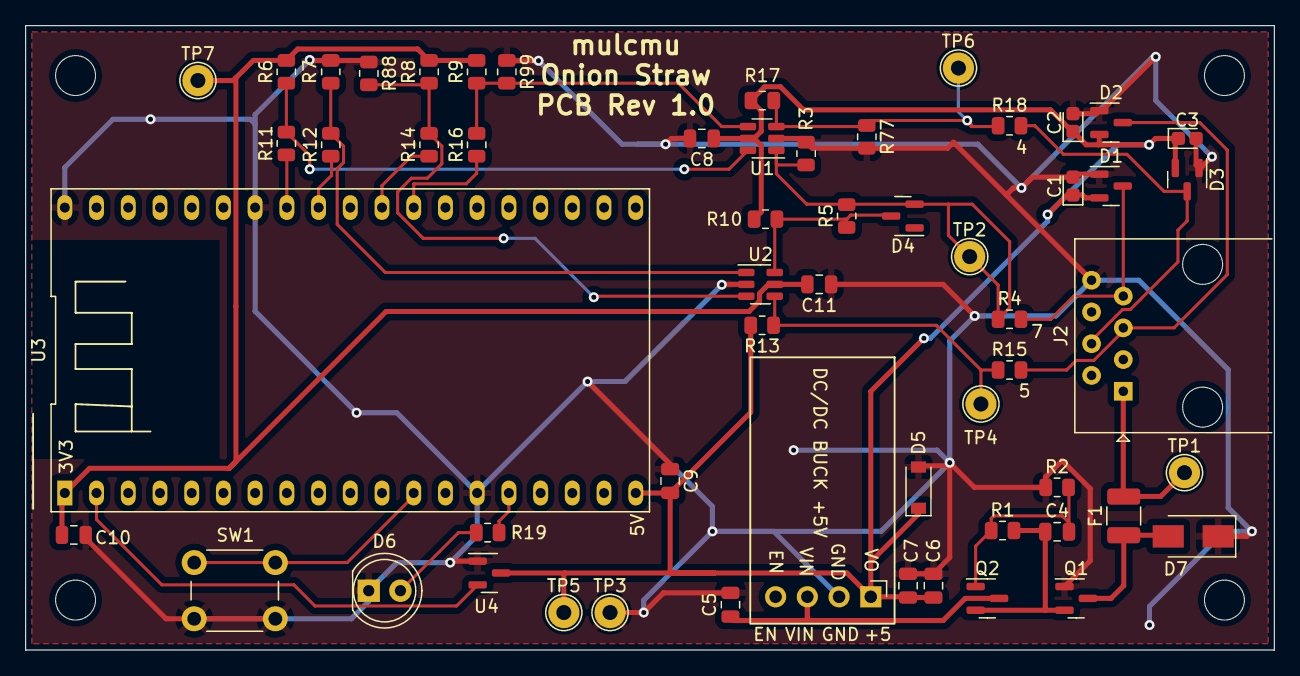
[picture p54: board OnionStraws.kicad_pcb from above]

Board: 2 copper layers, 100.0 x 50.0 mm, 61 parts (0 on the bottom side), 27 nets.

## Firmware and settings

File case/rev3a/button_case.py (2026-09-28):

"""Optional captive finger-button lid for the Rev3A enclosure.

This is deliberately an alternate assembly: the original tool-access lid is
not modified. Each button is a one-piece slider loaded from the underside of
the lid. A shared keeper then snaps into the underside of the lid. The
slider's wide flange is caught between the lid's upper throat and the keeper,
so it has positive stops in both axial directions without a printed spring.

The XKB switch's own return spring raises the slider to its upper stop. The
model is a prototype-fit aid only: the data sheet gives no over-travel limit.
"""

from __future__ import annotations

import argparse
from pathlib import Path

from build123d import Part, export_step, export_stl

from enclosure import LID_UNDERSIDE_Z, LID_Z1, PCB_TOP_Z, _box, _cylinder, make_lid


SWITCH_MODEL = Path(__file__).parents[2] / "pcb/rev3a/design/models/SW1-SW2-XKB-TS-1187A-B-A-B.step"
BUTTON_CENTERS = ((5.0, 3.4), (13.0, 3.4))
BUTTON_SPACING = 8.0

# C318884 geometry measured from the seated PCB datum used by enclosure.py.
SWITCH_HEIGHT = 1.5
SWITCH_TOP_Z = PCB_TOP_Z + SWITCH_HEIGHT
ACTUATOR_RADIUS = 1.0

# This is the actual axial motion from the flange's upper-throat stop to its
# keeper stop. It begins with the tip just touching the switch actuator; the
# switch return spring supplies return force. A physical release/continuity
# test is mandatory because the data sheet does not state a safe over-travel
# or crush-force limit.
NOMINAL_STROKE = 0.20
REST_TIP_Z = SWITCH_TOP_Z
FULL_PRESS_TIP_Z = REST_TIP_Z - NOMINAL_STROKE

# Lid guide. The original 4 mm tool hole is enlarged only in this optional
# lid. The 4.3 mm finger pad passes the 4.7 mm throat during underside
# insertion. The 5.4 mm flange cannot pass it once installed.
GUIDE_OUTER_RADIUS = 3.70
THROAT_RADIUS = 2.35
FLANGE_RADIUS = 2.70
FLANGE_CLEAR_RADIUS = 2.82
SLIDER_RADIUS = 0.80
PAD_RADIUS = 2.15
FLANGE_HEIGHT = 0.80
KEEPER_HOLE_RADIUS = 1.05
RADIAL_CLEARANCE = FLANGE_CLEAR_RADIUS - FLANGE_RADIUS

# At rest the flange top touches the upper throat. At full press its bottom
# touches the keeper top. These faces, not an arbitrary translated pose, set
# the 0.20 mm nominal stroke.
UPPER_THROAT_BOTTOM_Z = 16.00
FLANGE_REST_TOP_Z = UPPER_THROAT_BOTTOM_Z
FLANGE_REST_BOTTOM_Z = FLANGE_REST_TOP_Z - FLANGE_HEIGHT
KEEPER_TOP_Z = FLANGE_REST_BOTTOM_Z - NOMINAL_STROKE
KEEPER_BOTTOM_Z = 13.60
GUIDE_CAVITY_BOTTOM_Z = KEEPER_TOP_Z
GUIDE_CAVITY_TOP_Z = UPPER_THROAT_BOTTOM_Z
GUIDE_TOP_Z = LID_UNDERSIDE_Z + 0.10

# The shared keeper is fitted from below after both sliders. Its side latches
# hook over the *top* faces of the lid-side rails. The keeper plate is 1.4 mm
# thick; each arm is an 0.80 mm X-thickness cantilever after its 0.05 mm union
# overlap. PETG/ABS prototype fitting verifies the one-time retention fit.
KEEPER_X0, KEEPER_X1 = -1.50, 19.50
KEEPER_Y0, KEEPER_Y1 = 0.40, 6.40
LATCH_WEB = 0.75
# The arm flexes in its 0.80 mm actual X thickness. Its free length from the
# keeper top to the hook underside is 3.50 mm; the rail engagement is 0.10 mm.
# Gently spread both arms outward while fitting the keeper--this is not a
# push-through snap-force claim.
LATCH_RISE = 4.30
LATCH_HOOK = 0.90
RAIL_Z0, RAIL_Z1 = KEEPER_TOP_Z + 2.30, KEEPER_TOP_Z + 3.50


def _annulus(outer: float, inner: float, z0: float, z1: float, x: float, y: float) -> Part:
    return _cylinder(outer, z0, z1, x, y) - _cylinder(inner, z0 - 0.05, z1 + 0.05, x, y)


def make_button_lid() -> Part:
    """Return the optional lid with two flange cavities and keeper rails."""
    lid = make_lid()
    for x, y in BUTTON_CENTERS:
        # Widen only this variant's original r=2.0 service hole so the
        # underside-loaded 4.3 mm pad can traverse the 4.7 mm throat.
        lid = lid - _cylinder(THROAT_RADIUS, LID_UNDERSIDE_Z - 0.10, LID_Z1 + 0.10, x, y)
        # The guide overlaps the existing ceiling at z=19.4..19.5, making a
        # single lid solid while keeping the existing service-hole location.
        throat = _annulus(GUIDE_OUTER_RADIUS, THROAT_RADIUS, UPPER_THROAT_BOTTOM_Z, GUIDE_TOP_Z, x, y)
        cavity_wall = _annulus(
            GUIDE_OUTER_RADIUS, FLANGE_CLEAR_RADIUS, GUIDE_CAVITY_BOTTOM_Z, GUIDE_CAVITY_TOP_Z, x, y
        )
        lid = lid + throat + cavity_wall
    # The keeper's latches flex in X while it is pushed upward. The rails are
    # outside both guide envelopes and remain clear of the RJ45 opening.
    for x0, x1 in ((-1.35, -0.15), (18.15, 19.35)):
        rail = _box(x0, x1, KEEPER_Y0, KEEPER_Y1, RAIL_Z0, RAIL_Z1)
        # A rear brace joins each short latch rail to the original ceiling;
        # it is deliberately outside the two guide envelopes.
        brace = _box(x0, x1, KEEPER_Y0, KEEPER_Y0 + 1.20, RAIL_Z1 - 0.05, GUIDE_TOP_Z)
        lid = lid + rail + brace
    return lid


def make_plunger() -> Part:
    """Return one underside-loaded slider; print two identical copies."""
    stem = _cylinder(SLIDER_RADIUS, REST_TIP_Z, FLANGE_REST_BOTTOM_Z, 0.0, 0.0)
    lead_in = _cylinder(FLANGE_RADIUS - 0.40, FLANGE_REST_BOTTOM_Z, FLANGE_REST_BOTTOM_Z + 0.40, 0.0, 0.0)
    flange = _cylinder(FLANGE_RADIUS, FLANGE_REST_BOTTOM_Z + 0.40, FLANGE_REST_TOP_Z, 0.0, 0.0)
    pad = _cylinder(PAD_RADIUS, FLANGE_REST_TOP_Z, LID_Z1 + 0.70, 0.0, 0.0)
    return stem + lead_in + flange + pad


def make_keeper() -> Part:
    """Return the common two-button lower stop and snap-retained keeper."""
    keeper = _box(KEEPER_X0, KEEPER_X1, KEEPER_Y0, KEEPER_Y1, KEEPER_BOTTOM_Z, KEEPER_TOP_Z)
    for x, y in BUTTON_CENTERS:
        keeper = keeper - _cylinder(KEEPER_HOLE_RADIUS, KEEPER_BOTTOM_Z - 0.05, KEEPER_TOP_Z + 0.05, x, y)
    # Side latches sit outside the guide envelopes. Their inward hook noses
    # finish above the rail tops and restrain keeper downward motion.
    left_arm = _box(KEEPER_X0 - LATCH_WEB, KEEPER_X0 + 0.05, KEEPER_Y0, KEEPER_Y1, KEEPER_BOTTOM_Z, KEEPER_TOP_Z + LATCH_RISE)
    left_hook = _box(KEEPER_X0 - 0.55, KEEPER_X0 + 0.25, KEEPER_Y0 + 1.20, KEEPER_Y1 - 1.20, RAIL_Z1, RAIL_Z1 + 0.80)
    right_arm = _box(KEEPER_X1 - 0.05, KEEPER_X1 + LATCH_WEB, KEEPER_Y0, KEEPER_Y1, KEEPER_BOTTOM_Z, KEEPER_TOP_Z + LATCH_RISE)
    right_hook = _box(KEEPER_X1 - 0.25, KEEPER_X1 + 0.55, KEEPER_Y0 + 1.20, KEEPER_Y1 - 1.20, RAIL_Z1, RAIL_Z1 + 0.80)
    return keeper + left_arm + left_hook + right_arm + right_hook


def _export(shape: Part, stem: str, out_dir: Path) -> None:
    out_dir.mkdir(parents=True, exist_ok=True)
    export_stl(shape, out_dir / f"{stem}.stl")
    export_step(shape, out_dir / f"{stem}.step")


def main() -> None:
    parser = argparse.ArgumentParser(description=__doc__)
    parser.add_argument("--out", type=Path, default=Path(__file__).parent)
    args = parser.parse_args()
    _export(make_button_lid(), "rev3a_button_lid", args.out)
    _export(make_plunger(), "rev3a_button_plunger", args.out)
    _export(make_keeper(), "rev3a_button_keeper", args.out)
    print(f"wrote optional button lid, two plungers, and shared keeper to {args.out}")


if __name__ == "__main__":
    main()

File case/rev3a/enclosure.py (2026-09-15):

"""Parametric two-piece printable enclosure for the GEA Adapter Rev3A PCB.

Coordinates follow the PCB: x=0..88.7 mm, y=0..40 mm.  The base and lid
are deliberately separate solids so either can be edited or printed alone.
Run this file with the case virtualenv to regenerate all deliverables::

    python enclosure.py --out case/rev3a

The geometry is intentionally conservative around the two edge connectors.
Connector envelopes and the RF antenna keep-out are parameters below rather
than imported meshes, so this remains editable without KiCad or Fusion.
"""

from __future__ import annotations

import argparse
from pathlib import Path

from build123d import Align, Box, Cylinder, Location, Part, export_step, export_stl


# PCB datum and required fit allowances (millimetres).
PCB_X = 88.7
PCB_Y = 40.0
PCB_T = 1.6
XY_CLEAR = 0.5
Z_CLEAR = 1.0

# Base envelope.  The extra length to x=103.7 is the antenna chamber.
BASE_X0, BASE_X1 = -4.0, 103.7
BASE_Y0, BASE_Y1 = -4.0, 44.0
BASE_Z0, BASE_Z1 = 0.0, 10.0
FLOOR = 2.4

# Lid envelope and its deep, friction-fit skirt.  The skirt overlaps the
# base wall by 1 mm in Z and has 0.25 mm radial clearance per side.
LID_X0, LID_X1 = -5.0, 104.7
LID_Y0, LID_Y1 = -5.0, 45.0
LID_Z0, LID_Z1 = 9.0, 22.0
LID_CEILING = 2.6
LID_INNER_X0, LID_INNER_X1 = -4.25, 103.95
LID_INNER_Y0, LID_INNER_Y1 = -4.25, 44.25

# Board cavity.  It extends into the antenna chamber, but has no internal
# ribs, bosses, or fasteners in x=88.7..103.7, y=3..31.
CAV_X0, CAV_X1 = -XY_CLEAR, 100.2
CAV_Y0, CAV_Y1 = -XY_CLEAR, PCB_Y + XY_CLEAR
ANTENNA_X0, ANTENNA_X1 = PCB_X, PCB_X + 15.0
ANTENNA_Y0, ANTENNA_Y1 = 3.0, 31.0

MOUNT_HOLES = ((4.0, 30.0), (48.0, 4.0))

# Small lid apertures expose the existing status LEDs without adding PCB parts.
# D4 is green/Wi-Fi, D5 is red/user diagnostic, and D6 is yellow/GEA bus.
LED_VIEW_HOLES = ((49.0, 24.0), (82.5, 1.5), (80.0, 36.5))
LED_VIEW_RADIUS = 1.25

# C3097717 (EVERCOM 5301-8P8C) is not present in the KiCad assembly STEP.
# The JLCPCB-hosted manufacturer drawing lists 15.20, 11.50, and 18.05 mm
# body dimensions.  Use the largest 11.50 mm body height plus a conservative
# 1.0 mm cable-plug/latch allowance for a 12.50 mm vertical envelope above
# the seated PCB top.  These named values make the missing-3D-model assumption
# visible and are checked in check_geometry.py.
PCB_SEAT_Z = FLOOR + 1.25
PCB_TOP_Z = PCB_SEAT_Z + PCB_T
RJ45_BODY_HEIGHT = 11.50
RJ45_CABLE_LATCH_ALLOWANCE = 1.00
RJ45_VERTICAL_ENVELOPE = RJ45_BODY_HEIGHT + RJ45_CABLE_LATCH_ALLOWANCE
RJ45_ENVELOPE_TOP_Z = PCB_TOP_Z + RJ45_VERTICAL_ENVELOPE
LID_UNDERSIDE_Z = LID_Z1 - LID_CEILING

# J2 is the populated top-side 2x3 recovery header at (11.7, 32.5).  The
# supplier STEP reaches 11.06 mm above its PCB datum.  Keep this as an
# explicit enclosure envelope so a future lower lid cannot silently collide
# with the header.  Recovery access requires removing the lid; there is no
# external opening that could admit conductive debris during normal use.
J2_X, J2_Y = 11.7, 32.5
J2_HALF_X, J2_HALF_Y = 3.75, 3.82
J2_HEIGHT_ABOVE_PCB = 11.06
J2_ENVELOPE_TOP_Z = PCB_TOP_Z + J2_HEIGHT_ABOVE_PCB

# The side window crosses the full conservative cable/port opening height.
# The matching lid notch below clears the same insertion envelope.
RJ45_WINDOW_X0, RJ45_WINDOW_X1 = -5.0, 0.7
RJ45_WINDOW_Y0, RJ45_WINDOW_Y1 = 3.5, 25.5
RJ45_WINDOW_Z0, RJ45_WINDOW_Z1 = 2.0, BASE_Z1 + 0.2
RJ45_NOTCH_X0, RJ45_NOTCH_X1 = LID_X0 - 0.2, LID_INNER_X0 + 0.25
RJ45_NOTCH_Y0, RJ45_NOTCH_Y1 = RJ45_WINDOW_Y0 - 0.75, RJ45_WINDOW_Y1 + 0.75
RJ45_NOTCH_Z0, RJ45_NOTCH_Z1 = LID_Z0 - 0.5, RJ45_ENVELOPE_TOP_Z + 1.0

# Printed PCB retention: 1.25 mm locating posts pass through the 3.2 mm
# drills with 0.35 mm radial clearance. Lid-side annular retainers bear on
# the bare mounting annulus only, just above the seated PCB top.
LOCATING_POST_RADIUS = 1.25
LOCATING_POST_TOP_Z = PCB_TOP_Z + 0.30
LID_RETAINER_OUTER_RADIUS = 2.4
LID_RETAINER_INNER_RADIUS = 1.5
LID_RETAINER_BOTTOM_Z = PCB_TOP_Z - 0.05


def _box(x0: float, x1: float, y0: float, y1: float, z0: float, z1: float) -> Part:
    return Box(x1 - x0, y1 - y0, z1 - z0, align=(Align.MIN, Align.MIN, Align.MIN)).locate(
        Location((x0, y0, z0))
    )


def _cylinder(radius: float, z0: float, z1: float, x: float, y: float) -> Part:
    return Cylinder(radius, z1 - z0, align=(Align.CENTER, Align.CENTER, Align.MIN)).locate(
        Location((x, y, z0))
    )


def make_base() -> Part:
    """Make the open-top base, connector windows, and PCB support rings."""
    base = _box(BASE_X0, BASE_X1, BASE_Y0, BASE_Y1, BASE_Z0, BASE_Z1)
    cavity = _box(CAV_X0, CAV_X1, CAV_Y0, CAV_Y1, FLOOR, BASE_Z1 + 0.2)
    base = base - cavity

    # RJ45 J1: side-entry opening through the left wall.  The generous
    # 22x8.2 mm (Y x Z) window covers the rotated EVERCOM body and cable latch.
    rj45_window = _box(
        RJ45_WINDOW_X0,
        RJ45_WINDOW_X1,
        RJ45_WINDOW_Y0,
        RJ45_WINDOW_Y1,
        RJ45_WINDOW_Z0,
        RJ45_WINDOW_Z1,
    )
    base = base - rj45_window

    # USB-C J4 at (72,36.325), opening through the positive-y/lower edge.
    # Leave a broad flange around the shell for cable insertion.
    usb_window = _box(64.5, 79.5, 39.0, 46.0, 2.0, 6.4)
    base = base - usb_window

    # Two non-hardware bosses support the specified PCB mounting holes.  The
    # 1.9 mm bores leave 0.3 mm radial clearance around the 3.2 mm drills.
    for x, y in MOUNT_HOLES:
        boss = _cylinder(3.0, FLOOR, 3.65, x, y)
        bore = _cylinder(1.9, FLOOR - 0.1, 3.8, x, y)
        locating_post = _cylinder(LOCATING_POST_RADIUS, FLOOR - 0.1, LOCATING_POST_TOP_Z, x, y)
        base = base + (boss - bore) + locating_post

    # Small lead-in ramps at the two long walls make the lid's skirt locate
    # during assembly without intruding into the antenna chamber.
    for x in (18.0, 55.0, 80.0):
        for y in (BASE_Y0 + 0.9, BASE_Y1 - 0.9):
            guide = _box(x - 1.8, x + 1.8, y - 0.55, y + 0.55, 6.6, 8.0)
            base = base + guide
    return base
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

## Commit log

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2026-09-14 fix(pcb): prepare revision 2.2 corrections
    [OnionStraws.kicad_pcb, OnionStraws.kicad_sch]
2026-09-14 build(pcb): add revision 2.2 manufacturing files
    [BOM-OnionStraws-rev2.2.csv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]
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2026-09-14 feat(pcb): add revision 3a design snapshot
    [GEA-Adapter-Rev3.kicad_pcb, GEA-Adapter-Rev3.kicad_sch]
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2026-09-14 feat(pcb): route rev3a GEA3 MCU paths
    [GEA-Adapter-Rev3.kicad_pcb]
2026-09-14 feat(pcb): route rev3a local 3v3 branches
    [GEA-Adapter-Rev3.kicad_pcb]
2026-09-14 feat(pcb): route rev3a 3v3 control island
    [GEA-Adapter-Rev3.kicad_pcb]
2026-09-14 feat(pcb): route rev3a reset and led control nets
    [GEA-Adapter-Rev3.kicad_pcb]
2026-09-14 feat(pcb): route rev3a boot and debug-led escapes
    [GEA-Adapter-Rev3.kicad_pcb]
2026-09-14 feat(pcb): route rev3a button terminal pairs
    [GEA-Adapter-Rev3.kicad_pcb]
2026-09-14 feat(pcb): route rev3a protection and led branches
    [GEA-Adapter-Rev3.kicad_pcb]
2026-09-14 feat(pcb): connect rev3a buffer ground returns
    [GEA-Adapter-Rev3.kicad_pcb]
2026-09-14 feat(pcb): route rev3a button and LED ground returns
    [GEA-Adapter-Rev3.kicad_pcb]
2026-09-14 feat(pcb): add rev3a automatic power and USB design
    [GEA-Adapter-Rev3.kicad_pcb, GEA-Adapter-Rev3.kicad_sch]
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2026-09-14 feat(pcb): route rev3a regulator ground returns
    [GEA-Adapter-Rev3.kicad_pcb]
2026-09-14 fix(pcb): align rev3a appliance connector metadata
    [GEA-Adapter-Rev3.kicad_pcb, GEA-Adapter-Rev3.kicad_sch]
2026-09-14 fix(pcb): correct rev3a capacitor sourcing
    [GEA-Adapter-Rev3.kicad_pcb, GEA-Adapter-Rev3.kicad_sch]
2026-09-14 feat(pcb): route grounds and refine rev3a sourcing
    [GEA-Adapter-Rev3.kicad_pcb, GEA-Adapter-Rev3.kicad_sch]
2026-09-14 fix(pcb): complete rev3a sourcing metadata
    [GEA-Adapter-Rev3.kicad_sch]
2026-09-14 feat(pcb): finish rev3a ground stitching
    [GEA-Adapter-Rev3.kicad_pcb]
2026-09-14 fix(pcb): qualify rev3a buck capacitors
    [GEA-Adapter-Rev3.kicad_sch]
2026-09-14 fix(pcb): sync rev3a capacitor metadata
    [GEA-Adapter-Rev3.kicad_pcb]
2026-09-14 feat(pcb): route rev3a 5v branch
    [GEA-Adapter-Rev3.kicad_pcb]
2026-09-14 feat(pcb): route rev3a 3v3 branch
    [GEA-Adapter-Rev3.kicad_pcb]
2026-09-14 feat(pcb): route rev3a pin3 fused path
    [GEA-Adapter-Rev3.kicad_pcb]
2026-09-14 feat(pcb): route rev3a pin1 fused path
    [GEA-Adapter-Rev3.kicad_pcb]
2026-09-14 feat(pcb): route rev3a pin1 protected path
    [GEA-Adapter-Rev3.kicad_pcb]
2026-09-14 feat(pcb): route rev3a pin3 protected path
    [GEA-Adapter-Rev3.kicad_pcb]
2026-09-14 feat(pcb): route rev3a pin1 gate clamp
    [GEA-Adapter-Rev3.kicad_pcb]
2026-09-14 feat(pcb): route rev3a USB data path
    [GEA-Adapter-Rev3.kicad_pcb]
2026-09-14 feat(pcb): route rev3a switch outputs
    [GEA-Adapter-Rev3.kicad_pcb]
2026-09-14 feat(pcb): reinforce rev3a buck output path
    [GEA-Adapter-Rev3.kicad_pcb]
2026-09-14 feat(pcb): route rev3a input priority controls
    [GEA-Adapter-Rev3.kicad_pcb]
2026-09-14 fix(pcb): place rev3a antenna beyond board edge
    [GEA-Adapter-Rev3.kicad_pcb]
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2026-09-14 feat(pcb): route rev3a 5v distribution
    [GEA-Adapter-Rev3.kicad_pcb]
2026-09-14 feat(pcb): route rev3a 3v3 branches
    [GEA-Adapter-Rev3.kicad_pcb]
2026-09-14 feat(pcb): finish rev3a 5v distribution
    [GEA-Adapter-Rev3.kicad_pcb]
2026-09-15 feat(pcb): route rev3a secondary transmit
    [GEA-Adapter-Rev3.kicad_pcb]
2026-09-15 feat(pcb): route rev3a boot and debug controls
    [GEA-Adapter-Rev3.kicad_pcb]
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2026-09-15 fix(pcb): match rev3a usb connector footprint
    [GEA-Adapter-Rev3.kicad_pcb]
2026-09-15 fix(pcb): reconcile rev3a schematic parity
    [GEA-Adapter-Rev3.kicad_pcb, GEA-Adapter-Rev3.kicad_sch]
2026-09-15 docs(pcb): finalize rev3a bom metadata
    [GEA-Adapter-Rev3.kicad_sch]
2026-09-15 feat(case): add rev3a printable enclosure
    [rev3a_base.step, rev3a_base.stl, rev3a_lid.step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]
2026-09-15 fix(case): qualify rev3a rj45 clearance
    [rev3a_base.step, rev3a_base.stl, rev3a_lid.step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]
2026-09-15 docs(case): correct rev3a connector dimensions
    [enclosure.py]
2026-09-15 fix(case): clear rj45 lid and retain pcb
    [rev3a_base.step, rev3a_base.stl, rev3a_lid.step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]
2026-09-15 docs(pcb): prepare rev3a schematic review
    [GEA-Adapter-Rev3.kicad_sch]
2026-09-15 docs(pcb): re-layout rev3a automatic power schematic
    [GEA-Adapter-Rev3.kicad_sch]
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2026-09-15 feat(pcb): complete rev3a four-layer layout
    [GEA-Adapter-Rev3.kicad_pcb]
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2026-09-15 docs(pcb): publish rev3a review package
    [BOM-GEA-Adapter-Rev3A.csv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]
2026-09-15 fix(pcb): use standard vias for rev3a
    [GEA-Adapter-Rev3.kicad_pcb]
2026-09-15 fix(pcb): format rev3a cpl for assembly
    [CPL-GEA-Adapter-Rev3A.csv]
2026-09-15 fix(pcb): expand rev3a assembly designators
    [BOM-GEA-Adapter-Rev3A.csv]
2026-09-15 fix(pcb): use jlcpcb cpl column order
    [CPL-GEA-Adapter-Rev3A.csv]
2026-09-15 fix(pcb): use assembly-ready usb-c connector
    [BOM-GEA-Adapter-Rev3A.csv, GEA-Adapter-Rev3.kicad_pcb, GEA-Adapter-Rev3.kicad_sch]
2026-09-15 fix(pcb): use standard rev3a thermal drills
    [GEA-Adapter-Rev3.kicad_pcb]
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2026-09-15 docs(pcb): record corrected rev3a quote
2026-09-15 docs(case): correct rev3a service button labels
    [enclosure.py]
2026-09-15 feat(pcb): improve rev3a recovery and review artifacts
    [GEA-Adapter-Rev3.kicad_pcb, GEA-Adapter-Rev3.kicad_sch, J1-EVERCOM-5301-8P8C-envelope.step]
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2026-09-15 fix(pcb): finalize rev3a sourcing and connector model
    [BOM-GEA-Adapter-Rev3A.csv, GEA-Adapter-Rev3.kicad_pcb, GEA-Adapter-Rev3.kicad_sch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]
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2026-09-15 feat(case): validate rev3a recovery clearance
    [rev3a_base.step, rev3a_lid.step]
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2026-09-15 fix(pcb): complete rev3a review models
    [F1-F2-Bourns-MF-MSMF075-24-2.step, GEA-Adapter-Rev3.kicad_pcb, GEA-Adapter-Rev3.kicad_sch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]
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2026-09-19 fix(pcb): prepare revision 2.2 design source
    [OnionStraws.kicad_pcb, OnionStraws.kicad_sch]
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2026-09-28 feat(pcb): add XIAO module footprint and clearance model
    [XIAO-ESP32-C3-v1.3-envelope.step]
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2026-09-29 feat(pcb): add single-source XIAO carrier schematic
    Retain automatic appliance power selection and populated recovery header. Feed the module through its 5V input with VBAT unused. This is a schematic checkpoint; layout, review and fabrication release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
    [F1-F2-Bourns-MF-MSMF075-24-2.step, GEA-Adapter-Rev3B.kicad_sch, J1-EVERCOM-5301-8P8C-envelope.step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]
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2026-09-29 fix(pcb): align Rev3B project metadata
    [GEA-Adapter-Rev3B.kicad_pcb, GEA-Adapter-Rev3B.kicad_sch]
2026-09-29 fix(pcb): apply power rules to Rev3B rail nets
2026-09-29 feat(pcb): route Rev3B carrier connections
    Preserve existing power routing and the inner ground reference. This development checkpoint still has 26 open connections and 35 power-clearance findings; it is not a fabrication release.
    [GEA-Adapter-Rev3B.kicad_pcb]
2026-09-29 fix(pcb): clear Rev3B connector and input capacitor spacing
    [GEA-Adapter-Rev3B.kicad_pcb]
2026-09-29 fix(pcb): connect Rev3B switch capacitor ground return
    [GEA-Adapter-Rev3B.kicad_pcb]
2026-09-29 fix(pcb): separate Rev3B signal paths from input rails
    [GEA-Adapter-Rev3B.kicad_pcb]
2026-09-29 fix(pcb): connect Rev3B bus buffer ground return
    [GEA-Adapter-Rev3B.kicad_pcb]
2026-09-29 fix(pcb): connect Rev3B LED and recovery signals
    [GEA-Adapter-Rev3B.kicad_pcb]
2026-09-29 fix(pcb): connect Rev3B capacitor ground island
    [GEA-Adapter-Rev3B.kicad_pcb]
2026-09-29 fix(pcb): connect Rev3B decoupling capacitor ground
    [GEA-Adapter-Rev3B.kicad_pcb]
2026-09-29 fix(pcb): connect Rev3B bus input ground return
    [GEA-Adapter-Rev3B.kicad_pcb]
2026-09-29 fix(pcb): restore Rev3B bus diode supply connection
    [GEA-Adapter-Rev3B.kicad_pcb]
2026-09-29 fix(pcb): connect Rev3B bus buffer supply
    [GEA-Adapter-Rev3B.kicad_pcb]
2026-09-30 fix(pcb): connect Rev3B isolated ground returns
    [GEA-Adapter-Rev3B.kicad_pcb]
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2026-09-30 fix(pcb): align Rev3B recovery header model
    [GEA-Adapter-Rev3B.kicad_pcb, J2-hanxia-HX-PZ-2.54-02-03-S-drawing.step, J2-hanxia-HX-PZ-2.54-02-03-S.step]
2026-09-30 fix(pcb): secure Rev3B buffer supply and ground returns
    [GEA-Adapter-Rev3B.kicad_pcb]
2026-09-30 feat(pcb): complete Rev3B four-layer routing
    Connect the remaining power and signal nets, stitch ground pours, and orient the RJ45 ground thermal relief to preserve two spokes. Retain the local buck and selector routes, 0.2 mm minimum tracks, a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
    [GEA-Adapter-Rev3B.kicad_pcb]
2026-09-30 fix(pcb): clear Rev3B silkscreen and footprint warnings
    Move overlapping labels, remove a duplicate courtyard graphic, restore the test-point outline, and keep the off-board USB envelope on the fabrication layer only. Preserve all pad and routed copper geometry.
    [GEA-Adapter-Rev3B.kicad_pcb]
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2026-10-01 fix(pcb): resolve Rev3B schematic warnings and label spacing
    [GEA-Adapter-Rev3B.kicad_sch]
2026-10-01 docs(pcb): package Rev3B design review and quote files
    [BOM-GEA-Adapter-Rev3B.csv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]
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2026-10-01 feat(case): add Rev3C socket and antenna enclosure options
    [rev3c_base.step, rev3c_base.stl, rev3c_base_ant-external.step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]
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2026-10-02 fix(case): align Rev3B button access with module layout
    [rev3b_base.step, rev3b_base_ant-external.step, rev3b_base_ant-internal.step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]
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2026-10-03 fix(firmware): pin reference build dependencies
2026-10-03 ci: pin verified images and clarify missing sources
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2026-10-04 fix(ci): stage complete dependency checks for public main
2026-10-04 fix(pcb): stage reviewed historical Rev1 source
    [OnionStraws-B_Cu.gbr, OnionStraws-B_Mask.gbr, OnionStraws-B_Paste.gbr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]
2026-10-04 fix(pcb): stage reviewed historical Rev2 source
    [OnionStraws-B_Cu.gbl, OnionStraws-B_Mask.gbs, OnionStraws-B_Paste.gbp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]
2026-10-04 fix(pcb): stage reviewed Rev2.1 source and centroid proof
    [BOM-OnionStraws-rev2.1.csv, OnionStraws.kicad_pcb, OnionStraws.kicad_sch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]
2026-10-04 fix(pcb): stage reviewed historical Rev2.2 source
    [BOM-OnionStraws-rev2.2.csv, OnionStraws.kicad_pcb, OnionStraws.kicad_sch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]
2026-10-04 docs(firmware): correct historical service power guidance
2026-10-04 fix(pcb): correct Rev3C switch delay pin type
    [GEA-Adapter-Rev3C.kicad_sch]
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2026-10-04 fix(pcb): correct Rev3B switch delay metadata
    [GEA-Adapter-Rev3B.kicad_sch]
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2026-10-04 feat(pcb): add documented Rev3C component previews
    Use distinct official Seeed PCB-derived C3/C6 previews with generic and omitted component limits. Add drawing-derived connector detail and a licensed nominal U.FL reference with verified datums.
    Preserve all non-model PCB tokens and protected electrical, manufacturing and firmware files. Record native KiCad 9.0.9 checks, matched-camera renders, model provenance and unresolved service geometr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
    [GEA-Adapter-Rev3C.kicad_pcb, RJ45_EVERCOM_5301-8P8C-RevA-drawing-detail.step, Socket_HCTL_PM254-1-07-Z-8.5-drawing-detail.step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]
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2026-10-04 fix(pcb): bind component previews to current Rev3C source
2026-10-04 fix(pcb): export Rev3C jack at reviewed body datum
    [CPL-GEA-Adapter-Rev3C.csv]
2026-10-04 fix(pcb): export Rev3B parts at reviewed body datums
    [CPL-GEA-Adapter-Rev3B.csv]
2026-10-04 fix(pcb): add verified XIAO C3 and C6 SoC package models
    Add unmodified licensed KiCad QFN32 geometry matched to both exact FH4 package drawings and independently verify pin-1 orientation, height and every retained export solid. Refresh native C3/C6 previews and record bounded regulator exclusions.
    Preserve the complete carrier PCB, protected electrical and firmware files, and accepted body-datum manufacturing exports byte-for-byte.
    [QFN-32-1EP_5x5mm_P0.5mm_EP3.7x3.7mm.step, XIAO_ESP32C3_v1.3_vendor_pcb_visual_reference.step, XIAO_ESP32C6_v1.0_vendor_pcb_visual_reference.step]
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2026-10-04 fix(pcb): register verified C3 preview on Rev3B
    [GEA-Adapter-Rev3B.kicad_pcb, QFN-32-1EP_5x5mm_P0.5mm_EP3.7x3.7mm.step, XIAO_ESP32C3_v1.3_vendor_pcb_visual_reference.step]
2026-10-04 fix(pcb): bind Rev3B placement proof to verified model assets
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2026-10-04 fix(pcb): expand Rev3A supplier BOM reference rows
    [BOM-GEA-Adapter-Rev3A.csv]
2026-10-04 fix(pcb): normalize rev3a schematic ERC endpoints
    [GEA-Adapter-Rev3A.kicad_sch]
2026-10-04 fix(pcb): refresh zero-warning Rev3A source evidence
2026-10-04 fix(pcb): expose rev1 buffer power pin
    [OnionStraws.kicad_sch]
2026-10-04 fix(pcb): normalize Rev2 schematic net aliases
    [OnionStraws.kicad_sch]
2026-10-04 fix(pcb): bind warning-free Rev1 schematic review
2026-10-04 fix(pcb): bind warning-free Rev2 source and archive
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2026-10-04 fix(pcb): omit drill markers from Rev3C stencils
    [GEA-Adapter-Rev3C.kicad_pcb]
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2026-10-05 docs(pcb): refresh corrected Rev3C assembly quotes
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2026-10-05 fix(pcb): align Rev2.1 resistor purchasing codes with intended values
    [BOM-OnionStraws-rev2.1.csv, OnionStraws.kicad_pcb, OnionStraws.kicad_sch]
2026-10-05 fix(pcb): correct Rev2.0 intended resistor purchasing metadata
    [OnionStraws.kicad_pcb, OnionStraws.kicad_sch]
2026-10-05 fix(pcb): record complete Murata capacitor ordering identities
    [BOM-GEA-Adapter-Rev3A.csv, BOM-GEA-Adapter-Rev3B.csv, GEA-Adapter-Rev3A.kicad_pcb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]
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2026-10-05 fix(pcb): correct legacy assembly and regulator metadata
    [OnionStraws.kicad_pcb, OnionStraws.kicad_sch]
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2026-10-05 fix(pcb): rate Rev3C input OR diodes for switch limit
    [BOM-GEA-Adapter-Rev3C.csv, GEA-Adapter-Rev3C.kicad_pcb, GEA-Adapter-Rev3C.kicad_sch]
2026-10-05 fix(pcb): backport Rev3B input diode rating repair
    [BOM-GEA-Adapter-Rev3B.csv, GEA-Adapter-Rev3B.kicad_pcb, GEA-Adapter-Rev3B.kicad_sch]
2026-10-05 fix(pcb): backport Rev3A input diode rating repair
    [BOM-GEA-Adapter-Rev3A.csv, GEA-Adapter-Rev3A.kicad_pcb, GEA-Adapter-Rev3A.kicad_sch]
2026-10-05 docs(pcb): record bounded Rev3 diode and power review
    [thermal-reference-screens.csv]
2026-10-05 fix(pcb): bound Rev3C socket courtyard by maximum body
    [GEA-Adapter-Rev3C.kicad_pcb]
2026-10-05 fix(case): cover declared Rev3C socket and stack bounds
    [enclosure.py]
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2026-10-05 docs(case): preserve separate lid-pair prevention study
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2026-10-05 docs(case): correct Rev3A USB opening dimensions

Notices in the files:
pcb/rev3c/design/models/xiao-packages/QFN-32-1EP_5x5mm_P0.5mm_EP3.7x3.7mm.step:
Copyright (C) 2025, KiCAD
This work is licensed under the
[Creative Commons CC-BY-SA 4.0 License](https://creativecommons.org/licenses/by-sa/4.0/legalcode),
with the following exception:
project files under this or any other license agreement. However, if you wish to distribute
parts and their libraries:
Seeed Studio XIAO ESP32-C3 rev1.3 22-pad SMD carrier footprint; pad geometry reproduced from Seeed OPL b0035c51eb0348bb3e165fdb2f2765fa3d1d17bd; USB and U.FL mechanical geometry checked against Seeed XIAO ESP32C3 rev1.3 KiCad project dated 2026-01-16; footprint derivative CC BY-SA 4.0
